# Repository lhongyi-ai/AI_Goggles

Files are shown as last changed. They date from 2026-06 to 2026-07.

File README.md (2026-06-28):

# AI_Goggles

V0 firmware for a Seeed Studio XIAO ESP32S3 Sense wearable camera validation prototype.

## KiCad Hardware Automation

This repository now includes a maintainable KiCad + Python + VS Code automation skeleton for the future AI sports glasses carrier board. The current hardware target is a minimal Radxa CM4 / RK3576 carrier exploration flow, but this code intentionally generates only a reviewable test PCB. It does not generate a complete Radxa CM4 carrier board, does not add unverified CM4 pin mappings, and does not autoroute high-speed signals.

### Quick Start

```bash
./scripts/setup_environment.sh
source .venv/bin/activate
python scripts/check_environment.py
python scripts/generate_test_board.py
python scripts/run_drc.py
```

On this machine, initial probing found Python 3.12.4 at `/opt/anaconda3/bin/python3`, but did not find `kicad-cli` in `PATH` or under `/Applications/KiCad`. The scripts keep working in fallback mode and will automatically use KiCad CLI if it is installed later.

### VS Code Usage

Select the workspace interpreter at:

```text
${workspaceFolder}/.venv/bin/python
```

The `.vscode/tasks.json` file provides these tasks:

- `Hardware: Check Environment`
- `Hardware: Test KiCad IPC`
- `Hardware: Generate Test Board`
- `Hardware: Run DRC`
- `Hardware: Export Gerbers`
- `Hardware: Run All Checks`

The debug launch configs cover:

- `scripts/check_ipc_connection.py`
- `scripts/generate_test_board.py`

Open the KiCad project from:

```text
hardware/ai_glasses_carrier.kicad_pro
```

The fallback generator writes:

```text
hardware/ai_glasses_carrier.kicad_pcb
```

### IPC API Usage

1. Start KiCad.
2. Open PCB Editor.
3. Open `hardware/ai_glasses_carrier.kicad_pcb`.
4. Enable KiCad's IPC/API server for your installed KiCad version.
5. Run:

```bash
python scripts/check_ipc_connection.py
```

This repository does not hard-code a KiCad IPC settings menu name because no KiCad installation was detectable when this environment was created. After KiCad is installed, run `python scripts/check_environment.py` to capture the version, then use the matching KiCad documentation or Preferences search for IPC/API server settings. The IPC checker refuses to report success unless it can use importable bindings and verify a live KiCad/PCB Editor session.

### Two Automation Routes

```text
Route A: IPC API
Use this for interacting with the PCB currently open in KiCad.

Route B: Standard KiCad file generation
Use this for batch generation, CI, Git review, and non-GUI environments.
```

Route B is the primary fallback today. `scripts/generate_test_board.py` creates a 50 mm x 20 mm two-layer board with Edge.Cuts, two mounting holes, one 1x4 test connector, and these test nets:

- `+5V`
- `GND`
- `I2C_SCL`
- `I2C_SDA`

### Configuration

Hardware settings live in:

- `config/board.yaml` — V1 carrier spec (6-layer, target outline, P0/P1 interfaces)
- `config/cm4_pins.yaml` — RK3576 signal catalog mapped to carrier nets
- `config/cm4_v1_pin_assignment.yaml` — **pin freeze gate** (requirements Section 3.3)
- `config/components_v1.yaml` — candidate parts for every P0/P1 block
- `config/design_rules.yaml` — 6-layer stack + impedance rules (MIPI 100Ω, USB 90Ω)

Pin/signal entries are marked `source_verified: false` until they are manually
checked against *Radxa CM4 Schematic V1.20*. AI-generated content is auxiliary only.

### V1 Carrier Board (Radxa CM4 / RK3576)

The V1 deliverable is defined by `AI_Sports_Glasses_PCB_Requirements_v1.1.pdf`.
Generate the 6-layer skeleton (outline + full net list + mounting holes):

```bash
.venv/bin/python scripts/generate_carrier_board.py
```

This produces a **pre-layout skeleton only** — no B2B/USB/camera footprints.
Per requirements **Section 3.3**, real layout may not begin until the pin
assignment is frozen. Check the gate:

```bash
.venv/bin/python scripts/check_pin_freeze.py
```

The gate stays **BLOCKED** until every P0 row in `cm4_v1_pin_assignment.yaml` has
a real pin number + verified source, all Section 8.3 TBD items are resolved, and
`status:` is set to `FROZEN`. Only then should real footprints be placed.

> Note: `generate_test_board.py` (legacy 2-layer toolchain check) writes to the
> same `hardware/ai_glasses_carrier.kicad_pcb` path. After running `pytest`,
> re-run `generate_carrier_board.py` to restore the carrier as the active board.

### Reports And Manufacturing Output

DRC output is written to:

```text
generated/reports/drc-report.txt
```

Manufacturing export output is written to:

```text
generated/gerbers/
```

Both scripts inspect `kicad-cli --help` before constructing version-sensitive commands.

## V0 Behavior

- Short press on D1: capture one JPEG photo.
- Long press on D1 for at least 1 second: start SD MJPEG recording. Press again or send `x` to stop.
- Red LED on D2 stays on while capturing.
- Files are saved to the Sense microSD card without overwriting old files.
- Wi-Fi live preview is available when `v0_camera_prototype/wifi_config.h` is configured.

## Wiring

- `D1 -> push button -> GND`
- `D2 -> 330 ohm resistor -> LED anode`
- `LED cathode -> GND`

The camera and microSD slot are on the Sense expansion board. Do not use D8, D9, or D10 for the button or LED because those pins are used by SD SPI.

## Board

Use:

```bash
esp32:esp32:XIAO_ESP32S3
```

Recommended options:

- USB CDC On Boot: Enabled
- PSRAM: OPI PSRAM
- Partition Scheme: Maximum APP
- Upload Speed: 921600, or lower if upload is unreliable

The equivalent compile FQBN is:

```bash
esp32:esp32:XIAO_ESP32S3:PSRAM=opi,PartitionScheme=max_app_8MB,CDCOnBoot=default
```

## Suggested Test Order

1. `tests/01_blink_led`
2. `tests/02_read_button`
3. `tests/03_button_controls_led`
4. `tests/04_sd_write_test`
5. `v0_camera_prototype`

Compile the main firmware:

```bash
arduino-cli compile \
  --fqbn esp32:esp32:XIAO_ESP32S3:PSRAM=opi,PartitionScheme=max_app_8MB,CDCOnBoot=default \
  v0_camera_prototype
```

List connected boards:

```bash
arduino-cli board list
```

Upload after replacing the port with your actual port:

```bash
arduino-cli upload \
  -p /dev/cu.usbmodemXXXX \
  --fqbn esp32:esp32:XIAO_ESP32S3:PSRAM=opi,PartitionScheme=max_app_8MB,CDCOnBoot=default \
  v0_camera_prototype
```

Serial Monitor:

```bash
arduino-cli monitor -p /dev/cu.usbmodemXXXX -c baudrate=115200
```

Serial commands in the main firmware:

- `p`: take one photo
- `r`: start SD MJPEG recording with Wi-Fi preview available
- `x`: stop current SD recording and write metadata
- `j`: start JPEG sequence debug recording
- `m`: start SD MJPEG recording
- `v`: enable or disable Wi-Fi preview server
- `w`: print Wi-Fi status, IP, and preview URLs
- `s`: print next file indexes
- `i`: print hardware, memory, SD, BLE, and active profile information
- `b`: run the video smoothness benchmark suite
- `h`: print help

## Wi-Fi Live Preview And Mac MP4

Copy and edit the Wi-Fi config:

```bash
cp v0_camera_prototype/wifi_config.example.h v0_camera_prototype/wifi_config.h
```

Then upload the firmware. In Serial Monitor, send:

```text
w
```

Open the printed preview page:

```text
http://XIAO_IP/
```

Record a live H.264 MP4 on the Mac:

```bash
./scripts/live_preview_record.sh XIAO_IP
```

Stop with Ctrl+C, or:

```bash
./scripts/stop_live_recording.sh
```

See [docs/live_preview_and_dual_recording.md](docs/live_preview_and_dual_recording.md) for the architecture, endpoints, and validation plan.

## BLE Phone Control

The firmware exposes a BLE control service so a phone can trigger the same commands as USB serial.

BLE identifiers:

```text
Device name: AI_Goggles
Service UUID: 7b8f0001-2f5d-4d5a-9e4f-7f6a8c8d0001
Control characteristic UUID: 7b8f0002-2f5d-4d5a-9e4f-7f6a8c8d0001
```

Phone test apps:

- iPhone: nRF Connect or LightBlue
- Android: nRF Connect

Phone steps:

1. Power the XIAO ESP32S3 Sense.
2. Open nRF Connect or LightBlue.
3. Scan for `AI_Goggles`.
4. Connect to the device.
5. Open the custom service UUID above.
6. Open the control characteristic UUID above.
7. Write one UTF-8/text command:
   - `p`: take one photo
   - `r`: start SD MJPEG recording
   - `x`: stop recording
   - `j`: start JPEG sequence debug recording
   - `m`: start SD MJPEG recording
   - `v`: toggle Wi-Fi preview server
   - `w`: print Wi-Fi status
   - `s`: update/read status
   - `i`: print hardware/profile info to Serial Monitor
   - `b`: run the benchmark suite
   - `h`: print help to Serial Monitor
8. Read the same characteristic to see a simple status string like `ready: recording done`.

Do not write a new `r` or `b` command while a recording is already running. The board is busy during capture.

## Output Files

Single photos:

```text
/photo_0001.jpg
/photo_0002.jpg
```

JPEG sequences:

```text
/clip_0001/frame_0001.jpg
/clip_0001/frame_0002.jpg
/clip_0001/clip_info.csv
/clip_0001/frame_timing.csv
```

Single-file MJPEG output:

```text
/clip_0005.mjpeg
/clip_0005_info.csv
/clip_0005_timing.csv
```

The XIAO ESP32S3 Sense does not have a hardware H.264 encoder, so it cannot directly create smooth MP4/MOV files on-device. Convert a clip folder to MP4 on your computer:

```bash
ffmpeg -framerate 10 -i frame_%04d.jpg -c:v libx264 -pix_fmt yuv420p clip_0001.mp4
```

This repo also includes a macOS LaunchAgent and shell script that can auto-convert SD card `clip_*` folders and `.mjpeg` files to `sd_clip_*.mp4` when the card is mounted. Live network recordings are saved separately as `recordings/live/live_*.mp4`.

## macOS SD Auto Convert

Install once:

```bash
chmod +x scripts/*.sh
./scripts/install_auto_convert_launch_agent.sh
```

Prepare each AI Goggles SD card once:

```bash
./scripts/prepare_ai_goggles_sd.sh "/Volumes/SD_CARD_NAME"
```

Normal use:

```text
1. Remove the SD card from the XIAO.
2. Insert it into the Mac.
3. Wait for background conversion.
4. Open ~/Movies/AI_Goggles/SD_Recordings/
```

Check status:

```bash
./scripts/check_auto_convert_status.sh
```

Logs:

```bash
tail -f ~/Library/Logs/AI_Goggles/auto_convert.log
```

Manual trigger for debugging:

```bash
launchctl kickstart -k gui/$(id -u)/com.stanley.ai-glasses.auto-convert
```

Uninstall:

```bash
./scripts/uninstall_auto_convert_launch_agent.sh
```

`StartOnMount` fires for many mounted volumes, but the script only processes volumes with `AI_GOGGLES.marker` or a strict legacy `clip_XXXX` recording layout. See [docs/macos_sd_auto_convert.md](docs/macos_sd_auto_convert.md).

## Video Smoothness Benchmark

The firmware records per-frame timing with `esp_timer_get_time()` and writes metrics after recording finishes. It does not print per-frame logs during capture.

Profile summary:

| Profile | Resolution | JPEG quality | Target FPS | SD SPI | Storage |
| --- | --- | ---: | ---: | ---: | --- |
| A | 320x240 | 15 | 10 | 10 MHz | Separate JPEG files |
| B | 320x240 | 15 | 15 | 20 MHz | Separate JPEG files |
| C | 320x240 | 20 | 20 | 20 MHz | Separate JPEG files |
| D | 640x480 | 15 | 10 | 20 MHz | Separate JPEG files |
| E | 320x240 | 15 | 10 | 20 MHz | Single-file MJPEG |

Analyze a clip:

```bash
python3 scripts/analyze_clip_metrics.py /Volumes/UNTITLED\ 2/clip_0001
python3 scripts/analyze_clip_metrics.py /Volumes/UNTITLED\ 2/clip_0005_info.csv
```

See [docs/video_smoothness_benchmark.md](docs/video_smoothness_benchmark.md) for the full benchmark workflow and CFR/VFR MP4 conversion notes.

## Bluetooth Audio Note

The XIAO ESP32S3 Sense cannot act like a normal phone Bluetooth speaker/headset because ESP32-S3 supports BLE but not Classic Bluetooth audio profiles such as A2DP or HFP. BLE is useful for low-bandwidth control commands, but not for ordinary phone audio streaming in this Arduino setup.

For phone audio, use a separate Bluetooth audio receiver module or a chip/board with Classic Bluetooth audio support, then connect its audio output to a speaker/amp path. For phone camera control, a BLE control service can be added separately.

## V0 Pass Criteria

- Camera initializes reliably.
- Button triggers once per press.
- LED is visible while capturing and off afterward.
- Single photos open on a computer.
- A 10-second recording saves at least 30 valid JPEG frames.
- Restarting the board does not overwrite old captures.

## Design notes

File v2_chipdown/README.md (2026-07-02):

# AI Glasses V2 — RK3576 Chip-Down (event-driven, always-on + compute-island)

This folder holds the **V2 design**, a clean break from the V1 CM4-carrier board.

## The one-sentence definition

> V2 is **not** "glasses that run RK3576 all day."
> V2 is **glasses whose low-power always-on (AON) system stays awake all day for sensing + connectivity, and wakes RK3576 for short bursts** when vision / AI / encode / high-rate transmit is actually needed.

This inverts the V1 order. V1 built the RK3576/CM4 host first and treated power as an afterthought (`1S → 5V boost → everything`). V2 **freezes the battery volume and the power state machine first, then draws the RK3576 chip-down** as a demand-started compute accelerator.

## Why the change (energy accounting)

V1 measured/estimated draw: idle **651 mW**, mixed **~3031 mW**, AI+record peak **~4.8 W**. At those numbers a temple-sized battery cannot deliver all-day standby *and* multi-hour mixed use. V2 targets:

| State | V1 now | V2 target |
|---|--:|--:|
| Standby | 651 mW | **20–50 mW** |
| Mixed use | 3031 mW | **300–500 mW** |
| Continuous 1080p record | ~3 W | **1.0–1.5 W** |
| AI + record peak | 4.8 W | **1.5–2.5 W** |

## Folder map

```
v2_chipdown/
├── README.md                     ← you are here (positioning + map)
├── docs/
│   ├── 01_architecture.md        AON island + RK3576 compute island, 4-board split
│   ├── 02_power_states.md        the 5+1 state machine (Deep Off … AI Burst)
│   ├── 03_workflow_phases.md     Phase 0–6 + Gate 0/1/2 + Power/Mechanical gates
│   ├── 04_power_tree.md          new Buck + Load-Switch tree (not "boost everything")
│   ├── 05_hardware_partition.md  front sensor board / L temple / R temple / rears
│   ├── 06_battery_strategy.md    1S2P distribution + LP451165×2 recommendation
│   ├── 07_schematic_design.md    pre-layout schematic design record
│   ├── 08_signal_dictionary.md   generated NET_META signal dictionary
│   ├── 09_power_domain_isolation_matrix.md generated reverse-feed matrix
│   ├── 10_bom_status.md          generated BOM/HOLD/DNP/TBD status
│   ├── 11_footprint_register.md  generated package/footprint readiness register
│   ├── 12_layout_entry_gate_status.md generated PCB go/no-go + HOLD closure
│   └── 13_mechanical_electrical_floorplan.md Phase 1.5 no-route floorplan template
├── config/
│   ├── power_budget_v2.yaml      subsystem × power-state model (editable, source)
│   └── battery_options.yaml      candidate cells/packs incl. LP451165
├── scripts/
│   ├── chipdown_bom.py           V2 schematic/BOM/net/signal source of truth
│   ├── generate_chipdown_sch.py  emits generated KiCad schematic + symbol lib
│   ├── generate_gate_docs.py     emits docs 08/09/11/12
│   ├── generate_bom_status.py    emits doc 10
│   ├── generate_mechanical_floorplan.py emits Phase 1.5 report + multi-view render
│   └── power_budget_v2.py        computes per-state runtime, required mAh, day-mix
├── hardware/                     generated pre-layout system schematic, no PCB yet
└── reports/
    ├── POWER_BUDGET_V2.md        generated by the power model
    ├── AI_Glasses_V2_Phase1_5_Floorplan.md generated fit/placement report
    ├── AI_Glasses_V2_Phase1_5_Floorplan_ZH.md Chinese CAD/structure handoff
    ├── ai_glasses_v2.net         KiCad netlist export
    ├── ai_glasses_v2_bom.csv     KiCad BOM export
    └── output/                   schematic PDF/SVG + power-budget PDF + Phase 1.5 render
```

## Status / what's frozen vs open

- **Frozen intent:** event-driven architecture, AON-controls-SoC-power, distributed 4-board split, per-island current sense, hardware default-OFF enables.
- **Now present:** generated pre-layout KiCad system schematic: **96 components**, **127 declared nets**, ERC clean. It is a functional-block review artifact, not a PCB layout release.
- **Open / HOLD:** NDP120 full datasheet + kit + power, FCU760K Hardware Design + BSP, LP451165 + 1S2P validation, custom IMX415 module rail/FPC data, real battery-bay fit.
- **Gate order:** Phase 0 (freeze battery + state machine) → Phase 1 (AON board) → Phase 1.5 (mechanical/electrical floorplan) → Phase 2 (RK3576 min core). PCB layout is still blocked by [docs/12_layout_entry_gate_status.md](docs/12_layout_entry_gate_status.md) and [docs/13_mechanical_electrical_floorplan.md](docs/13_mechanical_electrical_floorplan.md).

## How to regenerate the V2 schematic/docs

```bash
cd "AI Glasses"
.venv/bin/python v2_chipdown/scripts/chipdown_bom.py
.venv/bin/python v2_chipdown/scripts/generate_chipdown_sch.py
.venv/bin/python v2_chipdown/scripts/generate_gate_docs.py
.venv/bin/python v2_chipdown/scripts/generate_bom_status.py

KCLI=/Applications/KiCad/KiCad.app/Contents/MacOS/kicad-cli
"$KCLI" sch erc --severity-all --format report \
  -o v2_chipdown/reports/erc.report.txt \
  v2_chipdown/hardware/ai_glasses_v2_chipdown.kicad_sch
"$KCLI" sch export netlist --output v2_chipdown/reports/ai_glasses_v2.net \
  v2_chipdown/hardware/ai_glasses_v2_chipdown.kicad_sch
"$KCLI" sch export bom --output v2_chipdown/reports/ai_glasses_v2_bom.csv \
  --fields Reference,Value,BOM_ID,Board,Assembly,Priority,Package,Gate \
  v2_chipdown/hardware/ai_glasses_v2_chipdown.kicad_sch
"$KCLI" sch export pdf --output v2_chipdown/reports/output/ai_glasses_v2_chipdown_schematic.pdf \
  v2_chipdown/hardware/ai_glasses_v2_chipdown.kicad_sch
"$KCLI" sch export svg --output v2_chipdown/reports/output \
  v2_chipdown/hardware/ai_glasses_v2_chipdown.kicad_sch
```

## How to run the power model

```bash
cd "AI Glasses"
.venv/bin/python v2_chipdown/scripts/power_budget_v2.py
# then render the markdown to PDF (same kidoc flow as V1):
python3 ~/.claude/skills/kidoc/scripts/kidoc_generate.py \
  --project-dir "$(pwd)" \
  --doc "$(pwd)/v2_chipdown/reports/POWER_BUDGET_V2.md" --format pdf
```

## Relationship to V1

V1 (`hardware/ai_glasses_carrier.*`, `scripts/carrier_bom.py`, `config/*.yaml`) stays as the **bench/EVT development vehicle** — it is still the fastest way to bring up RK3576 Linux and get *real* per-rail current numbers. Those measured numbers feed back into `config/power_budget_v2.yaml` and re-size the battery. V2 does **not** delete V1; it supersedes it as the product architecture.

> All numbers in `config/*.yaml` are **engineering estimates** from datasheet typicals until Phase 2 bench EVT replaces them with per-island shunt measurements.

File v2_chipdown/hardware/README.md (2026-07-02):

# V2 chip-down hardware

## Now present: the pre-layout system schematic (no PCB yet)

`ai_glasses_v2_chipdown.kicad_sch` is a **pre-PCB-layout, functional-block system
schematic** for the whole V2 design. It is generated from the master in
[../scripts/chipdown_bom.py](../scripts/chipdown_bom.py) and captures what is
knowable before layout: the power tree, the AON control plane, interface buses,
default-OFF enable pulls, current-sense points, and hidden `NET_META` signal
attributes on global labels. See [../docs/07_schematic_design.md](../docs/07_schematic_design.md).

| File | What |
|---|---|
| `ai_glasses_v2_chipdown.kicad_sch` | one system sheet, 96 blocks, 127 declared nets, **ERC clean** |
| `AI_Glasses_V2.kicad_sym` | generated box symbols |
| `ai_glasses_v2_chipdown.kicad_pro`, `sym-lib-table`, `fp-lib-table` | project + lib tables |

Regenerate from the repo root:

```bash
.venv/bin/python v2_chipdown/scripts/chipdown_bom.py
.venv/bin/python v2_chipdown/scripts/generate_chipdown_sch.py
.venv/bin/python v2_chipdown/scripts/generate_gate_docs.py
.venv/bin/python v2_chipdown/scripts/generate_bom_status.py
```

Then run ERC and exports per [../docs/07_schematic_design.md](../docs/07_schematic_design.md).
Review outputs (netlist / BOM / PDF / SVG / ERC) are in [../reports/](../reports/).
Generated gate docs are [08](../docs/08_signal_dictionary.md),
[09](../docs/09_power_domain_isolation_matrix.md),
[10](../docs/10_bom_status.md), [11](../docs/11_footprint_register.md) and
[12](../docs/12_layout_entry_gate_status.md).

## Still NOT here: PCB layout (by design)

No `.kicad_pcb`, no assigned footprints, no placement/copper. **PCB layout stays
gated behind Gate 0, the Phase 1.5 floorplan, and the HOLD closure matrix** —
batteries proven to fit L/R temples with swell/foam/FPC room, not stacked over
RK3576/PMIC, antenna keep-out respected, and NDP120/Wi-Fi/battery/camera/FPC
data closed (see [../docs/12_layout_entry_gate_status.md](../docs/12_layout_entry_gate_status.md)
and [../docs/13_mechanical_electrical_floorplan.md](../docs/13_mechanical_electrical_floorplan.md)).
The Footprint field is intentionally empty; intended packages live in the
`Package` field only and are tracked in [../docs/11_footprint_register.md](../docs/11_footprint_register.md).

The next KiCad mechanical deliverable is a **no-route floorplan**: board frames,
RK3576/LPDDR/RK806/eMMC/Wi-Fi/boost-inductor/FPC placement envelopes, battery
3D/envelope blocks, speaker and antenna keep-outs. It proves fit before routing;
it is not a formal routed PCB.

## Intended board split at layout (Phase 4)

One system schematic now; four physical boards at layout time (each component
already tagged with its `Board`):

```
front_sensor/   custom 1080p camera + PDM mic array + camera rails + ESD
rk3576_core/    RK3576 + LPDDR4X + eMMC + RK806S + 5V boost + Wi-Fi   (delta off Radxa ref)
aon_power/      nRF54L15 + nPM1300 + NDP120 + BMI270 + charge/gauge/protection   (BUILD FIRST)
power_tree/     Buck + load-switch islands + per-island current sense
```

Build order remains AON board first, then the RK3576 core — never the SoC first.

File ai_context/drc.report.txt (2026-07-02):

** Drc report for ai_glasses_carrier.kicad_pcb **
** Created on 2026-06-30T03:11:09 **
** Report includes: Errors, Warnings, Exclusions **

** Found 0 DRC violations **

** Found 0 unconnected pads **

** Found 0 Footprint errors **

** Ignored checks **
    - Footprint has no courtyard defined
    - Track endpoint not centered on via
    - Tuning profile track geometries
    - Footprint doesn't match symbol's footprint filters
    - Footprint component type doesn't match footprint pads

** End of Report **

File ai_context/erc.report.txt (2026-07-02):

ERC report (2026-06-30T03:11:02, Encoding UTF8)
Report includes: Errors, Warnings, Exclusions

***** Sheet /

 ** ERC messages: 0  Errors 0  Warnings 0

 ** Ignored checks:
    - Global label only appears once in the schematic
    - Four connection points are joined together
    - SPICE model issue
    - Assigned footprint doesn't match footprint filters

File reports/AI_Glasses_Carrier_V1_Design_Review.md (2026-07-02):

# AI Glasses Carrier V1 - PCB Design Review

- **Board:** ai_glasses_carrier_v1  |  **CM4 SKU:** RM126-D4E32J0R35W28 (RK3576, 4GB LPDDR4X, 32GB eMMC, Wi-Fi6+BT5.x)
- **Pin-assignment status:** `REVIEW` (verified vs official pinout; not yet FROZEN)
- **Generated:** 2026-06-30  (from working sources; see footer)
- **Components:** 102 (81 P0)  |  **Passive families:** 22 (LOCKED 11 / VERIFY 6 / TUNE 5)
- **ERC:** 0  |  **DRC:** 0 violations  |  **Footprints:** 101/102 real (1 VERIFY), 0 placed  |  **MPN set:** 27/102

> [!] **Stage:** schematic / pin-freeze. The PCB is intentionally an empty skeleton (outline + 6-layer stack + mounting holes + nets, **no footprints placed**). Per repo rule 7 this report makes **no** claim about layout/copper/clearance correctness - that is confirmed only in KiCad/3D after placement. Part values & specs are EVT candidates pending human review.

---
## 1. Project status

| Item | State |
|---|---|
| Pin assignment | [OK] 56 rows, all verified vs `radxa_cm4_pinout_v1.20.xlsx` |
| Freeze gate | [BLOCKED] `REVIEW` - blocked by 3 procurement/mechanical TBDs (not pins) |
| Schematic | [OK] element-level draft, net-connectivity verified |
| PCB layout | [ ] not started (skeleton only) |
| ERC / DRC | 0 / 0 violations (see §2/§3) |

## 2. Schematic status (ERC)

Schematic is generated from the BOM master (`scripts/carrier_bom.py`) as box symbols with global net labels; every net was checked with `kicad-cli sch export netlist`. The CM4 module is drawn as its three B2B connectors (J31=J3A, J32=J3B, J1) carrying the real CM4 pins.

**ERC: 0 errors, 0 warnings - clean** (`ai_context/erc.report.txt`: "ERC messages: 0  Errors 0  Warnings 0"). Confirms 102 symbols + 321 net labels with no unconnected-critical-pin, duplicate-net, or power-driver violations.

## 3. PCB status (DRC)

PCB = pre-layout skeleton: 70×55 mm outline (placeholder - carrier outline still a TBD), 6-layer stack (F.Cu / In1.GND / In2.PWR / In3.sig / In4.GND / B.Cu), 4× M2 mounting holes, declared nets, **no component footprints**. `Update PCB from Schematic` will populate it once footprints are assigned and the gate is FROZEN.

**DRC: 0 errors, 0 warnings** on the skeleton (`ai_context/drc.report.txt`). Meaningful DRC (clearances, diff-pair, copper) only applies after footprints are placed.

## 4. Footprint status

"Footprint" means three different things at three stages - they are NOT the same, and conflating them is what makes the status look contradictory:

| Layer | Meaning | Status |
|---|---|---|
| (1) Footprint field (pointer) | Each symbol names *which* footprint to use | **102/102** assigned |
| (2) Real footprint exists/usable | That name maps to a real KiCad library footprint | **101/102** real, **1** still `VERIFY` placeholder |
| (3) Placed on the PCB | Physical footprint dropped into `.kicad_pcb` | **0** (pre-layout skeleton) |

So: every symbol has a footprint *pointer* (needed for `Update PCB from Schematic`), **101** of those now point at real, datasheet-checked footprints from the installed KiCad 10 libraries (all passives + most connectors/ICs/test points), **1** are still placeholders, and **nothing is placed on the board yet**.

### 4.1 The 1 remaining placeholders - proposed real footprints

Each was researched against the installed KiCad libraries / the part datasheet. `custom` = must be drawn in `AI_Glasses.pretty` (no stock footprint); `confirm` = std-lib family identified, verify exact pads/EP vs the ordered part.

| Ref | Part / package | Proposed footprint | Action |
|---|---|---|---|
| L1 | Boost inductor 4.7uH, >=10A sat | `Inductor_SMD: 4x4mm class per chosen part` | confirm |

> All parts now use **authoritative KiCad-library footprints**, including the TI-official land patterns for the small packages: B2B = `Connector_Hirose_DF40:Hirose_DF40C-100DS-0.4V_2x50_P0.4mm`, GNSS = `RF_GPS:ublox_MAX`, IMU = `Package_LGA:LGA-14_3x2.5mm`, TPD4E05U06 = `Package_SON:USON-10_2.5x1.0mm_P0.5mm`, TPS61022 = `Package_DFN_QFN:Texas_RWU0007A_VQFN-7_2x2mm`. A 1:1 print-and-verify fixture for the two small packages is in `hardware/confirm_fp_1to1_check.kicad_pcb` (PDF: `reports/output/Confirm_FP_1to1_Check.pdf`). The only remaining placeholder is **L1** (boost inductor) - its footprint is selected once the boost peak current sets the inductor part. The B2B footprint geometry is authoritative, but the locked 3-connector PLACEMENT still needs the mechanical fit-check (official CM4 STEP + 2-layer coupon, see §8).

## 5. Component list (by function)

### CM4 Module / B2B Connectors (3)

| Ref | Value | MPN | LCSC | Footprint | Function |
|---|---|---|---|---|---|
| J1 | DF40C-100DS-0.4V(51) | DF40C-100DS-0.4V(51) | - | `Connector_Hirose_DF40:Hirose_DF40C-100DS-0.4V_2x50_P0.4mm` | CM4 J1 (I/O): SAI1 audio, CSI3 camera MCLK, speaker enable |
| J31 | DF40C-100DS-0.4V(51) | DF40C-100DS-0.4V(51) | - | `Connector_Hirose_DF40:Hirose_DF40C-100DS-0.4V_2x50_P0.4mm` | CM4 J3A (low-speed): power, debug/GNSS UART, I2C, control GPIO |
| J32 | DF40C-100DS-0.4V(51) | DF40C-100DS-0.4V(51) | - | `Connector_Hirose_DF40:Hirose_DF40C-100DS-0.4V_2x50_P0.4mm` | CM4 J3B (high-speed): MIPI-CSI3 4-lane camera, USB2-OTG0, PDM1 mics |

### Camera (P0) (11)

| Ref | Value | MPN | LCSC | Footprint | Function |
|---|---|---|---|---|---|
| C8 | 10µF | - | - | `Capacitor_SMD:C_0805_2012Metric` | Camera +3V3 bulk decoupling |
| C9 | 1µF | - | - | `Capacitor_SMD:C_0603_1608Metric` | Camera +3V3 decoupling |
| C10 | 100nF | - | - | `Capacitor_SMD:C_0603_1608Metric` | Camera +3V3 HF decoupling |
| C29 | 10µF | - | - | `Capacitor_SMD:C_0805_2012Metric` | Camera +5V bulk decoupling for Radxa Camera 4K |
| C30 | 100nF | - | - | `Capacitor_SMD:C_0603_1608Metric` | Camera +5V HF decoupling for Radxa Camera 4K |
| J2 | FH35C-31S-0.3SHW(50) | FH35C-31S-0.3SHW(50) | C424662 | `AI_Glasses:FH35C-31S-0.3SHW_50` | Camera FPC - Radxa Camera 4K / Sony IMX415-AAQR-C, 31-pin 0.3mm, 4-lane MIPI |
| R7 | 2.2k | - | - | `Resistor_SMD:R_0603_1608Metric` | Camera I2C SCL pull-up to +1V8 (cam OVDD=1.8V confirmed) |
| R8 | 2.2k | - | - | `Resistor_SMD:R_0603_1608Metric` | Camera I2C SDA pull-up to +1V8 (cam OVDD=1.8V confirmed) |
| U2 | TPD4E05U06 | TPD4E05U06 | - | `Package_SON:USON-10_2.5x1.0mm_P0.5mm` | MIPI-CSI low-capacitance ESD array for CSI3 clock + data lanes 0/1 (<0.4pF/line) |
| U3 | LP5907-3.3 (low-noise LDO) | LP5907MFX-3.3 | - | `Package_TO_SOT_SMD:SOT-23-5` | Camera 3.3V low-noise supply for Radxa Camera 4K, EN-gated |
| U16 | TPD4E05U06 | TPD4E05U06 | - | `Package_SON:USON-10_2.5x1.0mm_P0.5mm` | MIPI-CSI low-capacitance ESD array for CSI3 data lanes 2/3 (<0.4pF/line) |

### Audio (P0) (9)

| Ref | Value | MPN | LCSC | Footprint | Function |
|---|---|---|---|---|---|
| C13 | 100nF | - | - | `Capacitor_SMD:C_0603_1608Metric` | Amp VDD decoupling |
| C23 | 1nF | - | - | `Capacitor_SMD:C_0603_1608Metric` | Class-D EMI cap (OUT+ to GND) |
| C24 | 1nF | - | - | `Capacitor_SMD:C_0603_1608Metric` | Class-D EMI cap (OUT- to GND) |
| FB1 | Ferrite 600ohm@100MHz | - | - | `Inductor_SMD:L_0603_1608Metric` | Class-D speaker EMI bead (OUT+) |
| FB2 | Ferrite 600ohm@100MHz | - | - | `Inductor_SMD:L_0603_1608Metric` | Class-D speaker EMI bead (OUT-) |
| J3 | JST-SH 2p (spkr) | SM02B-SRSS-TB | - | `Connector_JST:JST_SH_BM02B-SRSS-TB_1x02-1MP_P1.00mm_Vertical` | Speaker connector (post-EMI); 2 wire-leads |
| MK1 | SPH0641LU4H-1 | SPH0641LU4H-1 | - | `Sensor_Audio:Knowles_LGA-5_3.5x2.65mm` | PDM MEMS mic (L, SEL=GND) |
| MK2 | SPH0641LU4H-1 | SPH0641LU4H-1 | - | `Sensor_Audio:Knowles_LGA-5_3.5x2.65mm` | PDM MEMS mic (R, SEL=VDD) |
| U4 | MAX98357AETE+T | MAX98357AETE+T | C910544 | `Package_DFN_QFN:QFN-16-1EP_3x3mm_P0.5mm_EP1.45x1.45mm` | Class-D I2S/SAI mono amp (TQFN-16, no MCLK) |

### USB-C (P0) (8)

| Ref | Value | MPN | LCSC | Footprint | Function |
|---|---|---|---|---|---|
| C11 | 1µF | - | - | `Capacitor_SMD:C_0603_1608Metric` | VBUS input cap |
| D3 | SMAJ5.0A (TVS) | SMAJ5.0A | - | `Diode_SMD:D_SMA` | USB VBUS ESD/TVS clamp (5V standoff) |
| J4 | GCT USB4085 (USB2) | USB4085-GF-A | - | `Connector_USB:USB_C_Receptacle_GCT_USB4085` | USB-C receptacle (USB2 + 5V sink) |
| R1 | 5.1k | - | - | `Resistor_SMD:R_0603_1608Metric` | USB-C CC1 pull-down (Sink role) |
| R2 | 5.1k | - | - | `Resistor_SMD:R_0603_1608Metric` | USB-C CC2 pull-down (Sink role) |
| R3 | 0R / shunt | - | - | `Resistor_SMD:R_2512_6332Metric` | VBUS_PROT->5V series 0R/shunt (current log) |
| U5 | TPD2E009 | TPD2E009 | - | `Package_TO_SOT_SMD:SOT-553` | USB2 D+/D- ESD clamp |
| U15 | TPS25940 (e-fuse, opt) | TPS25940 | - | `Package_DFN_QFN:Texas_RGP0020H_VQFN-20-1EP_4x4mm_P0.5mm_EP2.4x2.4mm` | VBUS e-fuse: OVP/OCP/reverse-block (DNP-able; bypass via R3 if unused) |

### Power (P0) (10)

| Ref | Value | MPN | LCSC | Footprint | Function |
|---|---|---|---|---|---|
| C1 | 10µF | - | - | `Capacitor_SMD:C_0805_2012Metric` | +5V bulk decoupling |
| C2 | 100nF | - | - | `Capacitor_SMD:C_0603_1608Metric` | +5V HF decoupling |
| C3 | 10µF | - | - | `Capacitor_SMD:C_0805_2012Metric` | +3V3 bulk decoupling |
| C4 | 100nF | - | - | `Capacitor_SMD:C_0603_1608Metric` | +3V3 HF decoupling |
| C5 | 10µF | - | - | `Capacitor_SMD:C_0805_2012Metric` | +1V8 bulk decoupling |
| C6 | 100nF | - | - | `Capacitor_SMD:C_0603_1608Metric` | +1V8 HF decoupling |
| C21 | 100nF | - | - | `Capacitor_SMD:C_0603_1608Metric` | LDO U12 +3V3 output decoupling |
| C22 | 100nF | - | - | `Capacitor_SMD:C_0603_1608Metric` | LDO U13 +1V8 output decoupling |
| U12 | TLV75733 (LDO) | TLV75733 | - | `Package_TO_SOT_SMD:SOT-23-5` | 3.3V rail regulator |
| U13 | TLV75718 (LDO) | TLV75718 | - | `Package_TO_SOT_SMD:SOT-23-5` | 1.8V VCCIO rail regulator |

### Battery (P1) (14)

| Ref | Value | MPN | LCSC | Footprint | Function |
|---|---|---|---|---|---|
| C7 | 22µF | - | - | `Capacitor_SMD:C_0805_2012Metric` | +VBAT bulk decoupling |
| C17 | 100nF | - | - | `Capacitor_SMD:C_0603_1608Metric` | Charger U7 VBUS decoupling |
| C18 | 100nF | - | - | `Capacitor_SMD:C_0603_1608Metric` | Fuel gauge U9 VDD decoupling |
| C19 | 100nF | - | - | `Capacitor_SMD:C_0603_1608Metric` | Boost U6 VIN decoupling |
| J5 | JST-PH 3p | S3B-PH-SM4-TB | - | `Connector_JST:JST_PH_S3B-PH-SM4-TB_1x03-1MP_P2.00mm_Horizontal` | Battery connector (BAT+/BAT-/NTC) |
| L1 | 4.7µH | - | - | `AI_Glasses:POWER_INDUCTOR_7X7_VERIFY` | Boost inductor |
| R11 | 10k | - | - | `Resistor_SMD:R_0603_1608Metric` | Battery NTC bias (placeholder) |
| R12 | 2.2k | - | - | `Resistor_SMD:R_0603_1608Metric` | Charger/Fuel I2C6 SCL pull-up to +1V8 |
| R13 | 2.2k | - | - | `Resistor_SMD:R_0603_1608Metric` | Charger/Fuel I2C6 SDA pull-up to +1V8 |
| R20 | 100k | - | - | `Resistor_SMD:R_0603_1608Metric` | Boost EN pull-up to +VBAT; default boost enabled for bench bring-up |
| U6 | TPS61022 (Boost) | TPS61022 | - | `Package_DFN_QFN:Texas_RWU0007A_VQFN-7_2x2mm_P0.5mm` | 1S Li-Po -> 5V boost converter |
| U7 | BQ25180 | BQ25180 | - | `Package_BGA:Texas_DSBGA-12_1.36x1.86mm_Layout3x4_P0.5mm` | 1S Li-Po charger w/ power-path (I2C) |
| U8 | BQ29700 | BQ29700 | - | `Package_TO_SOT_SMD:SOT-23-5` | Single-cell battery protection (OVP/UVP/OCP) |
| U9 | MAX17048 | MAX17048 | - | `Package_DFN_QFN:DFN-8-1EP_2x3mm_P0.5mm_EP0.61x2.2mm` | I2C fuel gauge (SOC, low-batt IRQ) |

### IMU / Haptic (P1) (7)

| Ref | Value | MPN | LCSC | Footprint | Function |
|---|---|---|---|---|---|
| C16 | 100nF | - | - | `Capacitor_SMD:C_0603_1608Metric` | IMU U10 VDD decoupling |
| C20 | 100nF | - | - | `Capacitor_SMD:C_0603_1608Metric` | Haptic U11 VDD decoupling |
| J6 | JST-SH 2p | SM02B-SRSS-TB | - | `Connector_JST:JST_SH_BM02B-SRSS-TB_1x02-1MP_P1.00mm_Vertical` | Vibration motor connector |
| R9 | 2.2k | - | - | `Resistor_SMD:R_0603_1608Metric` | IMU I2C SCL pull-up to +1V8 |
| R10 | 2.2k | - | - | `Resistor_SMD:R_0603_1608Metric` | IMU I2C SDA pull-up to +1V8 |
| U10 | ICM-42688-P | ICM-42688-P | - | `Package_LGA:LGA-14_3x2.5mm_P0.5mm_LayoutBorder3x4y` | 6-axis IMU (accel+gyro, I2C) |
| U11 | DRV2605L | DRV2605L | - | `Package_SO:MSOP-10_3x3mm_P0.5mm` | LRA/ERM haptic driver |

### GNSS / Positioning (P0) (11)

| Ref | Value | MPN | LCSC | Footprint | Function |
|---|---|---|---|---|---|
| C14 | 100nF | - | - | `Capacitor_SMD:C_0603_1608Metric` | GNSS VCC decoupling |
| C15 | 10µF | - | - | `Capacitor_SMD:C_0805_2012Metric` | GNSS VCC bulk decoupling |
| C25 |  shunt (DNP,tune) | - | - | `Capacitor_SMD:C_0402_1005Metric` | GNSS -match shunt, module side (DNP) |
| C26 |  shunt (DNP,tune) | - | - | `Capacitor_SMD:C_0402_1005Metric` | GNSS -match shunt, antenna side (DNP) |
| C27 | DC-block (series,tune) | - | - | `Capacitor_SMD:C_0402_1005Metric` | GNSS RF series match / DC block |
| C28 | 100nF (active-ant) | - | - | `Capacitor_SMD:C_0603_1608Metric` | Antenna bias decoupling (DNP if passive) |
| D4 | ESD low-cap RF 0.3pF | - | - | `Diode_SMD:D_SOD-882` | GNSS antenna ESD clamp |
| J8 | U.FL / IPEX | U.FL-R-SMT-1 | - | `Connector_Coaxial:U.FL_Hirose_U.FL-R-SMT-1_Vertical` | GNSS antenna connector (50ohm; external active/passive) |
| L2 | RF choke (active-ant) | - | - | `Inductor_SMD:L_0402_1005Metric` | Bias-tee choke (DNP if passive antenna) |
| R17 | 10ohm (active-ant) | - | - | `Resistor_SMD:R_0603_1608Metric` | Active-antenna bias feed from +3V3 (DNP if passive) |
| U14 | MAX-M10S-00B-01 | MAX-M10S-00B-01 | - | `RF_GPS:ublox_MAX` | u-blox GNSS (GPS/GLO/GAL/BDS), UART, VIO=1.8V |

### Indicators / Debug (5)

| Ref | Value | MPN | LCSC | Footprint | Function |
|---|---|---|---|---|---|
| D1 | LED Green | - | - | `LED_SMD:LED_0603_1608Metric` | Power LED (active-low GPIO sink) |
| D2 | LED Blue | - | - | `LED_SMD:LED_0603_1608Metric` | Status LED (active-low GPIO sink) |
| J7 | Header 1x4 2.54mm | - | - | `Connector_PinHeader_2.54mm:PinHeader_1x04_P2.54mm_Vertical` | UART debug header (TX/RX/GND/VREF) |
| R4 | 1k | - | - | `Resistor_SMD:R_0603_1608Metric` | Power LED current limit |
| R5 | 1k | - | - | `Resistor_SMD:R_0603_1608Metric` | Status LED current limit |

### Test Points (16)

| Ref | Value | MPN | LCSC | Footprint | Function |
|---|---|---|---|---|---|
| TP1 | TestPoint 1.0mm | - | - | `TestPoint:TestPoint_Pad_D1.5mm` | Test point: VBAT |
| TP2 | TestPoint 1.0mm | - | - | `TestPoint:TestPoint_Pad_D1.5mm` | Test point: 5V |
| TP3 | TestPoint 1.0mm | - | - | `TestPoint:TestPoint_Pad_D1.5mm` | Test point: 3V3 |
| TP4 | TestPoint 1.0mm | - | - | `TestPoint:TestPoint_Pad_D1.5mm` | Test point: 1V8 |
| TP5 | TestPoint 1.0mm | - | - | `TestPoint:TestPoint_Pad_D1.5mm` | Test point: GND |
| TP6 | TestPoint 1.0mm | - | - | `TestPoint:TestPoint_Pad_D1.5mm` | Test point: UART_TX |
| TP7 | TestPoint 1.0mm | - | - | `TestPoint:TestPoint_Pad_D1.5mm` | Test point: UART_RX |
| TP8 | TestPoint 1.0mm | - | - | `TestPoint:TestPoint_Pad_D1.5mm` | Test point: CAM_SCL |
| TP9 | TestPoint 1.0mm | - | - | `TestPoint:TestPoint_Pad_D1.5mm` | Test point: CAM_SDA |
| TP10 | TestPoint 1.0mm | - | - | `TestPoint:TestPoint_Pad_D1.5mm` | Test point: IMU_SCL |
| TP11 | TestPoint 1.0mm | - | - | `TestPoint:TestPoint_Pad_D1.5mm` | Test point: IMU_SDA |
| TP12 | TestPoint 1.0mm | - | - | `TestPoint:TestPoint_Pad_D1.5mm` | Test point: FUEL_SCL |
| TP13 | TestPoint 1.0mm | - | - | `TestPoint:TestPoint_Pad_D1.5mm` | Test point: FUEL_SDA |
| TP14 | TestPoint 1.0mm | - | - | `TestPoint:TestPoint_Pad_D1.5mm` | Test point: RESET |
| TP15 | TestPoint 1.0mm | - | - | `TestPoint:TestPoint_Pad_D1.5mm` | Test point: RECOVERY |
| TP16 | TestPoint 1.0mm | - | - | `TestPoint:TestPoint_Pad_D1.5mm` | Test point: CAM_EN |

### Buttons (8)

| Ref | Value | MPN | LCSC | Footprint | Function |
|---|---|---|---|---|---|
| R14 | 10k | - | - | `Resistor_SMD:R_0603_1608Metric` | RECOVERY pull-up to +1V8 |
| R15 | 10k | - | - | `Resistor_SMD:R_0603_1608Metric` | RESET pull-up to +1V8 |
| R16 | 10k | - | - | `Resistor_SMD:R_0603_1608Metric` | POWER_KEY pull-up to +1V8 |
| R18 | 100k | - | - | `Resistor_SMD:R_0603_1608Metric` | WL_nDIS pull-up to +1V8; default Wi-Fi enabled |
| R19 | 100k | - | - | `Resistor_SMD:R_0603_1608Metric` | BT_nDIS pull-up to +1V8; default Bluetooth enabled |
| SW1 | Tact SW SMD | - | - | `Button_Switch_SMD:SW_Push_1P1T_NO_CK_KMR2` | RECOVERY / maskrom button (to GND) |
| SW2 | Tact SW SMD | - | - | `Button_Switch_SMD:SW_Push_1P1T_NO_CK_KMR2` | RESET button (to GND) |
| SW3 | Tact SW SMD | - | - | `Button_Switch_SMD:SW_Push_1P1T_NO_CK_KMR2` | POWER button (to GND) |

## 6. CM4 pin assignment (verified vs official pinout)

| Function | Signal | Conn | Pin | CM4 net | Voltage |
|---|---|---|---|---|---|
| Power | +5V_IN | J3A | 77 | 5V_DCIN | 5V |
| Power | +5V_IN | J3A | 79 | 5V_DCIN | 5V |
| Power | +5V_IN | J3A | 81 | 5V_DCIN | 5V |
| Power | +5V_IN | J3A | 83 | 5V_DCIN | 5V |
| Power | +5V_IN | J3A | 85 | 5V_DCIN | 5V |
| Power | +5V_IN | J3A | 87 | 5V_DCIN | 5V |
| Power | GND | J3A/J3B/J1 | ALL_GND | GND | GND |
| Power | +3V3_OUT(CM4) | J3A | 84,86 | VCCIO6 | 3.3V |
| Power | +1V8_OUT(CM4) | J3A | 88,90 | VCC_1V8_S0 | 1.8V |
| Power | GPIO_VREF | J3A | 78 | GPIO_VREF | set=1.8V |
| Camera | MIPI_DPHY_CSI3_RX_CLKP | J3B | 129 | MIPI_DPHY_CSI3_RX_CLKP | diff_1V8 (100ohm) |
| Camera | MIPI_DPHY_CSI3_RX_CLKN | J3B | 127 | MIPI_DPHY_CSI3_RX_CLKN | diff_1V8 (100ohm) |
| Camera | MIPI_DPHY_CSI3_RX_D0P | J3B | 117 | MIPI_DPHY_CSI3_RX_D0P | diff_1V8 (100ohm) |
| Camera | MIPI_DPHY_CSI3_RX_D0N | J3B | 115 | MIPI_DPHY_CSI3_RX_D0N | diff_1V8 (100ohm) |
| Camera | MIPI_DPHY_CSI3_RX_D1P | J3B | 123 | MIPI_DPHY_CSI3_RX_D1P | diff_1V8 (100ohm) |
| Camera | MIPI_DPHY_CSI3_RX_D1N | J3B | 121 | MIPI_DPHY_CSI3_RX_D1N | diff_1V8 (100ohm) |
| Camera | MIPI_DPHY_CSI3_RX_D2P | J3B | 135 | MIPI_DPHY_CSI3_RX_D2P | diff_1V8 (100ohm) |
| Camera | MIPI_DPHY_CSI3_RX_D2N | J3B | 133 | MIPI_DPHY_CSI3_RX_D2N | diff_1V8 (100ohm) |
| Camera | MIPI_DPHY_CSI3_RX_D3P | J3B | 141 | MIPI_DPHY_CSI3_RX_D3P | diff_1V8 (100ohm) |
| Camera | MIPI_DPHY_CSI3_RX_D3N | J3B | 139 | MIPI_DPHY_CSI3_RX_D3N | diff_1V8 (100ohm) |
| Camera | I2C_CAM_SCL | J3A | 80 | I2C0_SCL_M1_TP | 1.8V (PMUIO1) |
| Camera | I2C_CAM_SDA | J3A | 82 | I2C0_SDA_M1_TP | 1.8V (PMUIO1) |
| Camera | CAM_RST_n | J3B | 143 | MIPI_CAM3_PDN_1V8 | 1.8V |
| Camera | CAM_MCLK | J1 | 59 | MIPI_CSI3_CAM_CLKOUT_1V8 | 1.8V |
| PDM | PDM1_CLK1_M1 | J3B | 96 | PDM1_CLK1_M1 | 1.8V (VCCIO_AUDIO) |
| PDM | PDM1_SDI1_M1 | J3B | 94 | PDM1_SDI1_M1 | 1.8V (VCCIO_AUDIO) |
| PDM | PDM1_SDI2_M1 | J3B | 111 | PDM1_SDI2_M1 | 1.8V (VCCIO_AUDIO) |
| SAI | SAI1_SCLK | J1 | 25 | SAI1_SCLK_M0 | 1.8V (VCCIO_AUDIO) |
| SAI | SAI1_LRCK | J1 | 19 | SAI1_LRCK_M0 | 1.8V (VCCIO_AUDIO) |
| SAI | SAI1_SDO0 | J1 | 29 | SAI1_SDO0_M0 | 1.8V (VCCIO_AUDIO) |
| SAI | SAI1_MCLK | J1 | 23 | SAI1_MCLK_M0 | 1.8V (VCCIO_AUDIO) |
| Control | GPIO_SPKR_EN | J1 | 96 | SPK_CTL_H | 1.8V (VCCIO6) |
| USB | USB2_OTG0_DP | J3B | 105 | USB2_OTG0_DP | USB 3.3V analog (90ohm) |
| USB | USB2_OTG0_DM | J3B | 103 | USB2_OTG0_DM | USB 3.3V analog (90ohm) |
| UART | UART0_TX_M0_DEBUG | J3A | 55 | UART0_TX_M0_DEBUG | 1.8V (VCCIO6) |
| UART | UART0_RX_M0_DEBUG | J3A | 51 | UART0_RX_M0_DEBUG | 1.8V (VCCIO6) |
| GNSS | GNSS_UART_TX | J3A | 47 | UART7_TX_M0 | 1.8V (VCCIO6) |
| GNSS | GNSS_UART_RX | J3A | 45 | UART7_RX_M0 | 1.8V (VCCIO6) |
| GNSS | GNSS_PPS | J3A | 40 | SPI1_MISO_M0 | 1.8V (VCCIO6) |
| GNSS | GNSS_RST_n | J3A | 44 | SPI1_MOSI_M0 | 1.8V (VCCIO6) |
| Control | RECOVERY_n | J3A | 93 | MASKROM | 1.8V |
| Control | RESET_n | J3A | 92 | RESET_L | 1.8V |
| Control | POWER_KEY | J3A | 99 | PWRON_L | 1.8V |
| Control | WL_nDIS | J3A | 89 | WL_NDIS | 1.8V |
| Control | BT_nDIS | J3A | 91 | BT_NDIS | 1.8V |
| Control | LED_PWR_n | J3A | 95 | NPWR_LED | 1.8V (VCCIO6) |
| Control | LED_STATUS_n | J3A | 21 | PI_NLED_ACTIVITY | 1.8V (VCCIO6) |
| I2C | I2C_IMU_SCL | J3A | 56 | I2C8_SCL_M1 | 1.8V (VCCIO6) |
| I2C | I2C_IMU_SDA | J3A | 58 | I2C8_SDA_M1 | 1.8V (VCCIO6) |
| Control | IMU_INT1 | J3A | 30 | GPIO1_C1 | 1.8V (VCCIO6) |
| Control | VIB_PWM | J3A | 48 | PWM1_CH0_M2 | 1.8V (VCCIO6) |
| Control | VIB_EN | J3A | 34 | CAN1_TX_M3 | 1.8V (VCCIO6) |
| I2C | FUEL_I2C_SCL | J3A | 35 | I2C6_SCL_M3 | 1.8V (VCCIO6) |
| I2C | FUEL_I2C_SDA | J3A | 36 | I2C6_SDA_M3 | 1.8V (VCCIO6) |
| Control | CHG_INT_n | J3A | 37 | SPI1_CSN1_M0 | 1.8V (VCCIO6) |
| Control | LOW_BAT_INT_n | J3A | 39 | SPI1_CSN0_M0 | 1.8V (VCCIO6) |

## 7. Passive component spec audit

Specs from `config/passive_bom_freeze.yaml`. **Verdict** checks good-practice compliance (MLCC voltage derating / DC-bias headroom, tolerance for critical positions). Status: LOCKED_CANDIDATE = ready for schematic-stage freeze (LCSC checked); PROCUREMENT_VERIFY = spec OK, confirm stock; TUNE_OR_EVT_SELECT = footprint/min-spec frozen, value/MPN by RF tuning or bench measurement.

### 7.1 Resistors - value, tolerance, package, tempco, power

| Refs | Value | Role | Tol | Package | Tempco | Power | Temp °C | MPN | LCSC | Status |
|---|---|---|---|---|---|---|---|---|---|---|
| R7, R8, R9, R10, R12, R13 | 2.2k | 1.8V I2C pull-up | 1% | 0603 / 1608 metric | 100 ppm/C | 0.1W | -55..155 | RC0603FR-072K2L | C4190 | LOCKED_CANDIDATE |
| R1, R2 | 5.1k | USB-C sink CC pull-down | 1% | 0603 / 1608 metric | 100 ppm/C | 0.1W | -55..155 | RC0603FR-075K1L | C23186 | LOCKED_CANDIDATE |
| R4, R5 | 1k | LED current limit | 1% | 0603 / 1608 metric | 100 ppm/C | 0.1W | -55..155 | RC0603FR-071KL | C21190 | LOCKED_CANDIDATE |
| R11, R14, R15, R16 | 10k | Reset/recovery/power pull-up and battery NTC placeholder bias | 1% | 0603 / 1608 metric | 100 ppm/C | 0.1W | -55..155 | RC0603FR-0710KL | C25804 | LOCKED_CANDIDATE |
| R18, R19, R20 | 100k | Wireless disable defaults and boost EN default | 1% | 0603 / 1608 metric | 100 ppm/C | 0.1W | -55..155 | RC0603FR-07100KL | C25803 | LOCKED_CANDIDATE |
| R17 | 10R | Active GNSS antenna bias feed, DNP if passive antenna | 1% | 0603 / 1608 metric | 100 ppm/C | 0.1W | -55..155 | RC0603FR-0710RL | C22859 | LOCKED_CANDIDATE |
| R3 | 0R / current shunt | Bring-up current measurement in +5V_SYS path | 1% if populated as shunt; jumper option allowed for no-measure builds | 2512 shunt footprint preferred; Kelvin sense pads recommended |  | 1.0W | -55..155 | TUNE_OR_EVT_SELECT | TUNE_OR_EVT_SELECT | TUNE_OR_EVT_SELECT |

**Resistor verdicts:**
- [OK] **R7, R8, R9, R10, R12, R13** (2.2k): I2C pull-up; 2.2k valid for ~100-400 pF bus at <=400 kHz - confirm vs actual bus capacitance after layout.
- [OK] **R1, R2** (5.1k): USB-C CC sink pull-down - 1% locked (correct per spec).
- [OK] **R4, R5** (1k): LED current-limit - 1% fine (5% also OK).
- [OK] **R11, R14, R15, R16** (10k): Reset/recovery/power pull-up and battery NTC placeholder bias - tolerance 1%.
- [OK] **R18, R19, R20** (100k): Wireless disable defaults and boost EN default - tolerance 1%.
- [OK] **R17** (10R): Active GNSS antenna bias feed, DNP if passive antenna - tolerance 1%.
- [!] **R3** (0R / current shunt): 0ohm/shunt in the 5V high-current path - do NOT use a tiny 0603; select a real mohm shunt (0.005-0.02ohm, 2512, Kelvin) or a 1% jumper.

### 7.2 Capacitors - value, voltage, dielectric, package, temp

| Refs | Value | Role | Dielectric | Voltage | Tol | Package | Temp °C | MPN | LCSC | Status |
|---|---|---|---|---|---|---|---|---|---|---|
| C2, C4, C6, C10, C13, C14, C16, C17, C18, C19, C20, C21, C22, C28, C30 | 100nF | Local HF decoupling and antenna-bias decoupling | X7R | 50V | 10% | 0603 / 1608 metric | -55..125 | CC0603KRX7R9BB104 | C14663 | LOCKED_CANDIDATE |
| C9, C11 | 1uF | Input/local decoupling | X7R | 16V | 10% | 0603 / 1608 metric | -55..125 | CL10B105KO8NNNC | C15849 | LOCKED_CANDIDATE |
| C1, C3, C5, C8, C15, C29 | 10uF | Rail bulk decoupling | X5R | 25V | 10% | 0805 / 2012 metric | -55..85 | CL21A106KAYNNNE | C15850 | LOCKED_CANDIDATE |
| C7 | 22uF | VBAT bulk decoupling | X5R | 25V | 20% | 0805 / 2012 metric | -55..85 | CL21A226MAQNNNE | C45783 | LOCKED_CANDIDATE |
| C23, C24 | 1nF | Class-D speaker EMI shunt | X7R | 50V | 10% | 0603 / 1608 metric | -55..125 | CC0603KRX7R9BB102 | C1669 | LOCKED_CANDIDATE |
| C27 | 100pF initial / tune | GNSS RF DC block or series match | C0G/NP0 | 25V(min) | 5% or better | 0402 / 1005 metric | -55..125 | TUNE_OR_EVT_SELECT | TUNE_OR_EVT_SELECT | TUNE_OR_EVT_SELECT |
| C25, C26 | DNP / tune | GNSS pi-match shunt pads | C0G/NP0 | 25V(min) | 5% or better | 0402 / 1005 metric | -55..125 | DNP_TUNE_KIT | DNP_TUNE_KIT | TUNE_OR_EVT_SELECT |

**Capacitor verdicts (DC-bias / derating vs rail):**
- **C2, C4, C6, C10, C13, C14, C16, C17, C18, C19, C20, C21, C22, C28, C30** (100nF, X7R): [OK] 50V on +5V_SYS (5.0V) -> 10.0× margin, good DC-bias headroom
- **C9, C11** (1uF, X7R): [OK] 16V on USB_VBUS (5.0V) -> 3.2× margin, good DC-bias headroom
- **C1, C3, C5, C8, C15, C29** (10uF, X5R): [OK] 25V on +5V_SYS (5.0V) -> 5.0× margin, good DC-bias headroom - bulk MLCC: confirm effective C after DC bias (consider 0805/larger).
- **C7** (22uF, X5R): [OK] 25V on +VBAT (4.2V) -> 6.0× margin, good DC-bias headroom - bulk MLCC: confirm effective C after DC bias (consider 0805/larger).
- **C23, C24** (1nF, X7R): [OK] spec OK (no power rail mapped / EMI position).
- **C27** (100pF initial / tune, C0G/NP0): [OK] RF/timing position - C0G/NP0, 25V min; value RF-tuned.
- **C25, C26** (DNP / tune, C0G/NP0): [OK] RF/timing position - C0G/NP0, 25V min; value RF-tuned.

### 7.3 Magnetics, protection, indicators

| Refs | Category | Value | Role | Package | Key ratings | MPN | LCSC | Status |
|---|---|---|---|---|---|---|---|---|
| L1 | inductor | 4.7uH | TPS61022-class 1S to 5V boost inductor | Shielded power inductor, about 7x7mm class | saturation_current_A_min=10; rms_current_A_min=6; dcr_mohm_max=25 | TUNE_OR_EVT_SELECT | TUNE_OR_EVT_SELECT | TUNE_OR_EVT_SELECT |
| FB1, FB2 | ferrite_bead | 600R@100MHz | Class-D speaker output EMI bead | 0603 / 1608 metric | impedance_ohm_at_100MHz=600; current_rating_A_min=1 | BLM18AG601SN1D | PROCUREMENT_VERIFY | PROCUREMENT_VERIFY |
| L2 | rf_inductor | RF choke / active antenna bias | GNSS active antenna bias tee, DNP if passive antenna | 0402 / 1005 metric | inductance_initial=47nH initial / tune; q_requirement=High-Q at GNSS L1 | TUNE_OR_EVT_SELECT | TUNE_OR_EVT_SELECT | TUNE_OR_EVT_SELECT |
| D3 | tvs | SMAJ5.0A | USB VBUS surge/ESD clamp | SMA / DO-214AC | peak_pulse_power_W_min=400; vrwm_V=5 | SMAJ5.0A | PROCUREMENT_VERIFY | PROCUREMENT_VERIFY |
| D4 | esd | low-cap RF ESD, <=0.3pF | GNSS antenna RF ESD clamp | SOD-882 (DFN1006-2) low-cap RF ESD | vrwm_V_min=5; capacitance_pF_max=0.3 | PROCUREMENT_VERIFY_LOW_CAP_RF_ESD | PROCUREMENT_VERIFY | PROCUREMENT_VERIFY |
| U2, U16 | esd_array | TPD4E05U06 | MIPI CSI3 low-capacitance ESD arrays | USON-10 (DQA) 2.5x1.0mm, 0.5mm pitch (TI DQA0010A) | vrwm_V_min=5; capacitance_pF_max=0.4; channels=4 | TPD4E05U06 | PROCUREMENT_VERIFY | PROCUREMENT_VERIFY |
| U5 | esd_array | TPD2E009 | USB2 D+/D- ESD clamp | SOT-553 (DRL); confirm pad map vs symbol when real symbol added | vrwm_V_min=5; capacitance_pF_max=1.5; channels=2 | TPD2E009 | PROCUREMENT_VERIFY | PROCUREMENT_VERIFY |
| D1, D2 | led | 0603 LED, green/blue | Power/status indicators | 0603 / 1608 metric | current_mA_nominal=1 | PROCUREMENT_VERIFY_LED_COLOR | PROCUREMENT_VERIFY | PROCUREMENT_VERIFY |

## 8. What's missing - open TBDs (freeze gate, §8.3)

| ID | Resolved | Must confirm |
|---|---|---|
| `CM4_SKU` | [OK] | CONFIRMED RM126-D4E32J0R35W28: RK3576 / 4GB LPDDR4X / 32GB eMMC / Wi-Fi6+BT5.x. Antenna form tracked under ANTENNA. |
| `CAMERA_ELECTRICAL_PINOUT` | [OK] | RESOLVED: camera module is Radxa Camera 4K / Sony IMX415-AAQR-C; 31-pin FPC pinout captured in CM4_IMX415_design_files/Radxa_Camera_4K_31pin_pinout.csv and cross-referenced in docs/p0_p1_decisions_2026-06-28.md. |
| `CAMERA_CONNECTOR_MPN` | [OK] | RESOLVED: carrier J2 connector is Hirose FH35C-31S-0.3SHW(50), LCSC C424662. Footprint has been generated from the Hirose 2D drawing. |
| `CAMERA_CABLE` | [OK] | RESOLVED: use Radxa AC006, 31P 0.3mm to 31P 0.3mm, opposite-side FPC. Do not use AC008; AC008 is 31P to 15P. |
| `CAMERA_SCHEMATIC_GATE` | [OK] | RESOLVED for schematic stage: J2 pins 1-31, CSI3 4-lane mapping, P/N polarity, I2C/MCLK/RESET, voltage domains, power pins and NC pins are checked by scripts/audit_csi3_camera.py. RESET is active-low on project net CAM_RST_n; no PWDN pin is present in the Radxa Camera 4K 31-pin pinout. |
| `CAMERA_KICAD_IMPLEMENTATION` | [X] | PARTIAL: schematic source now uses 31-pin FH35C/Radxa Cam4K pinout on CM4 CSI3 4-lane, and the FH35C footprint has been regenerated from the Hirose 2D drawing. DEFERRED_TO_PRE_LAYOUT: AC006 physical validation, FPC contact side, FPC insertion direction, J2 Pin 1 physical check, 1:1 print, coupon test, and FPC bend/enclosure path. Official CM4 IO overlay radxa-cm4-io-radxa-camera-4k.dtbo is confirmed. Bring-up logs (dmesg/media/v4l2) remain open for EVT. |
| `AUDIO_PARTS` | [OK] | CONFIRMED: 2×SPH0641LU4H-1 mic, MAX98357AETE+T (C910544) amp, Ole Wolff OWS-091630W50A-8 8ohm/1W (C5840086) speaker |
| `GNSS_MODULE` | [OK] | CONFIRMED u-blox MAX-M10S-00B-01: UART, VCC=3.3V/VIO=1.8V, 50ohm U.FL, external active antenna (-match + bias-tee, DNP for passive) |
| `BATTERY` | [OK] | Reverse-calc: 1S 2-3×(35×18×4mm ~250mAh)=500-750mAh/1.85-2.8Wh. V1 bench use ~1.5-2Ah. >3-4h target needs AI duty-cycling (system-power issue, see report) |
| `POWER_5V` | [OK] | CONSERVATIVE FREEZE: keep TPS61022-class 1S->5V boost and design +5V_SYS for >=4A bench/boost margin. R3 remains the bring-up shunt/0R measurement point; final peak/thermal validation is deferred to bench testing. |
| `ANTENNA` | [OK] | CONSERVATIVE FREEZE: Wi-Fi/BT stays on the CM4 module/U.FL path; carrier does not add 2.4/5GHz RF routing. Layout must reserve the CM4 antenna keep-out and keep battery, metal hinge/screws, speaker magnet, and copper away from the antenna zone. |
| `BOARD_OUTLINE` | [X] | SOURCE GEOMETRY RESOLVED: CM4 module outline = 40.02x54.98mm from official DXF; CM4/IO Board DXF, STEP, placement map and dimensions drawing are the mechanical inputs. OPEN: project must freeze board length/width/radius, USB-C/camera/battery/debug exit direction, mounting holes, and battery-vs-CM4 position. |
| `B2B_CONNECTOR` | [X] | SOURCE FILES RESOLVED: carrier receptacle DF40C-100DS-0.4V(51), module plug DF40C-100DP-0.4V(51), 1.5mm mated height. OPEN: build 2-layer connector-only fit-check board and verify all three connectors press in together with no module lift/skew. |
| `PINMUX` | [OK] | PDM/SAI/I2C/UART/GPIO conflict map + Device Tree |

Plus schematic-stage structural gaps: **no footprints placed on PCB** (skeleton), `VERIFY` placeholder footprints (§4), and the carrier board outline + B2B connector XY (needs official CM4 DXF/STEP aligned in KiCad).

## 9. Key recommendations

1. **USB-C CC (R1/R2, 5.1k):** locked at 1% [OK] - keep. Sink-role pull-downs to GND.
2. **I2C pull-ups (2.2k, R7-R13):** validate against measured bus capacitance after layout; 2.2k suits <=400 kHz / <=~400 pF. Camera I2C0, IMU I2C8, charger/fuel I2C6 are separate buses.
3. **5V-rail MLCC:** 10µF is 25V X5R / 1µF is 16V / 100nF is 50V -> all >=2× the 5V rail, good DC-bias margin. Still confirm **effective** capacitance of 10µF/0805 after DC bias on +5V_SYS.
4. **VBAT bulk (C7, 22µF/25V):** fine for 4.2V; high glasses-cell C-rate means keep/expand bulk near the boost input.
5. **R3 current shunt:** replace the 0ohm placeholder with a defined mohm shunt (2512, Kelvin) before measuring 5V power, or populate a 1% jumper for no-measure builds.
6. **GNSS RF (C25/C26/C27, L2):** C0G/NP0, values RF-tuned with the chosen antenna; C25/C26 stay DNP unless tuning needs shunt C; bias-tee (L2/R17/C28) DNP for a passive antenna.
7. **Boost inductor (L1):** select a >=10A-saturation shielded part sized to the measured 5V peak; footprint is a `VERIFY` placeholder.
8. **Replace all `VERIFY` footprints** (B2B, ESD arrays, RF ESD, inductor) with purchasable, library-verified footprints before layout.

---
## Appendix A - full pin -> net connections

| Ref | Pin | Net |
|---|---|---|
| J31 | P77-87 +5V | +5V_SYS |
| J31 | P78 VREF->1V8 | +1V8 |
| J31 | GND | GND |
| J31 | P55 DBG_TX | UART_DBG_TX |
| J31 | P51 DBG_RX | UART_DBG_RX |
| J31 | P47 GNSS_TX | GNSS_UART_TX |
| J31 | P45 GNSS_RX | GNSS_UART_RX |
| J31 | P40 GNSS_PPS | GNSS_PPS |
| J31 | P44 GNSS_RST | GNSS_RST_n |
| J31 | P80 CAM_SCL | CAM_I2C_SCL |
| J31 | P82 CAM_SDA | CAM_I2C_SDA |
| J31 | P56 IMU_SCL | IMU_I2C_SCL |
| J31 | P58 IMU_SDA | IMU_I2C_SDA |
| J31 | P35 FUEL_SCL | FUEL_I2C_SCL |
| J31 | P36 FUEL_SDA | FUEL_I2C_SDA |
| J31 | P30 IMU_INT | IMU_INT1 |
| J31 | P48 VIB_PWM | VIB_PWM |
| J31 | P34 VIB_EN | VIB_EN |
| J31 | P37 CHG_INT | CHG_INT_n |
| J31 | P39 LBAT_INT | LOW_BAT_INT_n |
| J31 | P95 LED_PWR | LED_PWR_n |
| J31 | P21 LED_STAT | LED_STATUS_n |
| J31 | P93 RECOVERY | RECOVERY_n |
| J31 | P92 RESET | RESET_n |
| J31 | P99 PWR_KEY | POWER_KEY |
| J31 | P89 WL_DIS | WL_nDIS |
| J31 | P91 BT_DIS | BT_nDIS |
| J32 | P129 CSI3_CLKP | MIPI_CSI3_CLK_P |
| J32 | P127 CSI3_CLKN | MIPI_CSI3_CLK_N |
| J32 | P117 CSI3_D0P | MIPI_CSI3_D0_P |
| J32 | P115 CSI3_D0N | MIPI_CSI3_D0_N |
| J32 | P123 CSI3_D1P | MIPI_CSI3_D1_P |
| J32 | P121 CSI3_D1N | MIPI_CSI3_D1_N |
| J32 | P135 CSI3_D2P | MIPI_CSI3_D2_P |
| J32 | P133 CSI3_D2N | MIPI_CSI3_D2_N |
| J32 | P141 CSI3_D3P | MIPI_CSI3_D3_P |
| J32 | P139 CSI3_D3N | MIPI_CSI3_D3_N |
| J32 | P143 CAM3_GPIO | CAM_RST_n |
| J32 | P105 USB_DP | USB_DP |
| J32 | P103 USB_DM | USB_DM |
| J32 | P96 PDM_CLK | PDM1_CLK |
| J32 | P94 PDM_D0 | PDM1_DATA0 |
| J32 | P111 PDM_D1 | PDM1_DATA1 |
| J32 | GND | GND |
| J1 | P25 SAI_BCLK | SAI1_BCLK |
| J1 | P19 SAI_LRCK | SAI1_LRCK |
| J1 | P29 SAI_SDO | SAI1_SDO |
| J1 | P23 SAI_MCLK_UNUSED | NC |
| J1 | P59 CAM3_MCLK | CAM_MCLK |
| J1 | P96 SPK_EN | SPKR_EN_n |
| J1 | +1V8 (P88/90) | +1V8 |
| J1 | GND | GND |
| J2 | 1 GND | GND |
| J2 | 2 MDN4 | MIPI_CSI3_D3_N |
| J2 | 3 MDP4 | MIPI_CSI3_D3_P |
| J2 | 4 GND | GND |
| J2 | 5 MDN3 | MIPI_CSI3_D2_N |
| J2 | 6 MDP3 | MIPI_CSI3_D2_P |
| J2 | 7 GND | GND |
| J2 | 8 NC | NC |
| J2 | 9 NC | NC |
| J2 | 10 GND | GND |
| J2 | 11 MDN2 | MIPI_CSI3_D1_N |
| J2 | 12 MDP2 | MIPI_CSI3_D1_P |
| J2 | 13 GND | GND |
| J2 | 14 MDN1 | MIPI_CSI3_D0_N |
| J2 | 15 MDP1 | MIPI_CSI3_D0_P |
| J2 | 16 GND | GND |
| J2 | 17 MCN | MIPI_CSI3_CLK_N |
| J2 | 18 MCP | MIPI_CSI3_CLK_P |
| J2 | 19 GND | GND |
| J2 | 20 MCLK | CAM_MCLK |
| J2 | 21 GND | GND |
| J2 | 22 NC | NC |
| J2 | 23 NC | NC |
| J2 | 24 SCL | CAM_I2C_SCL |
| J2 | 25 SDA | CAM_I2C_SDA |
| J2 | 26 NC | NC |
| J2 | 27 RESET_N | CAM_RST_n |
| J2 | 28 VCC3.3V | +CAM_3V3 |
| J2 | 29 VCC3.3V | +CAM_3V3 |
| J2 | 30 VCC5V | +5V_SYS |
| J2 | 31 VCC5V | +5V_SYS |
| U2 | CLK_P | MIPI_CSI3_CLK_P |
| U2 | CLK_N | MIPI_CSI3_CLK_N |
| U2 | D0_P | MIPI_CSI3_D0_P |
| U2 | D0_N | MIPI_CSI3_D0_N |
| U2 | D1_P | MIPI_CSI3_D1_P |
| U2 | D1_N | MIPI_CSI3_D1_N |
| U2 | GND | GND |
| U16 | D2_P | MIPI_CSI3_D2_P |
| U16 | D2_N | MIPI_CSI3_D2_N |
| U16 | D3_P | MIPI_CSI3_D3_P |
| U16 | D3_N | MIPI_CSI3_D3_N |
| U16 | GND | GND |
| U3 | VIN | +5V_SYS |
| U3 | EN | CAM_PWR_EN |
| U3 | GND | GND |
| U3 | VOUT | +CAM_3V3 |
| R7 | 1 | +1V8 |
| R7 | 2 | CAM_I2C_SCL |
| R8 | 1 | +1V8 |
| R8 | 2 | CAM_I2C_SDA |
| C8 | 1 | +CAM_3V3 |
| C8 | 2 | GND |
| C9 | 1 | +CAM_3V3 |
| C9 | 2 | GND |
| C10 | 1 | +CAM_3V3 |
| C10 | 2 | GND |
| C29 | 1 | +5V_SYS |
| C29 | 2 | GND |
| C30 | 1 | +5V_SYS |
| C30 | 2 | GND |
| MK1 | VDD | +1V8 |
| MK1 | CLK | PDM1_CLK |
| MK1 | DATA | PDM1_DATA0 |
| MK1 | SEL | GND |
| MK1 | GND | GND |
| MK2 | VDD | +1V8 |
| MK2 | CLK | PDM1_CLK |
| MK2 | DATA | PDM1_DATA1 |
| MK2 | SEL | +1V8 |
| MK2 | GND | GND |
| U4 | VDD | +5V_SYS |
| U4 | GND | GND |
| U4 | BCLK | SAI1_BCLK |
| U4 | LRC | SAI1_LRCK |
| U4 | DIN | SAI1_SDO |
| U4 | SD | SPKR_EN_n |
| U4 | GAIN | GND |
| U4 | OUT+ | SPK_OUT_P |
| U4 | OUT- | SPK_OUT_N |
| FB1 | 1 | SPK_OUT_P |
| FB1 | 2 | SPK_P_F |
| FB2 | 1 | SPK_OUT_N |
| FB2 | 2 | SPK_N_F |
| C23 | 1 | SPK_P_F |
| C23 | 2 | GND |
| C24 | 1 | SPK_N_F |
| C24 | 2 | GND |
| J3 | SPK+ | SPK_P_F |
| J3 | SPK- | SPK_N_F |
| C13 | 1 | +5V_SYS |
| C13 | 2 | GND |
| J4 | VBUS | USB_VBUS |
| J4 | GND | GND |
| J4 | DP | USB_DP |
| J4 | DM | USB_DM |
| J4 | CC1 | USB_CC1 |
| J4 | CC2 | USB_CC2 |
| J4 | SHLD | GND |
| U5 | DP | USB_DP |
| U5 | DM | USB_DM |
| U5 | GND | GND |
| R1 | 1 | USB_CC1 |
| R1 | 2 | GND |
| R2 | 1 | USB_CC2 |
| R2 | 2 | GND |
| D3 | 1 | USB_VBUS |
| D3 | 2 | GND |
| U15 | IN | USB_VBUS |
| U15 | EN | USB_VBUS |
| U15 | GND | GND |
| U15 | OUT | VBUS_PROT |
| R3 | 1 | VBUS_PROT |
| R3 | 2 | +5V_SYS |
| C11 | 1 | USB_VBUS |
| C11 | 2 | GND |
| U12 | VIN | +5V_SYS |
| U12 | GND | GND |
| U12 | VOUT | +3V3 |
| U13 | VIN | +3V3 |
| U13 | GND | GND |
| U13 | VOUT | +1V8 |
| C1 | 1 | +5V_SYS |
| C1 | 2 | GND |
| C2 | 1 | +5V_SYS |
| C2 | 2 | GND |
| C3 | 1 | +3V3 |
| C3 | 2 | GND |
| C4 | 1 | +3V3 |
| C4 | 2 | GND |
| C5 | 1 | +1V8 |
| C5 | 2 | GND |
| C6 | 1 | +1V8 |
| C6 | 2 | GND |
| U6 | VIN | +VBAT |
| U6 | SW | BOOST_SW |
| U6 | EN | BOOST_EN |
| U6 | FB | +5V_SYS |
| U6 | GND | GND |
| R20 | 1 | +VBAT |
| R20 | 2 | BOOST_EN |
| L1 | 1 | +VBAT |
| L1 | 2 | BOOST_SW |
| U7 | IN | USB_VBUS |
| U7 | SYS | +VBAT |
| U7 | BAT | VBAT_P |
| U7 | TS | BAT_NTC |
| U7 | SCL | FUEL_I2C_SCL |
| U7 | SDA | FUEL_I2C_SDA |
| U7 | INT | CHG_INT_n |
| U7 | GND | GND |
| U8 | VDD | VBAT_P |
| U8 | VM | VBAT_N |
| U8 | OUT | +VBAT |
| U9 | VDD | +VBAT |
| U9 | CELL | +VBAT |
| U9 | SCL | FUEL_I2C_SCL |
| U9 | SDA | FUEL_I2C_SDA |
| U9 | ALRT | LOW_BAT_INT_n |
| U9 | GND | GND |
| J5 | BAT+ | VBAT_P |
| J5 | BAT- | VBAT_N |
| J5 | NTC | BAT_NTC |
| C7 | 1 | +VBAT |
| C7 | 2 | GND |
| R11 | 1 | BAT_NTC |
| R11 | 2 | GND |
| U10 | VDD | +1V8 |
| U10 | GND | GND |
| U10 | SCL | IMU_I2C_SCL |
| U10 | SDA | IMU_I2C_SDA |
| U10 | INT1 | IMU_INT1 |
| R9 | 1 | +1V8 |
| R9 | 2 | IMU_I2C_SCL |
| R10 | 1 | +1V8 |
| R10 | 2 | IMU_I2C_SDA |
| U11 | VDD | +5V_SYS |
| U11 | GND | GND |
| U11 | IN | VIB_PWM |
| U11 | EN | VIB_EN |
| U11 | OUT+ | VIB_OUT_P |
| U11 | OUT- | VIB_OUT_N |
| J6 | M+ | VIB_OUT_P |
| J6 | M- | VIB_OUT_N |
| U14 | VCC | +3V3 |
| U14 | V_IO | +1V8 |
| U14 | V_BCKP | +3V3 |
| U14 | GND | GND |
| U14 | TXD | GNSS_UART_RX |
| U14 | RXD | GNSS_UART_TX |
| U14 | TIMEPULSE | GNSS_PPS |
| U14 | RESET_N | GNSS_RST_n |
| U14 | RF_IN | GNSS_RFIN |
| C27 | 1 | GNSS_RFIN |
| C27 | 2 | GNSS_ANT |
| C25 | 1 | GNSS_RFIN |
| C25 | 2 | GND |
| C26 | 1 | GNSS_ANT |
| C26 | 2 | GND |
| L2 | 1 | GNSS_ANT |
| L2 | 2 | V_ANT_BIAS |
| R17 | 1 | +3V3 |
| R17 | 2 | V_ANT_BIAS |
| C28 | 1 | V_ANT_BIAS |
| C28 | 2 | GND |
| J8 | ANT | GNSS_ANT |
| J8 | GND | GND |
| C14 | 1 | +3V3 |
| C14 | 2 | GND |
| C15 | 1 | +3V3 |
| C15 | 2 | GND |
| D1 | A | LED_PWR_A |
| D1 | K | LED_PWR_n |
| R4 | 1 | +3V3 |
| R4 | 2 | LED_PWR_A |
| D2 | A | LED_STAT_A |
| D2 | K | LED_STATUS_n |
| R5 | 1 | +3V3 |
| R5 | 2 | LED_STAT_A |
| J7 | TX | UART_DBG_TX |
| J7 | RX | UART_DBG_RX |
| J7 | GND | GND |
| J7 | VREF | +3V3 |
| TP1 | 1 | +VBAT |
| TP2 | 1 | +5V_SYS |
| TP3 | 1 | +3V3 |
| TP4 | 1 | +1V8 |
| TP5 | 1 | GND |
| TP6 | 1 | UART_DBG_TX |
| TP7 | 1 | UART_DBG_RX |
| TP8 | 1 | CAM_I2C_SCL |
| TP9 | 1 | CAM_I2C_SDA |
| TP10 | 1 | IMU_I2C_SCL |
| TP11 | 1 | IMU_I2C_SDA |
| TP12 | 1 | FUEL_I2C_SCL |
| TP13 | 1 | FUEL_I2C_SDA |
| TP14 | 1 | RESET_n |
| TP15 | 1 | RECOVERY_n |
| TP16 | 1 | CAM_PWR_EN |
| SW1 | 1 | RECOVERY_n |
| SW1 | 2 | GND |
| SW2 | 1 | RESET_n |
| SW2 | 2 | GND |
| SW3 | 1 | POWER_KEY |
| SW3 | 2 | GND |
| R14 | 1 | +1V8 |
| R14 | 2 | RECOVERY_n |
| R15 | 1 | +1V8 |
| R15 | 2 | RESET_n |
| R16 | 1 | +1V8 |
| R16 | 2 | POWER_KEY |
| R18 | 1 | +1V8 |
| R18 | 2 | WL_nDIS |
| R19 | 1 | +1V8 |
| R19 | 2 | BT_nDIS |
| R12 | 1 | +1V8 |
| R12 | 2 | FUEL_I2C_SCL |
| R13 | 1 | +1V8 |
| R13 | 2 | FUEL_I2C_SDA |
| C16 | 1 | +1V8 |
| C16 | 2 | GND |
| C17 | 1 | USB_VBUS |
| C17 | 2 | GND |
| C18 | 1 | +VBAT |
| C18 | 2 | GND |
| C19 | 1 | +VBAT |
| C19 | 2 | GND |
| C20 | 1 | +5V_SYS |
| C20 | 2 | GND |
| C21 | 1 | +3V3 |
| C21 | 2 | GND |
| C22 | 1 | +1V8 |
| C22 | 2 | GND |
| D4 | 1 | GNSS_ANT |
| D4 | 2 | GND |

---
_Generated by `scripts/generate_design_review.py` from working sources (`carrier_bom.py`, `cm4_pinmap.py`, `config/passive_bom_freeze.yaml`, `ai_context/*.json`). Native KiCad/XLSX remain the source of truth (repo CLAUDE.md)._

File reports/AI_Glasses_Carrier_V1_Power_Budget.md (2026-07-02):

# AI Glasses Carrier V1 - Power Budget & Battery Sizing

- **Generated:** 2026-06-30  |  Source: `config/power_budget.yaml`
- **Assumptions:** 1S Li-Po 3.7 V nominal; boost eff 90%; usable DoD 90%.
- **[!] ESTIMATE** from datasheet typicals - NOT bench-measured. Fill measured current (R3 0R/shunt on +5V) during bring-up and re-run.

## 1. Per-subsystem load power (mW)

| Subsystem | Idle | Typical | Full | Note |
|---|--:|--:|--:|---|
| CM4 (RK3576 SoC + LPDDR4X + eMMC) | 450 | 2000 | 2900 | Dominant load; NPU AI + camera ISP + H.265 encode drive the peaks |
| Wi-Fi / BT radio (on CM4) | 50 | 200 | 750 | TX bursts; radio is on the CM4 module |
| Camera IMX415 (4-lane MIPI) | 0 | 400 | 450 | Off in idle; streaming otherwise |
| Audio amp + speaker (avg) | 0 | 150 | 300 | Class-D average for speech; short music peaks to ~3W not in the average |
| PDM mics x2 | 10 | 20 | 20 |  |
| GNSS MAX-M10S | 20 | 80 | 80 | ~25 mA @3.3V during acquisition/tracking |
| IMU ICM-42688-P | 1 | 1 | 2 | Low-power 6-axis |
| Haptic DRV2605L (avg) | 0 | 0 | 100 | Only during a vibration pulse |
| Status LEDs | 20 | 30 | 30 |  |
| LDO quiescent + regulation loss margin | 100 | 150 | 200 | 3V3/1V8 LDO drop + headroom |
| **TOTAL load** | **651** | **3031** | **4832** | mW |

## 2. Battery-side current & runtime

Battery current = load / (3.7 V x 90% boost). Runtime uses 90% usable DoD.

| Scenario | Load (W) | Batt current (mA) | Draw/hour (mAh) | V1 bench 103450 (2000 mAh) | Glasses pack (2-3 cells) (650 mAh) |
|---|--:|--:|--:|--:|--:|
| Idle | 0.65 | 195 | 195 | 9.2 h | 3.0 h |
| Typical | 3.03 | 910 | 910 | 2.0 h | 0.6 h |
| Full | 4.83 | 1451 | 1451 | 1.2 h | 0.4 h |

## 3. Battery capacity required for a target runtime

Capacity (mAh) needed to sustain each scenario for the target time (1S 3.7 V, 90% DoD, boost 90%):

| Scenario | Load (W) | 1 h | 2 h | 3 h | 4 h |
|---|--:|--:|--:|--:|--:|
| Idle | 0.65 | 217 mAh | 434 mAh | 652 mAh | 869 mAh |
| Typical | 3.03 | 1011 mAh | 2023 mAh | 3034 mAh | 4045 mAh |
| Full | 4.83 | 1612 mAh | 3225 mAh | 4837 mAh | 6449 mAh |

## 4. Bottom line

- **Typical use ~3.0 W** -> battery draws **~910 mA**, i.e. **~1011 mAh per hour**.
- Hitting the **3-4 h** target at typical load needs **~3034-4045 mAh**.
- **V1 bench 103450 (2000 mAh)** -> ~2.0 h typical, ~1.2 h full, ~9.2 h idle.
- **Glasses pack (2-3 cells) (650 mAh)** -> ~0.6 h typical, ~0.4 h full, ~3.0 h idle.
- The glasses pack cannot reach 3-4 h at a steady ~3 W; that target needs **AI duty-cycling** (wake-on-demand, gate the NPU/camera/encode), not just a bigger cell.

---
_Estimates from `config/power_budget.yaml`. Replace with R3-shunt bench measurements during bring-up and re-run `scripts/power_budget.py`._

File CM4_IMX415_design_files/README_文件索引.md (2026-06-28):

# Radxa CM4 + IMX415 设计文件索引

本目录用于支持以下五项工作：

1. Radxa Camera 4K / IMX415 31-pin FPC 原理图连接
2. CM4 4-lane CSI 引脚切换与核对
3. CM4 三组 B2B 连接器 Fit-Check
4. 载板外形、连接器 XY 和 3D 装配
5. POWER_5V 与 Wi-Fi/BT 天线布局的后续验证

> 注意：目录中已放入项目现有的 CM4 与 CM4 IO Board 原理图。其余官方文件请运行 `fetch_official_files.sh` 下载，或使用下方链接手动下载。

---

## A. 相机：Radxa Camera 4K / IMX415

### A1. 官方相机页面（含完整 31-pin pinout）
https://docs.radxa.com/en/accessories/camera/camera-4k

### A2. Radxa Camera 4K Product Brief
https://dl.radxa.com/accessories/camera-4k/radxa_camera_4k_product_brief_Revision_1.0.pdf

用途：确认模组尺寸、4-lane MIPI CSI-2、镜头、FOV、排线长度。

### A3. Sony IMX415-AAQR-C Datasheet
https://dl.radxa.com/accessories/camera-4k/IMX415-AAQR-C_Datasheet_E19504.pdf

用途：确认传感器电源、电平、时钟、I2C、CSI-2、上电时序和寄存器。

### A4. 31-pin pinout
见同目录：`Radxa_Camera_4K_31pin_pinout.csv`

关键提醒：
- FPC 接触面、Pin 1 方向和连接器上下接触方式标记为 `DEFERRED_TO_PRE_LAYOUT`，不作为当前 schematic 电气门禁。
- 不能只按针数画连接器。
- 相机模块的 4 条数据 lane 标为 MD1~MD4；当前 schematic 已按 CSI3 D0~D3 审计，CM4 Device Tree `data-lanes` 仍必须保持同一 lane order。

### A5. IMX415 bring-up 参考
ROCK 5 ITX 官方教程：
https://docs.radxa.com/en/rock5/rock5itx/getting-started/interface-usage/camera

这只能作为 IMX415 驱动/overlay 和 GStreamer 测试方法的参考，不能证明其 overlay 可不修改地用于 CM4。

---

## B. CM4 4-lane CSI 与 Pin Assignment

### B1. CM4 Schematic V1.20
本目录已有：`radxa_cm4_schematic_v1.20.pdf`

重点页面：
- Page 11：RK3576 MIPI DSI/CSI
- Page 22：High Speed Connector J3B

### B2. CM4 Pinout Table V1.20
https://dl.radxa.com/cm4/docs/hw/radxa_cm4_pinout_v1.20.xlsx

用途：将相机 lane、clock、I2C、MCLK、RESET/PWDN 映射到准确的 J3B/J1 引脚与电压域。

### B3. CM4 IO Schematic V1.10
本目录已有：`radxa_cm4_io_schematic_v1.10.pdf`

重点页面：
- Page 9：High Speed Connector
- Page 10：IO Connector / camera control
- Page 17：MIPI CSI RX

命名提醒：项目里称“CSI3”时，必须确认它指的是 SoC 的 CSI3/4 组合 4-lane 通道，还是官方 IO Board 上标注的 4-lane camera port。不要仅根据名称自动替换网络。

---

## C. B2B Fit-Check 与载板外形

### C1. CM4 Components Placement Map V1.20
https://dl.radxa.com/cm4/docs/hw/radxa_cm4_components_placement_map_v1.20.pdf

### C2. CM4 2D DXF V1.20
https://dl.radxa.com/cm4/docs/hw/radxa_cm4_2d_dxf_v1.20.zip

这是建立载板外形和三组连接器 XY 的主要机械基准。

### C3. CM4 3D STEP V1.20
https://dl.radxa.com/cm4/docs/hw/radxa_cm4_3d_stp_v1.20.zip

这是进行 3D 装配、干涉、压合方向和高度检查的主要文件。

### C4. CM4 IO Board 参考机械文件
Placement Map:
https://dl.radxa.com/cm4/cm4-io-board/docs/hw/radxa_cm4_io_components_placement_map_v1.10.pdf

2D DXF:
https://dl.radxa.com/cm4/cm4-io-board/docs/hw/radxa_cm4_io_2d_dxf_v1.10.zip

本仓库已保存：
- `mechanical/radxa_cm4_io_2d_dxf_v1.10/RC126_V1.10_20250526_TOP.dxf`
- `mechanical/radxa_cm4_io_2d_dxf_v1.10/RC126_V1.10_20250526_BOT.dxf`

可可靠抽取的事实：官方 IO Board 板框约 160.01 x 90.02 mm。DXF 中的 `Connector_1/2/3` 是文字标签位置，不是可直接制造的 DF40C footprint origin。

3D STEP:
https://dl.radxa.com/cm4/cm4-io-board/docs/hw/radxa_cm4_io_3d_stp_v1.10.zip

官方工程仓库：
https://github.com/radxa/radxa-cm-projects/tree/main/cm4/radxa-cm4-io-board

### C5. Hirose DF40C 连接器官方文件
CM4 模块端 Plug：DF40C-100DP-0.4V(51)
https://www.hirose.com/product/p/CL0684-4032-1-51

载板端 Receptacle：DF40C-100DS-0.4V(51)
https://www.hirose.com/product/p/CL0684-4033-4-51

在产品页面下载：
- Drawing (2D)
- Specification Sheet
- Product Guidelines
- Drawing (3D) (STEP)

该 DP + DS 组合的标称 mating height 为 1.5 mm。Fit-Check 板应只焊三只载板端 DS 连接器，以验证 XY、Pin 1、旋转角、压合和拆卸。

---

## D. POWER_5V

目前不存在一份能替代实测的“CM4 + IMX415 + 音频 + GNSS 峰值功耗文件”。应结合：

- CM4 Schematic V1.20
- CM4 Pinout V1.20（确认全部 5 V 输入引脚）
- 项目需求文档中的峰值电流/效率/热设计门禁
- EVT 台架分流电阻与示波器实测

首版 boost 可以按保守峰值冻结，但 PCB 必须保留：
- 电流测量分流/测试点
- 足够输入输出电容位置
- EN 与电源良好信号测试点
- 电感、二极管/同步管和 IC 的热铜区

---

## E. Wi-Fi / Bluetooth 天线

无线芯片在 CM4 模块上。载板阶段需要的主要文件是：

- CM4 Placement Map
- CM4 2D DXF
- CM4 3D STEP
- 最终选用天线的厂商 datasheet / keep-out drawing

如果使用 CM4 的外接天线接口，载板通常无需自行画 2.4/5 GHz RF 走线，但仍要在 3D 装配里避开：
- 电池
- 金属铰链与螺丝
- 大面积铜和屏蔽罩
- 扬声器磁体
- 人头侧的高损耗材料

---

## 最小文件门禁

在允许切换到 IMX415 原理图与 PCB Layout 前，应至少保存以下文件到仓库：

- Radxa Camera 4K 官方页面或 pinout 导出
- Camera 4K Product Brief
- IMX415 Datasheet
- CM4 Schematic V1.20
- CM4 Pinout V1.20
- CM4 Placement Map V1.20
- CM4 2D DXF V1.20
- CM4 3D STEP V1.20
- DF40C Plug 与 Receptacle 的 2D drawing + STEP
- IMX415 CM4 Device Tree/driver 验证记录

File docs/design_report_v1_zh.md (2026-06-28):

# AI 运动眼镜载板 V1 — 设计报告（中文版）

- **项目**：ai_glasses_carrier_v1
- **版本**：v1.0-draft
- **核心模组**：Radxa CM4（RK3576）
- **板卡尺寸**：70.0 × 55.0 mm，6 层
- **生成日期**：2026-06-28
- **元件总数**：102（P0 必需 81 项，P1 建议 21 项）

> ⚠️ **重要声明**：本报告由脚本依据 `scripts/carrier_bom.py` 自动生成。其中的元件型号与数值均为 **EVT 阶段工程候选**，不是冻结 BOM。所有 CM4 引脚号、所有高速/射频/电源/电池相关器件，必须人工对照 **Radxa CM4 Schematic V1.20** 与各芯片 datasheet 核对后才能投板。（需求文档 1.1 节：AI 输出仅作辅助。）

---

## 1. 方案概述

本载板是 AI 运动眼镜的功能验证板（EVT），承载 Radxa CM4（RK3576）模组，通过三个 100-pin 板对板（B2B）连接器与模组对接。功能划分：

- **P0（必需）**：摄像头 MIPI-CSI（Radxa Camera 4K / IMX415 31-pin + CM4 CSI3 4-lane；J2 schematic 电气已锁，实物/FPC 路径项转入 `DEFERRED_TO_PRE_LAYOUT`）、2× PDM 数字麦克风、I2S/SAI Class-D 音频输出、USB-C（仅 USB2 + 5V 取电）、CM4 板载 Wi-Fi6/BT5.4、**GNSS/GPS（UART 外接模块）**、调试/恢复接口。
- **P1（建议）**：1S 锂电 + 充电 + 电量计、6 轴 IMU、振动马达。

> 🔋 **续航目标**：当前 1 小时仅为验证级；最终版本目标 **>3–4 小时**。这要求在 Phase 0 完成功率预算（Idle / 摄像头 / 摄像头+AI / +H.265 / +Wi-Fi / 满载），据实测峰值与平均功耗反推电池容量与 boost（TPS61022）选型——本载板已预留 0Ω 分流位（R3）用于电流测量。

## 2. 元件清单（BOM）

被动元件（电阻 / 电容 / 电感）均已给出具体数值；IC / 连接器给出候选型号。

### CM4 模块 / B2B 连接器

| 位号 | 型号 / 数值 | 说明 | 优先级 |
| --- | --- | --- | --- |
| J31 | DF40C-100DS-0.4V(51) | CM4 J3A (low-speed): power, debug/GNSS UART, I2C, control GPIO — KiCad refdes J31 represents Radxa CM4 connector J3A. Carrier-side receptacle; pins verified vs CM4 V1.20. GPIO bank @1.8V (VREF=P78). | P0 |
| J32 | DF40C-100DS-0.4V(51) | CM4 J3B (high-speed): MIPI-CSI3 4-lane camera, USB2-OTG0, PDM1 mics — KiCad refdes J32 represents Radxa CM4 connector J3B. MIPI CSI3 100Ω diff, USB 90Ω diff. Pins verified vs CM4 V1.20. | P0 |
| J1 | DF40C-100DS-0.4V(51) | CM4 J1 (I/O): SAI1 audio, CSI3 camera MCLK, speaker enable — SAI1 audio out + CAM_CLK2_OUT_M0 for Radxa Camera 4K. Pins verified vs CM4 V1.20. Radxa Camera 4K 31-pin FPC has active-low RESET but no PWDN pin. SAI1_MCLK is unused for MAX98357A and marked no-connect at the CM4 B2B. | P0 |

### 摄像头 Camera (P0)

| 位号 | 型号 / 数值 | 说明 | 优先级 |
| --- | --- | --- | --- |
| J2 | FH35C-31S-0.3SHW(50) | Camera FPC — Radxa Camera 4K / Sony IMX415-AAQR-C, 31-pin 0.3mm, 4-lane MIPI — SCHEMATIC_ELECTRICAL_LOCKED for Radxa Camera 4K using Radxa AC006 31P 0.3mm opposite-side FPC. Pad 1 = GND. J2 pins 1-31, CSI3 4-lane, P/N, I2C/MCLK/RESET, voltage domains, power and NC are checked by scripts/audit_csi3_camera.py. DEFERRED_TO_PRE_LAYOUT: AC006 physical validation, FPC contact side, insertion direction, Pin 1 physical check, 1:1 print, coupon test, and FPC bend/enclosure path. Pinout source: CM4_IMX415_design_files/Radxa_Camera_4K_31pin_pinout.csv. | P0 |
| U2 | TPD4E05U06 | MIPI-CSI low-capacitance ESD array for CSI3 clock + data lanes 0/1 (<0.4pF/line) | P0 |
| U16 | TPD4E05U06 | MIPI-CSI low-capacitance ESD array for CSI3 data lanes 2/3 (<0.4pF/line) | P0 |
| U3 | LP5907-3.3 (low-noise LDO) | Camera 3.3V low-noise supply for Radxa Camera 4K, EN-gated | P0 |
| R7 | 2.2k | Camera I2C SCL pull-up to +1V8 (cam OVDD=1.8V confirmed) | P0 |
| R8 | 2.2k | Camera I2C SDA pull-up to +1V8 (cam OVDD=1.8V confirmed) | P0 |
| C8 | 10µF | Camera +3V3 bulk decoupling | P0 |
| C9 | 1µF | Camera +3V3 decoupling | P0 |
| C10 | 100nF | Camera +3V3 HF decoupling | P0 |
| C29 | 10µF | Camera +5V bulk decoupling for Radxa Camera 4K | P0 |
| C30 | 100nF | Camera +5V HF decoupling for Radxa Camera 4K | P0 |

### 音频 Audio (P0)

| 位号 | 型号 / 数值 | 说明 | 优先级 |
| --- | --- | --- | --- |
| MK1 | SPH0641LU4H-1 | PDM MEMS mic (L, SEL=GND) | P0 |
| MK2 | SPH0641LU4H-1 | PDM MEMS mic (R, SEL=VDD) | P0 |
| U4 | MAX98357AETE+T | Class-D I2S/SAI mono amp (TQFN-16, no MCLK) — GAIN=GND → low gain (3-6dB) for 8Ω/1W spkr; SW volume-limit at bring-up. | P0 |
| FB1 | Ferrite 600Ω@100MHz | Class-D speaker EMI bead (OUT+) | P0 |
| FB2 | Ferrite 600Ω@100MHz | Class-D speaker EMI bead (OUT-) | P0 |
| C23 | 1nF | Class-D EMI cap (OUT+ to GND) | P0 |
| C24 | 1nF | Class-D EMI cap (OUT- to GND) | P0 |
| J3 | JST-SH 2p (spkr) | Speaker connector (post-EMI); 2 wire-leads — Speaker = Ole Wolff OWS-091630W50A-8 (8Ω 1W, 16×9×3mm, LCSC C5840086), wire-leads. | P0 |
| C13 | 100nF | Amp VDD decoupling | P0 |

### USB-C (P0)

| 位号 | 型号 / 数值 | 说明 | 优先级 |
| --- | --- | --- | --- |
| J4 | GCT USB4085 (USB2) | USB-C receptacle (USB2 + 5V sink) | P0 |
| U5 | TPD2E009 | USB2 D+/D- ESD clamp | P0 |
| R1 | 5.1k | USB-C CC1 pull-down (Sink role) | P0 |
| R2 | 5.1k | USB-C CC2 pull-down (Sink role) | P0 |
| D3 | SMAJ5.0A (TVS) | USB VBUS ESD/TVS clamp (5V standoff) | P0 |
| U15 | TPS25940 (e-fuse, opt) | VBUS e-fuse: OVP/OCP/reverse-block (DNP-able; bypass via R3 if unused) | P0 |
| R3 | 0R / shunt | VBUS_PROT→5V series 0R/shunt (current log) | P0 |
| C11 | 1µF | VBUS input cap | P0 |

### 电源 Power (P0)

| 位号 | 型号 / 数值 | 说明 | 优先级 |
| --- | --- | --- | --- |
| U12 | TLV75733 (LDO) | 3.3V rail regulator | P0 |
| U13 | TLV75718 (LDO) | 1.8V VCCIO rail regulator | P0 |
| C1 | 10µF | +5V bulk decoupling | P0 |
| C2 | 100nF | +5V HF decoupling | P0 |
| C3 | 10µF | +3V3 bulk decoupling | P0 |
| C4 | 100nF | +3V3 HF decoupling | P0 |
| C5 | 10µF | +1V8 bulk decoupling | P0 |
| C6 | 100nF | +1V8 HF decoupling | P0 |
| C21 | 100nF | LDO U12 +3V3 output decoupling | P0 |
| C22 | 100nF | LDO U13 +1V8 output decoupling | P0 |

### 电池系统 Battery (P1)

| 位号 | 型号 / 数值 | 说明 | 优先级 |
| --- | --- | --- | --- |
| U6 | TPS61022 (Boost) | 1S Li-Po → 5V boost converter | P1 |
| R20 | 100k | Boost EN pull-up to +VBAT; default boost enabled for bench bring-up | P1 |
| L1 | 4.7µH | Boost inductor | P1 |
| U7 | BQ25180 | 1S Li-Po charger w/ power-path (I2C) | P1 |
| U8 | BQ29700 | Single-cell battery protection (OVP/UVP/OCP) | P1 |
| U9 | MAX17048 | I2C fuel gauge (SOC, low-batt IRQ) | P1 |
| J5 | JST-PH 3p | Battery connector (BAT+/BAT-/NTC) — V1 BENCH cell = 1S 103450 ~2000mAh w/ PCM (~2.5h @3W). Glasses form = 2-3× 35×18×4mm (~500-750mAh, ~30-50min @3W → needs AI duty-cycling). ASSEMBLY: if cell has NO NTC, populate R11 as fixed divider to a valid temp (or disable BQ25180 TS) — else charger faults. Measure current via R3 shunt. | P1 |
| C7 | 22µF | +VBAT bulk decoupling | P1 |
| R11 | 10k | Battery NTC bias (placeholder) | P1 |
| R12 | 2.2k | Charger/Fuel I2C6 SCL pull-up to +1V8 | P1 |
| R13 | 2.2k | Charger/Fuel I2C6 SDA pull-up to +1V8 | P1 |
| C17 | 100nF | Charger U7 VBUS decoupling | P1 |
| C18 | 100nF | Fuel gauge U9 VDD decoupling | P1 |
| C19 | 100nF | Boost U6 VIN decoupling | P1 |

### 传感器 IMU/Haptic (P1)

| 位号 | 型号 / 数值 | 说明 | 优先级 |
| --- | --- | --- | --- |
| U10 | ICM-42688-P | 6-axis IMU (accel+gyro, I2C) | P1 |
| R9 | 2.2k | IMU I2C SCL pull-up to +1V8 | P1 |
| R10 | 2.2k | IMU I2C SDA pull-up to +1V8 | P1 |
| U11 | DRV2605L | LRA/ERM haptic driver | P1 |
| J6 | JST-SH 2p | Vibration motor connector | P1 |
| C16 | 100nF | IMU U10 VDD decoupling | P1 |
| C20 | 100nF | Haptic U11 VDD decoupling | P1 |

### GNSS / 定位 (P0)

| 位号 | 型号 / 数值 | 说明 | 优先级 |
| --- | --- | --- | --- |
| U14 | MAX-M10S-00B-01 | u-blox GNSS (GPS/GLO/GAL/BDS), UART, VIO=1.8V — VCC=3.3V, V_IO=1.8V (matches CM4 UART7 @1.8V), 50Ω RF, U.FL external active antenna. | P0 |
| C27 | DC-block (series,tune) | GNSS RF series match / DC block | P0 |
| C25 | π shunt (DNP,tune) | GNSS π-match shunt, module side (DNP) | P0 |
| C26 | π shunt (DNP,tune) | GNSS π-match shunt, antenna side (DNP) | P0 |
| L2 | RF choke (active-ant) | Bias-tee choke (DNP if passive antenna) | P0 |
| R17 | 10Ω (active-ant) | Active-antenna bias feed from +3V3 (DNP if passive) | P0 |
| C28 | 100nF (active-ant) | Antenna bias decoupling (DNP if passive) | P0 |
| J8 | U.FL / IPEX | GNSS antenna connector (50Ω; external active/passive) | P0 |
| C14 | 100nF | GNSS VCC decoupling | P0 |
| C15 | 10µF | GNSS VCC bulk decoupling | P0 |
| D4 | ESD low-cap RF 0.3pF | GNSS antenna ESD clamp | P0 |

### 指示 / 调试 Debug

| 位号 | 型号 / 数值 | 说明 | 优先级 |
| --- | --- | --- | --- |
| D1 | LED Green | Power LED (active-low GPIO sink) | P0 |
| R4 | 1k | Power LED current limit | P0 |
| D2 | LED Blue | Status LED (active-low GPIO sink) | P0 |
| R5 | 1k | Status LED current limit | P0 |
| J7 | Header 1x4 2.54mm | UART debug header (TX/RX/GND/VREF) | P0 |

### 测试点 Test Points

| 位号 | 型号 / 数值 | 说明 | 优先级 |
| --- | --- | --- | --- |
| TP1 | TestPoint 1.0mm | Test point: VBAT | P0 |
| TP2 | TestPoint 1.0mm | Test point: 5V | P0 |
| TP3 | TestPoint 1.0mm | Test point: 3V3 | P0 |
| TP4 | TestPoint 1.0mm | Test point: 1V8 | P0 |
| TP5 | TestPoint 1.0mm | Test point: GND | P0 |
| TP6 | TestPoint 1.0mm | Test point: UART_TX | P0 |
| TP7 | TestPoint 1.0mm | Test point: UART_RX | P0 |
| TP8 | TestPoint 1.0mm | Test point: CAM_SCL | P0 |
| TP9 | TestPoint 1.0mm | Test point: CAM_SDA | P0 |
| TP10 | TestPoint 1.0mm | Test point: IMU_SCL | P0 |
| TP11 | TestPoint 1.0mm | Test point: IMU_SDA | P0 |
| TP12 | TestPoint 1.0mm | Test point: FUEL_SCL | P0 |
| TP13 | TestPoint 1.0mm | Test point: FUEL_SDA | P0 |
| TP14 | TestPoint 1.0mm | Test point: RESET | P0 |
| TP15 | TestPoint 1.0mm | Test point: RECOVERY | P0 |
| TP16 | TestPoint 1.0mm | Test point: CAM_EN | P0 |

### 按键 Buttons

| 位号 | 型号 / 数值 | 说明 | 优先级 |
| --- | --- | --- | --- |
| SW1 | Tact SW SMD | RECOVERY / maskrom button (to GND) | P0 |
| SW2 | Tact SW SMD | RESET button (to GND) | P0 |
| SW3 | Tact SW SMD | POWER button (to GND) | P0 |
| R14 | 10k | RECOVERY pull-up to +1V8 | P0 |
| R15 | 10k | RESET pull-up to +1V8 | P0 |
| R16 | 10k | POWER_KEY pull-up to +1V8 | P0 |
| R18 | 100k | WL_nDIS pull-up to +1V8; default Wi-Fi enabled | P0 |
| R19 | 100k | BT_nDIS pull-up to +1V8; default Bluetooth enabled | P0 |

## 3. 关键被动元件数值说明

| 类别 | 数值 | 用途 | 备注 |
| --- | --- | --- | --- |
| USB-C CC 下拉 | 5.1kΩ ×2 | 配置为 Sink（取电）角色 | USB-C 规范固定值 |
| VBUS 串联 | 0Ω / 分流电阻 | 5V 取电 + 电流测量预留 | EVT 用 0Ω，量产换分流 |
| I2C 上拉 | 2.2kΩ | 摄像头 / IMU I2C 上拉 | 视总线电容微调 1–4.7k |
| LED 限流 | 1kΩ | 电源 / 状态指示灯 | 视 LED 亮度调整 |
| 电源去耦 | 10µF + 100nF | 各电源轨就近去耦 | 每颗 IC 电源脚补 100nF |
| VBAT 储能 | 22µF | 电池轨大电流缓冲 | 配合 boost 输入 |
| Boost 电感 | 4.7µH | TPS61022 升压电感 | 按峰值电流与 datasheet 选型 |
| 摄像头去耦 | 100nF ×3 | 2.8/1.8/1.2V 每轨 | 配合 LDO datasheet |

> 被动件 pre-layout freeze 已建立：`config/passive_bom_freeze.yaml`。审计输出见 `docs/passive_bom_freeze_2026-06-28.md` 和 `generated/reports/passive_bom_freeze.csv`。`LOCKED_CANDIDATE` 为已给出候选 MPN/LCSC；`PROCUREMENT_VERIFY` 需采购前确认库存/后缀；`TUNE_OR_EVT_SELECT` 为 RF 调谐或台架实测后定值。

## 4. 引脚冻结门禁（需求文档 3.3 节）

- **当前状态**：`REVIEW`（引脚已填，等待采购冻结）。
- ✅ **引脚已全部填写并核对**：全部 56 行已对照官方 `radxa_cm4_pinout_v1.20.xlsx` + Schematic V1.20 填入真实 CM4 引脚号，`source_verified: true`，无 `TBD` 引脚、无单脚冲突。
- 工作主表：`scripts/cm4_pinmap.py`；交付件：`generated/reports/cm4_v1_pin_assignment.xlsx`。
- ⛔ full-layout 门禁仍 **阻塞** 的原因不再是引脚，也不是相机 schematic 电气，而是 8.3 节的 **pre-layout/机械类 TBD**（J2 实物/FPC 路径、B2B 装配核对、载板外形/三连接器 XY 等）。这些解决并 `status: FROZEN` 后方可布线。
- 关键工程决定：`GPIO_VREF`(J3A P78) 接 **1.8V** → J3A GPIO 全部 1.8V；摄像头目标为 **Radxa Camera 4K / IMX415 + CSI3 4-lane**，J2 使用 **Hirose FH35C-31S-0.3SHW(50)** + Radxa **AC006**；PDM1 麦克风、SAI1 音频、UART0 调试、UART7 GNSS；摄像头/IMU/电量计分别用 **I2C0 / I2C8 / I2C6** 三条独立总线。

**待解决的 TBD 项（8.3 节，共 3 项）：**

| 项目 | 需确认内容 | 状态 |
| --- | --- | --- |
| `CM4_SKU` | CONFIRMED RM126-D4E32J0R35W28: RK3576 / 4GB LPDDR4X / 32GB eMMC / Wi-Fi6+BT5.x. Antenna form tracked under ANTENNA. | ✅ 已解决 |
| `CAMERA_ELECTRICAL_PINOUT` | RESOLVED: camera module is Radxa Camera 4K / Sony IMX415-AAQR-C; 31-pin FPC pinout captured in CM4_IMX415_design_files/Radxa_Camera_4K_31pin_pinout.csv and cross-referenced in docs/p0_p1_decisions_2026-06-28.md. | ✅ 已解决 |
| `CAMERA_CONNECTOR_MPN` | RESOLVED: carrier J2 connector is Hirose FH35C-31S-0.3SHW(50), LCSC C424662. Footprint has been generated from the Hirose 2D drawing. | ✅ 已解决 |
| `CAMERA_CABLE` | RESOLVED: use Radxa AC006, 31P 0.3mm to 31P 0.3mm, opposite-side FPC. Do not use AC008; AC008 is 31P to 15P. | ✅ 已解决 |
| `CAMERA_SCHEMATIC_GATE` | RESOLVED for schematic stage: J2 pins 1-31, CSI3 4-lane mapping, P/N polarity, I2C/MCLK/RESET, voltage domains, power pins and NC pins are checked by scripts/audit_csi3_camera.py. RESET is active-low on project net CAM_RST_n; no PWDN pin is present in the Radxa Camera 4K 31-pin pinout. | ✅ 已解决 |
| `CAMERA_KICAD_IMPLEMENTATION` | PARTIAL: schematic source now uses 31-pin FH35C/Radxa Cam4K pinout on CM4 CSI3 4-lane, and the FH35C footprint has been regenerated from the Hirose 2D drawing. DEFERRED_TO_PRE_LAYOUT: AC006 physical validation, FPC contact side, FPC insertion direction, J2 Pin 1 physical check, 1:1 print, coupon test, and FPC bend/enclosure path. Official CM4 IO overlay radxa-cm4-io-radxa-camera-4k.dtbo is confirmed. Bring-up logs (dmesg/media/v4l2) remain open for EVT. | ❌ 未解决 |
| `AUDIO_PARTS` | CONFIRMED: 2×SPH0641LU4H-1 mic, MAX98357AETE+T (C910544) amp, Ole Wolff OWS-091630W50A-8 8Ω/1W (C5840086) speaker | ✅ 已解决 |
| `GNSS_MODULE` | CONFIRMED u-blox MAX-M10S-00B-01: UART, VCC=3.3V/VIO=1.8V, 50Ω U.FL, external active antenna (π-match + bias-tee, DNP for passive) | ✅ 已解决 |
| `BATTERY` | Reverse-calc: 1S 2-3×(35×18×4mm ~250mAh)=500-750mAh/1.85-2.8Wh. V1 bench use ~1.5-2Ah. >3-4h target needs AI duty-cycling (system-power issue, see report) | ✅ 已解决 |
| `POWER_5V` | CONSERVATIVE FREEZE: keep TPS61022-class 1S->5V boost and design +5V_SYS for >=4A bench/boost margin. R3 remains the bring-up shunt/0R measurement point; final peak/thermal validation is deferred to bench testing. | ✅ 已解决 |
| `ANTENNA` | CONSERVATIVE FREEZE: Wi-Fi/BT stays on the CM4 module/U.FL path; carrier does not add 2.4/5GHz RF routing. Layout must reserve the CM4 antenna keep-out and keep battery, metal hinge/screws, speaker magnet, and copper away from the antenna zone. | ✅ 已解决 |
| `BOARD_OUTLINE` | SOURCE GEOMETRY RESOLVED: CM4 module outline = 40.02x54.98mm from official DXF; CM4/IO Board DXF, STEP, placement map and dimensions drawing are the mechanical inputs. OPEN: project must freeze board length/width/radius, USB-C/camera/battery/debug exit direction, mounting holes, and battery-vs-CM4 position. | ❌ 未解决 |
| `B2B_CONNECTOR` | SOURCE FILES RESOLVED: carrier receptacle DF40C-100DS-0.4V(51), module plug DF40C-100DP-0.4V(51), 1.5mm mated height. OPEN: build 2-layer connector-only fit-check board and verify all three connectors press in together with no module lift/skew. | ❌ 未解决 |
| `PINMUX` | PDM/SAI/I2C/UART/GPIO conflict map + Device Tree | ✅ 已解决 |

## 5. 五项当前收敛决定（2026-06-28）

| 优先级 | 项目 | 当前决定 | 状态 |
| --- | --- | --- | --- |
| P0 | 相机实现 | 目标锁定 Radxa Camera 4K / IMX415-AAQR-C；J2 pins 1-31、CSI3 4-lane、P/N、I2C/MCLK/RESET、电压域、供电和 NC 已由 `scripts/audit_csi3_camera.py` 审计 | 🟢 schematic 电气已锁；实体/FPC 路径 `DEFERRED_TO_PRE_LAYOUT` |
| P0 | B2B Fit-Check | 做 2 层只焊三只 DF40C-100DS-0.4V(51) 的验证板，用官方 CM4 STEP + DXF 核对 1.5mm 压合、Pin1、XY、旋转和净空 | 🔴 阻塞：缺 STEP 装配核对 |
| P0 | 载板外形 | CM4 官方 DXF 外形 40.02 × 54.98mm；当前 70 × 55mm 仅作 EVT 草案，三连接器 XY 必须在 KiCad 中导入官方 DXF/STEP 对齐 | 🔴 阻塞：不可从 PDF/文本猜 XY |
| P1 | POWER_5V | 保守冻结 TPS61022-class 1S→5V，+5V_SYS 按 >=4A 裕量，R3 保留 0R/分流实测位 | 🟡 可先冻结，bring-up 实测收尾 |
| P1 | Wi-Fi/BT 天线 | 保守冻结为 CM4 模块板载/U.FL 天线路径，载板不新增 2.4/5GHz RF 走线 | 🟡 可先冻结，layout 阶段执行净空 |

## 6. 下一步行动

1. **相机 J2 schematic gate**：J2 schematic 已切换到 Radxa Camera 4K 31-pin + CM4 CSI3 4-lane；`scripts/audit_csi3_camera.py` 逐脚检查 J2 pin 1-31、MIPI lane、P/N、I2C/MCLK/RESET、电压域、供电和 NC。AC006 实物验证、FPC 接触面、插入方向、Pin1 实体核对、1:1 打印、Coupon 测试、FPC 弯折和外壳路径均为 `DEFERRED_TO_PRE_LAYOUT`。
2. **B2B 连接器（已基本确认，待机械冻结）**：载板侧 3× **Hirose DF40C-100DS-0.4V(51)**（CL No. CL0684-4033-4-51，0.4mm pitch，100-pin，插座），与 Radxa CM4 模块侧 **DF40C-100DP-0.4V(51)** 配对，标称 PCB 板间距 **1.5mm**（厂商 mated height，非两件本体高度相加）。冻结条件：官方 CM4 STEP 装配 + 2 层 Fit-Check 验证板确认三连接器坐标/方向/模块净空/1.5mm 间距。三连接器须作为整体放置并锁定，Pin1 与朝向明确标注，不可单独拖动。
3. **载板外形 / 连接器 XY**：保持 70 × 55mm 作为 EVT 草案；进入 layout 前，在 KiCad/机械 CAD 中导入官方 CM4 DXF/STEP 对齐三连接器，不用 PDF/图片/text-mining 当坐标来源。
4. **POWER_5V 与 Wi-Fi/BT 天线**：按保守决策先冻结；R3 台架实测和 antenna keep-out 在 layout/bring-up 收尾。
5. **冻结引脚表**：以上完成后将门禁置为 `FROZEN`，运行 `scripts/check_pin_freeze.py` 通过，才能进入 PCB 布局。

## 7. 工作流阶段进度（对照 10-Phase 工作流）

| 阶段 | 内容 | 状态 |
| --- | --- | --- |
| Phase 0 | 需求冻结 / 系统框图 / 接口清单 | 🟡 进行中（P1 电源/天线已有保守冻结） |
| Phase 1 | 资料 & Pin Assignment（B2B 引脚 / 电压域 / Pinmux） | 🟡 相机 schematic 电气已锁；pre-layout 仍待 J2 实物/FPC、B2B/外形机械门禁 |
| Phase 2 | 器件选型（MPN / datasheet / 采购） | 🟡 相机目标已锁 IMX415/Radxa Cam4K，J2/AC006 已记录 |
| Phase 3 | 原理图设计（分页 / ERC / BOM） | 🟢 已出元件级原理图草稿（本文件） |
| Phase 4–7 | Floorplan / 布线 / 审查 / 生产文件 | ⚪ 未开始（受 Phase 1 门禁阻塞） |
| Phase 8–10 | Bring-up / Linux 驱动 / 系统测试 | ⚪ 未开始 |

> 当前 schematic 阶段，相机 31-pin J2 电气已经闭合；下一阶段关键阻塞点是 J2 `DEFERRED_TO_PRE_LAYOUT` 实体验证、B2B 2 层 fit-check、载板外形 + 三连接器 XY/STEP 装配。POWER_5V 和 Wi-Fi/BT 天线按保守决策可先冻结，后续 layout/bring-up 收尾。

---

## 附：原理图 / PCB 文件

- 原理图：`hardware/ai_glasses_carrier.kicad_sch`（已含上述全部元件符号 + 网络标签，可在 KiCad 中直接打开查看）
- PCB：`hardware/ai_glasses_carrier.kicad_pcb`（**仅** 板框 + 6 层叠层 + 4 个 M2 安装孔 + 55 个网络；按门禁规则，元件封装在引脚冻结前 **不** 摆放，故 PCB 上目前看不到器件——这是预期行为）
- 生成脚本：`scripts/generate_carrier_board.py`、`scripts/carrier_bom.py`（BOM 唯一来源）、`scripts/generate_report.py`

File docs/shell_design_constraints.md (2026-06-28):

# 外壳设计约束摘要 (AR 运动眼镜) — chip-down 阶段参考

来源：`shell_design_brief.pdf`（工程师机械组，2026-06-26）。
**重要：这份 brief 描述的是最终 chip-down 眼镜，不是当前 CM4 EVT 载板。** 见下"关系说明"。

## ⚠ 关系说明：外壳 brief vs 当前 CM4 载板
- brief 的右镜腿主控是 **自设计 RK3576 chip-down PCB，36×28mm**，塞进 **14×8mm 镜腿截面**。
- 当前 V1 是 **Radxa CM4 模块载板**，仅 CM4 模块本体就 **40×55mm** → **物理上装不进镜腿**。
- 这是**预期的**：CM4 载板 = 台架功能/软件验证（需求 §7.1 不要求塞镜腿）；外壳 brief = chip-down 最终产品（需求 §7.2）。**两块是不同的板。** 当前载板验证功能，chip-down 阶段再按本约束缩小。

## 整机目标
| 项 | 目标 |
|---|---|
| 整机重量 | ≤ 90g（对标 Ray-Ban Meta 49g / 闪极 48g；理想 <50g）|
| 佩戴 | 适配普通眼镜，镜框不过厚，鼻托可调 |
| 防护 | IPX4（运动/防汗）|
| 散热 | 被动，镜腿贴金属支架导热，无风扇，外壳表面 ≤40°C |
| 充电/接口 | 镜腿末端 磁吸 Pogo Pin 或 USB-C |
| 镜腿 | 138–142mm 长，截面 **14×8mm**（或 16×8）|
| 镜框宽 | 143–147mm |

## 结构分区与重量平衡
- **前框**：摄像头、麦克风×2、(显示模块, 待定)、鼻托
- **左镜腿**：电池×2、扬声器  ← 平衡右侧主控重量
- **右镜腿**：主控、电池、扬声器、麦克风
- FPC 过铰链连接左右

## 关键器件尺寸（chip-down 目标）
| 器件 | 尺寸 mm | 厚 | 备注 |
|---|---|---|---|
| 摄像头模组 | 25×25 (参考 IMX415) | 5–8 | 我们的 SC3336(B) 实测 25×24，含镜头 23.95 高 → **EVT 模块偏大，glasses 需薄型 FFC 相机** |
| MEMS 麦克风 ×2 | 3×3 | 2 | 前框两侧，FPC 引出 |
| 主控 PCB | **36×28** | 1.0 | RK3576 **chip-down**；LPDDR5 须在 SoC 15mm 内 |
| 电池 ×2(左)+×1(右) | 35×18 | 4 | 2 颗在左平衡 |
| 扬声器 | 9×20 | 3 | DLS0920A 或贴片 |
| 充电口 | 10×5 | — | Pogo Pin / USB-C |
| 铰链 FPC | 宽 6–10 | 0.1–0.18 | 弯折半径 ≥2mm，寿命 >5万次 |

## 开口/接口位置
充电口=右镜腿末端 10×3；摄像头窗口=前框中央 8×8；麦克风孔=前框/镜腿 Ø1mm×3–4；扬声器出声孔；触摸区=右镜腿外侧。

## 散热
RK3576 满载 ~600mW（峰值 3–10W 瞬态）→ 导热硅胶 → 金属支架 → 镜腿外壳 → 环境；表面 ≤40°C。SoC 区 PCB ~25×20mm 留导热面。

## 对当前 CM4 载板（EVT）有用的 carry-forward
1. **相机 = SC3336(B)**：2-lane / 3.3V / 20-pin（已写入 BOM）
2. 连接器朝向：相机 FPC 朝前框、Wi-Fi/GNSS 天线远离金属铰链、充电/USB-C 在板边
3. 麦克风 2× MEMS 3×3mm（FPC）、扬声器 DLS0920A 9×20mm
4. 电池：~35×18×4mm ×2–3 → 反推容量（支撑 >3–4h 功率预算）
5. 显示模块（Micro-OLED）出现在外壳，但 **V1 载板电子学不含显示**（需求排除 AR 显示）

## ID 待确认（brief §7）
镜腿截面 14×8 vs 16×8；散热路径金属件；铰链 FPC 走线；电池布局/平衡；充电 Pogo vs USB-C；重量分布。

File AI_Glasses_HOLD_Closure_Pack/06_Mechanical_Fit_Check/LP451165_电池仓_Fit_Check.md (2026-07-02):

# LP451165 电池仓 Fit-check

## 已知名义尺寸

- 电芯：4.5 x 11 x 65 mm。
- Shell Brief目标镜腿外宽约14 mm、外高约8 mm。
- 最终值必须以供应商机械图中的最大尺寸和循环膨胀值为准。

## 一阶几何核算

若左右壳壁各0.8 mm：

- 14 mm外宽 -> 12.4 mm内部净宽。
- 11 mm名义电芯 -> 仅剩1.4 mm总余量，即每侧0.7 mm。

若上下壳壁各0.8 mm：

- 8 mm外高 -> 6.4 mm内部净高。
- 4.5 mm名义厚度 -> 剩1.9 mm用于绝缘、胶、膨胀和装配。

宽度方向比厚度方向更危险；FPC、线束、卡扣和壳体拔模会进一步吃掉余量。

## 当前建议的占位包络

在未取得正式膨胀数据前，CAD中至少使用：

- 宽：12.5–13.0 mm。
- 厚：5.3–5.8 mm。
- 长：68–72 mm。

本文件夹提供两个 STL：

- `LP451165_nominal_cell_65x11x4p5mm.stl`：仅名义裸电芯。
- `LP451165_clearance_envelope_70x12p8x5p6mm.stl`：建议早期结构占位。

## 必须做的装配样件

1. 3D打印 clearance envelope，不放电芯。
2. 假电芯 + 真实FPC + 真实线束 + NTC + 保险器件。
3. 真实电芯不通电装配。
4. 真实电芯低功率运行。
5. 最终高负载、充电和热循环测试。

## 检查项

- 镜腿折叠是否挤压电池/拉扯极耳。
- 电芯是否接触螺丝、PCB锐边或外壳筋位。
- 电芯与SoC/Boost/PMIC是否纵向错开。
- 65 mm电芯是否侵占扬声器声腔和天线净空。
- 佩戴时是否顶太阳穴。
- 壳体打开/维修流程是否损伤电芯。
- 膨胀后是否仍无硬压。

## HOLD 关闭门槛

- 供应商最大机械包络和膨胀数据已录入CAD。
- 真实电芯、FPC、线束和壳体装配通过。
- 铰链寿命测试后线束和极耳无损伤。
- 充电与高负载温升下壳体不压电芯。
- 电池段、扬声器和天线的空间冲突已清零。

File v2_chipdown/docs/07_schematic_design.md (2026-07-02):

# 07 — Pre-Layout System Schematic (design record)

This is the design record for the V2 chip-down **pre-PCB-layout** schematic. It
captures the three decision sets — **Phase-1 AON selection**, **AON power
budget**, **Phase-3 power tree** — as an actual, ERC-clean, netlist-verified
KiCad schematic, and states plainly what is intentionally **not** done yet
because it belongs to PCB layout.

## What was built (and how it is verified)

| Artifact | Path |
|---|---|
| Component + net master (source of truth) | `scripts/chipdown_bom.py` |
| Schematic generator | `scripts/generate_chipdown_sch.py` |
| KiCad schematic (one system sheet) | `hardware/ai_glasses_v2_chipdown.kicad_sch` |
| Symbol library / project / lib tables | `hardware/AI_Glasses_V2.kicad_sym`, `.kicad_pro`, `sym-lib-table`, `fp-lib-table` |
| ERC report | `reports/erc.report.txt` |
| Netlist (KiCad) | `reports/ai_glasses_v2.net` |
| BOM (fields: Reference, Value, BOM_ID, Board, Assembly, Priority, Package, Gate) | `reports/ai_glasses_v2_bom.csv` |
| Schematic PDF / SVG | `reports/output/ai_glasses_v2_chipdown_schematic.pdf`, `.svg` |

**Regenerate:**
```bash
.venv/bin/python v2_chipdown/scripts/chipdown_bom.py          # validate master
.venv/bin/python v2_chipdown/scripts/generate_chipdown_sch.py # emit schematic
KCLI=/Applications/KiCad/KiCad.app/Contents/MacOS/kicad-cli
"$KCLI" sch erc --severity-all --format report -o v2_chipdown/reports/erc.report.txt \
    v2_chipdown/hardware/ai_glasses_v2_chipdown.kicad_sch
```

**Status:** 96 components (58 Fit / 12 HOLD / 19 DNP / 7 TBD), 127 declared nets.
**ERC = 0 errors, 0 warnings, 0 violations** (KiCad 10.0.4).
The netlist was parsed back to confirm real connectivity (not just labels): e.g.
`SOC_SAFE_TO_OFF` joins RK3576 (U1) + nRF (U7) + hinge FPC (J4); `SOC_PWR_EN`
joins nRF (U7) + TPS61088 (U6) + default-off pull-down (R11); the pack path
runs cell branches through `RS2/RS3` into `BAT_P`, then `RS1` into nPM1300
`NPM_VBAT`; `VSYS→RS4→SOC_IN` feeds the SoC boost; `PDM_WAKE_CLK` joins the
wake mic (MK1) + NDP120 (U9) + front FPC (J3).

> **Honesty note.** This is a *functional-block* schematic: parts whose ball map
> / datasheet is not in hand (RK3576, RK806S, LPDDR4X, eMMC, NDP120, the custom
> IMX415 module, the Wi-Fi module) are drawn with only their architecturally
> defined interface pins. The RK806S→RK3576 rail names are the Radxa reference
> set and freeze only at G02/G03. The Footprint field is deliberately **empty** —
> footprints are a layout deliverable (see "Deferred to layout").

---

## 1. Phase-1 AON selection (frozen for EVT)

| Function | Part | Ref | Status | Why this, not the alternative |
|---|---|---|---|---|
| BLE MCU / state machine | **nRF54L15-QFN48** | U7 | Fit | vs nRF52840 (older platform) / nRF5340 (dual-core overkill — voice NN lives in the DSP). 1.5 MB NVM / 256 KB RAM headroom; QFN48 for a debuggable EVT, WLCSP shrink later. |
| AON charger/gauge/PMIC | **nPM1300** | U8 | HOLD | Integrates 1S charge + Power-Path + Fuel Gauge + 2×Buck + LDO/Load-Switch + Ship/Hibernate. Powers the **AON world only** — never the RK3576 peak path. |
| Always-on audio DSP | **NDP120** | U9 | HOLD | Ultra-low-power wake-word off RK3576. HOLD until full datasheet, rails/sequence, PDM/I²S detail, model tools, wake-word licensing, measured listening power, MOQ/lead. Bypass + DNP kept. |
| 6-axis IMU | **BMI270** | U10 | Fit | Low-power motion-interrupt wake for wearables. |

**Audio topology (no PDM-clock contention).** One dedicated **wake mic** (MK1) →
NDP120; NDP120 wakes nRF over `DSP_WAKE`. **Two array mics** (MK2/MK3) → RK3576
PDM for beamforming; **4th mic (MK4) is footprint-only/DNP** until array + wind
tests decide. nRF↔NDP120 carries `DSP_SPI_*` + `WAKE/READY/FAULT/RESET`. The
wake mic runs in the AON audio domain so Deep Off can capture without RK3576.

**Charger/gauge scope is explicit in the tree:** nPM1300 supplies nRF, NDP120,
IMU, gauge logic, part of the always-on mic domain, buttons/sensors. The RK3576
compute island has its **own** high-power path (TPS61088 → RK806S).

---

## 2. AON power budget (turn "20–50 mW" into a measurable budget)

| AON load | Design budget | Verify |
|---|--:|---|
| nRF54L15 (BLE conn + state machine) | 1–5 mW avg | measure adv / conn / notify / sleep separately |
| NDP120 + wake mic | 5–15 mW | measure real continuous listening (no datasheet typ.) |
| IMU low-power motion | <1 mW | motion-interrupt only, no continuous high ODR |
| nPM1300 self + conversion loss | <1 mW | at real load |
| Other sensors / pull-ups / leakage | 1–3 mW | incl. FPC + cross-domain IO leakage |
| BLE burst headroom | 5–10 mW | connect + TX transients |
| **AON normal average** | **10–25 mW target** | worn, normal |
| **AON design ceiling** | **50 mW** | must not be the normal average |

So **20–50 mW is the ceiling band; the real target is 10–25 mW average**, and
every mode is measured for **energy**, not just instantaneous current. On-board
verification uses shunt `RS1` (main) + `U25` (INA238) — in Deep Off the gated
islands are off, so the main path reads AON-only; the nPM1300 fuel gauge
cross-checks.

**Dev-board bring-up (before trusting the schematic):** nRF54L15 DK, nPM1300 EK
(configure via nPM PowerUP, export settings), NDP120 kit/module, real PDM mics,
BMI270 breakout, Otii Arc / Joulescope.

### Gate 1 (AON board) — must all pass
AON average ≤ 25 mW, worst ≤ 50 mW · voice/button/BLE/IMU all wake reliably ·
acceptable false-wake rate · **100** RK3576 on/off cycles with no lock-up ·
RK3576-off leakage at target · low-battery **blocks** RK3576 start · no reverse
feed into a powered-down RK3576 via GPIO.

---

## 3. Phase-3 power tree (Buck + Load-Switch, on the schematic)

```
2×LP451165 (1S2P) ─F1/F2─► BAT_P ─► nPM1300 (VBAT) ─► VSYS
                                        │  BUCK1 ─► AON_1V8   (always on: nRF IO/IMU/DSP/mics)
                                        │  BUCK2 ─► AON_3V3   (always on: nRF RF/DSP/mics)
 BATR/L ─F1/F2─RS2/RS3─► BAT_P ─RS1─► NPM_VBAT
 VSYS ─┬─[RS4]─► SOC_IN  ─► TPS61088 ─► SOC_5V ─► RK806S ─► RK3576/DDR/eMMC rails
       ├─[RS5]─► WIFI_IN ─► TPS62825 ─► WIFI_3V3 ─► TPS22917 ─► module
       ├─[RS6]─► AUDIO_IN ─► TPS22917 ─► AUDIO_PWR ─► MAX98360A
       ├────────► TPS62840 ─► CAM_1V1 ─RS7─► CAM_1V1_S
       └────────► TLV75529 ─► CAM_2V9 ─RS9─► CAM_2V9_S
 AON_1V8 ─► TPS22917 ─► CAM_1V8_SW ─RS8─► CAM_1V8_S
```

**Rules honoured:** camera/MCU/IMU/mics/radio run off 1S via Buck/Load-Switch —
**only the RK3576 island gets a boost**, and only if RK806S input truly needs
5 V (else drop the boost). Every expensive rail sits behind an nRF-controlled
load switch. AON Buck (nPM1300) is the low-Iq 24/7 dominator of Deep Off.

### Per-island regulators

| Island | Regulator | Ref | Status | Rail |
|---|---|---|---|---|
| RK3576 boost | TPS61088 (+L1) | U6/L1 | HOLD | SOC_5V |
| SoC PMIC | RK806S-5 | U2 | HOLD | CPU/GPU/NPU/LOGIC/DDR/DDRIO/1V8/3V3 |
| Camera 1.1 V | TPS62840 (+L3) | U15/L3 | Fit | CAM_1V1 |
| Camera 1.8 V | TPS22917 (from AON_1V8) | U17 | Fit | CAM_1V8_SW |
| Camera 2.9 V | TLV75529 | U16 | Fit | CAM_2V9 |
| Wi-Fi | TPS62825 (+L2) → TPS22917 | U12/L2/U13 | Fit | WIFI_3V3(_SW) |
| Audio | TPS22917 | U21 | Fit | AUDIO_PWR |

### Control lines on the schematic (nRF54L15 is master)

| Net | Direction | Purpose |
|---|---|---|
| `SOC_PWR_EN` | nRF → TPS61088 EN | power the compute island |
| `SOC_5V_PGOOD` | TPS61088 PG → nRF | boost good |
| `PMIC_PWRON` | nRF → RK806S | sequence RK3576 rails on |
| `SOC_SHUTDOWN_REQ` | RK3576 → nRF | SoC asks to power down |
| `SOC_SAFE_TO_OFF` | RK3576 → nRF | Linux synced, safe to cut |
| `SOC_ALIVE` / `SOC_FAULT` | RK3576 → nRF | liveness / fault |
| `CAM_1V1_EN`/`CAM_1V8_EN`/`CAM_2V9_EN` | nRF → regs/LS | camera island |
| `WIFI_BUCK_EN`/`WIFI_LS_EN`/`WIFI_CHIP_EN` | nRF → buck/LS/module | Wi-Fi on-demand |
| `AUDIO_LS_EN`/`AUDIO_AMP_SD` | nRF → LS/amp | audio gated + amp shutdown |
| `DSP_RESET_L`/`DSP_WAKE`/`DSP_READY`/`DSP_FAULT` | nRF ↔ NDP120 | wake handshake |

**Safe shutdown sequence (never cut Linux without warning):**
```
nRF asserts SOC_SHUTDOWN_REQ
 → Linux stops recording + sync()s the filesystem
 → RK3576 asserts SOC_SAFE_TO_OFF
 → nRF drops Wi-Fi + camera load switches
 → nRF deasserts SOC_PWR_EN (SOC_5V off)
```

### Per-island current sense (mandatory)

Series shunts feed INA238 monitors. **EVT-A:** all populated. **EVT-B /
production:** shunt pads kept (0 Ω), only the main `U25` optional, the rest DNP.

| Sense | Shunt | Value rule | INA |
|---|---|---|---|
| System / AON (Deep Off) | RS1 (BAT_P→NPM_VBAT) | 10 mΩ; production-kept sense path | U25 |
| Left cell branch | RS2 (BATL_F→BAT_P) | 10 mΩ; current-share check | U26 |
| Right cell branch | RS3 (BATR_F→BAT_P) | 10 mΩ; current-share check | U27 |
| RK3576 island | RS4 (VSYS→SOC_IN) | 5–20 mΩ (2 A×10 mΩ=20 mV; avoid boost UVLO) | U28 |
| Wi-Fi island | RS5 (VSYS→WIFI_IN) | 20–100 mΩ | U29 |
| Audio island | RS6 (VSYS→AUDIO_IN) | 20–100 mΩ | U30 |
| Camera DVDD | RS7 (CAM_1V1→CAM_1V1_S) | 100 mΩ Kelvin; DVDD ~250 mA | U31 |
| Camera IOVDD | RS8 (CAM_1V8_SW→CAM_1V8_S) | 100 mΩ Kelvin; IOVDD ~3 mA | U32 |
| Camera AVDD | RS9 (CAM_2V9→CAM_2V9_S) | 100 mΩ Kelvin; AVDD ~156 mA | U33 |

Record **peak + average + duration + energy-per-event** at each, and watch **1S
droop** at the RK3576 AI-burst peak (boost/PMIC UVLO risk).

### Passive specs locked pre-layout (V1 audit discipline)
USB-C CC1/CC2 = **5.1 kΩ 1%** (R1/R2). AON + camera + SoC-PMIC I²C pull-ups =
**2.2 kΩ 1%** (R3–R6, R9/R10) — confirm against each bus's total capacitance at
layout. High-power enables have **100 kΩ pull-downs** (R11–R20) so RK3576,
camera, Wi-Fi and audio default OFF before nRF firmware runs. Decoupling
X7R/X5R and ≥10 V-on-5 V rules apply when the manufacturing passive BOM is
expanded at G15.

---

## Deferred to PCB layout / still HOLD (intentionally NOT done)

Per the instruction to do only what precedes PCB layout, the following are **not**
in this schematic and must not be treated as done:

- **No `.kicad_pcb`** — placement, copper, diff-pair/impedance (MIPI 100 Ω, USB2
  90 Ω), stack-up, DRC. Gated behind **Gate 0 (mechanical)**: prove the two
  LP451165 cells fit L/R temples with swell/foam/FPC room, not stacked over
  RK3576/PMIC, antenna keep-out respected.
- **Phase 1.5 floorplan before routing** — create a no-route mechanical/electrical
  KiCad floorplan with board outlines, RK3576/LPDDR/RK806/eMMC/Wi-Fi/boost
  inductor/FPC connector placement envelopes, LP451165 3D/envelope blocks,
  speaker and antenna keep-outs. If it does not fit, change architecture before
  PCB layout. See [13_mechanical_electrical_floorplan.md](13_mechanical_electrical_floorplan.md).
- **No footprints assigned** (Footprint field empty; intended package in the
  `Package` field only). Real footprints are created at layout.
- **Ball-level nets** for RK3576/RK806S/LPDDR4X/eMMC/NDP120/IMX415-module/Wi-Fi
  module — start as a *delta off the Radxa reference* once G01/G02/G03/G05/G10
  documents are in hand.
- **HOLD parts stay HOLD:** NDP120 (datasheet+kit+power), Wi-Fi module (RK3576
  BSP), LP451165 + 1S2P pack (real datasheet + discharge curves + matching/NTC),
  TPS61088 (measured RK3576 peak), camera rail currents (custom IMX415 module),
  battery-bay dimensions (real cell + swell fit).
- **Manufacturing passive expansion** — the locked pre-layout pull-ups,
  pull-downs and sense shunts are present, but the full decoupling/passive MPN
  table still expands at G15.

See [08_signal_dictionary.md](08_signal_dictionary.md) for every net's signal
attributes, [09_power_domain_isolation_matrix.md](09_power_domain_isolation_matrix.md)
for reverse-feed review, [10_bom_status.md](10_bom_status.md) for Fit/HOLD/DNP/TBD,
[11_footprint_register.md](11_footprint_register.md) for package readiness and
[12_layout_entry_gate_status.md](12_layout_entry_gate_status.md) for the layout
go/no-go verdict.

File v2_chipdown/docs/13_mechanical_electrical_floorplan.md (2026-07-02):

# 13 — Phase 1.5 Mechanical/Electrical Floorplan

This phase sits between an ERC-clean schematic and formal PCB layout.

It is **not** a routed PCB. It is a dimensioned placement feasibility check:
top view, side view, board-outline envelopes, component height envelopes, cable/FPC
corridors, keep-outs and thermal/acoustic/RF conflict review.

## Verdict rule

**Formal PCB placement/routing must not start until this floorplan passes.**

If the floorplan does not fit, go back and change the product architecture:
shorter battery, wider local temple pod, different board split, fewer DNP
features, moved Wi-Fi, fewer connectors, or rigid-board-plus-FPC segmentation.

Do not discover "there is nowhere to put it" during routing.

## Current V2 placement concept

Generated current-state artifacts:

| Artifact | Path |
|---|---|
| Phase 1.5 fit report | [../reports/AI_Glasses_V2_Phase1_5_Floorplan.md](../reports/AI_Glasses_V2_Phase1_5_Floorplan.md) |
| Phase 1.5 Chinese CAD handoff | [../reports/AI_Glasses_V2_Phase1_5_Floorplan_ZH.md](../reports/AI_Glasses_V2_Phase1_5_Floorplan_ZH.md) |
| Multi-view render SVG | [../reports/output/AI_Glasses_V2_Phase1_5_Floorplan.svg](../reports/output/AI_Glasses_V2_Phase1_5_Floorplan.svg) |
| Multi-view render PNG | [../reports/output/AI_Glasses_V2_Phase1_5_Floorplan.png](../reports/output/AI_Glasses_V2_Phase1_5_Floorplan.png) |
| Multi-view render PDF | [../reports/output/AI_Glasses_V2_Phase1_5_Floorplan.pdf](../reports/output/AI_Glasses_V2_Phase1_5_Floorplan.pdf) |

Current verdict:

- A normal thin optical frame does **not** fit the V2 RK3576 chip-down
  architecture.
- A thick smart-glasses / sport-sunglasses frame can **conditionally fit** the
  current schematic if it provides the envelope below.
- This is not a PCB-layout release. G00/G00F/G07/G10/G12/G14 remain open/HOLD
  until real CAD, battery, RF, FPC, speaker, camera, and package drawings are
  verified.

Minimum frame envelope for the current schematic:

| Region | Minimum internal envelope | Why |
|---|---:|---|
| Right temple usable length | >=150 mm, with ~160+ mm preferred for clean antenna/battery separation | RK3576 board + 70 mm cell + speaker/pogo + Wi-Fi antenna keep-out |
| Right front compute pod | >=72 x 20 x 8.5 mm | 62 x 18 mm compute PCB plus FPC strain relief and thermal stack |
| Right rear battery/RF/acoustic pod | >=78 x 16 x 8.5 mm | LP451165 max envelope 70 x 12.8 x 5.6 mm plus foam/swell, LS1 acoustic slot, pogo, RF window |
| Left temple usable length | >=145 mm | AON board + 70 mm cell + BLE keep-out + pogo |
| Left front AON pod | >=54 x 16 x 7.5 mm | 46 x 14 mm AON/power PCB plus FPC and shell clearance |
| Left rear battery/RF pod | >=82 x 16 x 7.5 mm | LP451165 max envelope plus BLE antenna region and service/charge area |
| Front sensor brow | >=32 x 8 x 5 mm | Custom IMX415 module, camera power, ESD, mic footprints and FPC exit |

PCB stack recommendation:

- Right compute PCB: one double-sided 8-10 layer HDI rigid island, not a
  board-on-board stack.
- Left AON PCB: start with 4 layers; move to 6 only if RF/noise/current-sense
  review requires it.
- Front sensor/FPC: 4-layer controlled-impedance rigid-flex if MIPI stays in the
  front frame.
- Do not stack the battery over RK3576, RK806S, TPS61088, the boost inductor, or
  the Wi-Fi antenna keep-out.

## Required outputs

| Output | Owner | Required content |
|---|---|---|
| Right-temple top view | CAD + EE | board outlines, RK3576/DDR/PMIC/eMMC/Wi-Fi/boost-inductor, battery, speaker, antenna keep-out, pogo/FPC paths |
| Right-temple side view | CAD + EE | PCB thickness, max component height, battery envelope, speaker height, shell wall, foam/swell allowance |
| Left-temple top view | CAD + EE | AON/power PCB, nRF/nPM/NDP/IMU, battery, BLE antenna, FPC/pogo/mechanical corridors |
| Left-temple side view | CAD + EE | PCB thickness, max component height, battery envelope, shell wall, foam/swell allowance |
| KiCad no-route floorplan | EE/layout | board frames, placement blocks, courtyard/keep-out geometry, component height notes; **no routing** |
| Fit decision table | PM + CAD + EE | pass/fail for battery, compute board, antenna, speaker, FPC, pogo, heat path |

## Dimension table template

Fill every blank with measured CAD/supplier numbers before layout release.

### Right temple

| Item | Required value | Current / candidate value | Pass? | Notes |
|---|---:|---:|:--:|---|
| Right-temple usable internal length | ___ mm | ___ mm | TBD | after hinge/pogo/screw losses |
| Right-temple usable internal width | ___ mm | ___ mm | TBD | include wall thickness |
| Right-temple usable internal height | ___ mm | ___ mm | TBD | side-view clearance |
| Compute PCB outline | ___ x ___ x ___ mm | ___ x ___ x ___ mm | TBD | length x width x thickness |
| RK3576 keep-out/courtyard | ___ x ___ x ___ mm | ___ x ___ x ___ mm | TBD | include fanout + thermal path |
| LPDDR4X + DDR escape zone | ___ x ___ mm | ___ x ___ mm | TBD | length-match corridor |
| RK806S PMIC zone | ___ x ___ x ___ mm | ___ x ___ x ___ mm | TBD | inductors/caps included |
| eMMC zone | ___ x ___ x ___ mm | ___ x ___ x ___ mm | TBD | near RK3576 |
| TPS61088 + boost inductor zone | ___ x ___ x ___ mm | ___ x ___ x ___ mm | TBD | high-current loop, thermal |
| Wi-Fi module zone | ___ x ___ x ___ mm | FCU760K 13.0 x 12.2 x 2.0 mm + keep-out | TBD | final land pattern still HOLD |
| Wi-Fi antenna keep-out | ___ x ___ mm | ___ x ___ mm | TBD | no battery/copper/screw/speaker magnet |
| Right battery envelope | ___ x ___ x ___ mm | LP451165 max envelope target 70 x 12.8 x 5.6 mm | TBD | includes swell, tabs, foam, FPC |
| Speaker envelope | ___ x ___ x ___ mm | ___ x ___ x ___ mm | TBD | after acoustic cavity choice |
| Pogo / charge area | ___ mm length | ___ mm | TBD | sweat/corrosion/service path |
| FPC / harness corridor | ___ x ___ mm | ___ x ___ mm | TBD | no pinch at hinge or screws |
| Shell + foam + swell allowance | ___ mm | ___ mm | TBD | minimum around battery |
| Skin-side thermal stack | ___ mm | ___ mm | TBD | no hot spreader on skin side |

### Left temple

| Item | Required value | Current / candidate value | Pass? | Notes |
|---|---:|---:|:--:|---|
| Left-temple usable internal length | ___ mm | ___ mm | TBD | after hinge/pogo/screw losses |
| Left-temple usable internal width | ___ mm | ___ mm | TBD | include wall thickness |
| Left-temple usable internal height | ___ mm | ___ mm | TBD | side-view clearance |
| AON/power PCB outline | ___ x ___ x ___ mm | ___ x ___ x ___ mm | TBD | length x width x thickness |
| nRF54L15 zone | ___ x ___ x ___ mm | QFN48 6 x 6 mm + RF keep-out | TBD | RF/antenna routing |
| nPM1300 zone | ___ x ___ x ___ mm | QFN 5 x 5 mm + passives | TBD | charger heat and battery proximity |
| NDP120 zone | ___ x ___ x ___ mm | ___ x ___ x ___ mm | TBD | package still HOLD |
| BMI270 zone | ___ x ___ x ___ mm | LGA 2.5 x 3.0 mm | TBD | mechanical vibration coupling |
| Left battery envelope | ___ x ___ x ___ mm | LP451165 max envelope target 70 x 12.8 x 5.6 mm | TBD | includes swell, tabs, foam, FPC |
| BLE antenna keep-out | ___ x ___ mm | ___ x ___ mm | TBD | no battery/copper/screw/magnet |
| Pogo / charge area | ___ mm length | ___ mm | TBD | if shared with right/rear area |
| FPC / harness corridor | ___ x ___ mm | ___ x ___ mm | TBD | fixed-temple EVT or future hinge |
| Shell + foam + swell allowance | ___ mm | ___ mm | TBD | minimum around battery |

## KiCad floorplan contents

Create a no-route KiCad floorplan project or board file with only:

| Place / draw | Purpose |
|---|---|
| Board outlines | prove each rigid PCB fits the CAD envelope |
| RK3576 | compute hot spot and fanout/courtyard reference |
| LPDDR4X | DDR adjacency and length-match escape corridor |
| RK806S | PMIC + inductor/cap placement envelope |
| eMMC | boot storage placement envelope |
| Wi-Fi module | FCU760K LCC + antenna/keep-out relation |
| Boost inductor | height and high-current thermal loop |
| FPC connectors | front sensor and inter-board corridors |
| Battery 3D/envelope blocks | LP451165 nominal and max/swell envelope |
| Speaker | acoustic cavity and magnet keep-out |
| Antenna keep-outs | RF no-copper/no-battery/no-screw/no-magnet zones |
| Pogo/charge region | charging service and sealing interface |

Do **not** route. Do **not** optimize trace escape. The pass/fail question is:
can the real parts, keep-outs and height envelopes coexist in the product volume?

## Pass/fail checklist

| Check | Pass condition | Status |
|---|---|:--:|
| Battery fit | both LP451165 envelopes fit with swell + foam + tabs + FPC room | TBD |
| Compute fit | RK3576/LPDDR/RK806/eMMC/TPS61088/Wi-Fi placement envelopes fit in right temple | TBD |
| AON fit | nRF/nPM/NDP/BMI270/protection/current-sense envelopes fit in left temple | TBD |
| Antenna keep-out | BLE/Wi-Fi regions clear battery, copper, screws, speaker magnet and high-current loops | TBD |
| Speaker/acoustic | LS1 and cavity fit without blocking antenna or FPC corridor | TBD |
| FPC/interconnect | front sensor FPC and L/R interconnect corridor fit without pinch or impossible bend | TBD |
| Pogo/service | charge/debug/service region fits and remains mechanically accessible | TBD |
| Thermal | RK3576/PMIC/boost heat path goes to outer temple, not skin side or battery | TBD |
| DNP features | LS2/M1/U22 and extra INA pads do not consume critical fit/keep-out space | TBD |

## If it fails

Allowed architecture changes before routing:

- switch to a shorter or lower-capacity cell;
- widen only the local compute pod or battery pod;
- move Wi-Fi/antenna further from compute and speaker magnet;
- split one rigid board into multiple rigid islands connected by FPC;
- delete or postpone DNP features that consume mechanical volume;
- reduce connector count or replace connectors with soldered FPC/coax where appropriate;
- reassign functions between left/right temple boards;
- change from future foldable hinge assumptions to fixed-temple EVT.

## Handoff note for CAD

For EVT-A, fixed temples are acceptable. Reserve an FPC/interconnect corridor for
future hinge or service routing, but do not force a production foldable hinge
until the electronics, battery, RF, thermal and acoustic placement can pass this
floorplan.

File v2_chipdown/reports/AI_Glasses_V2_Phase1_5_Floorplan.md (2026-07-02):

# AI Glasses V2 Phase 1.5 Floorplan Fit Check

This report is generated from the current V2 schematic/BOM source of truth. It answers the mechanical placement question before formal PCB routing.

## Verdict

- A normal thin optical frame does **not** fit this V2 RK3576 chip-down architecture.
- A thick smart-glasses / sport-sunglasses frame can **conditionally fit** the current schematic if the frame provides the envelope below.
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

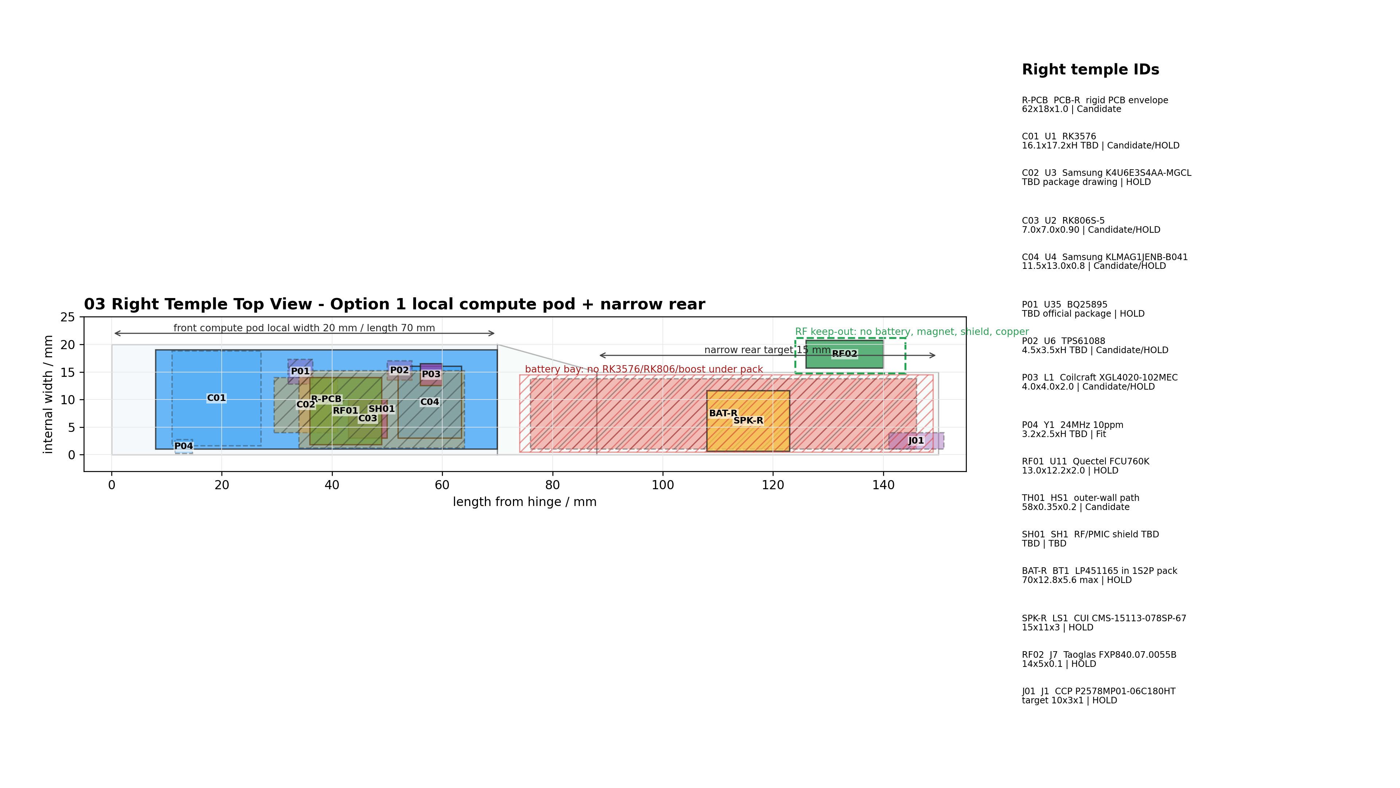
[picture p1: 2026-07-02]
v2_chipdown/mechanical_3d/renders/03_right_top.png

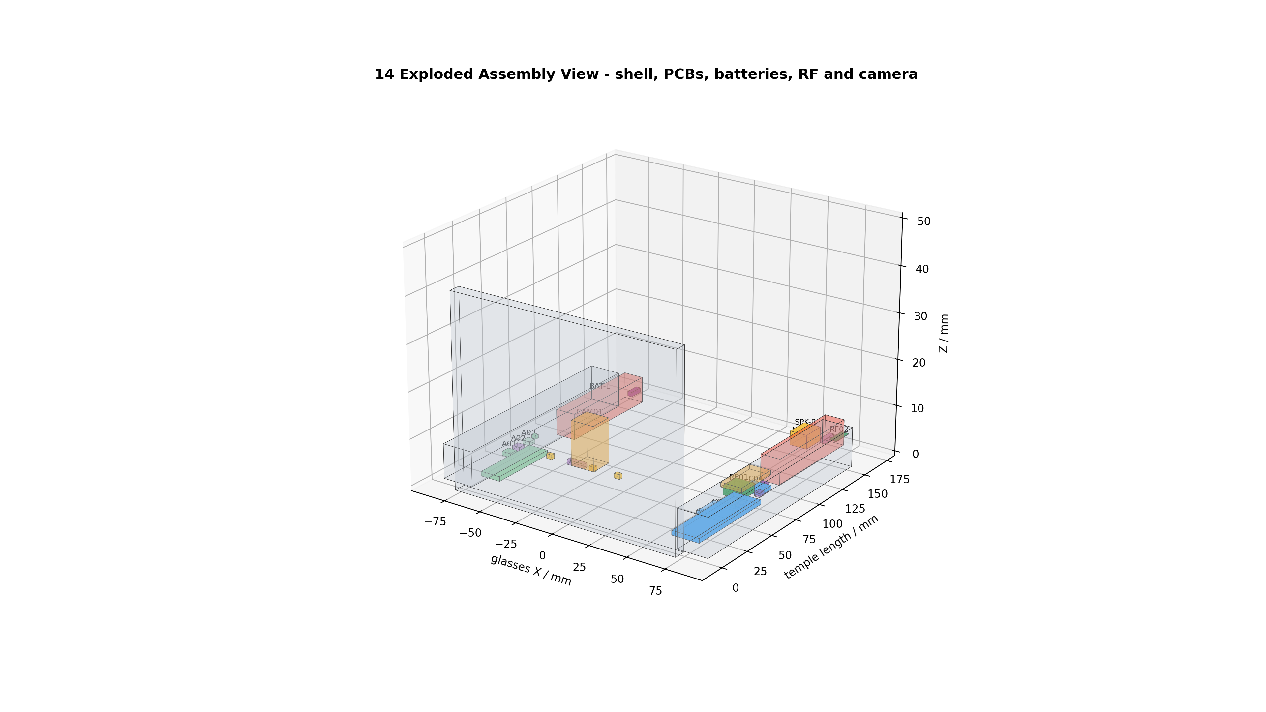
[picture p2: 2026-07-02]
v2_chipdown/mechanical_3d/renders/14_exploded_view.png

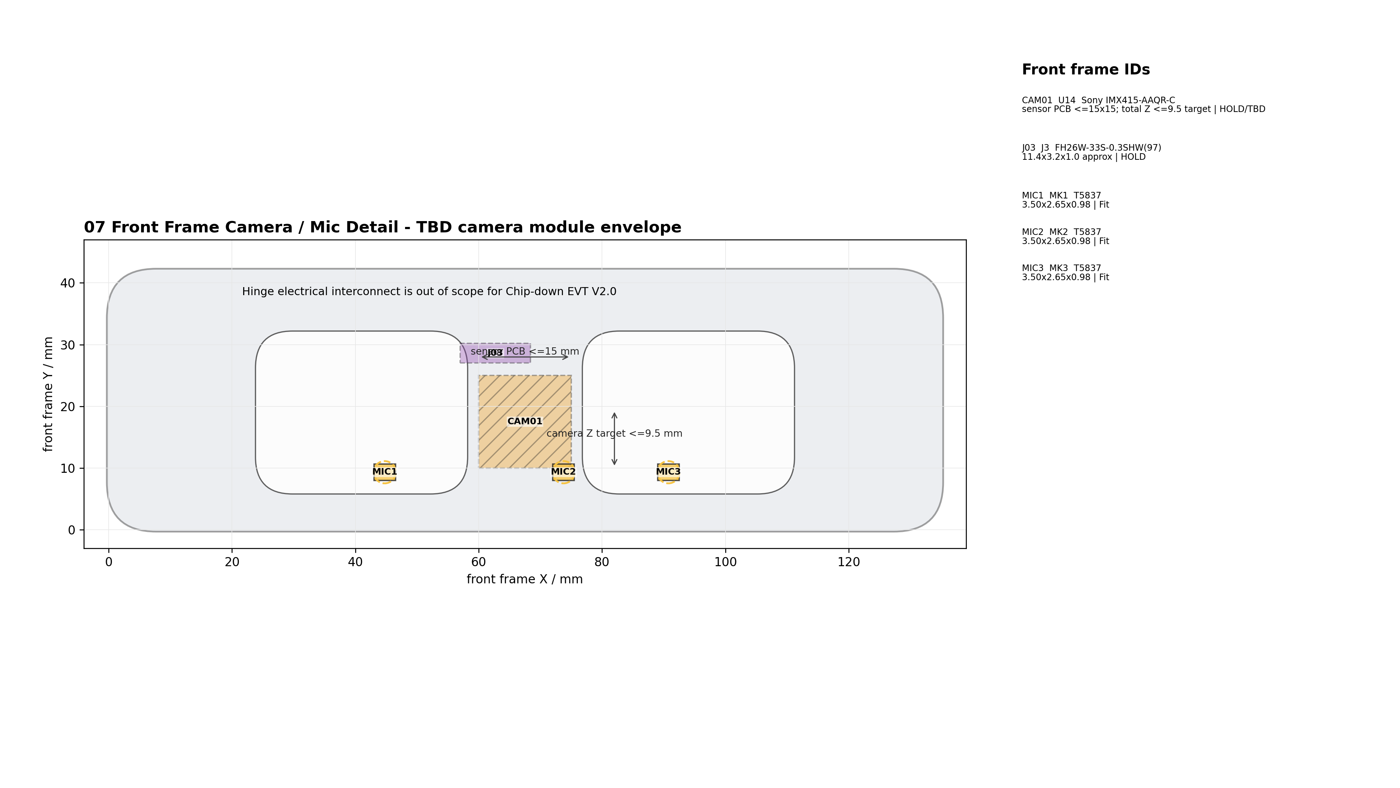
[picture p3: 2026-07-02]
v2_chipdown/mechanical_3d/renders/07_camera_detail.png

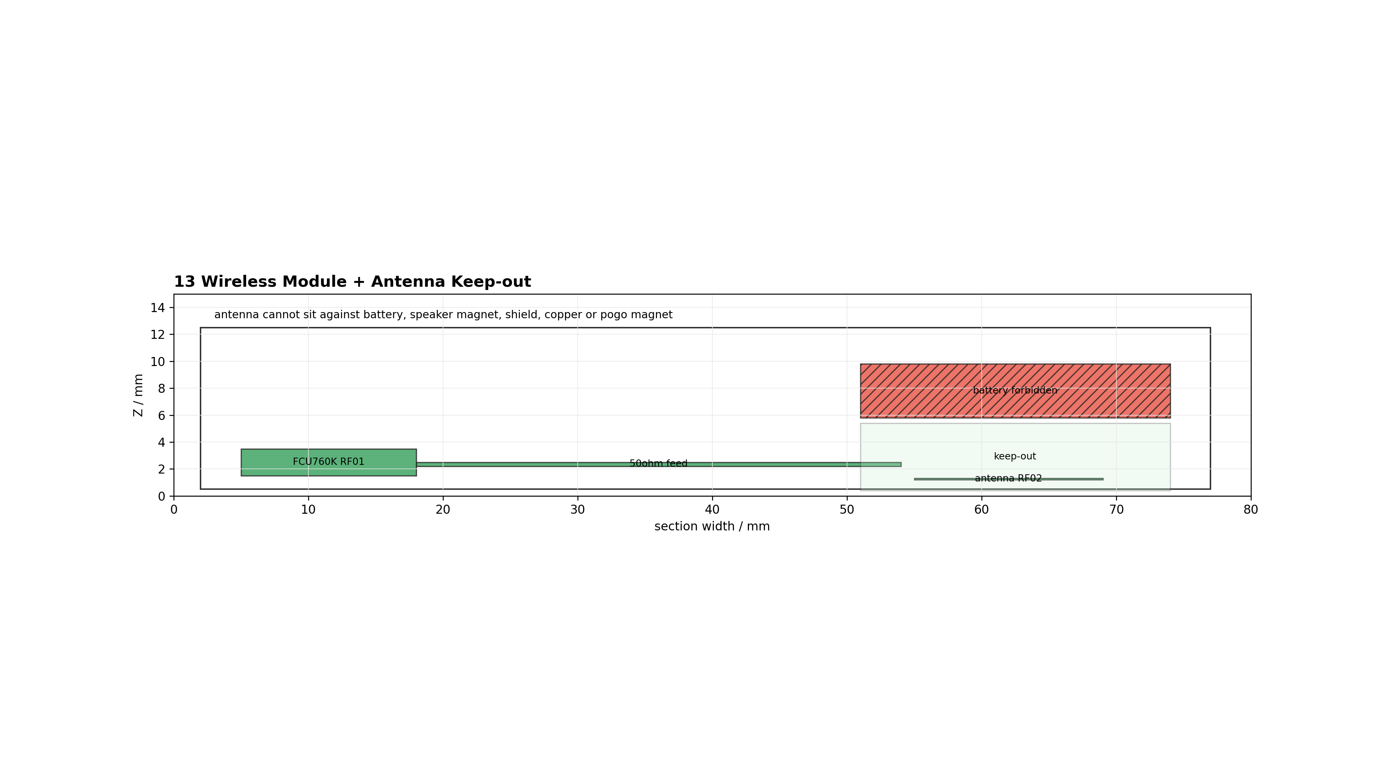
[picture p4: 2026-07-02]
v2_chipdown/mechanical_3d/renders/13_rf_keepout.png

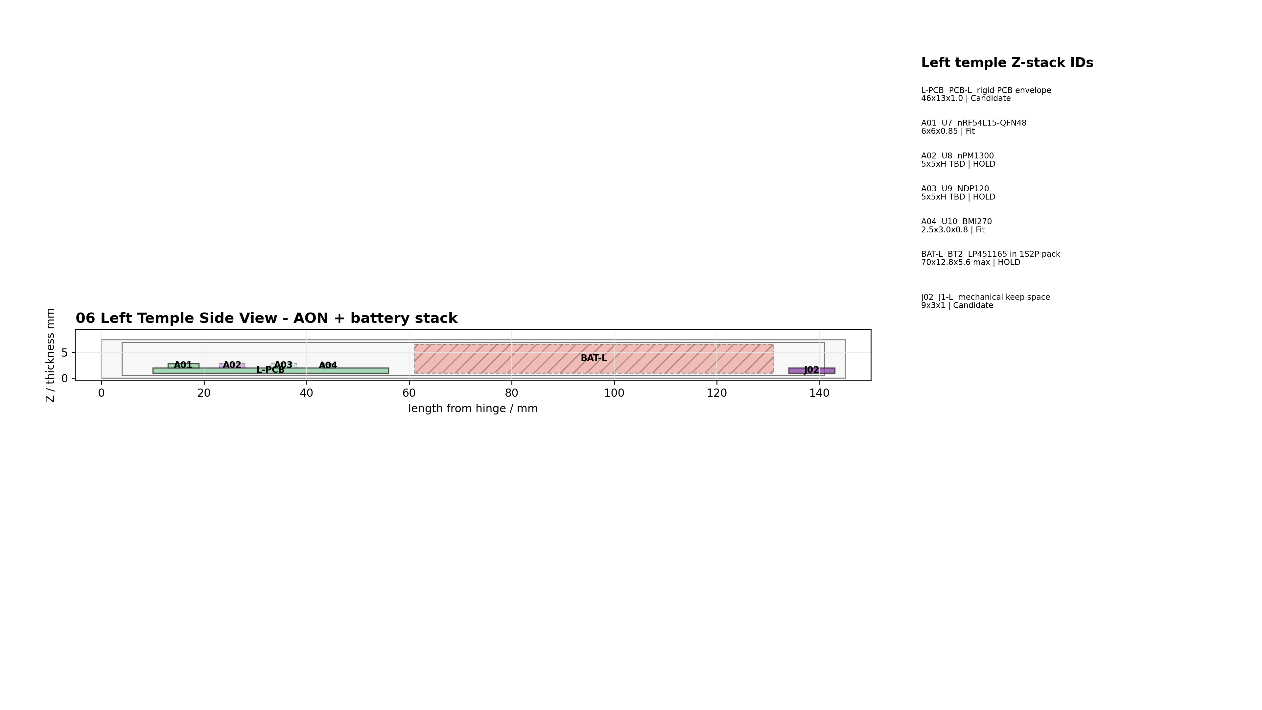
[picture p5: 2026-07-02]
v2_chipdown/mechanical_3d/renders/06_left_side.png

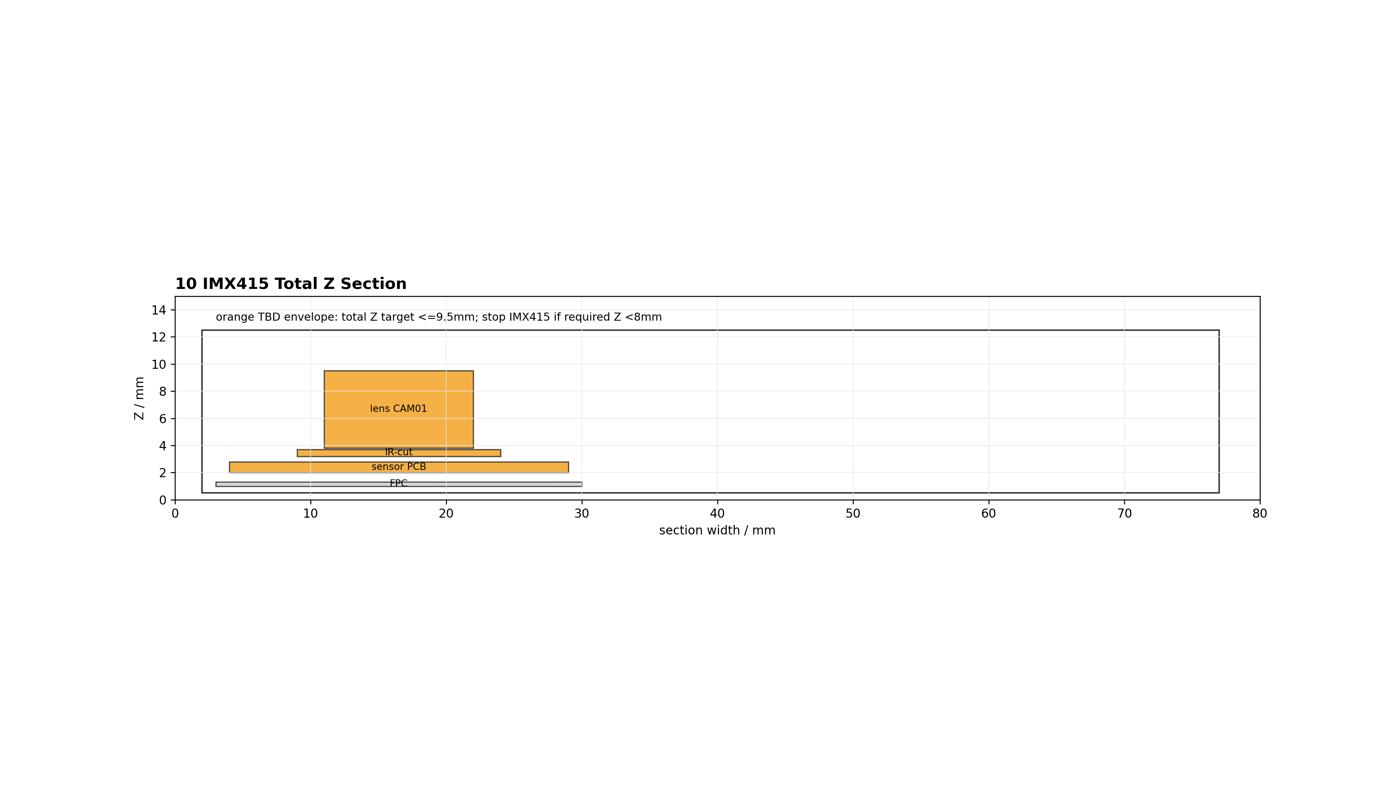
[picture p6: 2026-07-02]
v2_chipdown/mechanical_3d/renders/10_camera_z_section.png

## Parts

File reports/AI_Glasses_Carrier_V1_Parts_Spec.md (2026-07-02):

# AI Glasses Carrier V1 - Parts Specification

- **Generated:** 2026-06-30  |  **Board:** ai_glasses_carrier_v1
- **Scope:** key devices with manufacturer part number + headline datasheet parameters, by subsystem (compute + Wi-Fi/BT, camera, audio + speaker, GNSS, sensors, power, battery, USB-C, protection, connectors).
- MPN + footprint are pulled live from the BOM (`scripts/carrier_bom.py`); the electrical/mechanical specs are curated from the manufacturer datasheets.

> [!] **Headline figures only.** Verify exact numbers and the full orderable suffix (reel/package/grade) against the latest manufacturer datasheet before procurement. Wi-Fi/Bluetooth are integrated in the CM4 SKU (this is a SoM carrier, not chip-down).

---
## 1. Compute module + wireless (Wi-Fi / Bluetooth)

The SoC, RAM, eMMC and the Wi-Fi/BT radio all live ON the Radxa CM4 module (this is a SoM carrier, not chip-down). They reach the carrier only through the three DF40 B2B connectors. Bluetooth/Wi-Fi are therefore part of the CM4 SKU, not separate carrier components.

| Ref | Part / MPN | Mfr | Package | Key parameters | Interface / Rail |
|---|---|---|---|---|---|
| - | Radxa CM4 (RM126-D4E32J0R35W28) | Radxa | SoM, 3x 100-pin DF40 B2B | SoC Rockchip RK3576 (4x Cortex-A72 + 4x A53, NPU ~6 TOPS); RAM 4GB LPDDR4X; eMMC 32GB; supply 5V DCIN; GPIO bank 1.8V (GPIO_VREF) | B2B J31/J32/J1 |
| - | Wi-Fi (on CM4 module) | on-module | in CM4 SKU | 802.11ax (Wi-Fi 6), 2.4 + 5 GHz; antenna on-module / per SKU | SDIO/PCIe in CM4 |
| - | Bluetooth (on CM4 module) | on-module | in CM4 SKU | Bluetooth 5.x (BLE + classic); shares CM4 wireless front-end; antenna per SKU | UART/PCM in CM4 |

## 2. Camera

Sony IMX415 (Radxa Camera 4K) on CM4 CSI3, 4-lane MIPI, via a 31-pin 0.3mm FFC.

| Ref | Part / MPN | Mfr | Package | Key parameters | Interface / Rail |
|---|---|---|---|---|---|
| - | IMX415-AAQR-C (Radxa Camera 4K) | Sony | module (off-board, via J2 FFC) | 1/2.8in 8.29 MP (3864x2192) CMOS; 4-lane MIPI CSI-2; up to 90 fps; rails IO 1.8V / analog 2.9V / core 1.1V (on module); I2C control | CSI3 4-lane, I2C0 |
| J2 | FH35C-31S-0.3SHW(50) | Hirose | `AI_Glasses:FH35C-31S-0.3SHW_50` | 31-pos 0.3mm-pitch FFC/FPC connector, bottom-contact; camera flex | CSI3 FFC |

## 3. Audio (amplifier, microphones, speaker)

Class-D speaker path + dual PDM MEMS mics. Speaker is off-board via J3.

| Ref | Part / MPN | Mfr | Package | Key parameters | Interface / Rail |
|---|---|---|---|---|---|
| U4 | MAX98357AETE+T | Analog Devices (Maxim) | `Package_DFN_QFN:QFN-16-1EP_3x3mm_P0.5mm_EP1.45x1.45mm` | Mono class-D amp; I2S/SAI (Left/Right/(L+R)/2); ~3.2W into 4ohm @5V (~92% eff); no MCLK needed; gain 3/6/9/12/15 dB; supply 2.5-5.5V | SAI1 (BCLK/LRCK/DIN) |
| MK1 | SPH0641LU4H-1 | Knowles | `Sensor_Audio:Knowles_LGA-5_3.5x2.65mm` | PDM digital MEMS mic, bottom port; SNR 64.3 dB(A); AOP 120 dBSPL; sens -26 dBFS; supply 1.6-3.6V; ultrasonic-capable | PDM1 (L, SEL=GND) |
| MK2 | SPH0641LU4H-1 | Knowles | `Sensor_Audio:Knowles_LGA-5_3.5x2.65mm` | Same as MK1; right channel | PDM1 (R, SEL=VDD) |
| - | OWS-091630W50A-8 (speaker) | OWS / generic | 9x16x3.0 mm (off-board via J3) | 8 ohm; rated ~1 W (peak higher); micro rectangular speaker; SPL/Fo per datasheet | amp OUT+/OUT- (post FB1/FB2) |
| FB1 | Ferrite 600ohm@100MHz | Murata/TDK class | `Inductor_SMD:L_0603_1608Metric` | Class-D EMI bead on OUT+; with C23 1nF | speaker EMI |
| FB2 | Ferrite 600ohm@100MHz | Murata/TDK class | `Inductor_SMD:L_0603_1608Metric` | Class-D EMI bead on OUT-; with C24 1nF | speaker EMI |

## 4. GNSS (positioning)

u-blox MAX-M10S over UART; external active antenna via U.FL.

| Ref | Part / MPN | Mfr | Package | Key parameters | Interface / Rail |
|---|---|---|---|---|---|
| U14 | MAX-M10S-00B-01 | u-blox | `RF_GPS:ublox_MAX` | GNSS receiver GPS/GLONASS/Galileo/BeiDou/QZSS; tracking sens -167 dBm; ~25 mA continuous; VCC 2.7-3.6V, VIO 1.8V; UART/I2C | UART7, U.FL (J8) |
| J8 | U.FL-R-SMT-1 | Hirose | `Connector_Coaxial:U.FL_Hirose_U.FL-R-SMT-1_Vertical` | 50 ohm U.FL/IPEX coax RF connector; external active GNSS antenna | RF 50 ohm |
| D4 | low-cap RF ESD (<=0.3pF) | TBD (Nexperia/Littelfuse class) | `Diode_SMD:D_SOD-882` | RF ESD clamp on antenna feed; capacitance <=0.3 pF; Vrwm >=5V | antenna ESD |

## 5. Sensors (IMU, haptics)

| Ref | Part / MPN | Mfr | Package | Key parameters | Interface / Rail |
|---|---|---|---|---|---|
| U10 | ICM-42688-P | TDK InvenSense | `Package_LGA:LGA-14_3x2.5mm_P0.5mm_LayoutBorder3x4y` | 6-axis IMU; accel +/-2/4/8/16 g; gyro up to +/-2000 dps; gyro noise ~2.8 mdps/rtHz; I2C/SPI; supply 1.71-3.6V | I2C8, INT1 |
| U11 | DRV2605L | Texas Instruments | `Package_SO:MSOP-10_3x3mm_P0.5mm` | Haptic driver for LRA/ERM; I2C; 123-effect waveform ROM (TI/Immersion); supply 2-5.2V | I2C + PWM (vib motor J6) |

## 6. Power (boost, charger, fuel gauge, protection, LDOs)

1S Li-Po -> 5V system via boost; per-rail LDOs; charge + gauge + cell protection.

| Ref | Part / MPN | Mfr | Package | Key parameters | Interface / Rail |
|---|---|---|---|---|---|
| U6 | TPS61022 | Texas Instruments | `Package_DFN_QFN:Texas_RWU0007A_VQFN-7_2x2mm_P0.5mm` | Sync boost; Vin 0.5-5.5V; Vout up to 5.5V; 8A switch; up to 96% eff; ~1 MHz | VBAT -> +5V_SYS |
| L1 | Boost inductor 4.7uH | TBD (Cyntec/Wurth class) | `AI_Glasses:POWER_INDUCTOR_7X7_VERIFY` | 4.7 uH; saturation >=10 A; low DCR; shielded; size per measured peak current | boost SW node |
| U7 | BQ25180 | Texas Instruments | `Package_BGA:Texas_DSBGA-12_1.36x1.86mm_Layout3x4_P0.5mm` | 1S Li-ion charger w/ power path; up to 1A charge; input 3.5-5.5V; I2C; ship mode | I2C6, USB-C 5V in |
| U8 | BQ29700 | Texas Instruments | `Package_TO_SOT_SMD:SOT-23-5` | Single-cell protection: OVP/UVP/OCP/SCP; ultra-low IQ | battery protection |
| U9 | MAX17048 | Analog Devices (Maxim) | `Package_DFN_QFN:DFN-8-1EP_2x3mm_P0.5mm_EP0.61x2.2mm` | ModelGauge fuel gauge (SOC); I2C; ~3 uA hibernate; low-batt alert | I2C6 |
| U3 | LP5907MFX-3.3 | Texas Instruments | `Package_TO_SOT_SMD:SOT-23-5` | 250 mA ultra-low-noise LDO; 6.5 uVrms; PSRR ~82 dB; -> camera 3.3V | +CAM_3V3 |
| U12 | TLV75733 | Texas Instruments | `Package_TO_SOT_SMD:SOT-23-5` | 1A LDO; low IQ; -> 3.3V system rail | +3V3 |
| U13 | TLV75718 | Texas Instruments | `Package_TO_SOT_SMD:SOT-23-5` | 1A LDO; low IQ; -> 1.8V VCCIO rail | +1V8 |
| U15 | TPS25940 | Texas Instruments | `Package_DFN_QFN:Texas_RGP0020H_VQFN-20-1EP_4x4mm_P0.5mm_EP2.4x2.4mm` | eFuse: OVP/OCP/reverse-block/inrush; Vin 2.7-18V; optional, DNP by default | VBUS in |

## 7. Battery

1S Li-Po. V1 bench cell locked; glasses build uses thin temple cells.

| Ref | Part / MPN | Mfr | Package | Key parameters | Interface / Rail |
|---|---|---|---|---|---|
| J5 | S3B-PH-SM4-TB | JST | `Connector_JST:JST_PH_S3B-PH-SM4-TB_1x03-1MP_P2.00mm_Horizontal` | Battery connector BAT+/BAT-/NTC; 2.0mm pitch | battery |
| - | V1 bench cell (103450) | generic 1S Li-Po | 10x34x50 mm | 1S 3.7V nominal; ~2000 mAh; with PCM; NTC recommended | via J5 |
| - | Glasses pack (target) | custom 1S | ~35x18x4 mm cells | 2-3 cells, ~250 mAh each (~500-750 mAh); >3-4h needs AI duty-cycling | via J5 |

## 8. USB-C + protection

| Ref | Part / MPN | Mfr | Package | Key parameters | Interface / Rail |
|---|---|---|---|---|---|
| J4 | USB4085-GF-A | GCT | `Connector_USB:USB_C_Receptacle_GCT_USB4085` | USB-C receptacle; USB2 + 5V sink; 16-pos | USB2, 5V in |
| U5 | TPD2E009 | Texas Instruments | `Package_TO_SOT_SMD:SOT-553` | 2-ch ESD clamp for USB2 D+/D-; low cap ~1.5 pF; Vrwm >=5V | USB D+/D- |
| D3 | SMAJ5.0A | Littelfuse/Bourns class | `Diode_SMD:D_SMA` | Uni TVS for VBUS; 5V standoff; 400W peak pulse | VBUS surge/ESD |
| R1 | 5.1k 1% | Yageo class | `Resistor_SMD:R_0603_1608Metric` | USB-C CC1 sink pull-down (locked 1%) | CC1 |
| R2 | 5.1k 1% | Yageo class | `Resistor_SMD:R_0603_1608Metric` | USB-C CC2 sink pull-down (locked 1%) | CC2 |

## 9. MIPI / camera ESD

| Ref | Part / MPN | Mfr | Package | Key parameters | Interface / Rail |
|---|---|---|---|---|---|
| U2 | TPD4E05U06 | Texas Instruments | `Package_SON:USON-10_2.5x1.0mm_P0.5mm` | 4-ch ultra-low-cap (0.4 pF) ESD array for MIPI CSI lanes; Vrwm >=5V | CSI3 lanes |
| U16 | TPD4E05U06 | Texas Instruments | `Package_SON:USON-10_2.5x1.0mm_P0.5mm` | Second 4-ch low-cap ESD array (remaining CSI lanes) | CSI3 lanes |

## 10. CM4 board-to-board connectors

Carrier-side receptacles; mate the CM4's DF40C-100DP plugs; 1.5mm board gap. Footprint geometry is the KiCad library part; the locked 3-connector PLACEMENT still needs the mechanical fit-check (official CM4 STEP + 2-layer coupon).

| Ref | Part / MPN | Mfr | Package | Key parameters | Interface / Rail |
|---|---|---|---|---|---|
| J31 | DF40C-100DS-0.4V(51) | Hirose | `Connector_Hirose_DF40:Hirose_DF40C-100DS-0.4V_2x50_P0.4mm` | 100-pin, 0.4mm pitch B2B receptacle; CM4 J3A (low-speed) | CM4 J3A |
| J32 | DF40C-100DS-0.4V(51) | Hirose | `Connector_Hirose_DF40:Hirose_DF40C-100DS-0.4V_2x50_P0.4mm` | 100-pin, 0.4mm pitch B2B receptacle; CM4 J3B (high-speed: MIPI/USB) | CM4 J3B |
| J1 | DF40C-100DS-0.4V(51) | Hirose | `Connector_Hirose_DF40:Hirose_DF40C-100DS-0.4V_2x50_P0.4mm` | 100-pin, 0.4mm pitch B2B receptacle; CM4 J1 (I/O: SAI, MCLK) | CM4 J1 |

## 11. Other connectors + indicators

| Ref | Part / MPN | Mfr | Package | Key parameters | Interface / Rail |
|---|---|---|---|---|---|
| J3 | SM02B-SRSS-TB | JST | `Connector_JST:JST_SH_BM02B-SRSS-TB_1x02-1MP_P1.00mm_Vertical` | Speaker connector (post-EMI); 1.0mm pitch | speaker |
| J6 | SM02B-SRSS-TB | JST | `Connector_JST:JST_SH_BM02B-SRSS-TB_1x02-1MP_P1.00mm_Vertical` | Vibration motor connector; 1.0mm pitch | haptic |
| J7 | Header 1x4 2.54mm | generic | `Connector_PinHeader_2.54mm:PinHeader_1x04_P2.54mm_Vertical` | UART debug (TX/RX/GND/VREF) | UART0 |
| D1 | LED Green | generic | `LED_SMD:LED_0603_1608Metric` | Power LED; active-low GPIO sink; via R4 1k | status |
| D2 | LED Blue | generic | `LED_SMD:LED_0603_1608Metric` | Status LED; active-low GPIO sink; via R5 1k | status |

## 12. Passives (summary)

Full per-family passive audit (value / tolerance / dielectric / voltage / DC-bias verdicts) is in **AI_Glasses_Carrier_V1_Design_Review.pdf §7**. Headline:

| Family | Refs (examples) | Spec |
|---|---|---|
| I2C pull-ups | R7-R13 | 2.2k 1% 0603 |
| USB-C CC | R1, R2 | 5.1k 1% 0603 (locked) |
| Decoupling | C2,C4,C6,C10,C13... | 100nF X7R 50V 0603 |
| Bulk MLCC | C1,C3,C5,C8,C15,C29 | 10uF X5R 25V 0805 |
| VBAT bulk | C7 | 22uF X5R 25V 0805 |
| Class-D EMI | C23, C24 | 1nF X7R 50V 0603 |
| Current shunt | R3 | mohm 2512 (select for 5V measure) |

---
_Generated by `scripts/generate_parts_spec.py`. MPN/footprint live from the BOM; headline specs curated from manufacturer datasheets - verify before procurement._

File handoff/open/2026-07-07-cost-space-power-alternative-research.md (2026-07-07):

# 更低成本 / 更小空间 / 更低功耗方案调研 · 🔴 待接手
- **从 → 给**: Zizheng → l.hongyi / hardware teammate
- **日期**: 2026-07-07
- **涉及域 / 要读**: `v2_chipdown/reports/AI_Glasses_Chipdown_BOM_V2.3_Current_Schematic_ZH.md`, `v2_chipdown/reports/POWER_BUDGET_V2.md`, `v2_chipdown/reports/AI_Glasses_Hardware_Dimensions_and_Performance_V2.3.md`, `v2_chipdown/reports/AI_Glasses_V2_Phase1_5_Floorplan_ZH.md`, `v2_chipdown/reports/AI_Glasses_V2_Phase1_5_Floorplan.md`, `v2_chipdown/docs/01_architecture.md`, `v2_chipdown/docs/05_hardware_partition.md`

**交接什么**: 请独立调研一轮比当前 RK3576 chip-down baseline 更便宜、更省空间、更低功耗、且更容易塞进运动眼镜外形的硬件方案，并给出可落地的替代架构建议。

## 当前 baseline 必须先看清楚

当前方案不是量产 release，只是 no-route placement + schematic/KiCad export baseline。下面尺寸、功耗、续航、价格都不能当成 EVT 实测或供应商正式 quote。

## 1. 整副眼镜 / 镜腿外形尺寸

先不要只看 PCB，要先看整机能不能戴。当前有两个口径：

| 口径 | 当前数值 | 说明 |
|---|---:|---|
| 外观目标前框宽度 | 138-142 mm | 运动墨镜 / 包裹式前框目标 |
| 外观目标镜腿长度 | 143-147 mm | 常规运动眼镜目标，约 145 mm |
| 外观目标整机重量 | <50 g | 舒适佩戴硬指标 |
| 外观目标镜腿最大厚度 T | <=6 mm | 横向厚度，贴头到外侧 |
| 外观目标镜腿最大高度 H | <=28 mm | 竖向刀锋高度；当前刀锋段目标约 26 mm |
| 当前 RK3576 方案右镜腿 usable length | >=150 mm，最好 ~160+ mm | 为了放 62 mm compute PCB + 70 mm 电池 + speaker/pogo + Wi-Fi antenna keep-out |
| 当前 RK3576 方案左镜腿 usable length | >=145 mm | AON 板 + 70 mm 电池 + BLE keep-out + service 区 |
| 右侧前段 compute pod 内部净空 | >=72 x 20 x 8.5 mm | 62 x 18 mm compute PCB 加 FPC/散热/壳体余量 |
| 右侧 compute pod 外形估计 | 高 22-24 mm，厚 10-11 mm | 这已经明显厚于普通眼镜镜腿 |
| 后段电池/RF/声学 pod 外形估计 | 高 17-18 mm，厚 8.5-9.5 mm | 仍是厚智能眼镜/运动墨镜口径 |
| 前框 sensor brow 内部净空 | >=32 x 8 x 5 mm | camera power/ESD/mic/FPC；camera module 本身仍 HOLD |

**关键矛盾**: 外观目标镜腿约 143-147 mm，但当前 RK3576 右侧工程 fit 需要 >=150 mm，最好 160+ mm。你调研替代方案时，不要只说芯片小了；必须说明它能否把右镜腿从 150-160 mm 需求拉回 143-147 mm 外观目标，或者能否明显降低 22-24 mm 高 / 10-11 mm 厚的 compute pod。

## 2. 当前板级 / 部件占用

| 区域 | 当前 baseline | 备注 |
|---|---:|---|
| 右镜腿 Compute PCB | 62 x 18 x 1.0 mm | RK3576 + PMIC + LPDDR4X + eMMC + Wi-Fi + charger/boost/audio；formal routing 未 release |
| 左镜腿 AON/Power PCB | 46 x 13 x 1.0 mm | nRF54L15 + nPM1300 + NDP120 + BMI270 + sense/power |
| 前框 sensor/FPC target | 32 x 8 mm target | camera module/FPC vendor drawing 未关闭前不能定版 |
| EVT debug tail | 30 x 12 mm | 只给实验室 bring-up；量产应删除或隐藏 |
| 单颗电池控制 envelope | 70 x 12.8 x 5.6 mm | LP451165 300 mAh；左右各一颗 |
| 推荐电池包 | 1S2P, 600 mAh / 2.22 Wh nominal, 约 12 g | 左右镜腿各一颗；pack drawing 和 fit test 仍 HOLD |

## 3. 当前功耗与续航

功耗来自项目预算模型，不是 EVT bench 实测。续航按推荐 LP451165 x2、1S2P、600 mAh、3.7 V nominal、90% usable DoD 计算。

| 状态 | 当前估算总功耗 | 电池电流 | 推荐 600 mAh 续航 |
|---|---:|---:|---:|
| 深度待机 | 22 mW | 6 mA | 91 h |
| 快速待机 | 134 mW | 36 mA | 15 h |
| 手机协作识别 | 362 mW | 98 mA | 5.5 h (331 min) |
| 混合运动使用 | 450 mW | 122 mA | 4.4 h (266 min) |
| 连续 1080p 录像 | 1290 mW | 349 mA | 1.5 h (93 min) |
| 录像 + 本地 AI Burst | 2065 mW | 558 mA | 1.0 h (58 min) |

日常混合模型：

| 使用模型 | 平均功耗 | 推荐 600 mAh 续航 |
|---|---:|---:|
| All-day mixed wear | ~153 mW | 13 h |
| Heavy usage day | ~290 mW | 6.9 h |

对比提醒：如果只用单颗 300 mAh，混合运动使用只有 2.2 h，连续录像约 46 min，AI Burst 约 29 min。因此替代方案如果想减少电池体积，必须同时显著降低 active/record/AI burst 功耗，否则续航会直接不够。

主要功耗池：RK3576 SoC + LPDDR4X + eMMC + PMIC、camera、Wi-Fi active time。AON 侧需要重点确认 NDP120 always-listening 是否真的值得保留。

## 4. 当前预估价格

价格是工程估算，不是实时采购报价，也不是供应商正式 quote。

| 场景 | 1 套 | 5 套 | 20 套 | 100 套 | 1000 套 |
|---|---:|---:|---:|---:|---:|
| 只做裸 PCB/FPC 板组 | $155-460 / ¥1052-3121 | $95-260 / ¥645-1764 | $55-150 / ¥373-1018 | $28-75 / ¥190-509 | $14-40 / ¥95-271 |
| 电子样机/EVT PCBA | $1000-2000 / ¥6785-13571 | $650-1100 / ¥4411-7464 | $420-750 / ¥2850-5089 | $220-420 / ¥1493-2850 | $100-230 / ¥679-1561 |

当前贵的核心原因：右侧 RK3576 compute 架构、8-10 层 HDI 候选、小批量 SMT/NRE、BGA/DDR、定制相机、RF/电池/声学集成风险。

## 5. 你需要做什么

- [ ] 先读上面列出的 baseline 文件，确认你理解当前 architecture：AON island 常开，RK3576 compute island 按需启动。
- [ ] 找 3-5 个替代方案，不限于换主控，也可以是架构变化：phone-assist 更彻底、删/替 NDP120、换低功耗 vision SoC、用模块替代 chip-down、降低 camera/AI spec、把部分计算挪到手机/线控盒等。
- [ ] 每个方案都必须填完整对比表：整机前框宽度、镜腿长度、镜腿最大高度/厚度、PCB/模块尺寸、电池尺寸/容量、待机功耗、录像功耗、AI burst 功耗、续航、BOM/PCBA 成本、软件移植难度、供应链风险、量产/认证风险。
- [ ] 明确这个方案能不能解决当前尺寸矛盾：右镜腿是否还能保持 143-147 mm？compute pod 是否能低于 22-24 mm 高、10-11 mm 厚？电池是否还能保证 4 h 混合使用和约 1 h AI burst？
- [ ] 明确哪些能力会降级：本地 STT/TTS、YOLO/NPU、1080p 编码、always-listening、Wi-Fi 上传、手机依赖程度。
- [ ] 给出你推荐的 1-2 个方案，并说明为什么比当前 baseline 更适合下一版 EVT。
- [ ] 只写 proposal，不直接改 `.kicad_sch` 或 `.kicad_pcb`。

## 6. 建议输出格式

请新增一个 proposal 文件：

`v2_chipdown/reports/alternative_architecture_cost_power_space_research.md`

里面至少包含：

1. 当前 baseline 摘要：整机尺寸、部件尺寸、功耗、续航、成本五张表。
2. 候选方案对比矩阵。
3. 每个候选方案的证据来源：datasheet/package drawing、开发板实测或公开功耗、供应商报价/价格截图、最小起订量、软件 SDK 状态。
4. 推荐方案和不推荐方案。
5. 需要 Zizheng/团队决定的问题。

## 7. 不要踩的坑

- 不要只比较芯片单价。小批量 PCBA 里，HDI、BGA、DDR、SMT/NRE、X-ray、调试风险会吃掉单颗便宜芯片的优势。
- 不要只写 PCB 尺寸。必须写整副眼镜大概多宽、镜腿多长、镜腿最厚/最高、前框/镜腿内部净空够不够。
- 不要只写功耗。必须把功耗换算成 600 mAh / 500 mAh / 300 mAh 等候选电池下的续航。
- 不要把营销 TOPS 当成可用 AI 能力。要看模型支持、NPU toolchain、camera/ISP/encode、Linux/BSP 成熟度。
- 不要默认删 NDP120。可以提出 DNP/phone-assist variant，但要写清楚对 always-listening 体验和待机功耗的影响。
- 不要用未确认尺寸替代当前 envelope。必须写 package/body size、外围器件、DDR/flash/PMIC/antenna/camera connector 后的总占用。
- 不要改 KiCad 文件；先把结论写成 proposal，等团队批准后再进入 schematic 变更。

## 待你回答 / 决定

- 你能否在本周内给出 3-5 个候选方案的第一版对比矩阵？
- 你更倾向从哪条线开始：低功耗 AON、替代 RK3576 compute、phone-assist 架构、camera/Wi-Fi/encoder 降配、还是有线/口袋计算盒？
- 你需要我补哪类约束：目标续航、目标镜腿宽度/高度、目标售价、必须保留的本地 AI 能力？

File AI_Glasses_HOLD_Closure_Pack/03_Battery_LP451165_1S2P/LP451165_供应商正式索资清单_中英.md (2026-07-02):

# LP451165 正式索资清单（可直接发供应商）

## 中文

项目计划使用两颗 LP451165（3.7 V、300 mAh、4.5 x 11 x 65 mm）组成匹配的 1S2P 电池包。请提供以下可追溯资料，文件需标注供应商名称、料号、版本和日期：

1. Cell Specification 与 Pack Specification PDF。
2. 带公差、封边、极耳、出线和保护板的完整机械图。
3. 重量、最大厚度、初始厚度和循环后的厚度膨胀数据。
4. 额定容量、最小容量及测试条件。
5. 标准/最大充电电流、充电截止电流。
6. 推荐、最大连续和脉冲放电电流；脉冲持续时间和冷却条件。
7. 0.2C、0.5C、1C、2C 在 25°C 的放电曲线。
8. 0°C、25°C、45°C 的放电曲线。
9. 初始 DCIR、最大 DCIR、100/300/500 周期后的 DCIR。
10. 循环寿命和容量保持率。
11. 过充、过放、短路、挤压、跌落和温度测试报告。
12. UN38.3、IEC 62133、UL1642（如有）、MSDS 和运输资料。
13. 10 kΩ NTC 选项、B 值、公差和安装位置。
14. 1S2P 配对规则：开路电压、容量、DCIR、生产批次和老化时间的允许差异。
15. 每颗电芯独立保险丝/PTC或熔断连接的选项。
16. 1S2P Pack 的最大连续/脉冲输出与保护阈值。
17. MOQ、样品交期、量产交期和生命周期承诺。

请同时提供：10颗标准样品、10颗高倍率样品、5套供应商完成配对和保护的1S2P Pack。

## English

We plan to use two LP451165 cells (3.7 V, 300 mAh, nominal 4.5 x 11 x 65 mm) as a matched 1S2P battery pack. Please provide traceable documents showing supplier name, part number, revision and date:

1. Formal Cell Specification and Pack Specification PDFs.
2. Complete mechanical drawing including tolerances, pouch seals, tabs, wires and PCM.
3. Weight, maximum thickness, initial thickness and swelling after cycling.
4. Rated/minimum capacity and test conditions.
5. Standard and maximum charge current and termination current.
6. Recommended, maximum continuous and pulse discharge current, including pulse duration and cooling conditions.
7. 0.2C, 0.5C, 1C and 2C discharge curves at 25°C.
8. Discharge curves at 0°C, 25°C and 45°C.
9. Initial/maximum DC internal resistance and DCIR after 100/300/500 cycles.
10. Cycle-life and capacity-retention data.
11. Safety test reports for overcharge, over-discharge, short circuit, crush, drop and temperature.
12. UN38.3, IEC 62133, UL1642 if available, MSDS and shipping documents.
13. 10 kΩ NTC option, beta value, tolerance and placement.
14. 1S2P matching limits for open-circuit voltage, capacity, DCIR, lot and aging time.
15. Per-cell fuse/PTC/fusible-link options.
16. 1S2P pack continuous/pulse current ratings and protection thresholds.
17. MOQ, sample lead time, production lead time and lifecycle commitment.

Please quote 10 standard cells, 10 high-rate cells and 5 supplier-matched/protected 1S2P packs.

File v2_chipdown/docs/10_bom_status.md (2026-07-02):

# 10 — BOM freeze status (generated)

> Generated 2026-07-01 from `scripts/chipdown_bom.py`. Do not hand-edit. Legend: **Fit** first-build populate · **DNP** land only · **HOLD** candidate, blocked on a gate · **TBD** MPN/spec undecided.

**93 components** — 57 Fit · 18 HOLD · 16 DNP · 2 TBD. 133 nets.

Related generated gates: [08 signal dictionary](08_signal_dictionary.md), [09 power-domain isolation](09_power_domain_isolation_matrix.md), [11 footprint register](11_footprint_register.md), [12 layout-entry status](12_layout_entry_gate_status.md), plus [13 Phase 1.5 floorplan](13_mechanical_electrical_floorplan.md).

## R-Temple Compute Board (33)

| BOM ID | Ref | Value | Pri | Status | Gate to close |
|---|---|---|---|:--:|---|
| C001 | U1 | RK3576 | P0 | Fit | G01 (RK3576 datasheet/HDG/ballmap/DDR guide) |
| C002 | U2 | RK806S-5 QFN68 7x7x0.90mm | P0 | HOLD | G03 (official RK806S-5 datasheet, OTP/default rails, sequence, layout guide) |
| C003 | U3 | Samsung K4U6E3S4AA-MGCL | P0 | HOLD | G02 (Samsung datasheet/ball map/IBIS + Rockchip DDR AVL/init + length report) |
| C004 | U4 | Samsung KLMAG1JENB-B041 | P0 | HOLD | G04 (official Samsung datasheet/package + BSP boot/HS200 then HS400 validation) |
| C005 | Y1 | 24 MHz 10 ppm XTAL | P0 | Fit | G01 (reuse reference CL/ESR + placement distance per HDG) |
| C006 | U5 | MX25U6432F | P1 | DNP | Boot flow decides whether production needs it |
| C007 | U6 | TPS61088 | P0 | HOLD | G06/G09 (measured RK3576 boot+AI peak, soft-start, droop, thermal) |
| C008 | L1 | Coilcraft XGL4020-102MEC 1.0uH | P0 | HOLD | G06/G13 (Isat/DCR/thermal pass for 5.1V 3A continuous / 4A peak boost) |
| C010b | U35 | BQ25895 | P0 | HOLD | Charger/power-path config, TS thresholds, 1S2P charge profile, thermal/current validation |
| C015 | U11 | FCU760KAAMD | P0 | HOLD | G05 (Quectel HW Design + RK3576 BSP driver/firmware/enum) + official LCC land pattern |
| C015-C | C1 | 47uF 6.3V X5R | P0 | Fit | Local bulk per Quectel HW Design |
| C016 | U12 | TPS62825 | P0 | Fit | G05/G06 (inductor/caps per module 353mA TX peak + ripple) |
| C016b | U13 | TPS22917DBVR | P0 | Fit | G05 (turn-on sequence w/ module) |
| C016c | L2 | Wi-Fi buck inductor (TBD) | P0 | Fit | Per TPS62825 peak+ripple |
| C024 | U20 | MAX98360A | P0 | Fit | Verify Z/cavity/EMI/peak power |
| C024b | U21 | TPS22917DBVR | P0 | Fit | Amp must be fully power-downable (V1 lesson) |
| C034b | U36 | 5V input eFuse/OVP (MPN TBD) | P0 | HOLD | Select MPN for pogo/USB VBUS surge, reverse, OVP, current limit and thermal fault |
| C043 | RT3 | 10k NTC B=3435 | P0 | Fit | Probe position per thermal sim |
| C044-RAUD | RS6 | 50 mohm 1% | P0 | Fit | 20-100 mohm |
| C044-RSOC | RS4 | 10 mohm 1% | P0 | Fit | 5-20 mohm (2A x 10m=20mV; avoid boost UVLO) |
| C044-RWIFI | RS5 | 50 mohm 1% | P0 | Fit | 20-100 mohm |
| C044c | U28 | INA238 (I_SOC_5V) | P1 | DNP | Power Gate — EVT-A only |
| C044e | U29 | INA238 (I_WIFI) | P1 | DNP | Power Gate — EVT-A only |
| C044f | U30 | INA238 (I_AUDIO) | P1 | DNP | Power Gate — EVT-A only |
| C045e | R9 | 2.2k 1% | P0 | Fit | Confirm vs SoC PMIC bus |
| C045f | R10 | 2.2k 1% | P0 | Fit | Confirm vs SoC PMIC bus |
| C046a | R11 | 100k | P0 | Fit | Default OFF (§4) |
| C046b | R12 | 100k | P0 | Fit | Default OFF (§4) |
| C046f | R16 | 100k | P0 | Fit | Default OFF (§4) |
| C046g | R17 | 100k | P0 | Fit | Default OFF (§4) |
| C046h | R18 | 100k | P0 | Fit | Default OFF (§4/§9: FCU760K CHIP_EN default low) |
| C046i | R19 | 100k | P0 | Fit | Default OFF (§4) |
| C046j | R20 | 100k | P0 | Fit | Default OFF (§4) |

## L-Temple AON/Power Board (9)

| BOM ID | Ref | Value | Pri | Status | Gate to close |
|---|---|---|---|:--:|---|
| C009 | U7 | nRF54L15-QFN48 | P0 | Fit | EVT-frozen (RF layout/SDK/package to freeze early) |
| C010 | U8 | nPM1300 | P0 | HOLD | G08 (AON <=25/50mW) — configure via nPM PowerUP on EK before board |
| C011 | U9 | NDP120 | P0 | HOLD | Full datasheet + dev kit + measured listening power + NDA/licensing |
| C012 | U10 | BMI270 | P0 | Fit | Evaluate false-trigger under real frame vibration |
| C027 | U22 | DRV2605L | P1 | DNP | Vibration P1 — may DNP on first board (IMU/mic coupling) |
| C044-RBAT | RS1 | 10 mohm 1% 1W | P0 | Fit | I_BAT_TOTAL; the one production-kept sense path |
| C044a | U25 | INA238 (I_BAT_TOTAL) | P1 | DNP | Power Gate — EVT-A; production may keep this one |
| C045a | R3 | 2.2k 1% | P0 | Fit | Confirm vs total AON bus capacitance |
| C045b | R4 | 2.2k 1% | P0 | Fit | Confirm vs total AON bus capacitance |

## Front Sensor Board (24)

| BOM ID | Ref | Value | Pri | Status | Gate to close |
|---|---|---|---|:--:|---|
| C013a | MK1 | T5837 (wake mic) | P0 | Fit | G11 (mic coords/ports/wind/wake + AEC/beamforming) |
| C013b | MK2 | T5837 (array mic 1) | P0 | Fit | G11 |
| C013c | MK3 | T5837 (array mic 2) | P0 | Fit | G11 |
| C014 | MK4 | T5837 (4th mic) | P1 | DNP | G11 (populate only if array sim/proto needs it) |
| C019 | U14 | Sony IMX415-AAQR-C custom module | P0 | HOLD | G10 (module lens/FOV/FPC pinout/lane/supply/timing from vendor) |
| C020 | U15 | TPS62840 | P0 | Fit | Output current/noise per final module (DVDD ~250mA max + margin) |
| C020b | L3 | Cam 1V1 buck inductor (TBD) | P0 | Fit | Per TPS62840 design |
| C021 | U16 | TLV75529PDRVR | P0 | Fit | Verify vs IMX415 AVDD peak (156mA) + PSRR |
| C022 | U17 | TPS22917DBVR | P0 | Fit | Check reverse block, ramp, QOD, logic level |
| C023a | U18 | TPD4E05U06 | P0 | Fit | Low-cap array near FPC entry |
| C023b | U19 | TPD4E05U06 | P0 | Fit | Low-cap array near FPC entry |
| C023c | U34 | TPD4E05U06 | P0 | Fit | Low-cap array near FPC entry for 4-lane CSI |
| C038 | J3 | Hirose FH26W-33S-0.3SHW(97) | P0 | HOLD | G10/G12 (camera module vendor signs 33-pin pinout, contact orientation, impedance) |
| C045c | R5 | 2.2k 1% | P0 | Fit | Confirm vs camera bus capacitance |
| C045d | R6 | 2.2k 1% | P0 | Fit | Confirm vs camera bus capacitance |
| C046c | R13 | 100k | P0 | Fit | Default OFF (§4) |
| C046d | R14 | 100k | P0 | Fit | Default OFF (§4) |
| C046e | R15 | 100k | P0 | Fit | Default OFF (§4) |
| C044-IC1 | U31 | INA238 (I_CAM_1V1) | P1 | DNP | Power Gate — EVT-A only |
| C044-RC1 | RS7 | 100 mohm 1% | P0 | Fit | Per-rail Kelvin (§23/§29); DVDD ~250mA |
| C044-IC8 | U32 | INA238 (I_CAM_1V8) | P1 | DNP | Power Gate — EVT-A only |
| C044-RC8 | RS8 | 100 mohm 1% | P0 | Fit | Per-rail Kelvin (§23/§29); IOVDD ~3mA |
| C044-IC29 | U33 | INA238 (I_CAM_2V9) | P1 | DNP | Power Gate — EVT-A only |
| C044-RC29 | RS9 | 100 mohm 1% | P0 | Fit | Per-rail Kelvin (§23/§29); AVDD ~156mA |

## Temple Rears (batt/spkr/ant) (19)

| BOM ID | Ref | Value | Pri | Status | Gate to close |
|---|---|---|---|:--:|---|
| C017 | J7 | Taoglas FXP840.07.0055B | P0 | HOLD | G14 (worn-state tune + antenna keep-out in full shell with battery/speaker) |
| C018 | J6 | FCU760K ANT_BT DNP test pad | P0 | DNP | Only populate if Quectel FAE + coexistence test requires the second RF port |
| C025 | LS1 | CUI CMS-15113-078SP-67 | P0 | HOLD | Acoustic EVT: 0.3-0.5cc cavity, port/foam seal, magnet-to-antenna clearance, leak test |
| C026 | LS2 | 2nd speaker pad | P1 | DNP | Decide dual-speaker at EVT-B |
| C028 | M1 | LRA/ERM motor | P1 | DNP | Vibration P1 |
| C029 | BT1 | LP451165 300mAh (R) | P0 | HOLD | G07 (full datasheet, >=2C, IR, cycles, cert) |
| C030 | BT2 | LP451165 300mAh (L) | P0 | HOLD | G07 |
| C031a | F1 | PTC/fuse (R branch) | P0 | TBD | Rating from peak-current calc (> branch peak, < FPC rating) |
| C031b | F2 | PTC/fuse (L branch) | P0 | TBD | Rating from peak-current calc |
| C032 | PCM1 | Supplier 1S2P pack PCM + protection FETs | P0 | HOLD | Pack supplier drawing: OVP/UVP/OCP/SCP thresholds, FET Rds(on), current rating, NTC placement, UN38.3/MSDS/IEC62133 |
| C033-TP | TP2 | Battery test points | P0 | Fit | Cell/pack voltage + NTC probe access (§21) |
| C033a | RT1 | 10k NTC B=3435 1% (R cell) | P0 | Fit | NTC curve/package/placement matched to pack supplier + BQ25895/nPM1300 config |
| C033b | RT2 | 10k NTC B=3435 1% (L cell) | P0 | Fit | NTC curve/package/placement matched to pack supplier + ADC/config |
| C034 | J1 | CCP P2578MP01-06C180HT | P0 | HOLD | USB2 eye/contact validation, current/fault/ESD, mating STEP, corrosion/cycle life |
| C040 | J5 | U.FL / I-PEX MHF RF test connector | P0 | DNP | EVT RF debug only; production prefers direct coax or soldered antenna pigtail |
| C044-ICL | U26 | INA238 (I_CELL_L) | P1 | DNP | Power Gate — EVT-A only (current-share) |
| C044-ICR | U27 | INA238 (I_CELL_R) | P1 | DNP | Power Gate — EVT-A only (current-share) |
| C044-RCL | RS2 | 10 mohm 1% | P0 | Fit | Branch current-share (§7/§29) |
| C044-RCR | RS3 | 10 mohm 1% | P0 | Fit | Branch current-share (§7/§29) |

## EVT Debug Tail (8)

| BOM ID | Ref | Value | Pri | Status | Gate to close |
|---|---|---|---|:--:|---|
| C035 | J2 | USB-C 16p USB2-only | P0 | Fit | Connector height + shell opening co-freeze |
| C036 | U24 | TPD2E001 | P0 | Fit | Keep ~90 ohm diff + continuous ref gnd |
| C037a | R1 | 5.1k 1% | P0 | Fit | USB-C spec |
| C037b | R2 | 5.1k 1% | P0 | Fit | USB-C spec |
| C041 | TP1 | UART/SWD pogo pads | P0 | Fit | Voltage domain clearly labelled (no 3.3V into 1.8V IO) |
| C042a | SW1 | Power/PWRKEY | P0 | Fit | First chip-down must recover from boot failure |
| C042b | SW2 | Reset | P0 | Fit | Bring-up |
| C042c | SW3 | MaskROM/Recovery | P0 | Fit | Bring-up (recover from bad boot) |

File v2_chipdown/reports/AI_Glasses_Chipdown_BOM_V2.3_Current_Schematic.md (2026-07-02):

# AI Glasses RK3576 Chip-down BOM V2.3
## Current schematic-aligned BOM, power, and layout-gate report

- Generated: 2026-07-01
- Source of truth: `v2_chipdown/scripts/chipdown_bom.py` and `v2_chipdown/config/power_budget_v2.yaml`
- Schematic: `v2_chipdown/hardware/ai_glasses_v2_chipdown.kicad_sch`
- Exported BOM/netlist/PDF: `v2_chipdown/reports/*`
- This report is schematic-aligned. If an older PDF disagrees with this document, use this document.

## 1. Read this first

| Item | Current value |
|---|---|
| Schematic scope | Pre-PCB-layout functional-block schematic |
| Components / nets | 93 components / 133 nets |
| Assembly states | DNP=16, Fit=57, HOLD=18, TBD=2 |
| Board split | R-Temple Compute Board=33, L-Temple AON/Power Board=9, Temple Rears (batt/spkr/ant)=19, Front Sensor Board=24, EVT Debug Tail=8 |
| ERC | Report includes: Errors, Warnings, Exclusions; ** ERC messages: 0  Errors 0  Warnings 0 |
| PCB layout release | NOT released; Gate 0/G00F/G05/G07/G08/G10/G12 still block layout |
| Phase 1.5 | Required mechanical/electrical floorplan before formal PCB layout |
| First EVT hinge stance | Hinge electrical interconnect is out of scope for Chip-down EVT V2.0; J4 hinge FPC has been removed from the schematic source |

Status legend: Fit = populate first build; DNP = land only; HOLD = candidate blocked by a gate; TBD = MPN/spec undecided.
Power numbers are project budget estimates until EVT shunt measurements replace them.

## 2. System power boundary

| Power state | Current load (mW) | Target band (mW) | Battery current @3.7 V | Runtime on LP451165 x2 1S2P |
|---|--:|--:|--:|--:|
| Deep Off (AON only, RK3576 down) | 22 | 20-50 | 6 mA | 91 h |
| Quick Standby (DDR retention / light sleep) | 134 | 80-200 | 36 mA | 15 h |
| Phone-assisted safety ID (blended) | 362 | 250-450 | 98 mA | 5.5 h (331 min) |
| Mixed motion use (blended) | 450 | <=500-800 | 122 mA | 4.4 h (266 min) |
| Record Active (1080p, ISP+encode) | 1290 | 1000-1500 | 349 mA | 1.5 h (93 min) |
| AI Burst (NPU + encode + Wi-Fi) | 2065 | 1500-2500 | 558 mA | 1.0 h (58 min) |

Recommended pack: LP451165 x2, 1S2P, 600 mAh / 2.22 Wh nominal, one cell per temple.
Baseline current model uses 1290 mW for continuous 1080p record and 2065 mW for AI burst.

## 3. Subsystem power model

| Subsystem | Domain | deep_off | quick_standby | phone_assist | mixed_active | record | ai_record |
|---|---|--:|--:|--:|--:|--:|--:|
| BLE MCU (nRF-class, always-on) | AON | 2 | 3 | 8 | 6 | 5 | 8 |
| Audio DSP / wake-word (always listening) | AON | 12 | 12 | 15 | 15 | 15 | 20 |
| IMU BMI270 (low-power) | AON | 1 | 1 | 1 | 1 | 1 | 1 |
| MEMS mic array (wake mic always; array when active) | AON | 3 | 3 | 6 | 6 | 8 | 10 |
| Fuel gauge + NTC + protection | AON | 1 | 1 | 1 | 1 | 1 | 1 |
| AON Buck quiescent + regulation loss | AON | 3 | 4 | 6 | 6 | 10 | 15 |
| RK3576 SoC + LPDDR4X + eMMC + PMIC | COMPUTE | 0 | 90 | 150 | 250 | 850 | 1500 |
| Custom 1080p camera (sensor + ISP share) | CAMERA | 0 | 0 | 0 | 30 | 250 | 300 |
| Wi-Fi (on-demand) | RADIO | 0 | 0 | 150 | 100 | 80 | 120 |
| Audio amp + speaker (avg) | AUDIO | 0 | 0 | 15 | 15 | 30 | 30 |
| Compute-island load switches / PMIC loss | COMPUTE | 0 | 20 | 10 | 20 | 40 | 60 |
| **TOTAL** | | **22** | **134** | **362** | **450** | **1290** | **2065** |

## 4. What changed from the attached PDF

- The Wi-Fi module is the current schematic part `U11 / C015 = FCU760KAAMD`, status HOLD.
- BQ25895 is now explicit as the primary charger + Power Path block; nPM1300 remains the AON low-power PMIC/gauge/rail manager.
- J4 hinge FPC has been removed: no hinge FPC footprint, no cross-hinge battery, MIPI, USB or audio wiring in EVT V2.0.
- J3 is the proposed 33-pin FH26W camera FPC connector; IMX415 is now drawn as a 4-lane target while its mechanical module remains HOLD/TBD.
- Wi-Fi/BLE share the main dual-band FPC antenna; the second FCU760K RF port is DNP/test only.
- The IMU is `U10 / C012 = BMI270`, status Fit.
- The current baseline power totals are 22 / 134 / 362 / 450 / 1290 / 2065 mW.
- The current BOM is not only C001-C045; it is 93 schematic components with expanded shunts, INA238 monitors, passives, load switches, charger/input protection, and C046 default-off pull-downs.
- C044 is expanded into RS1-RS9 plus U25-U33 current monitors; C045/C046 passives are explicit pre-layout controls.
- PCB layout is still not released; unresolved mechanical/battery/FPC/RF/camera/AON gates remain.
- A new Phase 1.5 floorplan is required between ERC-clean schematic and formal PCB layout.

## 5. Board and mechanical partition

| Region | Current schematic contents | EVT note |
|---|---|---|
| Front Sensor Board | IMX415 custom FPC module, 3 fitted T5837 mics, 4th mic DNP, camera rails, MIPI ESD, front FPC | Final module pinout/lens/lane count remains G10 HOLD |
| R-Temple Compute Board | RK3576, RK806S, LPDDR4X, eMMC, TPS61088, FCU760K Wi-Fi, Wi-Fi buck/load switch, MAX98360A audio | Heat and boost droop gates remain open |
| L-Temple AON/Power Board | nRF54L15, nPM1300, NDP120, BMI270, optional protection, main shunt/INA | AON average <=25 mW and ceiling <=50 mW must be measured |
| Temple Rears | LP451165 x2 pack envelopes, branch fuses/shunts, main speaker, shared Wi-Fi/BLE antenna, pogo, DNP RF/debug options | First EVT is fixed-temple electrically; no hinge FPC/cross-hinge harness in the released schematic |
| EVT Debug Tail | USB-C, ESD, CC resistors, SWD/UART pads, power/reset/recovery buttons | Bring-up only; production can hide/remove |

## 5.5. Phase 1.5 mechanical/electrical floorplan

Before formal PCB placement/routing, create a no-route fit floorplan. This is a CAD + EE deliverable, not a routed board.

| Required output | Contents |
|---|---|
| Right-temple top/side view | usable length/width/height; Compute PCB; RK3576/LPDDR/RK806/eMMC/Wi-Fi/BQ25895/boost-inductor zones; battery; speaker; shared Wi-Fi/BLE antenna keep-out; pogo; front FPC corridor; shell/foam/swell allowance |
| Left-temple top/side view | usable length/width/height; AON/power PCB; nRF/nPM/NDP/BMI270 zones; battery; no separate BLE antenna fitted; pogo/service clearance; shell/foam/swell allowance |
| KiCad no-route floorplan | board frames plus RK3576, LPDDR, RK806, eMMC, Wi-Fi, boost inductor, FPC connectors, battery 3D/envelope blocks, speaker and antenna keep-outs |
| Pass/fail decision | prove the current schematic architecture fits before routing; if not, change battery/partition/connectors/DNP features/local temple width |

Formal routing starts only after this floorplan passes. If it fails, do not route; change the architecture first.

## 6. Current BOM by board

### R-Temple Compute Board

| Ref | BOM ID | Value | Status | Pri | Package / footprint placeholder | Gate |
|---|---|---|:--:|:--:|---|---|
| U1 | C001 | RK3576 | Fit | P0 | AI_Glasses_V2:VERIFY_FCCSP698L_16x17 | G01 (RK3576 datasheet/HDG/ballmap/DDR guide) |
| U2 | C002 | RK806S-5 QFN68 7x7x0.90mm | HOLD | P0 | AI_Glasses_V2:VERIFY_QFN68_7x7_EP5.49_P0.35 | G03 (official RK806S-5 datasheet, OTP/default rails, sequence, layout guide) |
| U3 | C003 | Samsung K4U6E3S4AA-MGCL | HOLD | P0 | AI_Glasses_V2:VERIFY_FBGA200_0.65 | G02 (Samsung datasheet/ball map/IBIS + Rockchip DDR AVL/init + length report) |
| U4 | C004 | Samsung KLMAG1JENB-B041 | HOLD | P0 | AI_Glasses_V2:VERIFY_BGA153 | G04 (official Samsung datasheet/package + BSP boot/HS200 then HS400 validation) |
| Y1 | C005 | 24 MHz 10 ppm XTAL | Fit | P0 | AI_Glasses_V2:Crystal_SMD_3225 | G01 (reuse reference CL/ESR + placement distance per HDG) |
| U5 | C006 | MX25U6432F | DNP | P1 | AI_Glasses_V2:USON-8 | Boot flow decides whether production needs it |
| U6 | C007 | TPS61088 | HOLD | P0 | AI_Glasses_V2:VQFN-22_4.5x3.5 | G06/G09 (measured RK3576 boot+AI peak, soft-start, droop, thermal) |
| L1 | C008 | Coilcraft XGL4020-102MEC 1.0uH | HOLD | P0 | AI_Glasses_V2:VERIFY_L_4x4x2_XGL4020 | G06/G13 (Isat/DCR/thermal pass for 5.1V 3A continuous / 4A peak boost) |
| U11 | C015 | FCU760KAAMD | HOLD | P0 | AI_Glasses_V2:VERIFY_LCC_13x12.2_Quectel | G05 (Quectel HW Design + RK3576 BSP driver/firmware/enum) + official LCC land pattern |
| U12 | C016 | TPS62825 | Fit | P0 | AI_Glasses_V2:QFN_1.5x1.5 | G05/G06 (inductor/caps per module 353mA TX peak + ripple) |
| L2 | C016c | Wi-Fi buck inductor (TBD) | Fit | P0 | AI_Glasses_V2:VERIFY_L_2x2 | Per TPS62825 peak+ripple |
| U13 | C016b | TPS22917DBVR | Fit | P0 | Package_TO_SOT_SMD:SOT-23-5 | G05 (turn-on sequence w/ module) |
| C1 | C015-C | 47uF 6.3V X5R | Fit | P0 | AI_Glasses_V2:C_0805 | Local bulk per Quectel HW Design |
| RT3 | C043 | 10k NTC B=3435 | Fit | P0 | AI_Glasses_V2:R_0402 | Probe position per thermal sim |
| U35 | C010b | BQ25895 | HOLD | P0 | AI_Glasses_V2:VERIFY_WQFN_24_BQ25895 | Charger/power-path config, TS thresholds, 1S2P charge profile, thermal/current validation |
| U36 | C034b | 5V input eFuse/OVP (MPN TBD) | HOLD | P0 | AI_Glasses_V2:VERIFY_EFUSE_OVP | Select MPN for pogo/USB VBUS surge, reverse, OVP, current limit and thermal fault |
| U20 | C024 | MAX98360A | Fit | P0 | AI_Glasses_V2:VERIFY_WLP_QFN | Verify Z/cavity/EMI/peak power |
| U21 | C024b | TPS22917DBVR | Fit | P0 | Package_TO_SOT_SMD:SOT-23-5 | Amp must be fully power-downable (V1 lesson) |
| RS4 | C044-RSOC | 10 mohm 1% | Fit | P0 | AI_Glasses_V2:R_0805_shunt | 5-20 mohm (2A x 10m=20mV; avoid boost UVLO) |
| RS5 | C044-RWIFI | 50 mohm 1% | Fit | P0 | AI_Glasses_V2:R_0603_shunt | 20-100 mohm |
| RS6 | C044-RAUD | 50 mohm 1% | Fit | P0 | AI_Glasses_V2:R_0603_shunt | 20-100 mohm |
| U28 | C044c | INA238 (I_SOC_5V) | DNP | P1 | AI_Glasses_V2:VSSOP-10 | Power Gate - EVT-A only |
| U29 | C044e | INA238 (I_WIFI) | DNP | P1 | AI_Glasses_V2:VSSOP-10 | Power Gate - EVT-A only |
| U30 | C044f | INA238 (I_AUDIO) | DNP | P1 | AI_Glasses_V2:VSSOP-10 | Power Gate - EVT-A only |
| R11 | C046a | 100k | Fit | P0 | AI_Glasses_V2:R_0402 | Default OFF (section 4) |
| R12 | C046b | 100k | Fit | P0 | AI_Glasses_V2:R_0402 | Default OFF (section 4) |
| R16 | C046f | 100k | Fit | P0 | AI_Glasses_V2:R_0402 | Default OFF (section 4) |
| R17 | C046g | 100k | Fit | P0 | AI_Glasses_V2:R_0402 | Default OFF (section 4) |
| R18 | C046h | 100k | Fit | P0 | AI_Glasses_V2:R_0402 | Default OFF (section 4/section 9: FCU760K CHIP_EN default low) |
| R19 | C046i | 100k | Fit | P0 | AI_Glasses_V2:R_0402 | Default OFF (section 4) |
| R20 | C046j | 100k | Fit | P0 | AI_Glasses_V2:R_0402 | Default OFF (section 4) |
| R9 | C045e | 2.2k 1% | Fit | P0 | AI_Glasses_V2:R_0402 | Confirm vs SoC PMIC bus |
| R10 | C045f | 2.2k 1% | Fit | P0 | AI_Glasses_V2:R_0402 | Confirm vs SoC PMIC bus |

### L-Temple AON/Power Board

| Ref | BOM ID | Value | Status | Pri | Package / footprint placeholder | Gate |
|---|---|---|:--:|:--:|---|---|
| U7 | C009 | nRF54L15-QFN48 | Fit | P0 | AI_Glasses_V2:QFN-48_6x6 | EVT-frozen (RF layout/SDK/package to freeze early) |
| U8 | C010 | nPM1300 | HOLD | P0 | AI_Glasses_V2:QFN_5x5 | G08 (AON <=25/50mW) - configure via nPM PowerUP on EK before board |
| U9 | C011 | NDP120 | HOLD | P0 | AI_Glasses_V2:VERIFY_QFN_5x5 | Full datasheet + dev kit + measured listening power + NDA/licensing |
| U10 | C012 | BMI270 | Fit | P0 | Package_LGA:LGA-14_2.5x3mm_P0.5mm | Evaluate false-trigger under real frame vibration |
| U22 | C027 | DRV2605L | DNP | P1 | Package_SO:MSOP-10_3x3mm_P0.5mm | Vibration P1 - may DNP on first board (IMU/mic coupling) |
| RS1 | C044-RBAT | 10 mohm 1% 1W | Fit | P0 | AI_Glasses_V2:R_1206_shunt | I_BAT_TOTAL; the one production-kept sense path |
| U25 | C044a | INA238 (I_BAT_TOTAL) | DNP | P1 | AI_Glasses_V2:VSSOP-10 | Power Gate - EVT-A; production may keep this one |
| R3 | C045a | 2.2k 1% | Fit | P0 | AI_Glasses_V2:R_0402 | Confirm vs total AON bus capacitance |
| R4 | C045b | 2.2k 1% | Fit | P0 | AI_Glasses_V2:R_0402 | Confirm vs total AON bus capacitance |

### Temple Rears (batt/spkr/ant)

| Ref | BOM ID | Value | Status | Pri | Package / footprint placeholder | Gate |
|---|---|---|:--:|:--:|---|---|
| J6 | C018 | FCU760K ANT_BT DNP test pad | DNP | P0 | AI_Glasses_V2:VERIFY_ANT | Only populate if Quectel FAE + coexistence test requires the second RF port |
| J7 | C017 | Taoglas FXP840.07.0055B | HOLD | P0 | AI_Glasses_V2:VERIFY_FPC_ANT_14x5 | G14 (worn-state tune + antenna keep-out in full shell with battery/speaker) |
| LS1 | C025 | CUI CMS-15113-078SP-67 | HOLD | P0 | AI_Glasses_V2:VERIFY_SPK_15x11x3 | Acoustic EVT: 0.3-0.5cc cavity, port/foam seal, magnet-to-antenna clearance, leak test |
| LS2 | C026 | 2nd speaker pad | DNP | P1 | AI_Glasses_V2:VERIFY_SPK | Decide dual-speaker at EVT-B |
| M1 | C028 | LRA/ERM motor | DNP | P1 | AI_Glasses_V2:VERIFY_LRA | Vibration P1 |
| BT1 | C029 | LP451165 300mAh (R) | HOLD | P0 | AI_Glasses_V2:VERIFY_CELL_4.5x11x65 | G07 (full datasheet, >=2C, IR, cycles, cert) |
| BT2 | C030 | LP451165 300mAh (L) | HOLD | P0 | AI_Glasses_V2:VERIFY_CELL_70x12.8x5.6_maxenv | G07 |
| F1 | C031a | PTC/fuse (R branch) | TBD | P0 | AI_Glasses_V2:VERIFY_FUSE | Rating from peak-current calc (> branch peak, < FPC rating) |
| F2 | C031b | PTC/fuse (L branch) | TBD | P0 | AI_Glasses_V2:VERIFY_FUSE | Rating from peak-current calc |
| RS2 | C044-RCL | 10 mohm 1% | Fit | P0 | AI_Glasses_V2:R_0805_shunt | Branch current-share (section 7/section 29) |
| RS3 | C044-RCR | 10 mohm 1% | Fit | P0 | AI_Glasses_V2:R_0805_shunt | Branch current-share (section 7/section 29) |
| PCM1 | C032 | Supplier 1S2P pack PCM + protection FETs | HOLD | P0 | AI_Glasses_V2:PACK_INTERNAL_NO_BOARD_FOOTPRINT | Pack supplier drawing: OVP/UVP/OCP/SCP thresholds, FET Rds(on), current rating, NTC placement, UN38.3/MSDS/IEC62133 |
| RT1 | C033a | 10k NTC B=3435 1% (R cell) | Fit | P0 | AI_Glasses_V2:R_0402 | NTC curve/package/placement matched to pack supplier + BQ25895/nPM1300 config |
| RT2 | C033b | 10k NTC B=3435 1% (L cell) | Fit | P0 | AI_Glasses_V2:R_0402 | NTC curve/package/placement matched to pack supplier + ADC/config |
| TP2 | C033-TP | Battery test points | Fit | P0 | AI_Glasses_V2:TestPad_Set | Cell/pack voltage + NTC probe access (section 21) |
| J1 | C034 | CCP P2578MP01-06C180HT | HOLD | P0 | AI_Glasses_V2:VERIFY_POGO_6P_1.8MM | USB2 eye/contact validation, current/fault/ESD, mating STEP, corrosion/cycle life |
| J5 | C040 | U.FL / I-PEX MHF RF test connector | DNP | P0 | Connector_Coaxial:U.FL_Hirose_U.FL-R-SMT-1_Vertical | EVT RF debug only; production prefers direct coax or soldered antenna pigtail |
| U26 | C044-ICL | INA238 (I_CELL_L) | DNP | P1 | AI_Glasses_V2:VSSOP-10 | Power Gate - EVT-A only (current-share) |
| U27 | C044-ICR | INA238 (I_CELL_R) | DNP | P1 | AI_Glasses_V2:VSSOP-10 | Power Gate - EVT-A only (current-share) |

### Front Sensor Board

| Ref | BOM ID | Value | Status | Pri | Package / footprint placeholder | Gate |
|---|---|---|:--:|:--:|---|---|
| U14 | C019 | Sony IMX415-AAQR-C custom module | HOLD | P0 | AI_Glasses_V2:VERIFY_CAM_MODULE | G10 (module lens/FOV/FPC pinout/lane/supply/timing from vendor) |
| U15 | C020 | TPS62840 | Fit | P0 | AI_Glasses_V2:VERIFY_WSON | Output current/noise per final module (DVDD ~250mA max + margin) |
| L3 | C020b | Cam 1V1 buck inductor (TBD) | Fit | P0 | AI_Glasses_V2:VERIFY_L_1.6x0.8 | Per TPS62840 design |
| U16 | C021 | TLV75529PDRVR | Fit | P0 | AI_Glasses_V2:WSON-6_2x2 | Verify vs IMX415 AVDD peak (156mA) + PSRR |
| U17 | C022 | TPS22917DBVR | Fit | P0 | Package_TO_SOT_SMD:SOT-23-5 | Check reverse block, ramp, QOD, logic level |
| U18 | C023a | TPD4E05U06 | Fit | P0 | AI_Glasses_V2:USON | Low-cap array near FPC entry |
| U19 | C023b | TPD4E05U06 | Fit | P0 | AI_Glasses_V2:USON | Low-cap array near FPC entry |
| U34 | C023c | TPD4E05U06 | Fit | P0 | AI_Glasses_V2:USON | Low-cap array near FPC entry for 4-lane CSI |
| MK1 | C013a | T5837 (wake mic) | Fit | P0 | AI_Glasses_V2:LGA-5_3.5x2.65 | G11 (mic coords/ports/wind/wake + AEC/beamforming) |
| MK2 | C013b | T5837 (array mic 1) | Fit | P0 | AI_Glasses_V2:LGA-5_3.5x2.65 | G11 |
| MK3 | C013c | T5837 (array mic 2) | Fit | P0 | AI_Glasses_V2:LGA-5_3.5x2.65 | G11 |
| MK4 | C014 | T5837 (4th mic) | DNP | P1 | AI_Glasses_V2:LGA-5_3.5x2.65 | G11 (populate only if array sim/proto needs it) |
| J3 | C038 | Hirose FH26W-33S-0.3SHW(97) | HOLD | P0 | AI_Glasses_V2:VERIFY_FH26W_33S_0.3SHW | G10/G12 (camera module vendor signs 33-pin pinout, contact orientation, impedance) |
| RS7 | C044-RC1 | 100 mohm 1% | Fit | P0 | AI_Glasses_V2:R_0603_shunt | Per-rail Kelvin (section 23/section 29); DVDD ~250mA |
| RS8 | C044-RC8 | 100 mohm 1% | Fit | P0 | AI_Glasses_V2:R_0402_shunt | Per-rail Kelvin (section 23/section 29); IOVDD ~3mA |
| RS9 | C044-RC29 | 100 mohm 1% | Fit | P0 | AI_Glasses_V2:R_0603_shunt | Per-rail Kelvin (section 23/section 29); AVDD ~156mA |
| U31 | C044-IC1 | INA238 (I_CAM_1V1) | DNP | P1 | AI_Glasses_V2:VSSOP-10 | Power Gate - EVT-A only |
| U32 | C044-IC8 | INA238 (I_CAM_1V8) | DNP | P1 | AI_Glasses_V2:VSSOP-10 | Power Gate - EVT-A only |
| U33 | C044-IC29 | INA238 (I_CAM_2V9) | DNP | P1 | AI_Glasses_V2:VSSOP-10 | Power Gate - EVT-A only |
| R13 | C046c | 100k | Fit | P0 | AI_Glasses_V2:R_0402 | Default OFF (section 4) |
| R14 | C046d | 100k | Fit | P0 | AI_Glasses_V2:R_0402 | Default OFF (section 4) |
| R15 | C046e | 100k | Fit | P0 | AI_Glasses_V2:R_0402 | Default OFF (section 4) |
| R5 | C045c | 2.2k 1% | Fit | P0 | AI_Glasses_V2:R_0402 | Confirm vs camera bus capacitance |
| R6 | C045d | 2.2k 1% | Fit | P0 | AI_Glasses_V2:R_0402 | Confirm vs camera bus capacitance |

### EVT Debug Tail

| Ref | BOM ID | Value | Status | Pri | Package / footprint placeholder | Gate |
|---|---|---|:--:|:--:|---|---|
| J2 | C035 | USB-C 16p USB2-only | Fit | P0 | AI_Glasses_V2:USB_C_16P_MidMount | Connector height + shell opening co-freeze |
| U24 | C036 | TPD2E001 | Fit | P0 | Package_TO_SOT_SMD:SOT-23-3 | Keep ~90 ohm diff + continuous ref gnd |
| R1 | C037a | 5.1k 1% | Fit | P0 | AI_Glasses_V2:R_0402 | USB-C spec |
| R2 | C037b | 5.1k 1% | Fit | P0 | AI_Glasses_V2:R_0402 | USB-C spec |
| TP1 | C041 | UART/SWD pogo pads | Fit | P0 | AI_Glasses_V2:TestPad_Set | Voltage domain clearly labelled (no 3.3V into 1.8V IO) |
| SW1 | C042a | Power/PWRKEY | Fit | P0 | Button_Switch_SMD:SW_Push_1P1T_NO_CK_KMR2 | First chip-down must recover from boot failure |
| SW2 | C042b | Reset | Fit | P0 | Button_Switch_SMD:SW_Push_1P1T_NO_CK_KMR2 | Bring-up |
| SW3 | C042c | MaskROM/Recovery | Fit | P0 | Button_Switch_SMD:SW_Push_1P1T_NO_CK_KMR2 | Bring-up (recover from bad boot) |
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

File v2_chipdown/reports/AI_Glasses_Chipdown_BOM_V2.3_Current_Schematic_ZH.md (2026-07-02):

# AI Glasses RK3576 Chip-down BOM V2.3 中文版
## 与当前 schematic 对齐的 BOM、功耗和 layout gate 报告

- 生成日期：2026-07-01
- Source of truth：`v2_chipdown/scripts/chipdown_bom.py` 与 `v2_chipdown/config/power_budget_v2.yaml`
- Schematic：`v2_chipdown/hardware/ai_glasses_v2_chipdown.kicad_sch`
- 导出 BOM/netlist/PDF：`v2_chipdown/reports/*`
- 如果旧 PDF 和本文件冲突，以本文件和当前 schematic 为准。
- 注意：MPN、refdes、BOM ID、net name 保留英文，避免和 KiCad/schematic 不一致。

## 1. 优先阅读

| 项目 | 当前值 |
|---|---|
| schematic 范围 | PCB layout 之前的 functional-block schematic |
| 元件 / 网络 | 98 components / 137 nets |
| 装配状态 | DNP=21, Fit=58, HOLD=17, TBD=2 |
| 板卡分区 | 右镜腿 Compute Board=33, 左镜腿 AON/Power Board=15, 镜腿后端电池/扬声器/天线区=18, 前框 Sensor Board=24, EVT 调试尾板=8 |
| ERC | Report includes: Errors, Warnings, Exclusions; ** ERC messages: 0  Errors 0  Warnings 0 |
| PCB layout release | 还没有 release；Gate 0/G00F/G05/G07/G08/G10/G12 仍阻塞 layout |
| Phase 1.5 | 正式 PCB layout 前必须完成 Mechanical/Electrical Floorplan |
| 第一版铰链口径 | Chip-down EVT V2.0 不包含铰链电气连接；J4 hinge FPC 已从 schematic source 删除 |

状态定义：Fit=首版贴装；DNP=只留焊盘不贴；HOLD=候选件但门禁未关闭；TBD=型号/规格待定。
功耗数字是项目预算模型，还不是 EVT bench 实测；后续必须用分域 shunt 数据替换。

## 2. 系统功耗边界

| 工作状态 | 当前负载 (mW) | 目标区间 (mW) | 3.7V 电池电流 | LP451165 x2 1S2P 续航 |
|---|--:|--:|--:|--:|
| 深度待机(AON only, RK3576 off) | 22 | 20-50 | 6 mA | 91 h |
| 快速待机(DDR retention / light sleep) | 134 | 80-200 | 36 mA | 15 h |
| 手机协作识别(blended) | 362 | 250-450 | 98 mA | 5.5 h (331 min) |
| 混合运动使用(blended) | 450 | <=500-800 | 122 mA | 4.4 h (266 min) |
| 连续 1080p 录像 | 1290 | 1000-1500 | 349 mA | 1.5 h (93 min) |
| 录像 + 本地 AI Burst | 2065 | 1500-2500 | 558 mA | 1.0 h (58 min) |

推荐电池包：LP451165 x2，1S2P，600 mAh / 2.22 Wh nominal，左右镜腿各一颗。
当前 baseline 模型：连续 1080p 录像为 1290 mW，AI Burst 为 2065 mW。
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

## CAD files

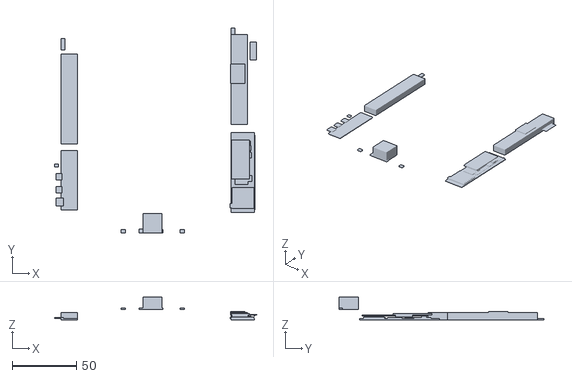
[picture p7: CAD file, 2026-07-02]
v2_chipdown/mechanical_3d/export/glasses_assembly.stl
156.7 x 159.0 x 17.5

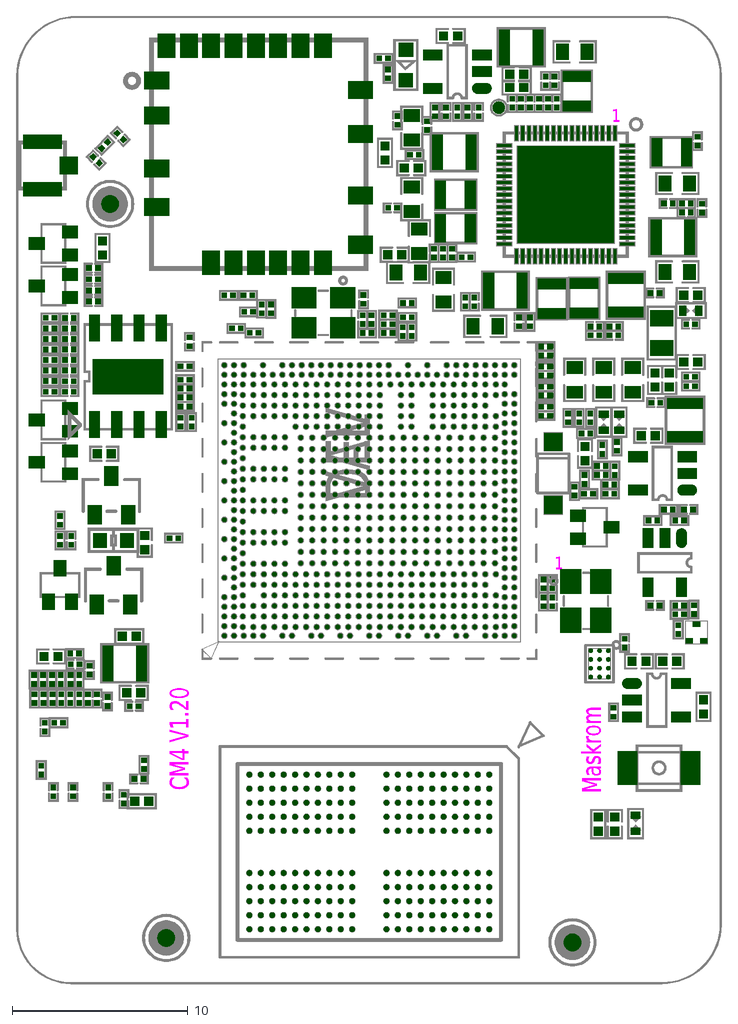
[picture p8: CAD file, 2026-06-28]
mechanical/radxa_cm4_2d_dxf_v1.20/Radxa CM4 V1.20 TOP.dxf
CM4 V1.20
1
Maskrom
VAL
DEV

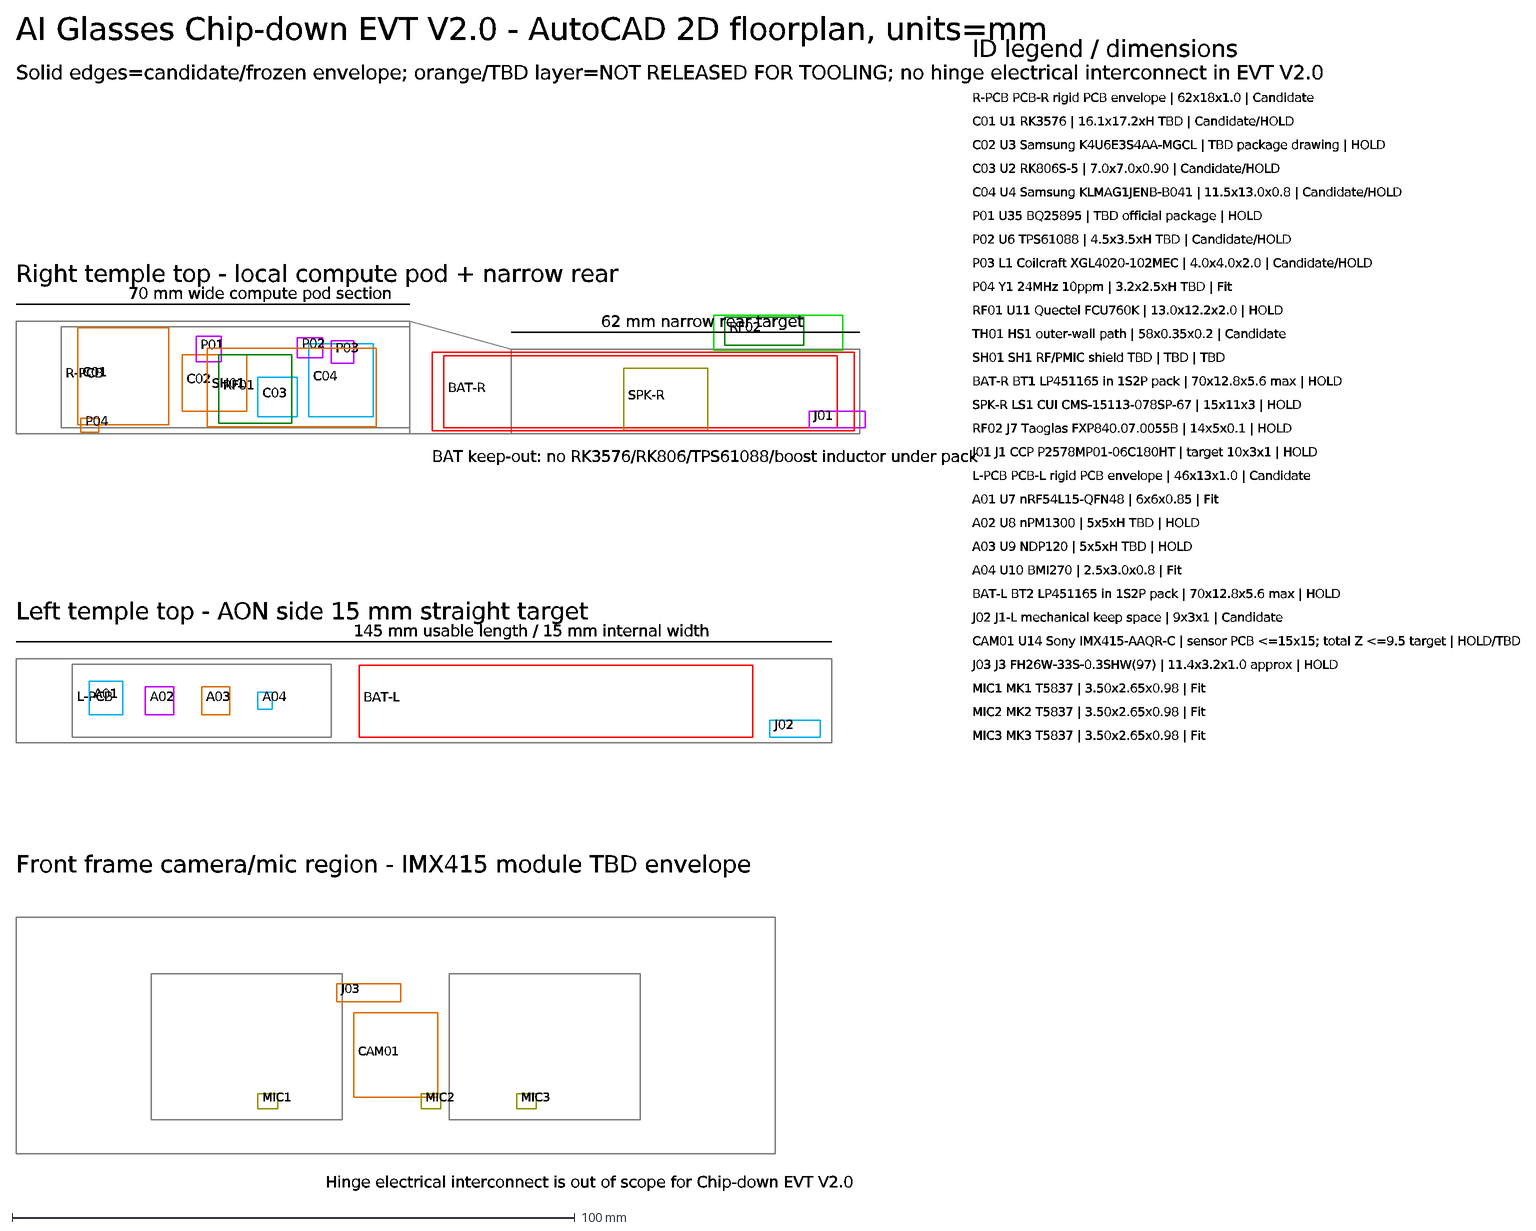
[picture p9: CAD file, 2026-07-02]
v2_chipdown/mechanical_3d/export/autocad_floorplan_2d.dxf
AI Glasses Chip-down EVT V2.0 - AutoCAD 2D floorplan, units=mm
Solid edges=candidate/frozen envelope; orange/TBD layer=NOT RELEASED FOR TOOLING; no hinge electrical interconnect in EVT V2.0
Right temple top - local compute pod + narrow rear
R-PCB
C01
C02
C03
C04
P01
P02
P03
P04
RF01
SH01
BAT-R
SPK-R
RF02
J01
BAT keep-out: no RK3576/RK806/TPS61088/boost inductor under pack
70 mm wide compute pod section
62 mm narrow rear target
Left temple top - AON side 15 mm straight target
L-PCB
A01
A02
A03
A04
BAT-L
J02
145 mm usable length / 15 mm internal width
Front frame camera/mic region - IMX415 module TBD envelope
CAM01
J03
MIC1
MIC2
MIC3
Hinge electrical interconnect is out of scope for Chip-down EVT V2.0
ID legend / dimensions
R-PCB PCB-R rigid PCB envelope | 62x18x1.0 | Candidate
C01 U1 RK3576 | 16.1x17.2xH TBD | Candidate/HOLD
C02 U3 Samsung K4U6E3S4AA-MGCL | TBD package drawing | HOLD
C03 U2 RK806S-5 | 7.0x7.0x0.90 | Candidate/HOLD
C04 U4 Samsung KLMAG1JENB-B041 | 11.5x13.0x0.8 | Candidate/HOLD
P01 U35 BQ25895 | TBD official package | HOLD
P02 U6 TPS61088 | 4.5x3.5xH TBD | Candidate/HOLD
P03 L1 Coilcraft XGL4020-102MEC | 4.0x4.0x2.0 | Candidate/HOLD
P04 Y1 24MHz 10ppm | 3.2x2.5xH TBD | Fit
RF01 U11 Quectel FCU760K | 13.0x12.2x2.0 | HOLD
TH01 HS1 outer-wall path | 58x0.35x0.2 | Candidate
SH01 SH1 RF/PMIC shield TBD | TBD | TBD
BAT-R BT1 LP451165 in 1S2P pack | 70x12.8x5.6 max | HOLD
SPK-R LS1 CUI CMS-15113-078SP-67 | 15x11x3 | HOLD
RF02 J7 Taoglas FXP840.07.0055B | 14x5x0.1 | HOLD
J01 J1 CCP P2578MP01-06C180HT | target 10x3x1 | HOLD
L-PCB PCB-L rigid PCB envelope | 46x13x1.0 | Candidate
A01 U7 nRF54L15-QFN48 | 6x6x0.85 | Fit
A02 U8 nPM1300 | 5x5xH TBD | HOLD
A03 U9 NDP120 | 5x5xH TBD | HOLD
A04 U10 BMI270 | 2.5x3.0x0.8 | Fit
BAT-L BT2 LP451165 in 1S2P pack | 70x12.8x5.6 max | HOLD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

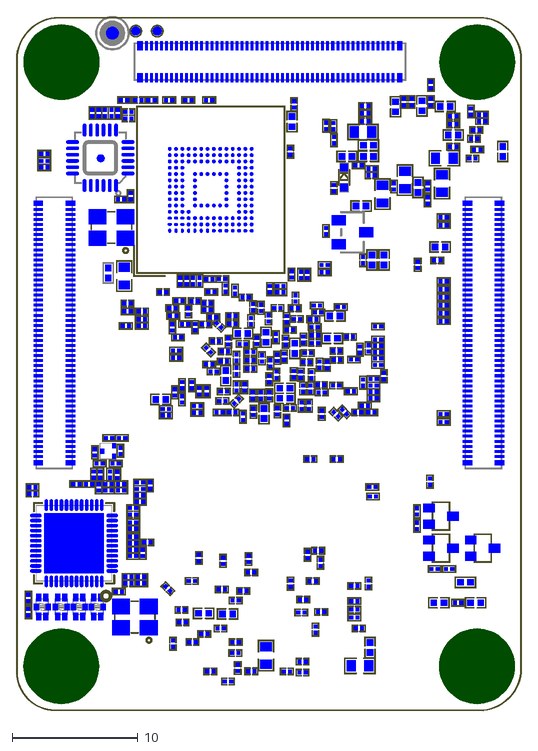
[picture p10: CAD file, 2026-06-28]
mechanical/radxa_cm4_2d_dxf_v1.20/Radxa CM4 V1.20 BOT.dxf
40.1 x 55.2

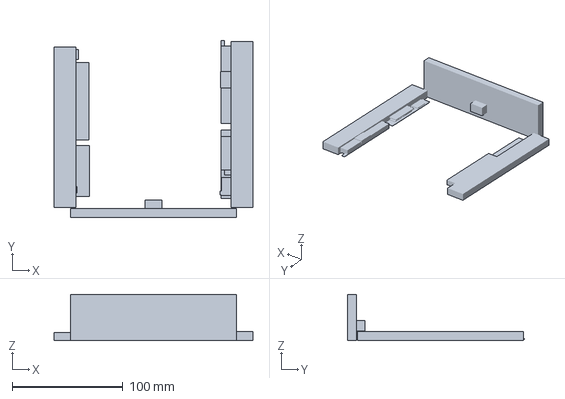
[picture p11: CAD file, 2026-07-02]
v2_chipdown/mechanical_3d/export/autocad_envelopes_3d.dxf
180.0 x 160.0 x 42.0 mm

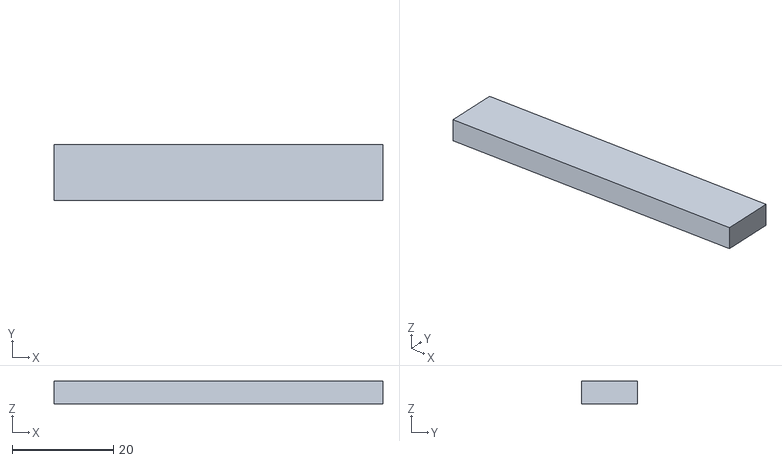
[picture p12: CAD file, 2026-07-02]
AI_Glasses_HOLD_Closure_Pack/06_Mechanical_Fit_Check/LP451165_nominal_cell_65x11x4p5mm.stl
65.0 x 11.0 x 4.50

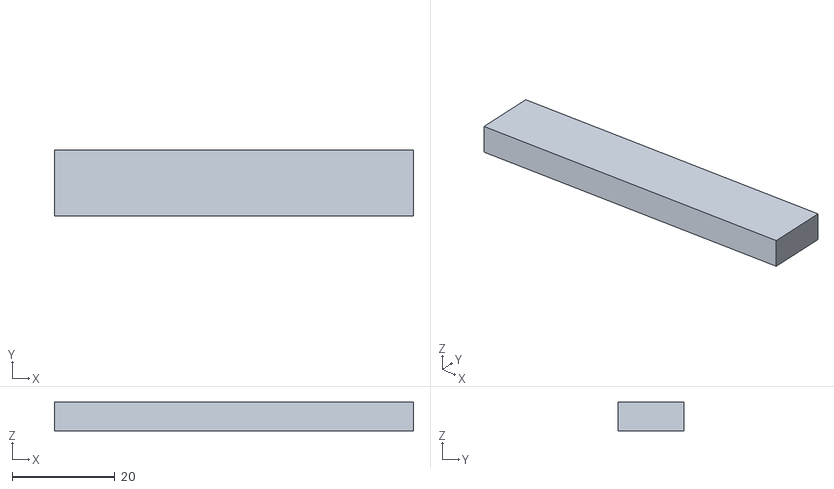
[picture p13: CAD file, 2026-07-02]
AI_Glasses_HOLD_Closure_Pack/06_Mechanical_Fit_Check/LP451165_clearance_envelope_70x12p8x5p6mm.stl
70.0 x 12.8 x 5.60

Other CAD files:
mechanical/radxa_cm4_io_2d_dxf_v1.10/RC126_V1.10_20250526_BOT.dxf

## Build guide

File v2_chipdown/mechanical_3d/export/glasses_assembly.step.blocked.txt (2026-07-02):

FreeCAD/freecadcmd command not found; STEP export cannot be generated on this machine.

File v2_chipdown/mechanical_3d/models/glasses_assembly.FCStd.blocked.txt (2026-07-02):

FreeCAD/freecadcmd command not found; FCStd cannot be generated on this machine.

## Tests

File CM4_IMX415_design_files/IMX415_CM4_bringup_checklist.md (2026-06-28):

# IMX415 on Radxa CM4 Bring-up Checklist

## 1. Hardware evidence
- [x] Camera module is confirmed as Radxa Camera 4K, not only a generic IMX415 board.
- [x] 31-pin FPC pinout saved in repository.
- [x] Four MIPI data pairs and one clock pair mapped to one valid 4-lane CM4 CSI receiver.
- [x] I2C bus, MCLK and RESET mapped to real CM4 pins; no PWDN pin exists in the Radxa Camera 4K 31-pin pinout.
- [x] Control-signal voltage domain confirmed as 1.8 V in the schematic plan.
- [x] J2 3.3 V and 5 V supply pins are connected in the schematic.
- [ ] DEFERRED_TO_PRE_LAYOUT: Pin 1 physical side and FPC contact side confirmed from real hardware/mechanical drawing.
- [ ] DEFERRED_TO_PRE_LAYOUT: AC006 physical validation, insertion direction, 1:1 print, coupon test, and FPC bend/enclosure path.
- [ ] EVT: 3.3 V and 5 V module power current budget measured on hardware.

## 2. Device Tree evidence
Required camera node properties normally include:
- compatible = "sony,imx415"
- reg / I2C address
- clocks / clock-names
- reset-gpios and optional pwdn-gpios
- power supplies if controlled by Linux
- port / endpoint
- data-lanes = <1 2 3 4> or board-specific ordering
- remote-endpoint to CSI2 DPHY / CIF / ISP path

Do not copy a ROCK 5 ITX overlay unchanged. Adapt its I2C controller, GPIOs, clock source, CSI endpoint and lane order to CM4.

Official CM4 IO overlay now confirmed:
- file: radxa-cm4-io-radxa-camera-4k.dtbo
- menu: Enable Radxa Camera 4K
- compatible board target: radxa,cm4-io
- sensor: IMX415
- I2C address: 0x1a
- data lanes: 4
- D-PHY endpoint: csi2_dphy3

## 3. Image-side verification commands
```bash
modinfo imx415 2>/dev/null || true
find /boot -iname '*imx415*' -o -iname '*camera*4k*'
find /usr/lib/firmware -iname '*imx415*' 2>/dev/null
find /usr/lib -iname '*imx415*' 2>/dev/null
sudo dmesg | grep -Ei 'imx415|rkisp|rkcif|csi|dphy|camera'
media-ctl -p
v4l2-ctl --list-devices
```

## 4. Functional test
Start with 1080p30 rather than immediately demanding 4K:
```bash
gst-launch-1.0 v4l2src device=/dev/videoX io-mode=4 \
  ! video/x-raw,width=1920,height=1080,framerate=30/1 \
  ! videoconvert ! autovideosink
```

Then test capture, encoding, frame drops, temperature and power.

## 5. Pass criteria
- [ ] Sensor identified by I2C without repeated timeout/NACK.
- [ ] MIPI D-PHY locks with no persistent CRC/ECC errors.
- [ ] 1080p30 stable for at least 30 minutes.
- [ ] 4K mode stable at required frame rate.
- [ ] ISP IQ/tuning file loaded or documented as missing.
- [ ] No lane-order workaround left undocumented.

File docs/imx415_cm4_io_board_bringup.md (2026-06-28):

# IMX415 Bring-up on Official Radxa CM4 IO Board

Date: 2026-06-28

Goal: use the official Radxa CM4 IO Board as the first software bring-up platform for Radxa Camera 4K / Sony IMX415 before the custom carrier PCB is manufactured.

## Sources

- Radxa Camera 4K official page: https://docs.radxa.com/en/accessories/camera/camera-4k
- Radxa ROCK 5 ITX camera tutorial: https://docs.radxa.com/en/rock5/rock5itx/getting-started/interface-usage/camera
- Local camera pinout: `CM4_IMX415_design_files/Radxa_Camera_4K_31pin_pinout.csv`
- Local CM4 IO schematic: `CM4_IMX415_design_files/radxa_cm4_io_schematic_v1.10.pdf`
- Local CM4 pinout source: `data/radxa_cm4_pinout_v1.20.xlsx`

The ROCK 5 ITX tutorial is useful because it documents Radxa Camera 4K / IMX415 overlay enablement and GStreamer test commands. It is not proof that the same overlay applies unchanged to CM4.

## Official CM4 IO Overlay Now Confirmed

- Overlay file: `radxa-cm4-io-radxa-camera-4k.dtbo`
- `rsetup` menu title: `Enable Radxa Camera 4K`
- Official source target: `radxa,cm4-io`
- Sensor: IMX415
- I2C address: `0x1a`
- MIPI data lanes: 4
- CSI D-PHY endpoint: `csi2_dphy3`

This confirms that the official CM4 IO Board path exists. It does not close the custom carrier bring-up gate until we capture the actual `dmesg`, media graph and V4L2 node output on hardware.

## Bring-up Plan

1. Boot Radxa CM4 on the official CM4 IO Board with the latest supported Radxa OS image for this CM4 SKU.
2. Connect Radxa Camera 4K using the correct 31-pin camera path and contact orientation for the IO Board.
3. Use `rsetup` and enable `Enable Radxa Camera 4K`, which maps to `radxa-cm4-io-radxa-camera-4k.dtbo`.
4. Reboot, then inspect kernel, media graph, I2C and V4L2 state.
5. Capture 1080p first, then 4K modes.
6. Record the exact overlay name, kernel version, `/boot` DTBO path, detected I2C address, media graph, and `/dev/videoX` node.

## Commands to Run on the CM4 IO Board

```bash
uname -a
cat /etc/os-release

sudo rsetup

find /boot -iname '*imx415*' -o -iname '*camera*4k*' -o -iname '*cam*4k*'
find /usr/lib/firmware -iname '*imx415*' 2>/dev/null
find /usr/lib -iname '*imx415*' 2>/dev/null

modinfo imx415 2>/dev/null || true
sudo dmesg | grep -Ei 'imx415|rkisp|rkcif|csi|dphy|camera|mipi'

media-ctl -p
v4l2-ctl --list-devices
v4l2-ctl --list-formats-ext --device=/dev/videoX
```

Replace `/dev/videoX` with the actual node found from `v4l2-ctl --list-devices`.

Start with 1080p:

```bash
gst-launch-1.0 v4l2src device=/dev/videoX io-mode=4 \
  ! video/x-raw,width=1920,height=1080,framerate=30/1 \
  ! videoconvert ! autovideosink
```

Then test the Radxa tutorial style pipeline if the node and formats match:

```bash
gst-launch-1.0 v4l2src device=/dev/videoX io-mode=4 \
  ! videoconvert \
  ! video/x-raw,format=NV12,width=1920,height=1080 \
  ! xvimagesink
```

## Overlay Migration Notes for Our Carrier

The custom carrier overlay must match the schematic sources:

- I2C: `I2C0_M1`, CM4 pins 80/82, 1.8 V, board nets `CAM_I2C_SCL` / `CAM_I2C_SDA`.
- MCLK: `MIPI_CSI3_CAM_CLKOUT_1V8`, CM4 pin 59, function `CAM_CLK2_OUT_M0`, board net `CAM_MCLK`.
- Reset: `MIPI_CAM3_PDN_1V8`, CM4 pin 143, function `GPIO3_C5`, board net `CAM_RST_n`, active-low.
- CSI lanes: FPC `MDP1/MDN1` -> CSI3 D0, `MDP2/MDN2` -> CSI3 D1, `MDP3/MDN3` -> CSI3 D2, `MDP4/MDN4` -> CSI3 D3.
- Data-lane ordering in Device Tree must match `docs/csi3_imx415_audit_2026-06-28.md`.
- The local 31-pin Radxa Camera 4K pinout has RESET but no PWDN pin.

## Pass Criteria

- IMX415 probe succeeds on I2C without repeated NACK or timeout.
- Media graph shows a complete IMX415 -> CSI DPHY -> CIF/ISP path.
- D-PHY locks without persistent CRC/ECC errors in `dmesg`.
- 1080p30 runs for 30 minutes.
- Target 4K mode works at the required frame rate.
- Power measurements capture camera idle, streaming and mode-switch peaks.

## Information to Copy Back Into This Repo

- OS image name and kernel version.
- Exact overlay/DTBO filename and any edits.
- `dmesg` camera section.
- `media-ctl -p` output.
- `v4l2-ctl --list-devices` and format listing.
- First working GStreamer command.
- Whether reset GPIO polarity needed inversion.

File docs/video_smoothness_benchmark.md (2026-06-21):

# Video Smoothness Benchmark

This project records camera output as JPEG frames or as a raw single-file MJPEG stream. The XIAO ESP32S3 Sense does not have an H.264 encoder, so MP4 files are produced on the Mac after recording.

## Firmware Commands

- `i`: print board, heap, PSRAM, SD, BLE, and profile information.
- `r`: record one clip with the recommended baseline profile.
- `b`: run the benchmark suite across all configured profiles.

The commands work over both USB Serial and BLE. BLE only returns short status strings; full benchmark data is printed over Serial and written to CSV on the SD card.

## Profiles

| Profile | Resolution | JPEG quality | Target FPS | SD SPI | Storage |
| --- | --- | ---: | ---: | ---: | --- |
| A | 320x240 | 15 | 10 | 10 MHz | Separate JPEG files |
| B | 320x240 | 15 | 15 | 20 MHz | Separate JPEG files |
| C | 320x240 | 20 | 20 | 20 MHz | Separate JPEG files |
| D | 640x480 | 15 | 10 | 20 MHz | Separate JPEG files |
| E | 320x240 | 15 | 10 | 20 MHz | Single-file MJPEG |

The firmware falls back to 10 MHz if SD initialization at a higher frequency fails. If write errors occur at a higher frequency, it remounts at 10 MHz for future operations.

## Output Files

Separate JPEG mode:

```text
/clip_0007/
  frame_0001.jpg
  frame_0002.jpg
  clip_info.csv
  frame_timing.csv
```

Single-file MJPEG mode:

```text
/clip_0010.mjpeg
/clip_0010_info.csv
/clip_0010_timing.csv
```

`frame_timing.csv` is written after the recording finishes, not during the recording loop, so the measurement system does not add per-frame SD writes.

## Metrics To Check

Use:

```bash
python3 scripts/analyze_clip_metrics.py /Volumes/UNTITLED\ 2/clip_0007
python3 scripts/analyze_clip_metrics.py /Volumes/UNTITLED\ 2/clip_0010_info.csv
```

Important fields:

- `actual_fps`
- `interval_us_p95`
- `capture_us_p95`
- `sd_write_us_p95`
- `jpeg_size_bytes_avg`
- `throughput_kb_s`
- `missed_deadlines`
- `longest_stall_us`

## MP4 Conversion Modes

### Constant Frame Rate

Use this for normal viewing. It distributes the captured frames evenly over time and usually looks smoother:

```bash
ffmpeg -framerate 10 -i frame_%04d.jpg -c:v libx264 -pix_fmt yuv420p clip_0007.mp4
```

For `.mjpeg`:

```bash
ffmpeg -framerate 10 -f mjpeg -i clip_0010.mjpeg -c:v libx264 -pix_fmt yuv420p clip_0010.mp4
```

The macOS auto-convert script uses this CFR approach and reads `actual_average_fps` from the clip CSV when it is available.

### Variable Frame Rate

Use this for timing analysis. Generate a concat manifest from `frame_timing.csv` where each frame duration matches the real capture interval, then run ffmpeg with concat demuxer. This preserves jitter instead of smoothing it.

```text
file 'frame_0001.jpg'
duration 0.101
file 'frame_0002.jpg'
duration 0.097
```

This is useful for debugging camera or SD stalls, not for normal viewing.

## Pass Criteria

Baseline QVGA 10 FPS should aim for:

- 30 seconds or longer stable recording
- Actual FPS at least 9.5
- Failed writes = 0
- Corrupt JPEGs = 0
- Continuous frame numbering
- P95 frame interval <= 120 ms
- Maximum stall preferably below 250 ms

Higher-FPS profiles should only be promoted if they meet the same correctness requirements and maintain at least 95% of their target FPS.

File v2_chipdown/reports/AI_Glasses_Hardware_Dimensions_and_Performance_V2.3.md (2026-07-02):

# AI Glasses Hardware Dimensions and Performance V2.3

Generated: 2026-07-01

This report is generated from the current schematic/BOM plus the single mechanical database. Current schematic wins over older PDFs. Numbers without official package drawings remain HOLD/TBD/PROVISIONAL.

## Executive Summary

- Normal thin optical frames do not fit this RK3576 chip-down architecture.
- Thick smart-glasses / sports-sunglasses temples can conditionally fit if Phase 1.5 envelopes are met.
- AON and compute boards intentionally contain multiple ICs: they are real PCB assemblies, not overlapping solid objects.
- Current PCB layout is not released. KiCad currently has no V2 `.kicad_pcb`; DRC is not applicable yet.
- The biggest risks before PCB layout are battery/FPC current safety, DDR/HDI routability, antenna keep-out, camera module choice, and Z-height tolerance stack.

## Current Power States

| State | Current model | Target / use case |
|---|---:|---|
| Deep Off / AON only | 22 mW | target 20-50 mW |
| Quick Standby | 134 mW | DDR/light standby model |
| Phone-assisted safety ID | 362 mW | 3-5 h blended target |
| Mixed motion use | 450 mW | target <=500-800 mW |
| Continuous 1080p record | 1290 mW | 45-90 min product target |
| AI + record burst | 2065 mW | 30-60 min / short burst target |

## Frozen / Open Dimension Summary

| Ref | MPN / item | Board | Dims | Status | Source | Next action |
|---|---|---|---|---|---|---|
| U1 | RK3576 | R-Temple Compute Board | 16.1 x 17.2 x TBD mm | HOLD | RK3576 Brief Datasheet file | G01 (RK3576 datasheet/HDG/ballmap/DDR guide) |
| U2 | RK806S-5 | R-Temple Compute Board | TBD | HOLD | AI Glasses Hardware Dimensions V2.3 | G03 (RK806S MPN/inductors/caps/timing per Radxa/Rockchip FAE) |
| U3 | LPDDR4X 4 GB MPN TBD | R-Temple Compute Board | TBD | HOLD | AI Glasses Hardware Dimensions V2.3 | G02 (LPDDR4X MPN/topology/placement, DDR review + length report) |
| U4 | 32 GB eMMC 5.1 MPN TBD | R-Temple Compute Board | TBD | HOLD | AI Glasses Hardware Dimensions V2.3 | G04 (eMMC MPN + BSP/bootloader; cold-boot + power-loss recovery) |
| U11 | FCU760KAAMD | R-Temple Compute Board | 13.0 x 12.2 x 2.0 mm | HOLD | Quectel FCU760K Short Specification | G05 (Quectel HW Design + RK3576 BSP driver/firmware/enum) + official LCC land pattern |
| U6 | TPS61088 | R-Temple Compute Board | 4.5 x 3.5 x TBD mm | HOLD | AI Glasses Hardware Dimensions V2.3 | G06/G09 (measured RK3576 boot+AI peak, soft-start, droop, thermal) |
| L1 | shielded low-DCR power inductor TBD | R-Temple Compute Board | 5.0 x 5.0 x 2.0 mm | TBD | AI Glasses Hardware Dimensions V2.3 | G06/G13 (Isat covers boot+AI peak; height <=2mm; thermal) |
| U12 | TPS62825 | R-Temple Compute Board | 1.5 x 1.5 x TBD mm | PROVISIONAL | AI Glasses Hardware Dimensions V2.3 | G05/G06 (inductor/caps per module 353mA TX peak + ripple) |
| U20 | MAX98360A | R-Temple Compute Board | TBD | PROVISIONAL | AI Glasses Hardware Dimensions V2.3 | Verify Z/cavity/EMI/peak power |
| Y1 | 24 MHz 10 ppm crystal TBD | R-Temple Compute Board | 3.2 x 2.5 x TBD mm | PROVISIONAL | AI Glasses Hardware Dimensions V2.3 | G01 (reuse reference CL/ESR + placement distance per HDG) |
| U5 | MX25U6432F | R-Temple Compute Board | TBD | DNP | AI Glasses Hardware Dimensions V2.3 | Boot flow decides whether production needs it |
| BT1 | LP451165 300 mAh | Temple Rears (batt/spkr/ant) | 70.0 x 12.8 x 5.6 mm | HOLD | LP451165 Battery Bay Fit Check | G07 (full datasheet, >=2C, IR, cycles, cert) |
| LS1 | 8 ohm 0.5-1 W micro speaker TBD | Temple Rears (batt/spkr/ant) | TBD | TBD | Current V2 generated schematic/BOM master | MPN after acoustic cavity/volume/leak test |
| J1 | magnetic pogo 4-6 pin TBD | Temple Rears (batt/spkr/ant) | 10.0 x 3.0 x TBD mm | TBD | AI Glasses Hardware Dimensions V2.3 | Magnet direction, sweat corrosion, short, cycle life |
| J3 | FH26W series pin count TBD | Front Sensor Board | 12.0 x 3.5 x 1.0 mm | HOLD | AI Glasses Hardware Dimensions V2.3 | G12 (pin count from final cam lane/mic/power split) |
| J4 | custom 6-10 mm FPC / rigid-flex TBD | Temple Rears (batt/spkr/ant) | TBD x 6-10 x 0.10-0.18 mm | HOLD | AI Glasses Hardware Dimensions V2.3 | G12 (impedance, bend radius, life, hinge interference) |
| U7 | nRF54L15 QFN48 candidate | L-Temple AON/Power Board | 6.0 x 6.0 x 0.85 mm | PROVISIONAL | AI Glasses Hardware Dimensions V2.3 | EVT-frozen (RF layout/SDK/package to freeze early) |
| U8 | nPM1300 | L-Temple AON/Power Board | 5.0 x 5.0 x TBD mm | HOLD | AI Glasses Hardware Dimensions V2.3 | G08 (AON <=25/50mW) — configure via nPM PowerUP on EK before board |
| U9 | NDP120 QFN40 candidate | L-Temple AON/Power Board | 5.0 x 5.0 x TBD mm | HOLD | Syntiant NDP120 Product Brief | Full datasheet + dev kit + measured listening power + NDA/licensing |
| U10 | BMI270 | L-Temple AON/Power Board | 2.5 x 3.0 x 0.8 mm | PROVISIONAL | AI Glasses Hardware Dimensions V2.3 | Evaluate false-trigger under real frame vibration |
| U23 | BQ2970/BQ297xx suffix TBD | L-Temple AON/Power Board | 1.5 x 1.5 x 0.75 mm | DNP | TI BQ297xx Datasheet SLUSBU9I | Keep ONE protection scheme; confirm suffix OVP/UVP/OCP vs nPM1300/boost UVLO (§17) |
| Q1 | dual back-to-back N-MOSFET TBD | L-Temple AON/Power Board | TBD | DNP | Current V2 generated schematic/BOM master | Vds/RDSon/Vgs/peak per BQ2970 app (§17) |
| RS1 | 10 milliohm 1% 1 W shunt TBD | L-Temple AON/Power Board | TBD | PROVISIONAL | Current V2 generated schematic/BOM master | I_BAT_TOTAL; the one production-kept sense path |
| U25 | INA238 | L-Temple AON/Power Board | 3.0 x 4.9 x TBD mm | DNP | AI Glasses Hardware Dimensions V2.3 | Power Gate — EVT-A; production may keep this one |
| RT1 | 10k NTC curve TBD | Temple Rears (batt/spkr/ant) | TBD | PROVISIONAL | AI Glasses Hardware Dimensions V2.3 | NTC curve matched to nPM1300 charger config |
| BT2 | LP451165 300 mAh | Temple Rears (batt/spkr/ant) | 70.0 x 12.8 x 5.6 mm | HOLD | LP451165 Battery Bay Fit Check | G07 |
| J6 | 2.4 GHz FPC/PCB antenna TBD | Temple Rears (batt/spkr/ant) | TBD | TBD | Current V2 generated schematic/BOM master | Worn-state tuning; clear of battery/metal |
| U14 | IMX415-AAQR custom FPC module; Radxa Camera 4K AS001 is only a candidate mechanical baseline | Front Sensor Board | TBD | HOLD | Sony IMX415-AAQR-C Datasheet E19504 | G10 (module lens/FOV/FPC pinout/lane/supply/timing from vendor) |
| CAM_LENS | Radxa Camera 4K AS001 lens candidate | Virtual mechanical item | 32.5 x 32.5 x 18.0 mm | HOLD | AI Glasses Hardware Dimensions V2.3 | close gate/source data before PCB layout |
| MK1 | T5837 | Front Sensor Board | 3.5 x 2.65 x 0.98 mm | PROVISIONAL | AI Glasses Hardware Dimensions V2.3 | G11 (mic coords/ports/wind/wake + AEC/beamforming) |
| MK2 | T5837 | Front Sensor Board | 3.5 x 2.65 x 0.98 mm | PROVISIONAL | AI Glasses Hardware Dimensions V2.3 | G11 |
| MK3 | T5837 | Front Sensor Board | 3.5 x 2.65 x 0.98 mm | PROVISIONAL | AI Glasses Hardware Dimensions V2.3 | G11 |
| U15 | TPS62840 | Front Sensor Board | TBD | PROVISIONAL | AI Glasses Hardware Dimensions V2.3 | Output current/noise per final module (DVDD ~250mA max + margin) |
| U16 | TLV75529PDRVR | Front Sensor Board | 2.0 x 2.0 x TBD mm | PROVISIONAL | AI Glasses Hardware Dimensions V2.3 | Verify vs IMX415 AVDD peak (156mA) + PSRR |
| U17 | TPS22917DBVR | Front Sensor Board | 2.9 x 2.8 x TBD mm | PROVISIONAL | AI Glasses Hardware Dimensions V2.3 | Check reverse block, ramp, QOD, logic level |
| U18 | TPD4E05U06 | Front Sensor Board | 2.5 x 1.0 x TBD mm | PROVISIONAL | AI Glasses Hardware Dimensions V2.3 | Low-cap array near FPC entry |
| CAM_FPC | custom camera FPC TBD | Virtual mechanical item | TBD | HOLD | Current V2 generated schematic/BOM master | close gate/source data before PCB layout |

## Component Cards

### U1 - RK3576

- What it is: Main SoC — 8-core, 6 TOPS NPU, ISP, MIPI CSI, H.264/265. Demand-started compute island (NOT always-on). Functional block: interface pins only..
- What it does: 运行 Linux/AI/编码/ISP 等高负载任务。
- Why needed: 需要本地 AI、摄像头 ISP 和视频编码时才启动。
- Connects to: RK806S、LPDDR4X、eMMC、camera MIPI、Wi-Fi USB、audio I2S、AON UART。
- Voltage: RK806S rails from SOC_5V.
- Power: typical included in compute model; peak part of AI-burst compute row.
- Body size: 16.1 x 17.2 x TBD mm.
- Extra area: 还要去耦、fanout、DDR corridor、热扩散和测试点。
- Placement: R-Temple Compute Board; Body outline known from project BOM/PDF; full datasheet, HDG, ball map, max height, DDR guide and official land pattern still required.
- Keep away from: 天线 keep-out、电池膨胀区、高热源和不可维修的硬压位置。
- Freeze status: HOLD; footprint: NOT_FOR_FAB placeholder; not release-ready.
- Missing data: G01 (RK3576 datasheet/HDG/ballmap/DDR guide)
- Source: RK3576 Brief Datasheet file (V1.2, 2024-03-11; PDF metadata title mismatch noted), pp. 1-3, `AI_Glasses_HOLD_Closure_Pack/05_Project_References/RK3576 Brief Datasheet V1.2-20240311.pdf`.

### U2 - RK806S-5

- What it is: SoC PMIC — generates CPU/GPU/NPU/DDR/IO rails + power sequencing for RK3576. Reuse verified RK3576 power architecture; NOT for AON..
- What it does: 运行 Linux/AI/编码/ISP 等高负载任务。
- Why needed: 当前架构需要它来完成对应电源、信号、传感、射频、声学或调试功能。
- Connects to: 见 current schematic nets and board partition。
- Voltage: SOC_5V input; generates RK3576/DDR rails.
- Power: typical regulation loss included in compute model; peak TBD after rail-current budget.
- Body size: TBD.
- Extra area: 还要去耦、fanout、DDR corridor、热扩散和测试点。
- Placement: R-Temple Compute Board; Exact package, height, land pattern and rail sequence are not frozen.
- Keep away from: 天线 keep-out、电池膨胀区、高热源和不可维修的硬压位置。
- Freeze status: HOLD; footprint: NOT_FOR_FAB placeholder; not release-ready.
- Missing data: G03 (RK806S MPN/inductors/caps/timing per Radxa/Rockchip FAE)
- Source: AI Glasses Hardware Dimensions V2.3 (2026-07-01), pp. 1-10, `/Users/stanley/Downloads/AI_Glasses_Hardware_Dimensions_V2.3.pdf`.

### U3 - LPDDR4X 4 GB MPN TBD

- What it is: System memory — 4 GB LPDDR4X x32, placed adjacent to RK3576. Reuse a Rockchip/Radxa-verified MPN to lower first chip-down risk vs LPDDR5..
- What it does: 完成该功能模块在系统中的专用任务。
- Why needed: 当前架构需要它来完成对应电源、信号、传感、射频、声学或调试功能。
- Connects to: 见 current schematic nets and board partition。
- Voltage: RK806 DDR rails.
- Power: typical included in compute model; peak TBD by selected MPN.
- Body size: TBD.
- Extra area: 还要去耦、fanout、DDR corridor、热扩散和测试点。
- Placement: R-Temple Compute Board; Needs exact AVL MPN, package drawing, ball map and DDR length/escape review.
- Keep away from: 天线 keep-out、电池膨胀区、高热源和不可维修的硬压位置。
- Freeze status: HOLD; footprint: NOT_FOR_FAB placeholder; not release-ready.
- Missing data: G02 (LPDDR4X MPN/topology/placement, DDR review + length report)
- Source: AI Glasses Hardware Dimensions V2.3 (2026-07-01), pp. 1-10, `/Users/stanley/Downloads/AI_Glasses_Hardware_Dimensions_V2.3.pdf`.

### U4 - 32 GB eMMC 5.1 MPN TBD

- What it is: System storage — 32 GB eMMC 5.1 (HS200/HS400 per BSP). Small + reliable; no microSD. Holds OS, models, event clips..
- What it does: 完成该功能模块在系统中的专用任务。
- Why needed: 当前架构需要它来完成对应电源、信号、传感、射频、声学或调试功能。
- Connects to: 见 current schematic nets and board partition。
- Voltage: VCC/VCCQ from RK806 rails.
- Power: typical included in compute model; peak TBD by selected MPN.
- Body size: TBD.
- Extra area: 还要去耦、连接器、测试点、keep-out 和装配公差。
- Placement: R-Temple Compute Board; Common eMMC sizes are not freeze data; final MPN and package drawing required.
- Keep away from: 天线 keep-out、电池膨胀区、高热源和不可维修的硬压位置。
- Freeze status: HOLD; footprint: NOT_FOR_FAB placeholder; not release-ready.
- Missing data: G04 (eMMC MPN + BSP/bootloader; cold-boot + power-loss recovery)
- Source: AI Glasses Hardware Dimensions V2.3 (2026-07-01), pp. 1-10, `/Users/stanley/Downloads/AI_Glasses_Hardware_Dimensions_V2.3.pdf`.

### U11 - FCU760KAAMD

- What it is: Wi-Fi 6 + BT 5.4 module — Quectel FCU760K, LCC 13.0x12.2x2.0mm. USB2 to RK3576 host; PCM for BT audio; VBAT 3.0-3.6V (typ 3.3V), max TX 353 mA. On-demand, load-switched off..
- What it does: 完成该功能模块在系统中的专用任务。
- Why needed: 当前架构需要它来完成对应电源、信号、传感、射频、声学或调试功能。
- Connects to: WIFI_3V3、USB2 to RK3576、PCM/audio、Wi-Fi antenna。
- Voltage: VBAT 3.0-3.6 V, typ 3.3 V.
- Power: typical radio average: 80-150 mW in current model; peak 353 mA @ 3.3 V max Tx current in short spec.
- Body size: 13.0 x 12.2 x 2.0 mm.
- Extra area: 还要去耦、连接器、测试点、keep-out 和装配公差。
- Placement: R-Temple Compute Board; Module outline is known. Official hardware design guide, land pattern/3D and RK3576 driver enumeration still close G05.
- Keep away from: 天线 keep-out、电池膨胀区、高热源和不可维修的硬压位置。
- Freeze status: HOLD; footprint: NOT_FOR_FAB placeholder; not release-ready.
- Missing data: G05 (Quectel HW Design + RK3576 BSP driver/firmware/enum) + official LCC land pattern
- Source: Quectel FCU760K Short Specification (V1.1, Released, 2024), pp. 1-3, `AI_Glasses_HOLD_Closure_Pack/02_WiFi_FCU760K/Quectel_FCU760K_Short_Spec_V1.1.pdf`.

### U6 - TPS61088

- What it is: Main SoC 5 V boost — 1S -> SOC_5V for the compute island. High-current sync boost; EN from nRF54L15, PG back to nRF. Candidate/HOLD until peak measured..
- What it does: 运行 Linux/AI/编码/ISP 等高负载任务。
- Why needed: 当前架构需要它来完成对应电源、信号、传感、射频、声学或调试功能。
- Connects to: 见 current schematic nets and board partition。
- Voltage: VSYS in, SOC_5V out.
- Power: typical conversion loss in compute-island loss row; peak TBD from RK3576 boot/AI current.
- Body size: 4.5 x 3.5 x TBD mm.
- Extra area: 还要电感、输入/输出电容、反馈、热铜和高电流回路空间。
- Placement: R-Temple Compute Board; Chip size alone is insufficient; L1, input/output caps, current loop and thermal rise are the real footprint.
- Keep away from: antenna、IMU、mic、skin-side hot spot 和电池。
- Freeze status: HOLD; footprint: candidate; verify official drawing/land pattern/height before layout.
- Missing data: G06/G09 (measured RK3576 boot+AI peak, soft-start, droop, thermal)
- Source: AI Glasses Hardware Dimensions V2.3 (2026-07-01), pp. 1-10, `/Users/stanley/Downloads/AI_Glasses_Hardware_Dimensions_V2.3.pdf`.

### L1 - shielded low-DCR power inductor TBD

- What it is: Boost inductor for TPS61088 — low-DCR shielded, value per TPS61088 design. Do not freeze before transient sim/measurement..
- What it does: 完成该功能模块在系统中的专用任务。
- Why needed: 当前架构需要它来完成对应电源、信号、传感、射频、声学或调试功能。
- Connects to: 见 current schematic nets and board partition。
- Voltage: SOC_5V boost switch node.
- Power: typical loss TBD by DCR/RMS current; peak Isat must cover boot/AI peak.
- Body size: 5.0 x 5.0 x 2.0 mm.
- Extra area: 还要电感、输入/输出电容、反馈、热铜和高电流回路空间。
- Placement: R-Temple Compute Board; Target envelope only. Final MPN may grow after Isat/DCR/temperature validation.
- Keep away from: antenna、IMU、mic、skin-side hot spot 和电池。
- Freeze status: TBD; footprint: NOT_FOR_FAB placeholder; not release-ready.
- Missing data: G06/G13 (Isat covers boot+AI peak; height <=2mm; thermal)
- Source: AI Glasses Hardware Dimensions V2.3 (2026-07-01), pp. 1-10, `/Users/stanley/Downloads/AI_Glasses_Hardware_Dimensions_V2.3.pdf`.

### U12 - TPS62825

- What it is: Wi-Fi dedicated 3.3 V buck — feeds FCU760K VBAT; >=500 mA capability for the 353 mA TX peak (pack note). EN by AON MCU. Avoids routing the radio through 5 V (Phase-3 rule)..
- What it does: 完成该功能模块在系统中的专用任务。
- Why needed: 当前架构需要它来完成对应电源、信号、传感、射频、声学或调试功能。
- Connects to: 见 current schematic nets and board partition。
- Voltage: VSYS to WIFI_3V3.
- Power: typical ~5 mW loss allocation; peak sized for FCU760K Tx current.
- Body size: 1.5 x 1.5 x TBD mm.
- Extra area: 还要去耦、连接器、测试点、keep-out 和装配公差。
- Placement: R-Temple Compute Board; Needs final inductor/cap derating and land-pattern check.
- Keep away from: 天线 keep-out、电池膨胀区、高热源和不可维修的硬压位置。
- Freeze status: PROVISIONAL; footprint: candidate; verify official drawing/land pattern/height before layout.
- Missing data: G05/G06 (inductor/caps per module 353mA TX peak + ripple)
- Source: AI Glasses Hardware Dimensions V2.3 (2026-07-01), pp. 1-10, `/Users/stanley/Downloads/AI_Glasses_Hardware_Dimensions_V2.3.pdf`.

### U20 - MAX98360A

- What it is: Digital Class-D amp — I2S in, mono, low-power shutdown. Direct digital audio chain, no analog codec. Fully power-downable via load switch..
- What it does: 输出提示音或语音。
- Why needed: 当前架构需要它来完成对应电源、信号、传感、射频、声学或调试功能。
- Connects to: 见 current schematic nets and board partition。
- Voltage: AUDIO_PWR / I2S control.
- Power: typical audio average 2-3 mW electronics plus speaker output; peak depends on speaker impedance and acoustic target.
- Body size: TBD.
- Extra area: 还要去耦、连接器、测试点、keep-out 和装配公差。
- Placement: R-Temple Compute Board; Exact package and EMI/thermal/acoustic layout still need closure.
- Keep away from: 天线 keep-out、电池膨胀区、高热源和不可维修的硬压位置。
- Freeze status: PROVISIONAL; footprint: NOT_FOR_FAB placeholder; not release-ready.
- Missing data: Verify Z/cavity/EMI/peak power
- Source: AI Glasses Hardware Dimensions V2.3 (2026-07-01), pp. 1-10, `/Users/stanley/Downloads/AI_Glasses_Hardware_Dimensions_V2.3.pdf`.

### Y1 - 24 MHz 10 ppm crystal TBD

- What it is: Main clock — 24 MHz, 10 ppm; load per Rockchip reference layout..
- What it does: 完成该功能模块在系统中的专用任务。
- Why needed: 当前架构需要它来完成对应电源、信号、传感、射频、声学或调试功能。
- Connects to: 见 current schematic nets and board partition。
- Voltage: oscillator pins on RK3576.
- Power: typical passive; peak passive.
- Body size: 3.2 x 2.5 x TBD mm.
- Extra area: 还要去耦、连接器、测试点、keep-out 和装配公差。
- Placement: R-Temple Compute Board; Reference load capacitance/ESR/placement must follow RK3576 HDG.
- Keep away from: 天线 keep-out、电池膨胀区、高热源和不可维修的硬压位置。
- Freeze status: PROVISIONAL; footprint: candidate; verify official drawing/land pattern/height before layout.
- Missing data: G01 (reuse reference CL/ESR + placement distance per HDG)
- Source: AI Glasses Hardware Dimensions V2.3 (2026-07-01), pp. 1-10, `/Users/stanley/Downloads/AI_Glasses_Hardware_Dimensions_V2.3.pdf`.

### U5 - MX25U6432F

- What it is: Backup boot flash — 64 Mbit 1.8 V serial NOR on FSPI. Reserved for recovery / factory test / alt-boot; not populated on first EVT..
- What it does: 完成该功能模块在系统中的专用任务。
- Why needed: 当前架构需要它来完成对应电源、信号、传感、射频、声学或调试功能。
- Connects to: 见 current schematic nets and board partition。
- Voltage: 1.8 V SPI/QSPI.
- Power: typical DNP; peak DNP.
- Body size: TBD.
- Extra area: 还要去耦、连接器、测试点、keep-out 和装配公差。
- Placement: R-Temple Compute Board; Footprint kept only if boot flow needs external NOR.
- Keep away from: 天线 keep-out、电池膨胀区、高热源和不可维修的硬压位置。
- Freeze status: DNP; footprint: DNP; do not treat as release BOM.
- Missing data: Boot flow decides whether production needs it
- Source: AI Glasses Hardware Dimensions V2.3 (2026-07-01), pp. 1-10, `/Users/stanley/Downloads/AI_Glasses_Hardware_Dimensions_V2.3.pdf`.

### BT1 - LP451165 300 mAh

- What it is: Right cell — 3.7 V 300 mAh, 4.5x11x65 mm, high-rate custom. Right-temple weight..
- What it does: 提供整机电源和续航。
- Why needed: 右侧电池提供容量并平衡整机重量。
- Connects to: F1/RS3 branch path into BAT_P and J4/AON power path。
- Voltage: 1S Li-Po nominal 3.7 V.
- Power: typical source; peak branch current TBD by 1S2P validation.
- Body size: 70.0 x 12.8 x 5.6 mm.
- Extra area: 还要极耳/线材、NTC、泡棉、膨胀、绝缘和维修余量。
- Placement: Temple Rears (batt/spkr/ant); Use 70 x 12.8 x 5.6 mm CAD clearance envelope, not nominal 65 x 11 x 4.5 mm. Supplier drawing still required.
- Keep away from: RK3576、PMIC、boost、电感、尖锐边、螺丝、热扩散片和强压点。
- Freeze status: HOLD; footprint: NOT_FOR_FAB placeholder; not release-ready.
- Missing data: G07 (full datasheet, >=2C, IR, cycles, cert)
- Source: LP451165 Battery Bay Fit Check (project fit-check, 2026-07-01), dimensions.csv + fit-check md, `AI_Glasses_HOLD_Closure_Pack/06_Mechanical_Fit_Check/`.

### LS1 - 8 ohm 0.5-1 W micro speaker TBD

- What it is: Main speaker — first version single speaker; open acoustic unit set by temple cavity..
- What it does: 输出提示音或语音。
- Why needed: 当前架构需要它来完成对应电源、信号、传感、射频、声学或调试功能。
- Connects to: 见 current schematic nets and board partition。
- Voltage: driven by MAX98360A.
- Power: typical 13-27 mW average in model; peak 0.5-1 W acoustic part class.
- Body size: TBD.
- Extra area: 还要去耦、连接器、测试点、keep-out 和装配公差。
- Placement: Temple Rears (batt/spkr/ant); Must choose speaker MPN, magnet size, port, cavity, leak path and antenna exclusion.
- Keep away from: 天线 keep-out、电池膨胀区、高热源和不可维修的硬压位置。
- Freeze status: TBD; footprint: NOT_FOR_FAB placeholder; not release-ready.
- Missing data: MPN after acoustic cavity/volume/leak test
- Source: Current V2 generated schematic/BOM master (generated 2026-07-01), scripts/chipdown_bom.py, `v2_chipdown/scripts/chipdown_bom.py`.

### J1 - magnetic pogo 4-6 pin TBD

- What it is: Charge/data interface — magnetic pogo (5 V charge, optional USB2). Thinner + more waterproof than a temple USB-C..
- What it does: 连接板卡、电源、信号或充电/调试接口。
- Why needed: 当前架构需要它来完成对应电源、信号、传感、射频、声学或调试功能。
- Connects to: 见 current schematic nets and board partition。
- Voltage: USB_5V, GND, optional USB2/ID.
- Power: typical passive; contact I2R loss; peak charge/fault current rating TBD.
- Body size: 10.0 x 3.0 x TBD mm.
- Extra area: 还要去耦、连接器、测试点、keep-out 和装配公差。
- Placement: Temple Rears (batt/spkr/ant); Needs pin count, contact resistance, magnet polarity, corrosion, short and mating-life data.
- Keep away from: 天线 keep-out、电池膨胀区、高热源和不可维修的硬压位置。
- Freeze status: TBD; footprint: NOT_FOR_FAB placeholder; not release-ready.
- Missing data: Magnet direction, sweat corrosion, short, cycle life
- Source: AI Glasses Hardware Dimensions V2.3 (2026-07-01), pp. 1-10, `/Users/stanley/Downloads/AI_Glasses_Hardware_Dimensions_V2.3.pdf`.

### J3 - FH26W series pin count TBD

- What it is: Front<->temple high-speed FPC — carries MIPI CSI + PDM + I2C + control + camera power + GND across to the compute/AON boards. Documents the hinge-FPC pin list..
- What it does: 连接板卡、电源、信号或充电/调试接口。
- Why needed: 当前架构需要它来完成对应电源、信号、传感、射频、声学或调试功能。
- Connects to: 见 current schematic nets and board partition。
- Voltage: MIPI/PDM/I2C/CAM rails/GND.
- Power: typical passive; peak pin-current TBD.
- Body size: 12.0 x 3.5 x 1.0 mm.
- Extra area: 还要去耦、连接器、测试点、keep-out 和装配公差。
- Placement: Front Sensor Board; 35-pin length is only an example. Final pin count and contact orientation are G12 blockers.
- Keep away from: 天线 keep-out、电池膨胀区、高热源和不可维修的硬压位置。
- Freeze status: HOLD; footprint: NOT_FOR_FAB placeholder; not release-ready.
- Missing data: G12 (pin count from final cam lane/mic/power split)
- Source: AI Glasses Hardware Dimensions V2.3 (2026-07-01), pp. 1-10, `/Users/stanley/Downloads/AI_Glasses_Hardware_Dimensions_V2.3.pdf`.

### J4 - custom 6-10 mm FPC / rigid-flex TBD

- What it is: Hinge FPC (L<->R) — carries battery power path, AON UART, control lines and GND between the two temples. Enables the split-and-fold structure..
- What it does: 连接板卡、电源、信号或充电/调试接口。
- Why needed: 当前架构需要它来完成对应电源、信号、传感、射频、声学或调试功能。
- Connects to: left AON/power side and right compute/battery side。
- Voltage: BAT_P/VSYS, GND, AON UART, EN/PGOOD/fault/status.
- Power: typical passive; I2R loss; peak must carry peak and fault current safely.
- Body size: TBD x 6-10 x 0.10-0.18 mm.
- Extra area: 还要去耦、连接器、测试点、keep-out 和装配公差。
- Placement: Temple Rears (batt/spkr/ant); EVT-A can be fixed-temple cable/FPC. Folding hinge life, bend radius, stack-up and pin count remain open.
- Keep away from: 天线 keep-out、电池膨胀区、高热源和不可维修的硬压位置。
- Freeze status: HOLD; footprint: NOT_FOR_FAB placeholder; not release-ready.
- Missing data: G12 (impedance, bend radius, life, hinge interference)
- Source: AI Glasses Hardware Dimensions V2.3 (2026-07-01), pp. 1-10, `/Users/stanley/Downloads/AI_Glasses_Hardware_Dimensions_V2.3.pdf`.
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

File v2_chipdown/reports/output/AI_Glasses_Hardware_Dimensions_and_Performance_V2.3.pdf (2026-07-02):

State | Model | Target/use
Deep Off / AON | 22 mW | 20-50 mW target
Quick Standby | 134 mW | DDR/light sleep model
Phone assist | 362 mW | 3-5 h blended target
Mixed motion | 450 mW | <=500-800 mW target
1080p record | 1290 mW | 45-90 min product target
AI + record | 2065 mW | 30-60 min / short burst target

# AI Glasses V2.3 Hardware Dimensions and Performance

# Generated 2026-07-01 from current schematic/BOM and hardware_mechanical_database.yaml

# - Overall verdict before PCB layout: HOLD

# - Thin optical frame: FAIL for current architecture

# - Thick smart-glasses / sports frame: PASS WITH CONDITIONS after CAD/FPC/RF/battery proof

- AON and compute PCBs contain multiple ICs because those ICs are soldered to the board; this is allowed
- Real overlap of 3D envelopes, courtyards, battery swell, speaker cavity, or RF keep-out is not allowed

# - Existing ERC report: 0 errors / 0 warnings; DRC not run because V2 has no PCB yet

# Current power model

# 16 required mechanical views - placement envelope atlas

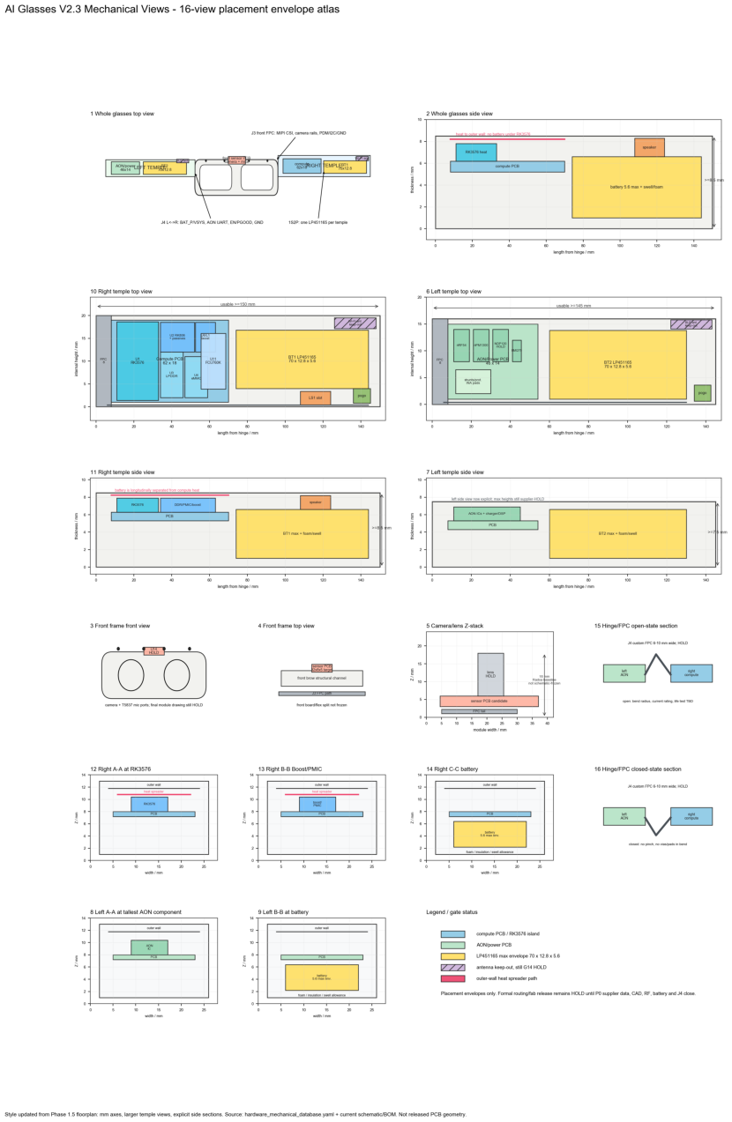
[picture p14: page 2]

# Phase 1 design review answers

- Left temple side view is missing in the earlier render: HOLD until left side + A-A/B-B sections exist in CAD.
- Right temple side section is directionally correct but incomplete: add real max heights, solder, heat pad, insulation and tolerance stack.
- nRF54L15, nPM1300, NDP120 and BMI270 on one AON PCB is reasonable, with RF/thermal/vibration separation.
- AON 46 x 14 mm and Compute 62 x 18 mm are placement envelopes, not proof of complete circuitry.
- RK3576 + LPDDR routing needs 8-10 layer HDI review, ball maps, stack-up and DDR length report.
- Battery must stay longitudinally separated from RK3576/PMIC/boost; any real hot-source overlap is FAIL.
- Wi-Fi/BLE antenna keep-outs are HOLD until antenna SKU/tune and speaker/battery/screw clearance are proven.
- Cross-temple 1S2P and J4 current path are major HOLD items.

Audit item | Result | Evidence
Components | symbol_to_footprint_mapping.csv maps each schematic component to current footprint/status 96
Schematic nets | interconnect_matrix.csv/md records endpoints, domain crossings and layout rules 127
Footprint release | VERIFY/HOLD/TBD/DNP items are NOT_FOR_FAB until official land patterns and package heights exist HOLD
ERC | erc.report.txt shows 0 errors / 0 warnings on 2026-07-01T01:26:33; not rerun because kicad-cli unavailable Existing PASS
DRC / 3D | NOT RUNV2 currently has no .kicad_pcb or verified STEP assembly

# KiCad audit evidence generated

# Decision

No KiCad schematic, footprint, PCB or 3D-model files were modified in this phase. That is intentional: the project rules require HOLD placeholders until exact MPNs, official package drawings, pinouts, land patterns and mechanical envelopes are available.

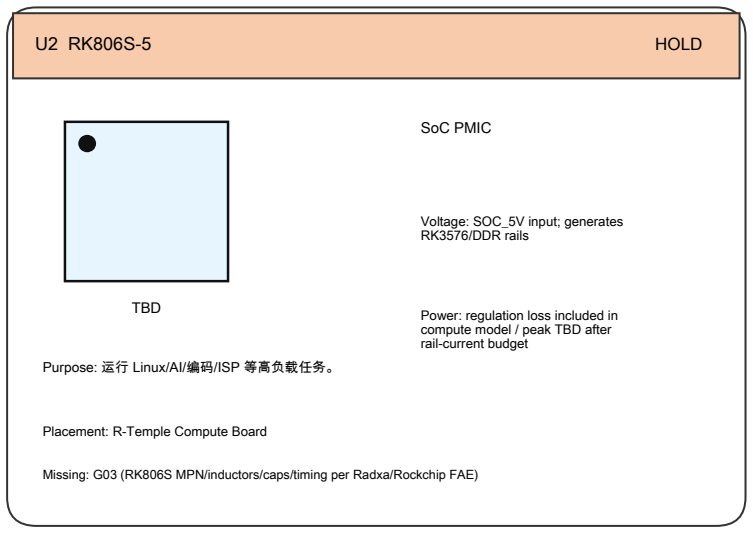
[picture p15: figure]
HOLD; TBD; SoC PMIC; Voltage: SOC_5V input; generates RK3576/DDR rails; Power: regulation loss included in compute model / peak TBD after rail-current budget; Purpose: 运行 Linux/AI/编码/ISP 等高负载任务。; Placement: R-Temple Compute Board

Missing: G03 (RK806S MPN/inductors/caps/timing per Radxa/Rockchip FAE)

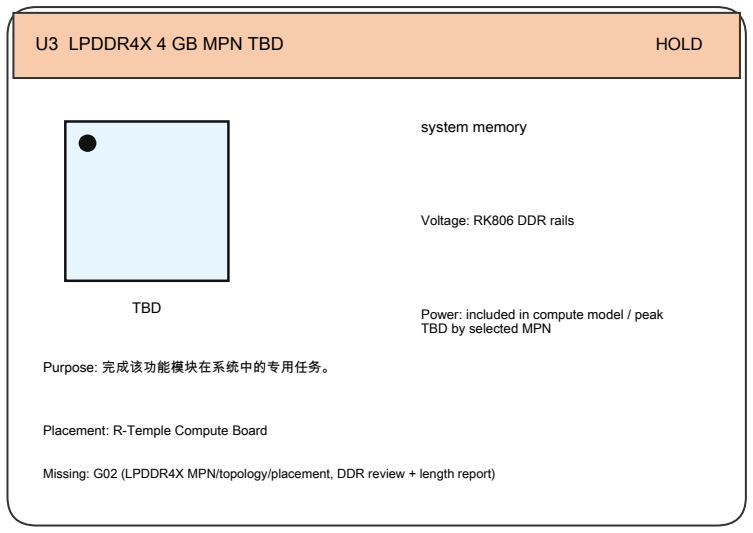
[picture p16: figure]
U3 LPDDR4X 4 GB MPN TBD; HOLD; TBD; system memory; Voltage: RK806 DDR rails; Power: included in compute model / peak TBD by selected MPN; Purpose: 完成该功能模块在系统中的专用任务。; Placement: R-Temple Compute Board

Missing: G02 (LPDDR4X MPN/topology/placement, DDR review + length report)

Missing: G04 (eMMC MPN + BSP/bootloader; cold-boot + power-loss recovery)

# Component cards - simple language, source-bound dimensions

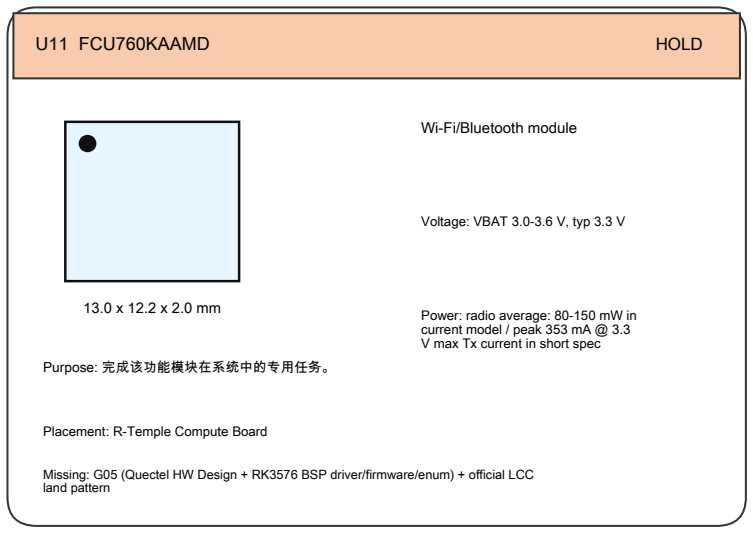
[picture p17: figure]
U11 FCU760KAAMD; HOLD; Wi-Fi/Bluetooth module; Voltage: VBAT 3.0-3.6 V, typ 3.3 V; Power: radio average: 80-150 mW in current model / peak 353 mA @ 3.3 V max Tx current in short spec; Purpose: 完成该功能模块在系统中的专用任务。; Placement: R-Temple Compute Board; land pattern

Missing: G05 (Quectel HW Design + RK3576 BSP driver/firmware/enum) + official LCC

Missing: G06/G09 (measured RK3576 boot+AI peak, soft-start, droop, thermal)

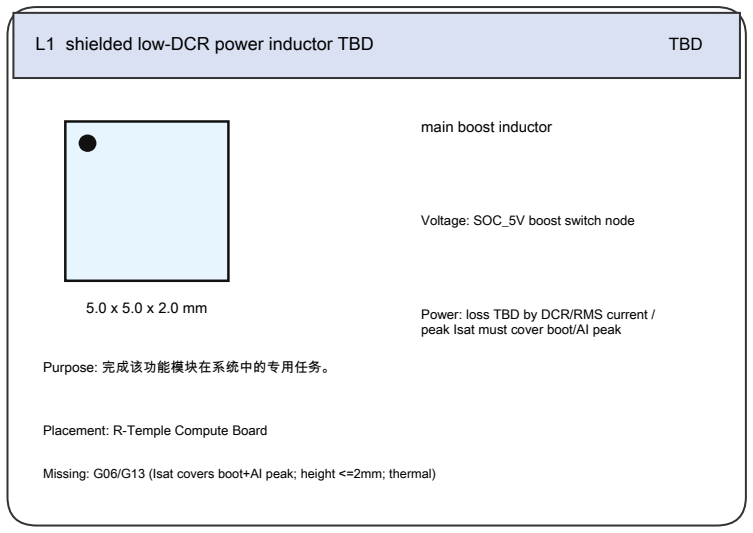
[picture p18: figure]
main boost inductor; Voltage: SOC_5V boost switch node; Power: loss TBD by DCR/RMS current / peak Isat must cover boot/AI peak; Purpose: 完成该功能模块在系统中的专用任务。; Placement: R-Temple Compute Board

L1 shielded low-DCR power inductor TBD | TBD

Missing: G06/G13 (Isat covers boot+AI peak; height <=2mm; thermal)

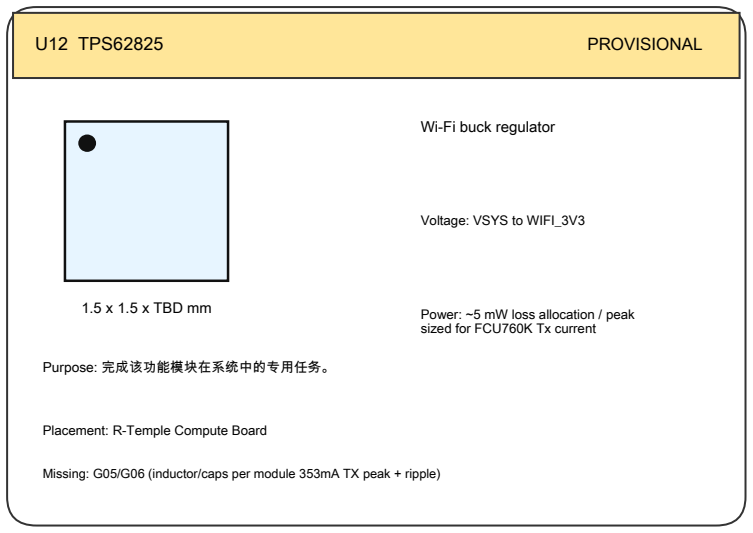
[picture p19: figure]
U12 TPS62825; PROVISIONAL; 1.5 x 1.5 x TBD mm; Wi-Fi buck regulator; Voltage: VSYS to WIFI_3V3; Power: ~5 mW loss allocation / peak sized for FCU760K Tx current; Purpose: 完成该功能模块在系统中的专用任务。; Placement: R-Temple Compute Board

Missing: G05/G06 (inductor/caps per module 353mA TX peak + ripple)

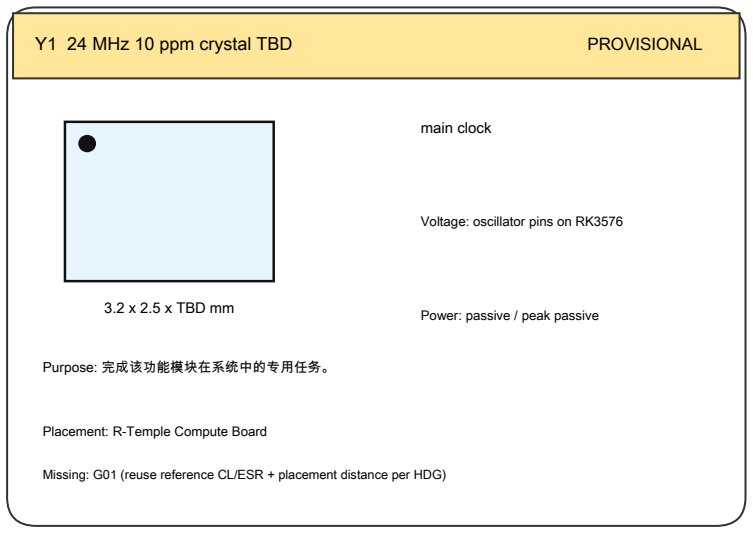
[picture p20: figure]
3.2 x 2.5 x TBD mm; main clock; Voltage: oscillator pins on RK3576; Power: passive / peak passive; Purpose: 完成该功能模块在系统中的专用任务。; Placement: R-Temple Compute Board

Y1 24 MHz 10 ppm crystal TBD | PROVISIONAL

Missing: G01 (reuse reference CL/ESR + placement distance per HDG)

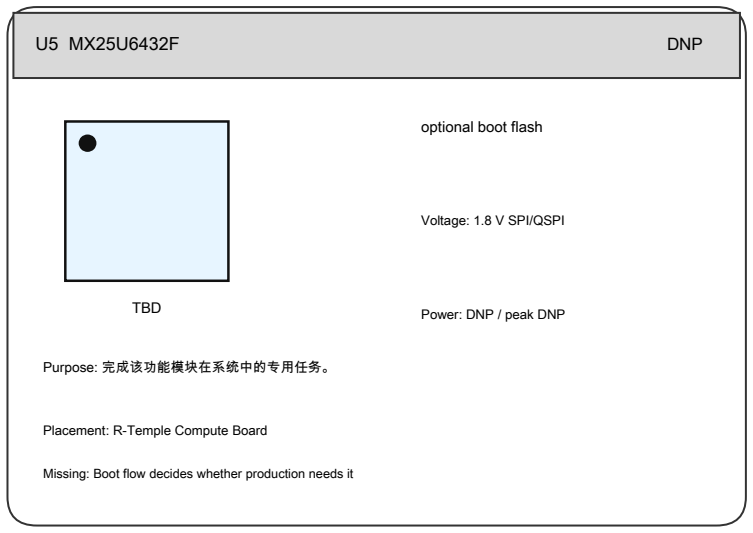
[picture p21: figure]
DNP; TBD; optional boot flash; Voltage: 1.8 V SPI/QSPI; Power: DNP / peak DNP; Purpose: 完成该功能模块在系统中的专用任务。; Placement: R-Temple Compute Board

Missing: Boot flow decides whether production needs it

Missing: G07 (full datasheet, >=2C, IR, cycles, cert)

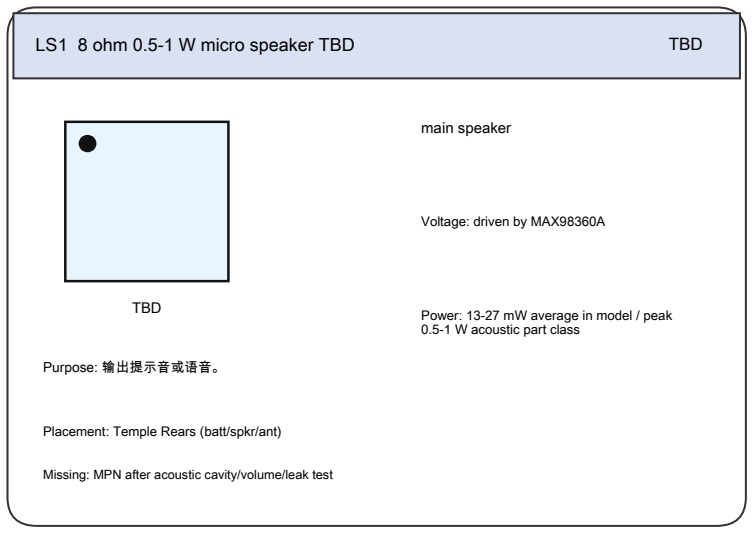
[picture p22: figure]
LS1 8 ohm 0.5-1 W micro speaker TBD; TBD; main speaker; Voltage: driven by MAX98360A; Power: 13-27 mW average in model / peak 0.5-1 W acoustic part class; Purpose: 输出提示音或语音。; Placement: Temple Rears (batt/spkr/ant)

Missing: MPN after acoustic cavity/volume/leak test

Missing: Magnet direction, sweat corrosion, short, cycle life

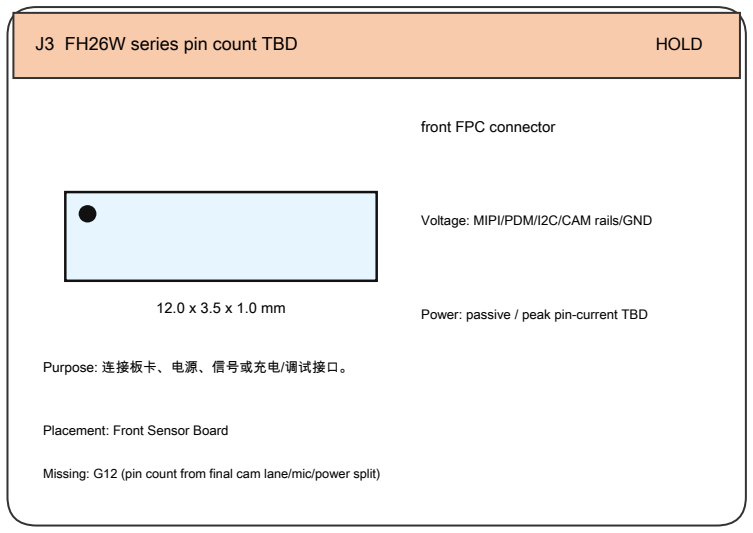
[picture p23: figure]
J3 FH26W series pin count TBD; HOLD; front FPC connector; Voltage: MIPI/PDM/I2C/CAM rails/GND; Power: passive / peak pin-current TBD; Purpose: 连接板卡、电源、信号或充电/调试接口。; Placement: Front Sensor Board

Missing: G12 (pin count from final cam lane/mic/power split)

TBD x 6-10 x 0.10-0.18 mm; left-right interconnect / future hinge FPC; Voltage: BAT_P/VSYS, GND, AON UART, EN/PGOOD/fault/status; Power: passive; I2R loss / peak must carry peak and fault current safely; Purpose: 连接板卡、电源、信号或充电/调试接口。; Placement: Temple Rears (batt/spkr/ant)

J4 custom 6-10 mm FPC / rigid-flex TBD | HOLD

Missing: G12 (impedance, bend radius, life, hinge interference)

Power: 2-8 mW allocation depending state

Missing: EVT-frozen (RF layout/SDK/package to freeze early)
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

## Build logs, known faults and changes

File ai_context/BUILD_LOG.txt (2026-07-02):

=== build_ai_context: Tue Jun 30 03:10:55 CDT 2026 ===
10.0.4
Fontconfig warning: "/opt/homebrew/etc/fonts/conf.d/48-guessfamily.conf", line 19: invalid attribute 'xsi:nil'
Fontconfig warning: "/opt/homebrew/etc/fonts/conf.d/48-guessfamily.conf", line 20: invalid constant used : 
Fontconfig warning: "/opt/homebrew/etc/fonts/conf.d/48-guessfamily.conf", line 23: invalid constant used : monospace
Fontconfig warning: "/opt/homebrew/etc/fonts/conf.d/48-guessfamily.conf", line 42: invalid attribute 'xsi:nil'
Fontconfig warning: "/opt/homebrew/etc/fonts/conf.d/48-guessfamily.conf", line 43: invalid constant used : 
Fontconfig warning: "/opt/homebrew/etc/fonts/conf.d/48-guessfamily.conf", line 46: invalid constant used : sans-serif
Fontconfig warning: "/opt/homebrew/etc/fonts/conf.d/48-guessfamily.conf", line 68: invalid attribute 'xsi:nil'
Fontconfig warning: "/opt/homebrew/etc/fonts/conf.d/48-guessfamily.conf", line 69: invalid constant used : 
Fontconfig warning: "/opt/homebrew/etc/fonts/conf.d/48-guessfamily.conf", line 72: invalid constant used : serif
Fontconfig warning: "/opt/homebrew/etc/fonts/conf.d/48-guessfamily.conf", line 88: invalid attribute 'xsi:nil'
Fontconfig warning: "/opt/homebrew/etc/fonts/conf.d/48-guessfamily.conf", line 89: invalid constant used : 
Fontconfig warning: "/opt/homebrew/etc/fonts/conf.d/48-guessfamily.conf", line 92: invalid constant used : emoji
Fontconfig warning: "/opt/homebrew/etc/fonts/conf.d/48-guessfamily.conf", line 108: invalid attribute 'xsi:nil'
Fontconfig warning: "/opt/homebrew/etc/fonts/conf.d/48-guessfamily.conf", line 109: invalid constant used : 
Fontconfig warning: "/opt/homebrew/etc/fonts/conf.d/48-guessfamily.conf", line 112: invalid constant used : math
Fontconfig warning: "/opt/homebrew/etc/fonts/conf.d/48-guessfamily.conf", line 120: invalid attribute 'xsi:nil'
Fontconfig warning: "/opt/homebrew/etc/fonts/conf.d/48-guessfamily.conf", line 121: invalid constant used : 
Fontconfig warning: "/opt/homebrew/etc/fonts/conf.d/48-guessfamily.conf", line 124: invalid constant used : system-ui
Fontconfig warning: "/opt/homebrew/etc/fonts/conf.d/48-guessfamily.conf", line 132: invalid attribute 'xsi:nil'
Fontconfig warning: "/opt/homebrew/etc/fonts/conf.d/48-guessfamily.conf", line 133: invalid constant used : 
Fontconfig warning: "/opt/homebrew/etc/fonts/conf.d/48-guessfamily.conf", line 136: invalid constant used : cursive
Fontconfig warning: "/opt/homebrew/etc/fonts/conf.d/48-guessfamily.conf", line 144: invalid attribute 'xsi:nil'
Fontconfig warning: "/opt/homebrew/etc/fonts/conf.d/48-guessfamily.conf", line 145: invalid constant used : 
Fontconfig warning: "/opt/homebrew/etc/fonts/conf.d/48-guessfamily.conf", line 148: invalid constant used : fantasy
Fontconfig warning: "/opt/homebrew/etc/fonts/conf.d/48-guessfamily.conf", line 156: invalid attribute 'xsi:nil'
Fontconfig warning: "/opt/homebrew/etc/fonts/conf.d/48-guessfamily.conf", line 157: invalid constant used : 
Fontconfig warning: "/opt/homebrew/etc/fonts/conf.d/48-guessfamily.conf", line 160: invalid constant used : ui-sans-serif
Fontconfig warning: "/opt/homebrew/etc/fonts/conf.d/48-guessfamily.conf", line 168: invalid attribute 'xsi:nil'
Fontconfig warning: "/opt/homebrew/etc/fonts/conf.d/48-guessfamily.conf", line 169: invalid constant used : 
Fontconfig warning: "/opt/homebrew/etc/fonts/conf.d/48-guessfamily.conf", line 172: invalid constant used : ui-serif
Fontconfig warning: "/opt/homebrew/etc/fonts/conf.d/48-guessfamily.conf", line 180: invalid attribute 'xsi:nil'
Fontconfig warning: "/opt/homebrew/etc/fonts/conf.d/48-guessfamily.conf", line 181: invalid constant used : 
Fontconfig warning: "/opt/homebrew/etc/fonts/conf.d/48-guessfamily.conf", line 184: invalid constant used : ui-monospace
Fontconfig warning: "/opt/homebrew/etc/fonts/conf.d/48-guessfamily.conf", line 192: invalid attribute 'xsi:nil'
Fontconfig warning: "/opt/homebrew/etc/fonts/conf.d/48-guessfamily.conf", line 193: invalid constant used : 
Fontconfig warning: "/opt/homebrew/etc/fonts/conf.d/48-guessfamily.conf", line 196: invalid constant used : ui-rounded
Fontconfig warning: "/opt/homebrew/etc/fonts/conf.d/48-guessfamily.conf", line 204: invalid attribute 'xsi:nil'
Fontconfig warning: "/opt/homebrew/etc/fonts/conf.d/48-guessfamily.conf", line 205: invalid constant used : 
Fontconfig warning: "/opt/homebrew/etc/fonts/conf.d/48-guessfamily.conf", line 208: invalid constant used : fangsong
Fontconfig warning: "/opt/homebrew/etc/fonts/conf.d/49-sansserif.conf", line 10: invalid constant used : serif
Fontconfig warning: "/opt/homebrew/etc/fonts/conf.d/49-sansserif.conf", line 18: invalid constant used : sans-serif
Fontconfig warning: "/opt/homebrew/etc/fonts/conf.d/49-sansserif.conf", line 26: invalid constant used : monospace
Fontconfig warning: "/opt/homebrew/etc/fonts/conf.d/49-sansserif.conf", line 34: invalid constant used : emoji
Fontconfig warning: "/opt/homebrew/etc/fonts/conf.d/49-sansserif.conf", line 42: invalid constant used : math
Plotted to 'ai_context/schematic.pdf'.
Done.
## sch: PDF
$ /Applications/KiCad/KiCad.app/Contents/MacOS/kicad-cli sch export pdf --output ai_context/schematic.pdf hardware/ai_glasses_carrier.kicad_sch
exit=0

Fontconfig warning: "/opt/homebrew/etc/fonts/conf.d/48-guessfamily.conf", line 19: invalid attribute 'xsi:nil'
Fontconfig warning: "/opt/homebrew/etc/fonts/conf.d/48-guessfamily.conf", line 20: invalid constant used : 
Fontconfig warning: "/opt/homebrew/etc/fonts/conf.d/48-guessfamily.conf", line 23: invalid constant used : monospace
Fontconfig warning: "/opt/homebrew/etc/fonts/conf.d/48-guessfamily.conf", line 42: invalid attribute 'xsi:nil'
Fontconfig warning: "/opt/homebrew/etc/fonts/conf.d/48-guessfamily.conf", line 43: invalid constant used : 
Fontconfig warning: "/opt/homebrew/etc/fonts/conf.d/48-guessfamily.conf", line 46: invalid constant used : sans-serif
Fontconfig warning: "/opt/homebrew/etc/fonts/conf.d/48-guessfamily.conf", line 68: invalid attribute 'xsi:nil'
Fontconfig warning: "/opt/homebrew/etc/fonts/conf.d/48-guessfamily.conf", line 69: invalid constant used : 
Fontconfig warning: "/opt/homebrew/etc/fonts/conf.d/48-guessfamily.conf", line 72: invalid constant used : serif
Fontconfig warning: "/opt/homebrew/etc/fonts/conf.d/48-guessfamily.conf", line 88: invalid attribute 'xsi:nil'
Fontconfig warning: "/opt/homebrew/etc/fonts/conf.d/48-guessfamily.conf", line 89: invalid constant used : 
Fontconfig warning: "/opt/homebrew/etc/fonts/conf.d/48-guessfamily.conf", line 92: invalid constant used : emoji
Fontconfig warning: "/opt/homebrew/etc/fonts/conf.d/48-guessfamily.conf", line 108: invalid attribute 'xsi:nil'
Fontconfig warning: "/opt/homebrew/etc/fonts/conf.d/48-guessfamily.conf", line 109: invalid constant used : 
Fontconfig warning: "/opt/homebrew/etc/fonts/conf.d/48-guessfamily.conf", line 112: invalid constant used : math
Fontconfig warning: "/opt/homebrew/etc/fonts/conf.d/48-guessfamily.conf", line 120: invalid attribute 'xsi:nil'
Fontconfig warning: "/opt/homebrew/etc/fonts/conf.d/48-guessfamily.conf", line 121: invalid constant used : 
Fontconfig warning: "/opt/homebrew/etc/fonts/conf.d/48-guessfamily.conf", line 124: invalid constant used : system-ui
Fontconfig warning: "/opt/homebrew/etc/fonts/conf.d/48-guessfamily.conf", line 132: invalid attribute 'xsi:nil'
Fontconfig warning: "/opt/homebrew/etc/fonts/conf.d/48-guessfamily.conf", line 133: invalid constant used : 
Fontconfig warning: "/opt/homebrew/etc/fonts/conf.d/48-guessfamily.conf", line 136: invalid constant used : cursive
Fontconfig warning: "/opt/homebrew/etc/fonts/conf.d/48-guessfamily.conf", line 144: invalid attribute 'xsi:nil'
Fontconfig warning: "/opt/homebrew/etc/fonts/conf.d/48-guessfamily.conf", line 145: invalid constant used : 
Fontconfig warning: "/opt/homebrew/etc/fonts/conf.d/48-guessfamily.conf", line 148: invalid constant used : fantasy
Fontconfig warning: "/opt/homebrew/etc/fonts/conf.d/48-guessfamily.conf", line 156: invalid attribute 'xsi:nil'
Fontconfig warning: "/opt/homebrew/etc/fonts/conf.d/48-guessfamily.conf", line 157: invalid constant used : 
Fontconfig warning: "/opt/homebrew/etc/fonts/conf.d/48-guessfamily.conf", line 160: invalid constant used : ui-sans-serif
Fontconfig warning: "/opt/homebrew/etc/fonts/conf.d/48-guessfamily.conf", line 168: invalid attribute 'xsi:nil'
Fontconfig warning: "/opt/homebrew/etc/fonts/conf.d/48-guessfamily.conf", line 169: invalid constant used : 
Fontconfig warning: "/opt/homebrew/etc/fonts/conf.d/48-guessfamily.conf", line 172: invalid constant used : ui-serif
Fontconfig warning: "/opt/homebrew/etc/fonts/conf.d/48-guessfamily.conf", line 180: invalid attribute 'xsi:nil'
Fontconfig warning: "/opt/homebrew/etc/fonts/conf.d/48-guessfamily.conf", line 181: invalid constant used : 
Fontconfig warning: "/opt/homebrew/etc/fonts/conf.d/48-guessfamily.conf", line 184: invalid constant used : ui-monospace
Fontconfig warning: "/opt/homebrew/etc/fonts/conf.d/48-guessfamily.conf", line 192: invalid attribute 'xsi:nil'
Fontconfig warning: "/opt/homebrew/etc/fonts/conf.d/48-guessfamily.conf", line 193: invalid constant used : 
Fontconfig warning: "/opt/homebrew/etc/fonts/conf.d/48-guessfamily.conf", line 196: invalid constant used : ui-rounded
Fontconfig warning: "/opt/homebrew/etc/fonts/conf.d/48-guessfamily.conf", line 204: invalid attribute 'xsi:nil'
Fontconfig warning: "/opt/homebrew/etc/fonts/conf.d/48-guessfamily.conf", line 205: invalid constant used : 
Fontconfig warning: "/opt/homebrew/etc/fonts/conf.d/48-guessfamily.conf", line 208: invalid constant used : fangsong
Fontconfig warning: "/opt/homebrew/etc/fonts/conf.d/49-sansserif.conf", line 10: invalid constant used : serif
Fontconfig warning: "/opt/homebrew/etc/fonts/conf.d/49-sansserif.conf", line 18: invalid constant used : sans-serif
Fontconfig warning: "/opt/homebrew/etc/fonts/conf.d/49-sansserif.conf", line 26: invalid constant used : monospace
Fontconfig warning: "/opt/homebrew/etc/fonts/conf.d/49-sansserif.conf", line 34: invalid constant used : emoji
Fontconfig warning: "/opt/homebrew/etc/fonts/conf.d/49-sansserif.conf", line 42: invalid constant used : math
Plotted to '/Users/stanley/AI Glasses/ai_context/schematic-svg/ai_glasses_carrier.svg'.
Done.
## sch: SVG
$ /Applications/KiCad/KiCad.app/Contents/MacOS/kicad-cli sch export svg --output ai_context/schematic-svg hardware/ai_glasses_carrier.kicad_sch
exit=0

Fontconfig warning: "/opt/homebrew/etc/fonts/conf.d/48-guessfamily.conf", line 19: invalid attribute 'xsi:nil'
Fontconfig warning: "/opt/homebrew/etc/fonts/conf.d/48-guessfamily.conf", line 20: invalid constant used : 
Fontconfig warning: "/opt/homebrew/etc/fonts/conf.d/48-guessfamily.conf", line 23: invalid constant used : monospace
Fontconfig warning: "/opt/homebrew/etc/fonts/conf.d/48-guessfamily.conf", line 42: invalid attribute 'xsi:nil'
Fontconfig warning: "/opt/homebrew/etc/fonts/conf.d/48-guessfamily.conf", line 43: invalid constant used : 
Fontconfig warning: "/opt/homebrew/etc/fonts/conf.d/48-guessfamily.conf", line 46: invalid constant used : sans-serif
Fontconfig warning: "/opt/homebrew/etc/fonts/conf.d/48-guessfamily.conf", line 68: invalid attribute 'xsi:nil'
Fontconfig warning: "/opt/homebrew/etc/fonts/conf.d/48-guessfamily.conf", line 69: invalid constant used : 
Fontconfig warning: "/opt/homebrew/etc/fonts/conf.d/48-guessfamily.conf", line 72: invalid constant used : serif
Fontconfig warning: "/opt/homebrew/etc/fonts/conf.d/48-guessfamily.conf", line 88: invalid attribute 'xsi:nil'
Fontconfig warning: "/opt/homebrew/etc/fonts/conf.d/48-guessfamily.conf", line 89: invalid constant used : 
Fontconfig warning: "/opt/homebrew/etc/fonts/conf.d/48-guessfamily.conf", line 92: invalid constant used : emoji
Fontconfig warning: "/opt/homebrew/etc/fonts/conf.d/48-guessfamily.conf", line 108: invalid attribute 'xsi:nil'
Fontconfig warning: "/opt/homebrew/etc/fonts/conf.d/48-guessfamily.conf", line 109: invalid constant used : 
Fontconfig warning: "/opt/homebrew/etc/fonts/conf.d/48-guessfamily.conf", line 112: invalid constant used : math
Fontconfig warning: "/opt/homebrew/etc/fonts/conf.d/48-guessfamily.conf", line 120: invalid attribute 'xsi:nil'
Fontconfig warning: "/opt/homebrew/etc/fonts/conf.d/48-guessfamily.conf", line 121: invalid constant used : 
Fontconfig warning: "/opt/homebrew/etc/fonts/conf.d/48-guessfamily.conf", line 124: invalid constant used : system-ui
Fontconfig warning: "/opt/homebrew/etc/fonts/conf.d/48-guessfamily.conf", line 132: invalid attribute 'xsi:nil'
Fontconfig warning: "/opt/homebrew/etc/fonts/conf.d/48-guessfamily.conf", line 133: invalid constant used : 
Fontconfig warning: "/opt/homebrew/etc/fonts/conf.d/48-guessfamily.conf", line 136: invalid constant used : cursive
Fontconfig warning: "/opt/homebrew/etc/fonts/conf.d/48-guessfamily.conf", line 144: invalid attribute 'xsi:nil'
Fontconfig warning: "/opt/homebrew/etc/fonts/conf.d/48-guessfamily.conf", line 145: invalid constant used : 
Fontconfig warning: "/opt/homebrew/etc/fonts/conf.d/48-guessfamily.conf", line 148: invalid constant used : fantasy
Fontconfig warning: "/opt/homebrew/etc/fonts/conf.d/48-guessfamily.conf", line 156: invalid attribute 'xsi:nil'
Fontconfig warning: "/opt/homebrew/etc/fonts/conf.d/48-guessfamily.conf", line 157: invalid constant used : 
Fontconfig warning: "/opt/homebrew/etc/fonts/conf.d/48-guessfamily.conf", line 160: invalid constant used : ui-sans-serif
Fontconfig warning: "/opt/homebrew/etc/fonts/conf.d/48-guessfamily.conf", line 168: invalid attribute 'xsi:nil'
Fontconfig warning: "/opt/homebrew/etc/fonts/conf.d/48-guessfamily.conf", line 169: invalid constant used : 
Fontconfig warning: "/opt/homebrew/etc/fonts/conf.d/48-guessfamily.conf", line 172: invalid constant used : ui-serif
Fontconfig warning: "/opt/homebrew/etc/fonts/conf.d/48-guessfamily.conf", line 180: invalid attribute 'xsi:nil'
Fontconfig warning: "/opt/homebrew/etc/fonts/conf.d/48-guessfamily.conf", line 181: invalid constant used : 
Fontconfig warning: "/opt/homebrew/etc/fonts/conf.d/48-guessfamily.conf", line 184: invalid constant used : ui-monospace
Fontconfig warning: "/opt/homebrew/etc/fonts/conf.d/48-guessfamily.conf", line 192: invalid attribute 'xsi:nil'
Fontconfig warning: "/opt/homebrew/etc/fonts/conf.d/48-guessfamily.conf", line 193: invalid constant used : 
Fontconfig warning: "/opt/homebrew/etc/fonts/conf.d/48-guessfamily.conf", line 196: invalid constant used : ui-rounded
Fontconfig warning: "/opt/homebrew/etc/fonts/conf.d/48-guessfamily.conf", line 204: invalid attribute 'xsi:nil'
Fontconfig warning: "/opt/homebrew/etc/fonts/conf.d/48-guessfamily.conf", line 205: invalid constant used : 
Fontconfig warning: "/opt/homebrew/etc/fonts/conf.d/48-guessfamily.conf", line 208: invalid constant used : fangsong
Fontconfig warning: "/opt/homebrew/etc/fonts/conf.d/49-sansserif.conf", line 10: invalid constant used : serif
Fontconfig warning: "/opt/homebrew/etc/fonts/conf.d/49-sansserif.conf", line 18: invalid constant used : sans-serif
Fontconfig warning: "/opt/homebrew/etc/fonts/conf.d/49-sansserif.conf", line 26: invalid constant used : monospace
Fontconfig warning: "/opt/homebrew/etc/fonts/conf.d/49-sansserif.conf", line 34: invalid constant used : emoji
Fontconfig warning: "/opt/homebrew/etc/fonts/conf.d/49-sansserif.conf", line 42: invalid constant used : math
## sch: netlist
$ /Applications/KiCad/KiCad.app/Contents/MacOS/kicad-cli sch export netlist --output ai_context/netlist.net hardware/ai_glasses_carrier.kicad_sch
exit=0

Fontconfig warning: "/opt/homebrew/etc/fonts/conf.d/48-guessfamily.conf", line 19: invalid attribute 'xsi:nil'
Fontconfig warning: "/opt/homebrew/etc/fonts/conf.d/48-guessfamily.conf", line 20: invalid constant used : 
Fontconfig warning: "/opt/homebrew/etc/fonts/conf.d/48-guessfamily.conf", line 23: invalid constant used : monospace
Fontconfig warning: "/opt/homebrew/etc/fonts/conf.d/48-guessfamily.conf", line 42: invalid attribute 'xsi:nil'
Fontconfig warning: "/opt/homebrew/etc/fonts/conf.d/48-guessfamily.conf", line 43: invalid constant used : 
Fontconfig warning: "/opt/homebrew/etc/fonts/conf.d/48-guessfamily.conf", line 46: invalid constant used : sans-serif
Fontconfig warning: "/opt/homebrew/etc/fonts/conf.d/48-guessfamily.conf", line 68: invalid attribute 'xsi:nil'
Fontconfig warning: "/opt/homebrew/etc/fonts/conf.d/48-guessfamily.conf", line 69: invalid constant used : 
Fontconfig warning: "/opt/homebrew/etc/fonts/conf.d/48-guessfamily.conf", line 72: invalid constant used : serif
Fontconfig warning: "/opt/homebrew/etc/fonts/conf.d/48-guessfamily.conf", line 88: invalid attribute 'xsi:nil'
Fontconfig warning: "/opt/homebrew/etc/fonts/conf.d/48-guessfamily.conf", line 89: invalid constant used : 
Fontconfig warning: "/opt/homebrew/etc/fonts/conf.d/48-guessfamily.conf", line 92: invalid constant used : emoji
Fontconfig warning: "/opt/homebrew/etc/fonts/conf.d/48-guessfamily.conf", line 108: invalid attribute 'xsi:nil'
Fontconfig warning: "/opt/homebrew/etc/fonts/conf.d/48-guessfamily.conf", line 109: invalid constant used : 
Fontconfig warning: "/opt/homebrew/etc/fonts/conf.d/48-guessfamily.conf", line 112: invalid constant used : math
Fontconfig warning: "/opt/homebrew/etc/fonts/conf.d/48-guessfamily.conf", line 120: invalid attribute 'xsi:nil'
Fontconfig warning: "/opt/homebrew/etc/fonts/conf.d/48-guessfamily.conf", line 121: invalid constant used : 
Fontconfig warning: "/opt/homebrew/etc/fonts/conf.d/48-guessfamily.conf", line 124: invalid constant used : system-ui
Fontconfig warning: "/opt/homebrew/etc/fonts/conf.d/48-guessfamily.conf", line 132: invalid attribute 'xsi:nil'
Fontconfig warning: "/opt/homebrew/etc/fonts/conf.d/48-guessfamily.conf", line 133: invalid constant used : 
Fontconfig warning: "/opt/homebrew/etc/fonts/conf.d/48-guessfamily.conf", line 136: invalid constant used : cursive
Fontconfig warning: "/opt/homebrew/etc/fonts/conf.d/48-guessfamily.conf", line 144: invalid attribute 'xsi:nil'
Fontconfig warning: "/opt/homebrew/etc/fonts/conf.d/48-guessfamily.conf", line 145: invalid constant used : 
Fontconfig warning: "/opt/homebrew/etc/fonts/conf.d/48-guessfamily.conf", line 148: invalid constant used : fantasy
Fontconfig warning: "/opt/homebrew/etc/fonts/conf.d/48-guessfamily.conf", line 156: invalid attribute 'xsi:nil'
Fontconfig warning: "/opt/homebrew/etc/fonts/conf.d/48-guessfamily.conf", line 157: invalid constant used : 
Fontconfig warning: "/opt/homebrew/etc/fonts/conf.d/48-guessfamily.conf", line 160: invalid constant used : ui-sans-serif
Fontconfig warning: "/opt/homebrew/etc/fonts/conf.d/48-guessfamily.conf", line 168: invalid attribute 'xsi:nil'
Fontconfig warning: "/opt/homebrew/etc/fonts/conf.d/48-guessfamily.conf", line 169: invalid constant used : 
Fontconfig warning: "/opt/homebrew/etc/fonts/conf.d/48-guessfamily.conf", line 172: invalid constant used : ui-serif
Fontconfig warning: "/opt/homebrew/etc/fonts/conf.d/48-guessfamily.conf", line 180: invalid attribute 'xsi:nil'
Fontconfig warning: "/opt/homebrew/etc/fonts/conf.d/48-guessfamily.conf", line 181: invalid constant used : 
Fontconfig warning: "/opt/homebrew/etc/fonts/conf.d/48-guessfamily.conf", line 184: invalid constant used : ui-monospace
Fontconfig warning: "/opt/homebrew/etc/fonts/conf.d/48-guessfamily.conf", line 192: invalid attribute 'xsi:nil'
Fontconfig warning: "/opt/homebrew/etc/fonts/conf.d/48-guessfamily.conf", line 193: invalid constant used : 
Fontconfig warning: "/opt/homebrew/etc/fonts/conf.d/48-guessfamily.conf", line 196: invalid constant used : ui-rounded
Fontconfig warning: "/opt/homebrew/etc/fonts/conf.d/48-guessfamily.conf", line 204: invalid attribute 'xsi:nil'
Fontconfig warning: "/opt/homebrew/etc/fonts/conf.d/48-guessfamily.conf", line 205: invalid constant used : 
Fontconfig warning: "/opt/homebrew/etc/fonts/conf.d/48-guessfamily.conf", line 208: invalid constant used : fangsong
Fontconfig warning: "/opt/homebrew/etc/fonts/conf.d/49-sansserif.conf", line 10: invalid constant used : serif
Fontconfig warning: "/opt/homebrew/etc/fonts/conf.d/49-sansserif.conf", line 18: invalid constant used : sans-serif
Fontconfig warning: "/opt/homebrew/etc/fonts/conf.d/49-sansserif.conf", line 26: invalid constant used : monospace
Fontconfig warning: "/opt/homebrew/etc/fonts/conf.d/49-sansserif.conf", line 34: invalid constant used : emoji
Fontconfig warning: "/opt/homebrew/etc/fonts/conf.d/49-sansserif.conf", line 42: invalid constant used : math
Wrote bill of materials to 'ai_context/bom.csv'.
## sch: BOM
$ /Applications/KiCad/KiCad.app/Contents/MacOS/kicad-cli sch export bom --output ai_context/bom.csv --fields Reference,Value,Footprint,QUANTITY,DNP --group-by Value hardware/ai_glasses_carrier.kicad_sch
exit=0

Fontconfig warning: "/opt/homebrew/etc/fonts/conf.d/48-guessfamily.conf", line 19: invalid attribute 'xsi:nil'
Fontconfig warning: "/opt/homebrew/etc/fonts/conf.d/48-guessfamily.conf", line 20: invalid constant used : 
Fontconfig warning: "/opt/homebrew/etc/fonts/conf.d/48-guessfamily.conf", line 23: invalid constant used : monospace
Fontconfig warning: "/opt/homebrew/etc/fonts/conf.d/48-guessfamily.conf", line 42: invalid attribute 'xsi:nil'
Fontconfig warning: "/opt/homebrew/etc/fonts/conf.d/48-guessfamily.conf", line 43: invalid constant used : 
Fontconfig warning: "/opt/homebrew/etc/fonts/conf.d/48-guessfamily.conf", line 46: invalid constant used : sans-serif
Fontconfig warning: "/opt/homebrew/etc/fonts/conf.d/48-guessfamily.conf", line 68: invalid attribute 'xsi:nil'
Fontconfig warning: "/opt/homebrew/etc/fonts/conf.d/48-guessfamily.conf", line 69: invalid constant used : 
Fontconfig warning: "/opt/homebrew/etc/fonts/conf.d/48-guessfamily.conf", line 72: invalid constant used : serif
Fontconfig warning: "/opt/homebrew/etc/fonts/conf.d/48-guessfamily.conf", line 88: invalid attribute 'xsi:nil'
Fontconfig warning: "/opt/homebrew/etc/fonts/conf.d/48-guessfamily.conf", line 89: invalid constant used : 
Fontconfig warning: "/opt/homebrew/etc/fonts/conf.d/48-guessfamily.conf", line 92: invalid constant used : emoji
Fontconfig warning: "/opt/homebrew/etc/fonts/conf.d/48-guessfamily.conf", line 108: invalid attribute 'xsi:nil'
Fontconfig warning: "/opt/homebrew/etc/fonts/conf.d/48-guessfamily.conf", line 109: invalid constant used : 
Fontconfig warning: "/opt/homebrew/etc/fonts/conf.d/48-guessfamily.conf", line 112: invalid constant used : math
Fontconfig warning: "/opt/homebrew/etc/fonts/conf.d/48-guessfamily.conf", line 120: invalid attribute 'xsi:nil'
Fontconfig warning: "/opt/homebrew/etc/fonts/conf.d/48-guessfamily.conf", line 121: invalid constant used : 
Fontconfig warning: "/opt/homebrew/etc/fonts/conf.d/48-guessfamily.conf", line 124: invalid constant used : system-ui
Fontconfig warning: "/opt/homebrew/etc/fonts/conf.d/48-guessfamily.conf", line 132: invalid attribute 'xsi:nil'
Fontconfig warning: "/opt/homebrew/etc/fonts/conf.d/48-guessfamily.conf", line 133: invalid constant used : 
Fontconfig warning: "/opt/homebrew/etc/fonts/conf.d/48-guessfamily.conf", line 136: invalid constant used : cursive
Fontconfig warning: "/opt/homebrew/etc/fonts/conf.d/48-guessfamily.conf", line 144: invalid attribute 'xsi:nil'
Fontconfig warning: "/opt/homebrew/etc/fonts/conf.d/48-guessfamily.conf", line 145: invalid constant used : 
Fontconfig warning: "/opt/homebrew/etc/fonts/conf.d/48-guessfamily.conf", line 148: invalid constant used : fantasy
Fontconfig warning: "/opt/homebrew/etc/fonts/conf.d/48-guessfamily.conf", line 156: invalid attribute 'xsi:nil'
Fontconfig warning: "/opt/homebrew/etc/fonts/conf.d/48-guessfamily.conf", line 157: invalid constant used : 
Fontconfig warning: "/opt/homebrew/etc/fonts/conf.d/48-guessfamily.conf", line 160: invalid constant used : ui-sans-serif
Fontconfig warning: "/opt/homebrew/etc/fonts/conf.d/48-guessfamily.conf", line 168: invalid attribute 'xsi:nil'
Fontconfig warning: "/opt/homebrew/etc/fonts/conf.d/48-guessfamily.conf", line 169: invalid constant used : 
Fontconfig warning: "/opt/homebrew/etc/fonts/conf.d/48-guessfamily.conf", line 172: invalid constant used : ui-serif
Fontconfig warning: "/opt/homebrew/etc/fonts/conf.d/48-guessfamily.conf", line 180: invalid attribute 'xsi:nil'
Fontconfig warning: "/opt/homebrew/etc/fonts/conf.d/48-guessfamily.conf", line 181: invalid constant used : 
Fontconfig warning: "/opt/homebrew/etc/fonts/conf.d/48-guessfamily.conf", line 184: invalid constant used : ui-monospace
Fontconfig warning: "/opt/homebrew/etc/fonts/conf.d/48-guessfamily.conf", line 192: invalid attribute 'xsi:nil'
Fontconfig warning: "/opt/homebrew/etc/fonts/conf.d/48-guessfamily.conf", line 193: invalid constant used : 
Fontconfig warning: "/opt/homebrew/etc/fonts/conf.d/48-guessfamily.conf", line 196: invalid constant used : ui-rounded
Fontconfig warning: "/opt/homebrew/etc/fonts/conf.d/48-guessfamily.conf", line 204: invalid attribute 'xsi:nil'
Fontconfig warning: "/opt/homebrew/etc/fonts/conf.d/48-guessfamily.conf", line 205: invalid constant used : 
Fontconfig warning: "/opt/homebrew/etc/fonts/conf.d/48-guessfamily.conf", line 208: invalid constant used : fangsong
Fontconfig warning: "/opt/homebrew/etc/fonts/conf.d/49-sansserif.conf", line 10: invalid constant used : serif
Fontconfig warning: "/opt/homebrew/etc/fonts/conf.d/49-sansserif.conf", line 18: invalid constant used : sans-serif
Fontconfig warning: "/opt/homebrew/etc/fonts/conf.d/49-sansserif.conf", line 26: invalid constant used : monospace
Fontconfig warning: "/opt/homebrew/etc/fonts/conf.d/49-sansserif.conf", line 34: invalid constant used : emoji
Fontconfig warning: "/opt/homebrew/etc/fonts/conf.d/49-sansserif.conf", line 42: invalid constant used : math
Found 0 violations
Saved ERC Report to ai_context/erc.report.txt
## sch: ERC (report)
$ /Applications/KiCad/KiCad.app/Contents/MacOS/kicad-cli sch erc --severity-all --format report --output ai_context/erc.report.txt hardware/ai_glasses_carrier.kicad_sch
exit=0

Fontconfig warning: "/opt/homebrew/etc/fonts/conf.d/48-guessfamily.conf", line 19: invalid attribute 'xsi:nil'
Fontconfig warning: "/opt/homebrew/etc/fonts/conf.d/48-guessfamily.conf", line 20: invalid constant used : 
Fontconfig warning: "/opt/homebrew/etc/fonts/conf.d/48-guessfamily.conf", line 23: invalid constant used : monospace
Fontconfig warning: "/opt/homebrew/etc/fonts/conf.d/48-guessfamily.conf", line 42: invalid attribute 'xsi:nil'
Fontconfig warning: "/opt/homebrew/etc/fonts/conf.d/48-guessfamily.conf", line 43: invalid constant used : 
Fontconfig warning: "/opt/homebrew/etc/fonts/conf.d/48-guessfamily.conf", line 46: invalid constant used : sans-serif
Fontconfig warning: "/opt/homebrew/etc/fonts/conf.d/48-guessfamily.conf", line 68: invalid attribute 'xsi:nil'
Fontconfig warning: "/opt/homebrew/etc/fonts/conf.d/48-guessfamily.conf", line 69: invalid constant used : 
Fontconfig warning: "/opt/homebrew/etc/fonts/conf.d/48-guessfamily.conf", line 72: invalid constant used : serif
Fontconfig warning: "/opt/homebrew/etc/fonts/conf.d/48-guessfamily.conf", line 88: invalid attribute 'xsi:nil'
Fontconfig warning: "/opt/homebrew/etc/fonts/conf.d/48-guessfamily.conf", line 89: invalid constant used : 
Fontconfig warning: "/opt/homebrew/etc/fonts/conf.d/48-guessfamily.conf", line 92: invalid constant used : emoji
Fontconfig warning: "/opt/homebrew/etc/fonts/conf.d/48-guessfamily.conf", line 108: invalid attribute 'xsi:nil'
Fontconfig warning: "/opt/homebrew/etc/fonts/conf.d/48-guessfamily.conf", line 109: invalid constant used : 
Fontconfig warning: "/opt/homebrew/etc/fonts/conf.d/48-guessfamily.conf", line 112: invalid constant used : math
Fontconfig warning: "/opt/homebrew/etc/fonts/conf.d/48-guessfamily.conf", line 120: invalid attribute 'xsi:nil'
Fontconfig warning: "/opt/homebrew/etc/fonts/conf.d/48-guessfamily.conf", line 121: invalid constant used : 
Fontconfig warning: "/opt/homebrew/etc/fonts/conf.d/48-guessfamily.conf", line 124: invalid constant used : system-ui
Fontconfig warning: "/opt/homebrew/etc/fonts/conf.d/48-guessfamily.conf", line 132: invalid attribute 'xsi:nil'
Fontconfig warning: "/opt/homebrew/etc/fonts/conf.d/48-guessfamily.conf", line 133: invalid constant used : 
Fontconfig warning: "/opt/homebrew/etc/fonts/conf.d/48-guessfamily.conf", line 136: invalid constant used : cursive
Fontconfig warning: "/opt/homebrew/etc/fonts/conf.d/48-guessfamily.conf", line 144: invalid attribute 'xsi:nil'
Fontconfig warning: "/opt/homebrew/etc/fonts/conf.d/48-guessfamily.conf", line 145: invalid constant used : 
Fontconfig warning: "/opt/homebrew/etc/fonts/conf.d/48-guessfamily.conf", line 148: invalid constant used : fantasy
Fontconfig warning: "/opt/homebrew/etc/fonts/conf.d/48-guessfamily.conf", line 156: invalid attribute 'xsi:nil'
Fontconfig warning: "/opt/homebrew/etc/fonts/conf.d/48-guessfamily.conf", line 157: invalid constant used : 
Fontconfig warning: "/opt/homebrew/etc/fonts/conf.d/48-guessfamily.conf", line 160: invalid constant used : ui-sans-serif
Fontconfig warning: "/opt/homebrew/etc/fonts/conf.d/48-guessfamily.conf", line 168: invalid attribute 'xsi:nil'
Fontconfig warning: "/opt/homebrew/etc/fonts/conf.d/48-guessfamily.conf", line 169: invalid constant used : 
Fontconfig warning: "/opt/homebrew/etc/fonts/conf.d/48-guessfamily.conf", line 172: invalid constant used : ui-serif
Fontconfig warning: "/opt/homebrew/etc/fonts/conf.d/48-guessfamily.conf", line 180: invalid attribute 'xsi:nil'
Fontconfig warning: "/opt/homebrew/etc/fonts/conf.d/48-guessfamily.conf", line 181: invalid constant used : 
Fontconfig warning: "/opt/homebrew/etc/fonts/conf.d/48-guessfamily.conf", line 184: invalid constant used : ui-monospace
Fontconfig warning: "/opt/homebrew/etc/fonts/conf.d/48-guessfamily.conf", line 192: invalid attribute 'xsi:nil'
Fontconfig warning: "/opt/homebrew/etc/fonts/conf.d/48-guessfamily.conf", line 193: invalid constant used : 
Fontconfig warning: "/opt/homebrew/etc/fonts/conf.d/48-guessfamily.conf", line 196: invalid constant used : ui-rounded
Fontconfig warning: "/opt/homebrew/etc/fonts/conf.d/48-guessfamily.conf", line 204: invalid attribute 'xsi:nil'
Fontconfig warning: "/opt/homebrew/etc/fonts/conf.d/48-guessfamily.conf", line 205: invalid constant used : 
Fontconfig warning: "/opt/homebrew/etc/fonts/conf.d/48-guessfamily.conf", line 208: invalid constant used : fangsong
Fontconfig warning: "/opt/homebrew/etc/fonts/conf.d/49-sansserif.conf", line 10: invalid constant used : serif
Fontconfig warning: "/opt/homebrew/etc/fonts/conf.d/49-sansserif.conf", line 18: invalid constant used : sans-serif
Fontconfig warning: "/opt/homebrew/etc/fonts/conf.d/49-sansserif.conf", line 26: invalid constant used : monospace
Fontconfig warning: "/opt/homebrew/etc/fonts/conf.d/49-sansserif.conf", line 34: invalid constant used : emoji
Fontconfig warning: "/opt/homebrew/etc/fonts/conf.d/49-sansserif.conf", line 42: invalid constant used : math
Found 0 violations
Saved ERC Report to ai_context/erc.json
## sch: ERC (json)
$ /Applications/KiCad/KiCad.app/Contents/MacOS/kicad-cli sch erc --severity-all --format json --output ai_context/erc.json hardware/ai_glasses_carrier.kicad_sch
exit=0

[33;1mThis command has deprecated behavior as of KiCad 9.0, the default behavior of this command will change in a future release.[0m
[33;1mThe new behavior will match --mode-multi[0m
Plotted to 'ai_context/pcb.svg'.
Done.
## pcb: SVG
$ /Applications/KiCad/KiCad.app/Contents/MacOS/kicad-cli pcb export svg --output ai_context/pcb.svg --layers Edge.Cuts,F.Cu,B.Cu,F.Silkscreen,F.Fab --page-size-mode 2 hardware/ai_glasses_carrier.kicad_pcb
exit=0

Found 0 violations
Found 0 unconnected items
Saved DRC Report to ai_context/drc.report.txt
## pcb: DRC (report)
$ /Applications/KiCad/KiCad.app/Contents/MacOS/kicad-cli pcb drc --severity-all --format report --output ai_context/drc.report.txt hardware/ai_glasses_carrier.kicad_pcb
exit=0

Found 0 violations
Found 0 unconnected items
Saved DRC Report to ai_context/drc.json
## pcb: DRC (json)
$ /Applications/KiCad/KiCad.app/Contents/MacOS/kicad-cli pcb drc --severity-all --format json --output ai_context/drc.json hardware/ai_glasses_carrier.kicad_pcb
exit=0

  wrote ai_context/radxa_cm4_pinout_v1.20__Sheet1.csv
  wrote ai_context/radxa_cm4_pinout_v1.20__Sheet1.json
  wrote ai_context/pin_assignment.csv
  wrote ai_context/pin_assignment.json
## xlsx+pinmap -> csv/json
$ /Users/stanley/AI Glasses/.venv/bin/python tools/xlsx_to_ai_context.py
exit=0

[OK] Wrote /Users/stanley/AI Glasses/generated/reports/passive_bom_freeze.csv
[OK] Wrote /Users/stanley/AI Glasses/generated/reports/passive_bom_freeze.json
[OK] Wrote /Users/stanley/AI Glasses/docs/passive_bom_freeze_2026-06-28.md
[OK] Wrote /Users/stanley/AI Glasses/ai_context/passive_bom_freeze.csv
[OK] Wrote /Users/stanley/AI Glasses/ai_context/passive_bom_freeze.json
[OK] Passive BOM freeze covers 59 refs.
## passive BOM freeze -> csv/json
$ /Users/stanley/AI Glasses/.venv/bin/python scripts/audit_passive_bom_freeze.py --write --ai-context
exit=0

  wrote ai_context/cm4_mechanical.json: CM4 module outline = 40.02x54.98 mm
  wrote ai_context/cm4_mechanical.json: CM4 IO Board outline = 160.01x90.02 mm
## dxf -> cm4_mechanical.json
$ /Users/stanley/AI Glasses/.venv/bin/python tools/dxf_facts.py
exit=0

ERC: 0 violation(s) [none]
DRC: 0 violation(s) [none]

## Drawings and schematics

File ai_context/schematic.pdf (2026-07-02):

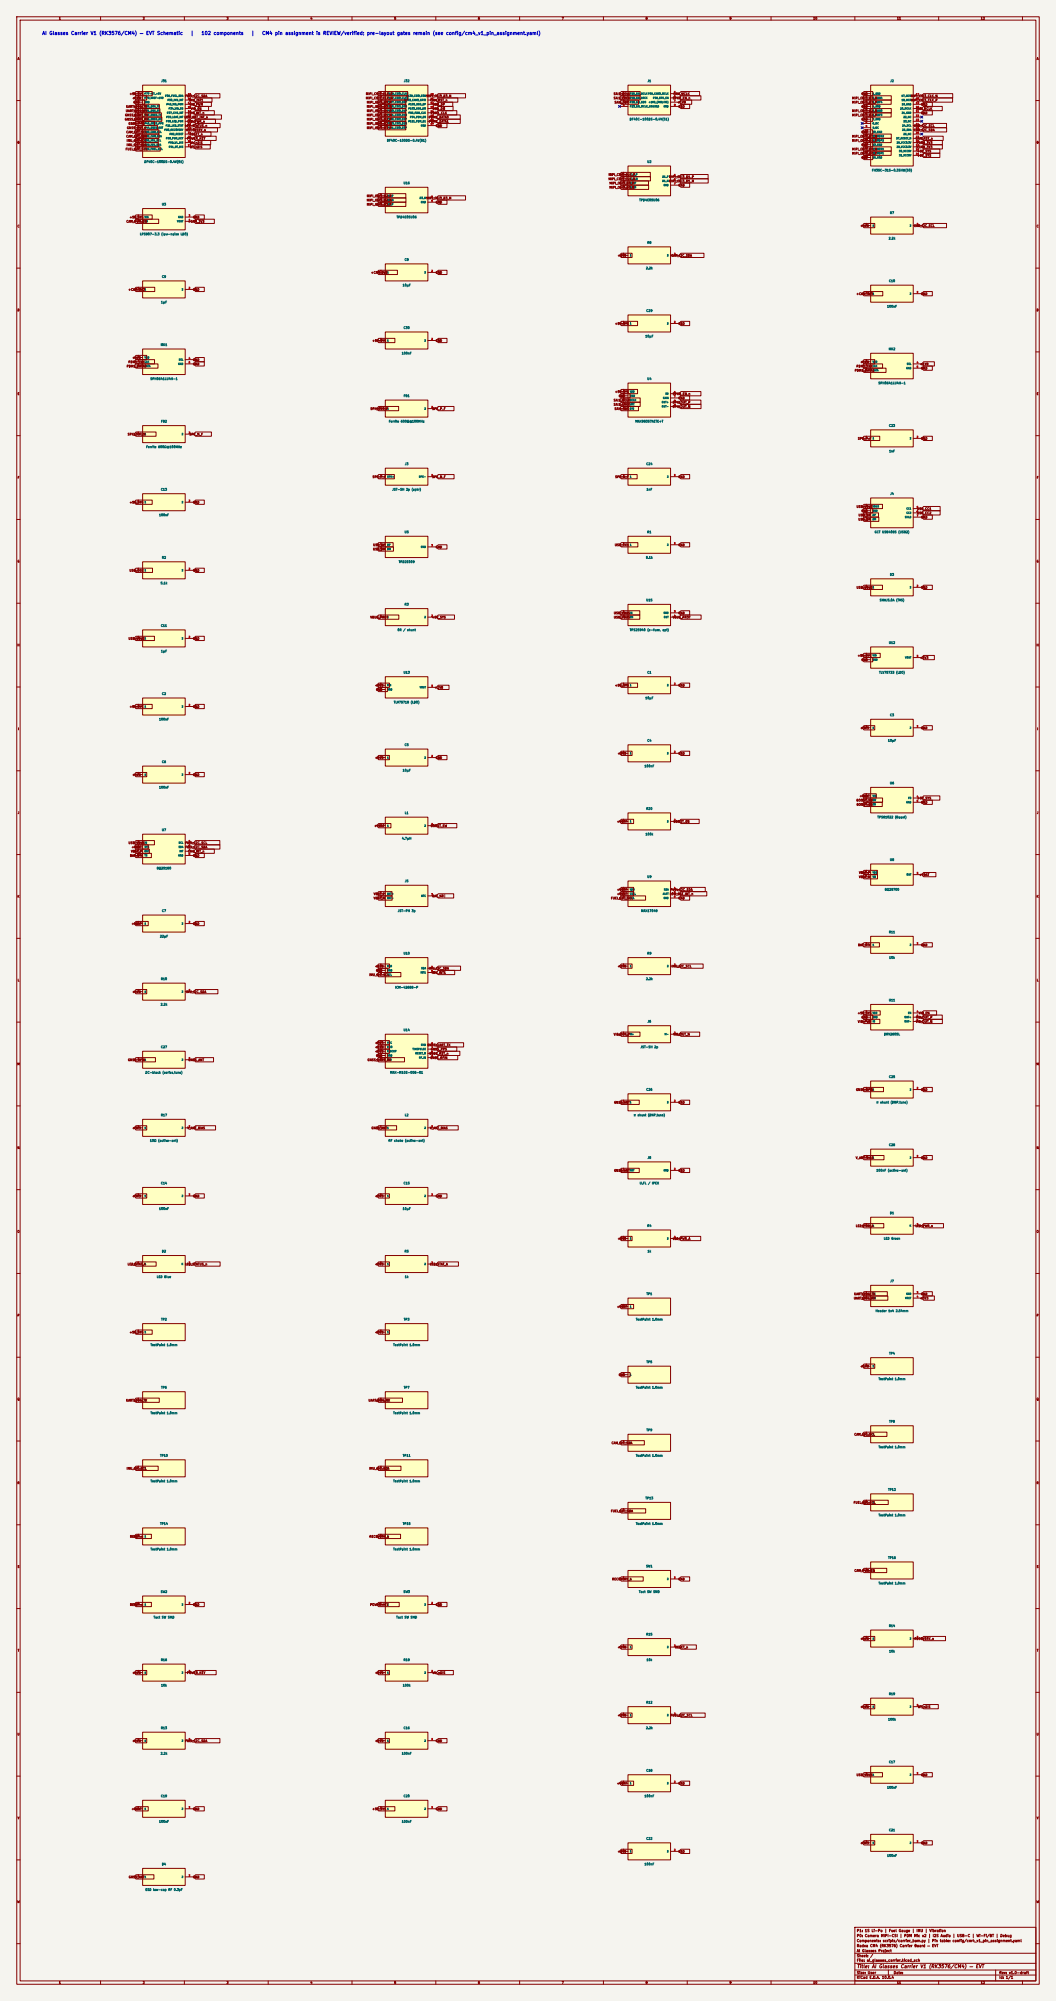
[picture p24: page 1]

GND +5V_SYS AI Glasses Carrier V1 (RK3576/CM4) — EVT Schematic | 102 components | CM4 pin assignment is REVIEW/verified; pre-layout gates remain (see config/cm4_v1_pin_assignment.yaml)

2 C27 DC-block (series,tune) 1

2 L2 RF choke (active-ant)

ESD low-cap RF 0.3pF

P1: 1S Li-Po | Fuel Gauge | IMU | Vibration
P0: Camera MIPI-CSI | PDM Mic x2 | I2S Audio | USB-C | Wi-Fi/BT | Debug
Components: scripts/carrier_bom.py | Pin table: config/cm4_v1_pin_assignment.yaml
Radxa CM4 (RK3576) Carrier Board — EVT
AI Glasses Project
Sheet: /
File: ai_glasses_carrier.kicad_sch
Title: AI Glasses Carrier V1 (RK3576/CM4) — EVT

Size: User | Rev: v1.0-draft
KiCad E.D.A. 10.0.4 | Id: 1/1

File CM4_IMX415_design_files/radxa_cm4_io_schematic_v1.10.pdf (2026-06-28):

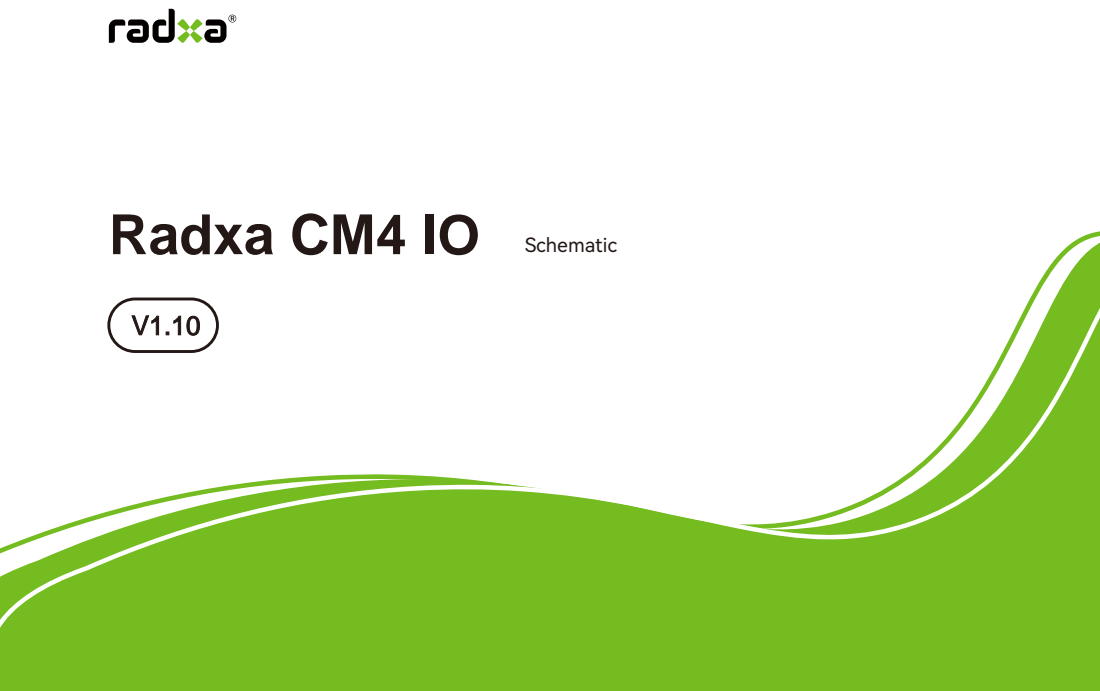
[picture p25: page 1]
Radxa CM4 IO; Schematic

# 02 Table of Content 03 Block Diagram

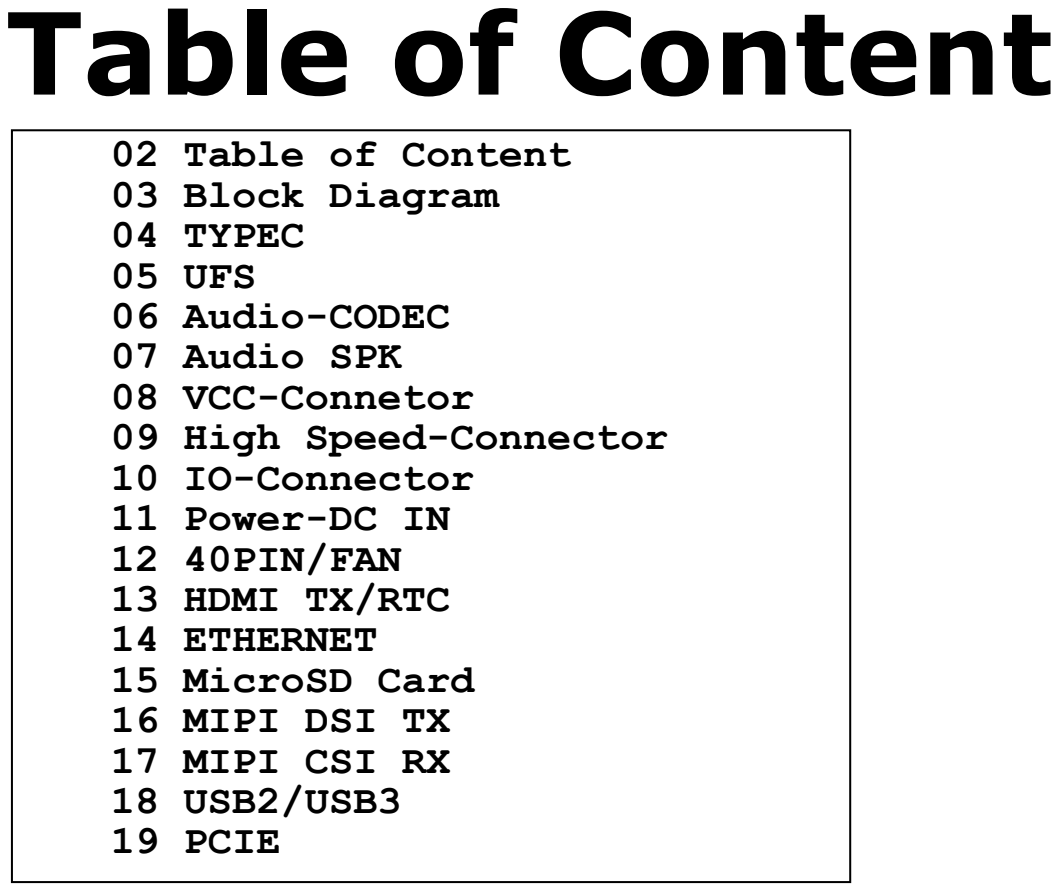
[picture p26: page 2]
Size; REV; Date:; Sheet; Title:; Page Name:; 02 Table of Content; Wednesday, August 06, 2025; 19 Size

Table of Content

04 TYPEC
05 UFS
06 Audio-CODEC
07 Audio SPK
08 VCC-Connetor
09 High Speed-Connector
10 IO-Connector
11 Power-DC IN
12 40PIN/FAN
13 HDMI TX/RTC
14 ETHERNET
15 MicroSD Card
16 MIPI DSI TX
17 MIPI CSI RX
18 USB2/USB3
19 PCIE

# 12V_OUT 5V_OUT

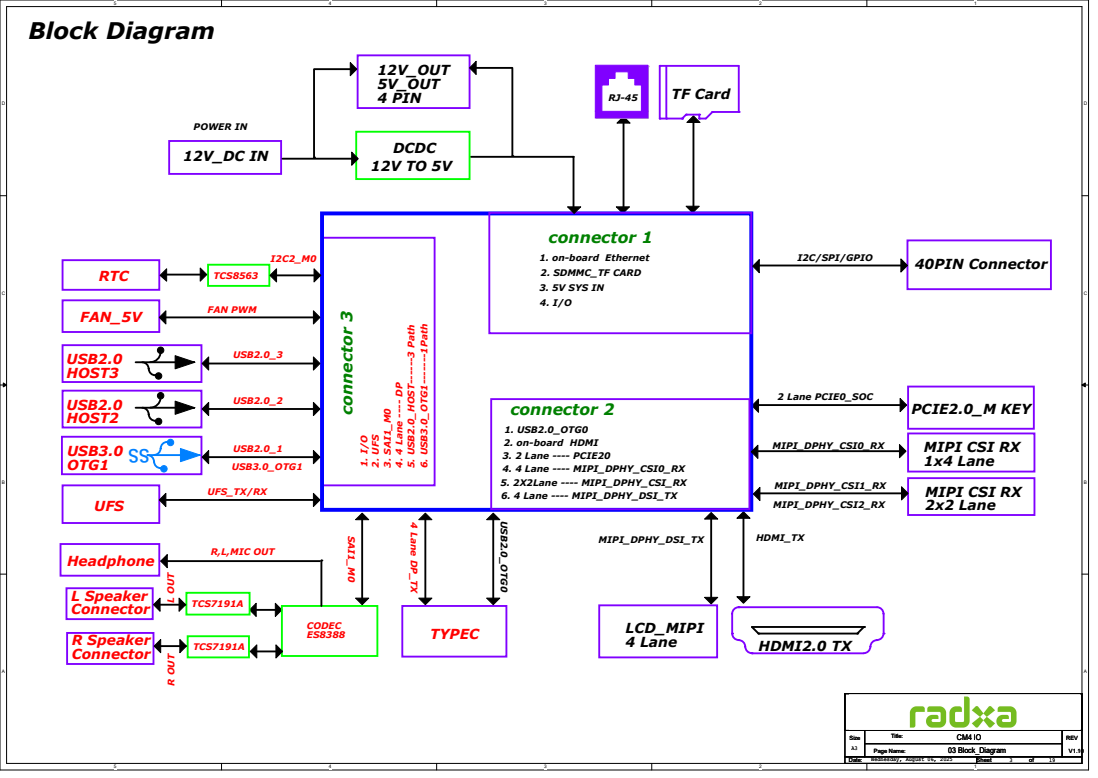
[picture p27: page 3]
HDMI2.0 TX; 4 PIN; 1. I/O 2. UFS; 4. 4 Lane ⁻⁻⁻⁻ DP 5. USB2.0_HOST⁻⁻⁻⁻⁻⁻3 Path 6. USB3.0_OTG¹⁻⁻⁻⁻⁻⁻⁻¹Path connector 3; 3. SAI1_M⁰; FAN_5V; USB3.0; OTG1; Block Diagram; 1. USB2.0_OTG0; 4. 4 Lane ---- MIPI_DPHY_CSI0_RX; connector 1; 5. 2X2Lane ---- MIPI_DPHY_CSI_RX 6. 4 Lane ---- MIPI_DPHY_DSI_TX; 2. on-board HDMI; connector 2; 3. 2 Lane ---- PCIE20; TF Card; DCDC; RTC; LCD_MIPI 4 Lane; 40PIN Connector; TYPEC; PCIE2.0_M KEY; Headphone; R Speaker Connector; UFS; MIPI_DPHY_DSI_TX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

1. on-board Ethernet
2. SDMMC_TF CARD
3. 5V SYS IN

MIPI CSI RX
1x4 Lane
2x2 Lane

R,L,MIC OUT R OUT L OUT

# Type-C PORT

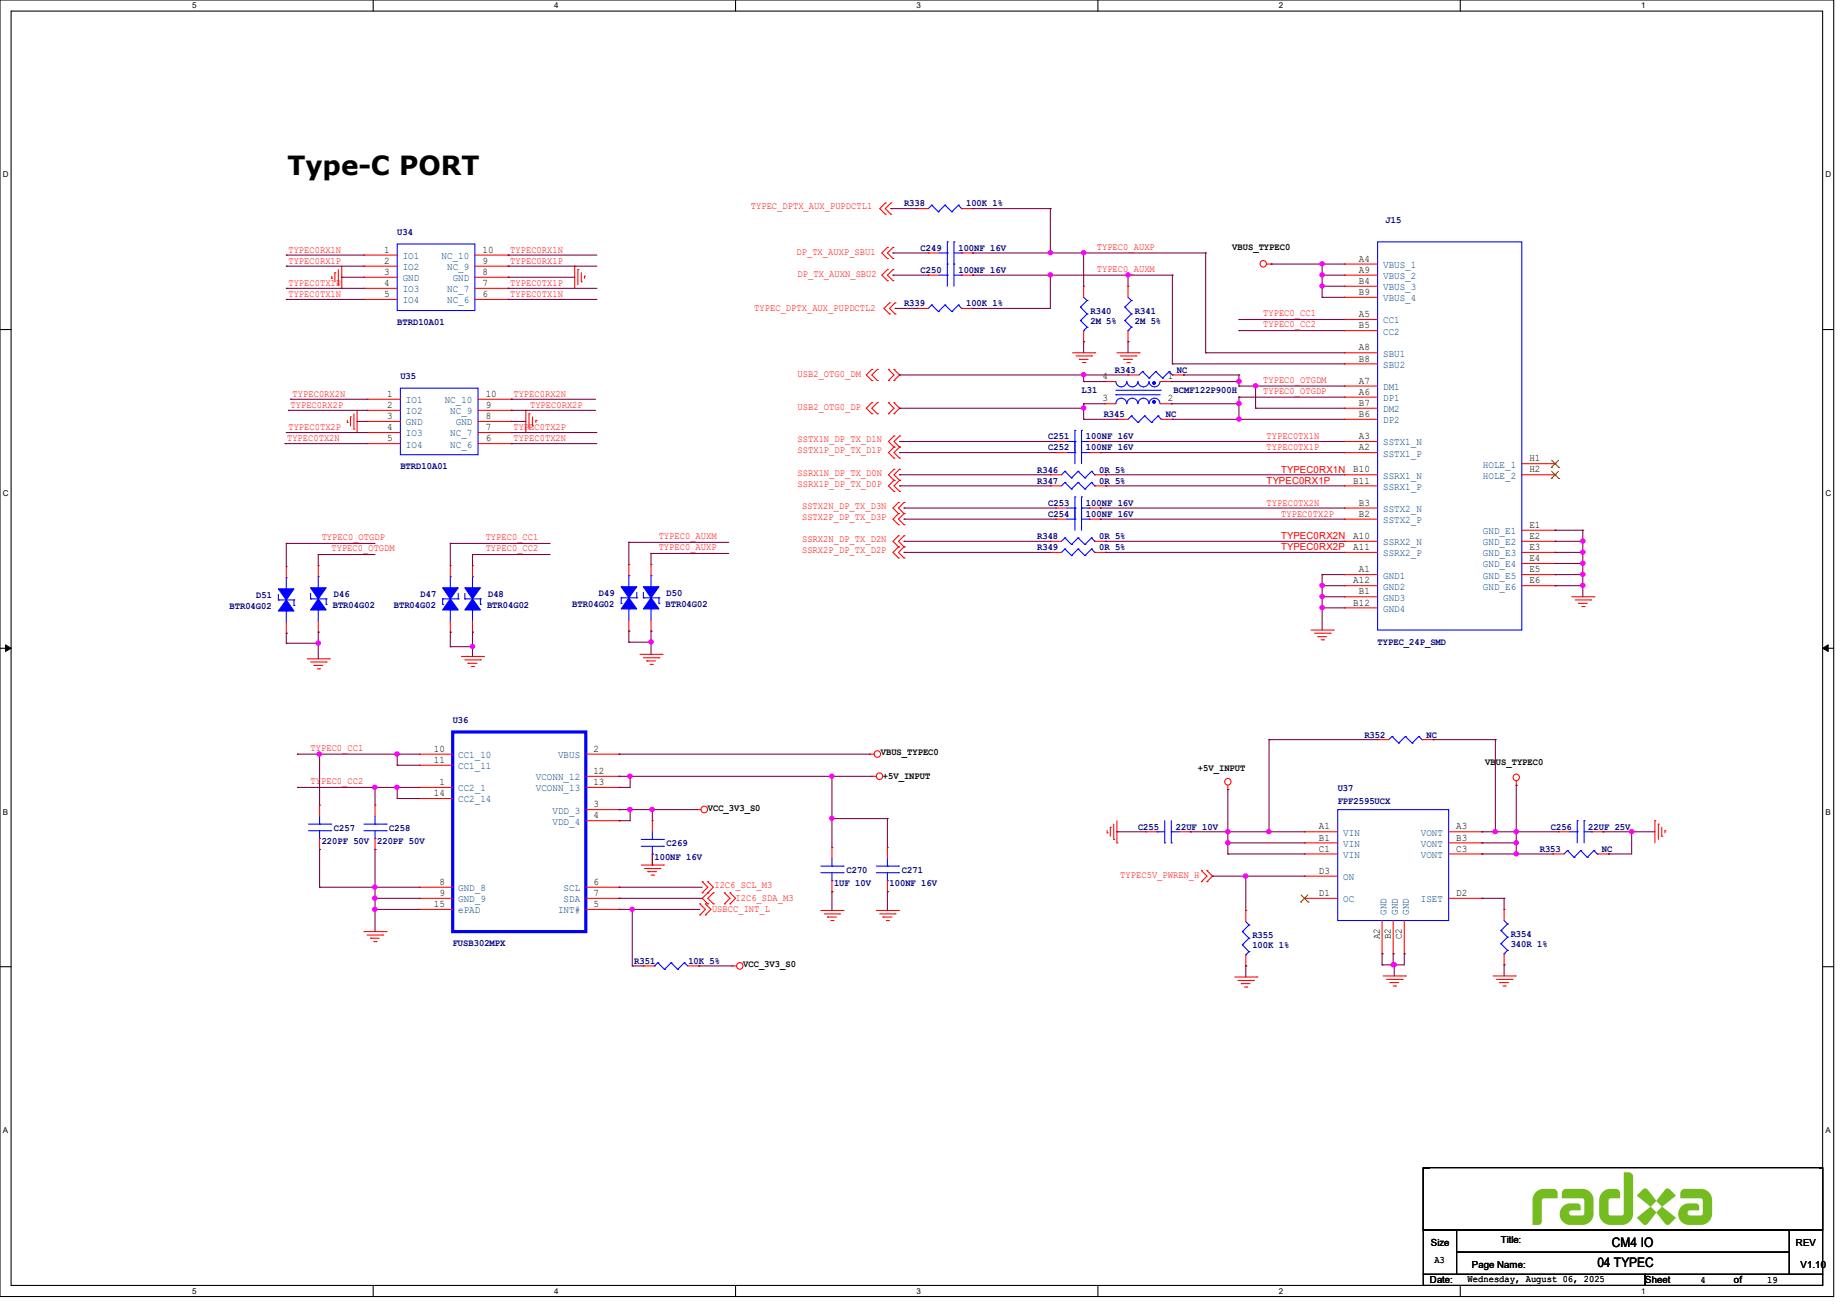
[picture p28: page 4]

# UFS

# UFS POWER

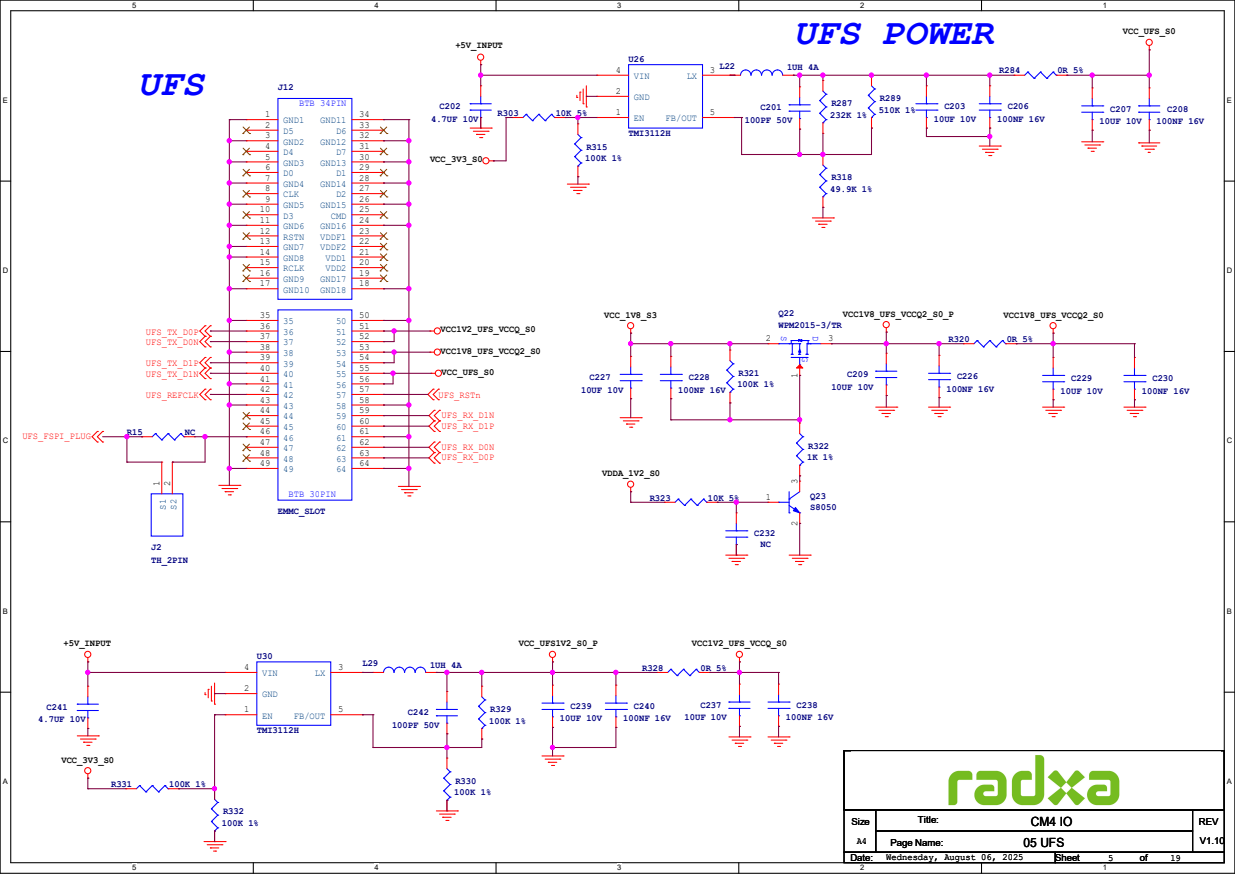
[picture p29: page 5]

# CODEC

3V3_S0 | VCCIO_CODEC | VCCA3V3_CODEC | 3V3_S0

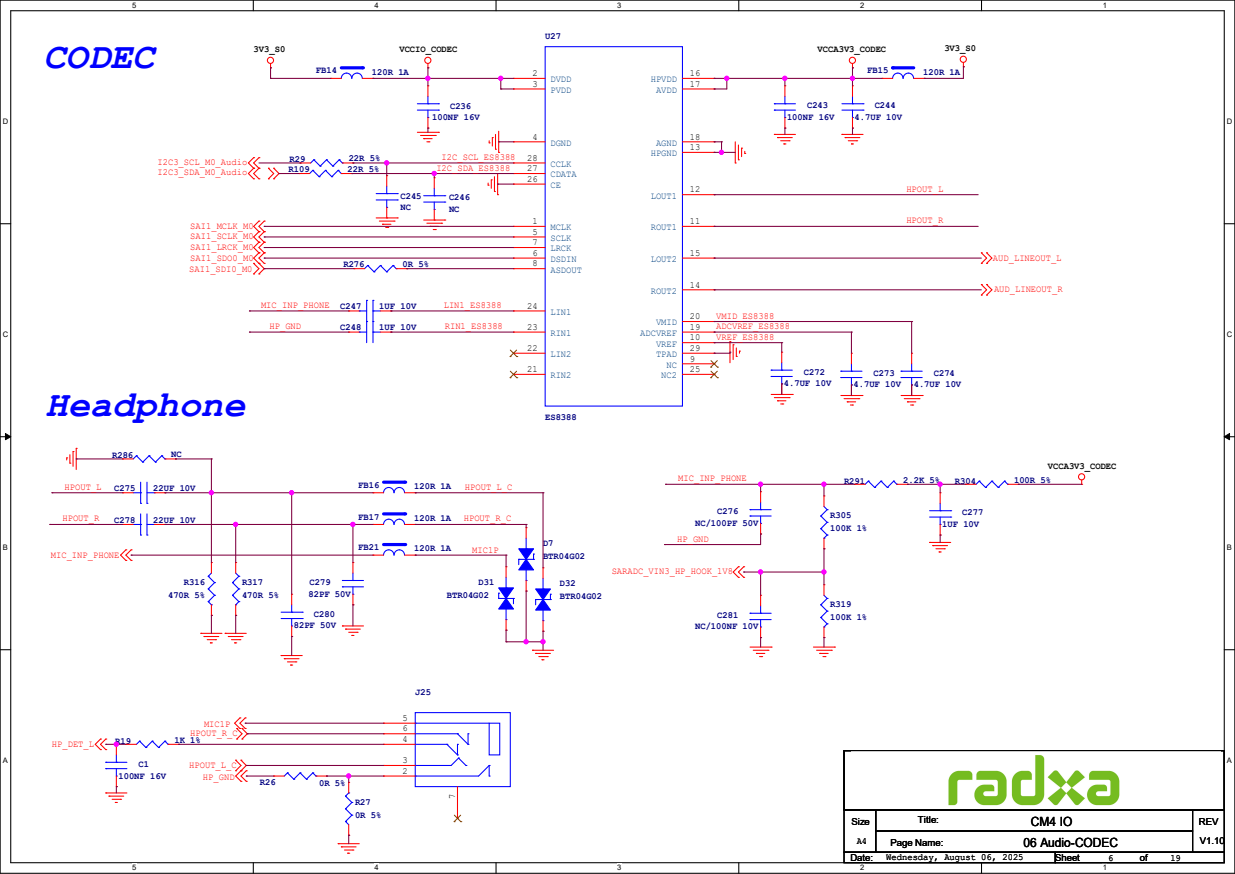
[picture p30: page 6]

# Speaker Output

5V_S0 | 5V_SPK_AMP

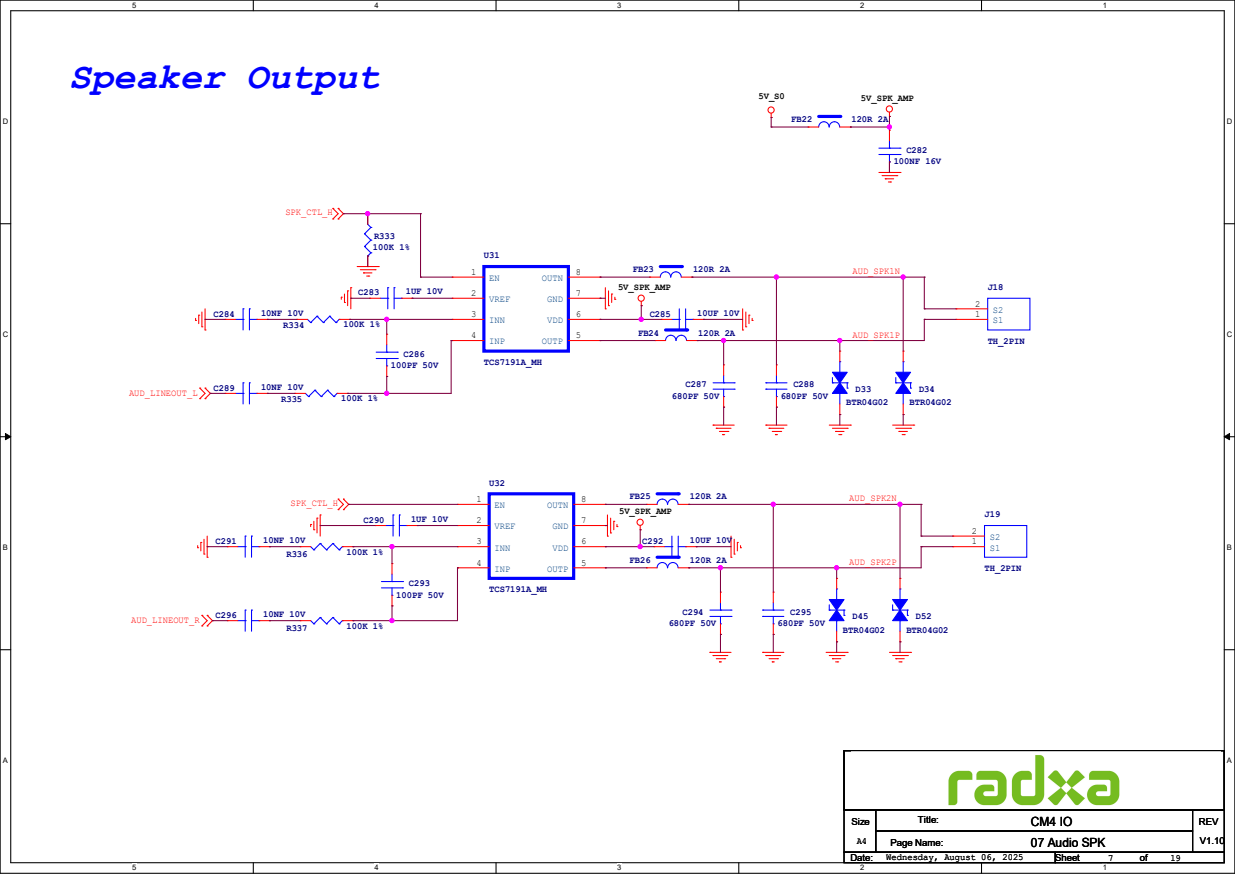
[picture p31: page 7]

AUD_SPK1P

AUD_SPK2N

AUD_SPK2P

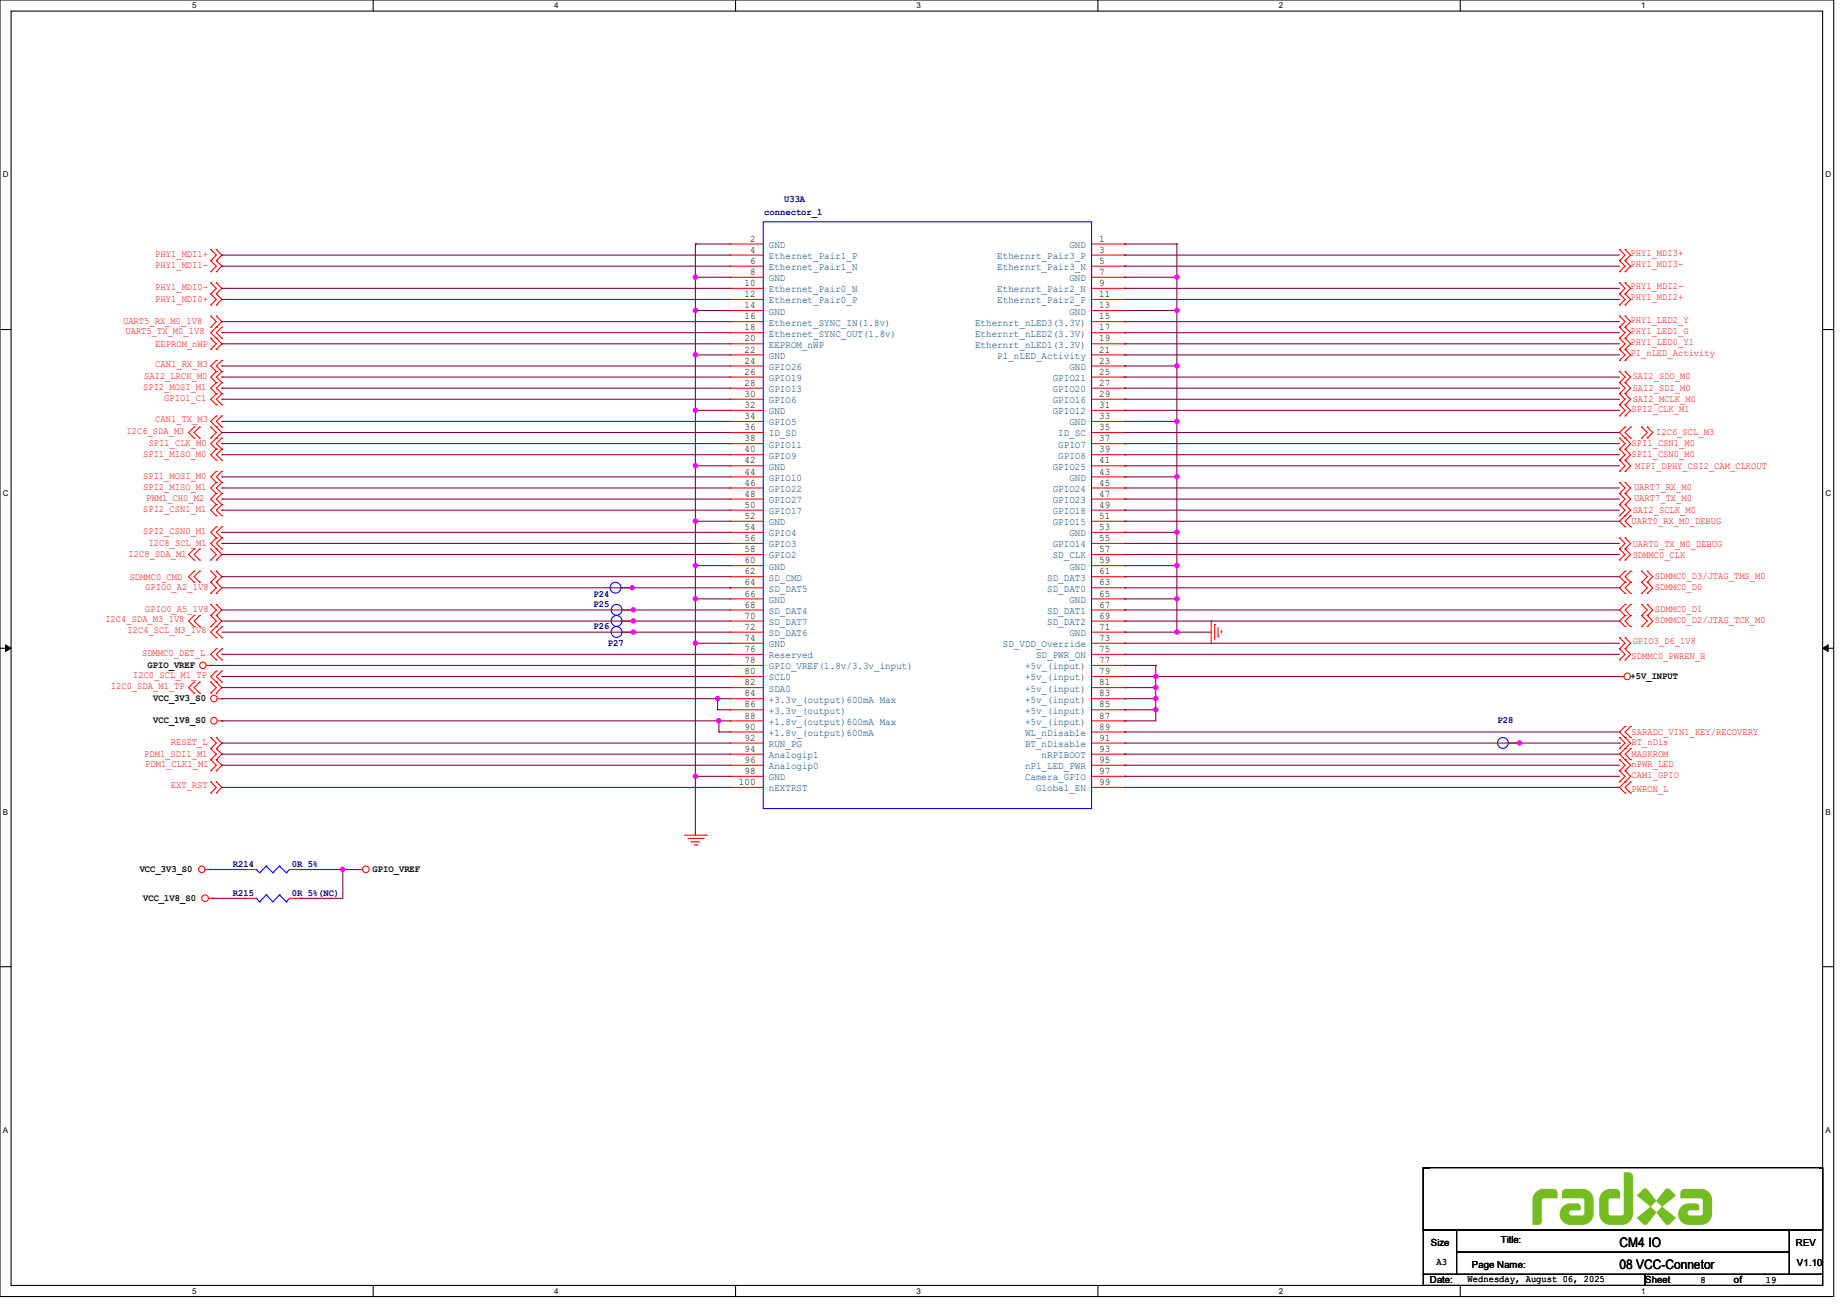
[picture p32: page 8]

Pcie_CLK_nREQ 102 | HOLE 201 | HOLE 202 | HOLE 203 | HOLE 204

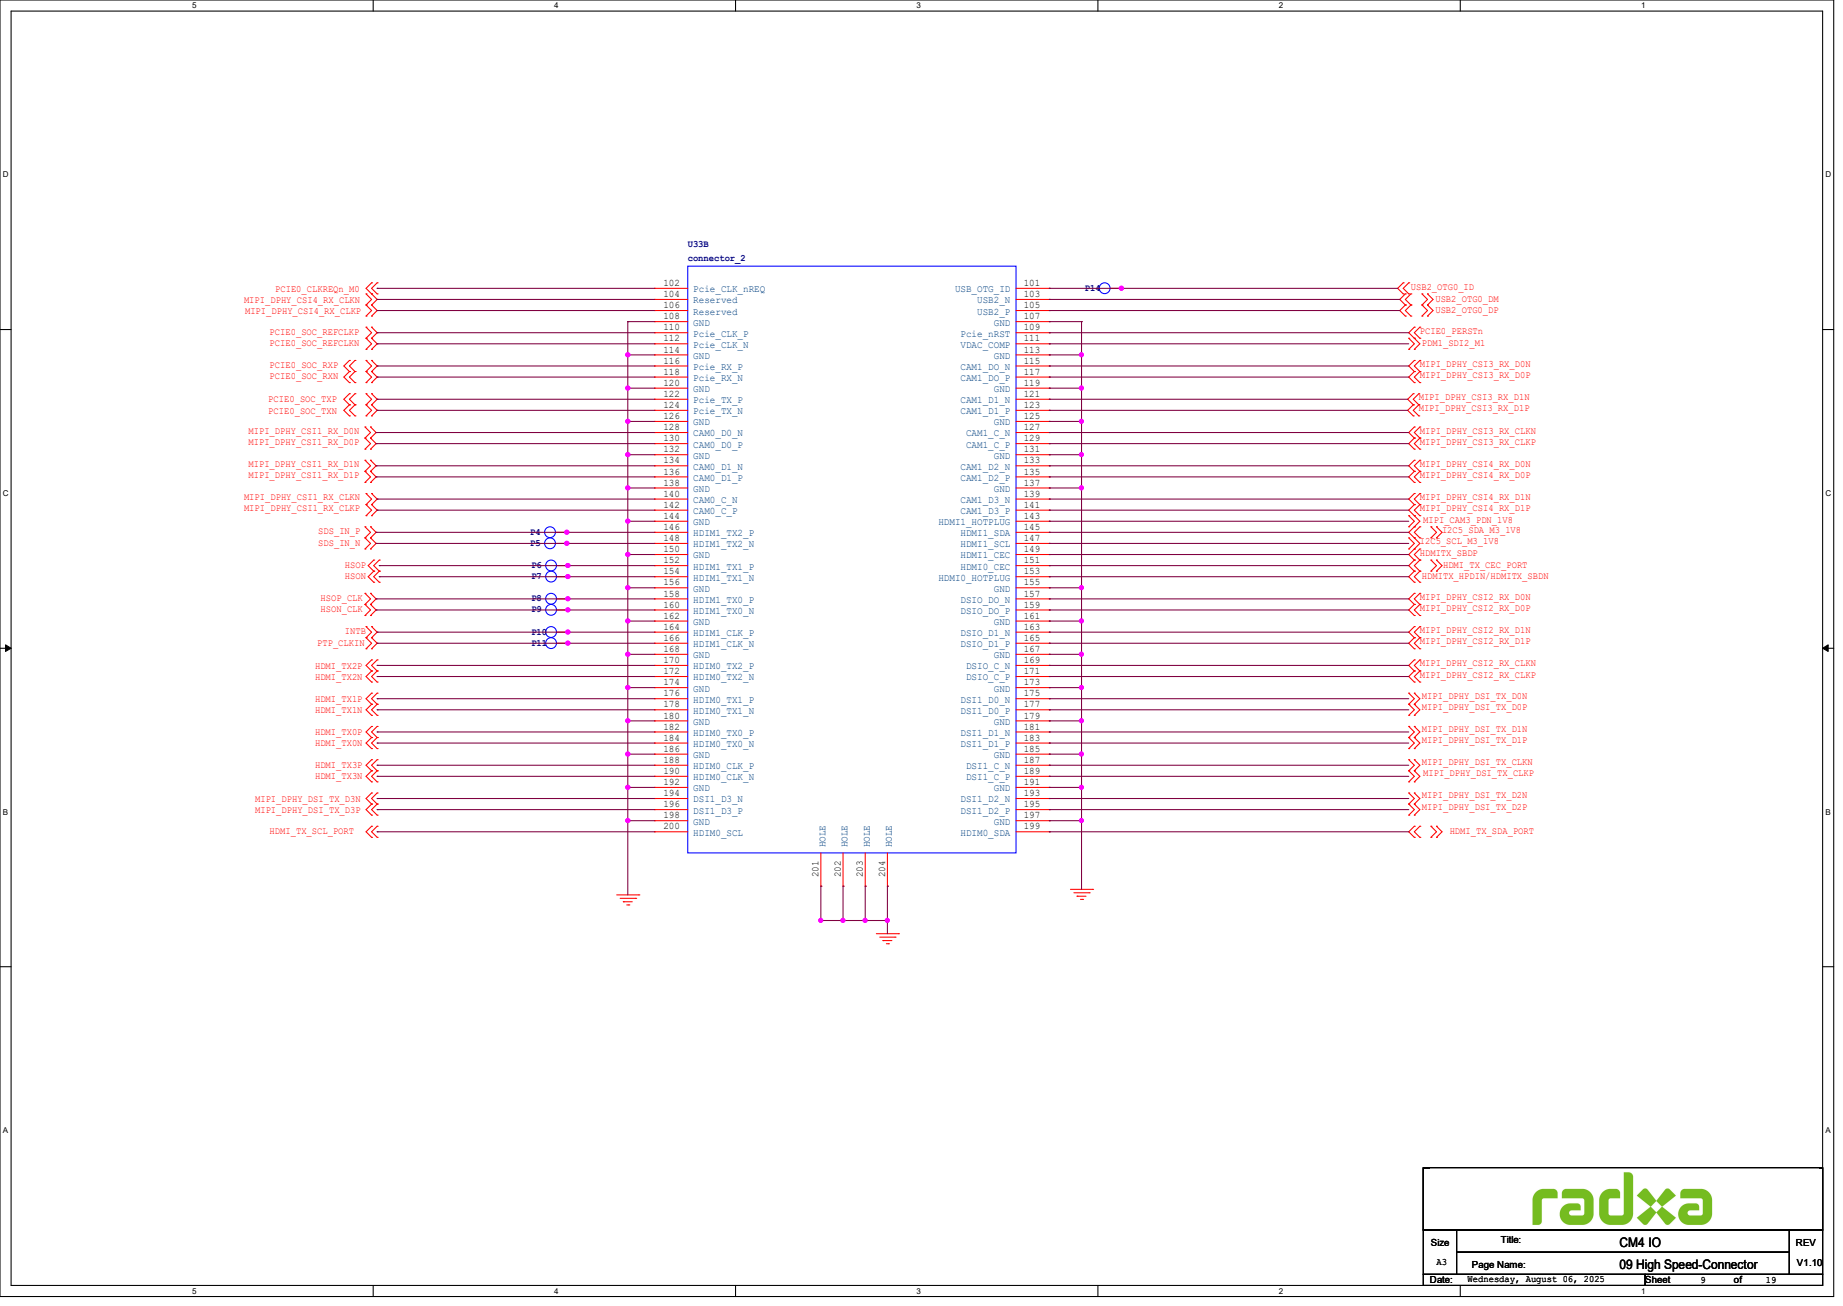
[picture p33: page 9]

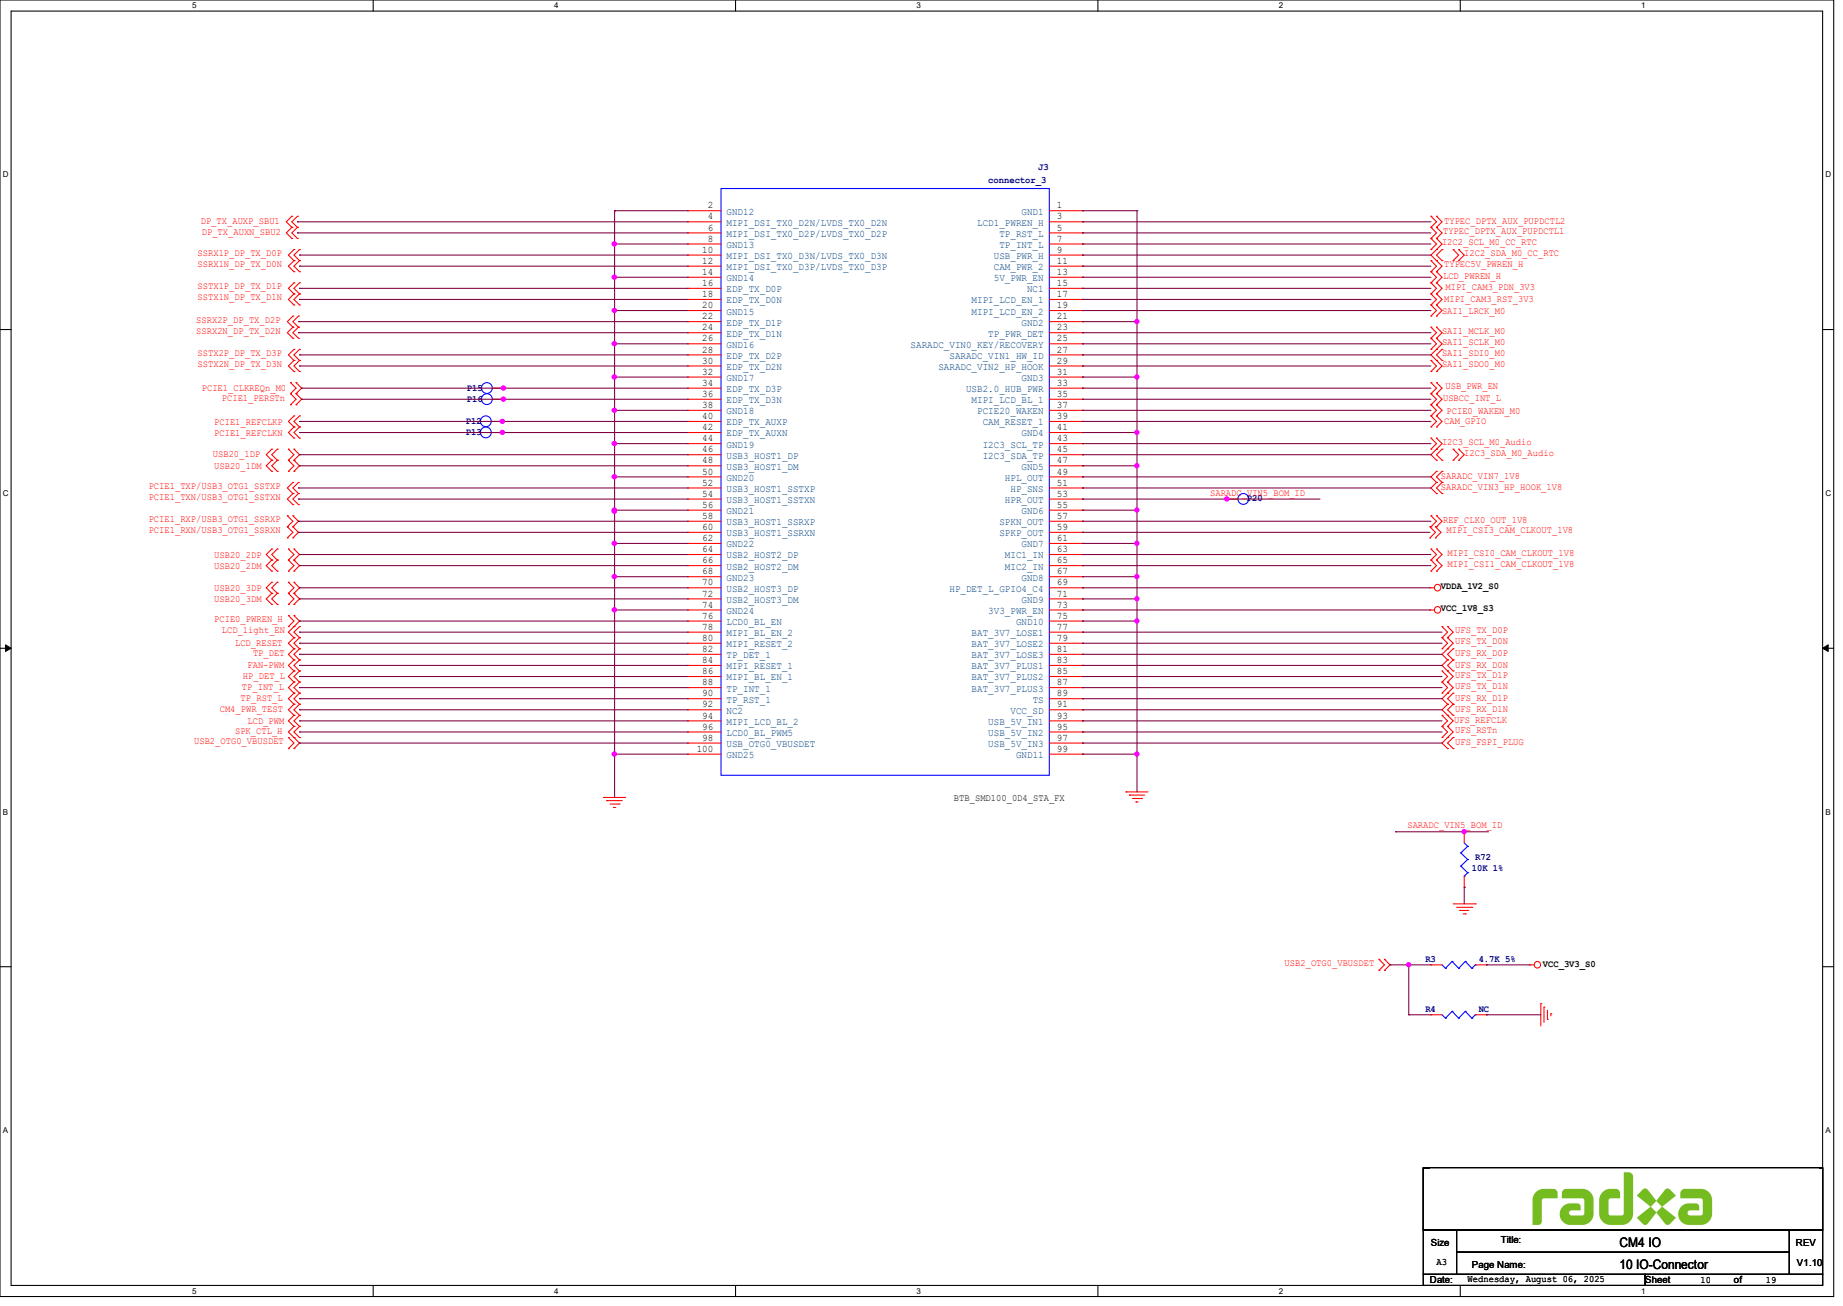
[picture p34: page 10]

# DC IN&SYSTEM Power

# 1 PG

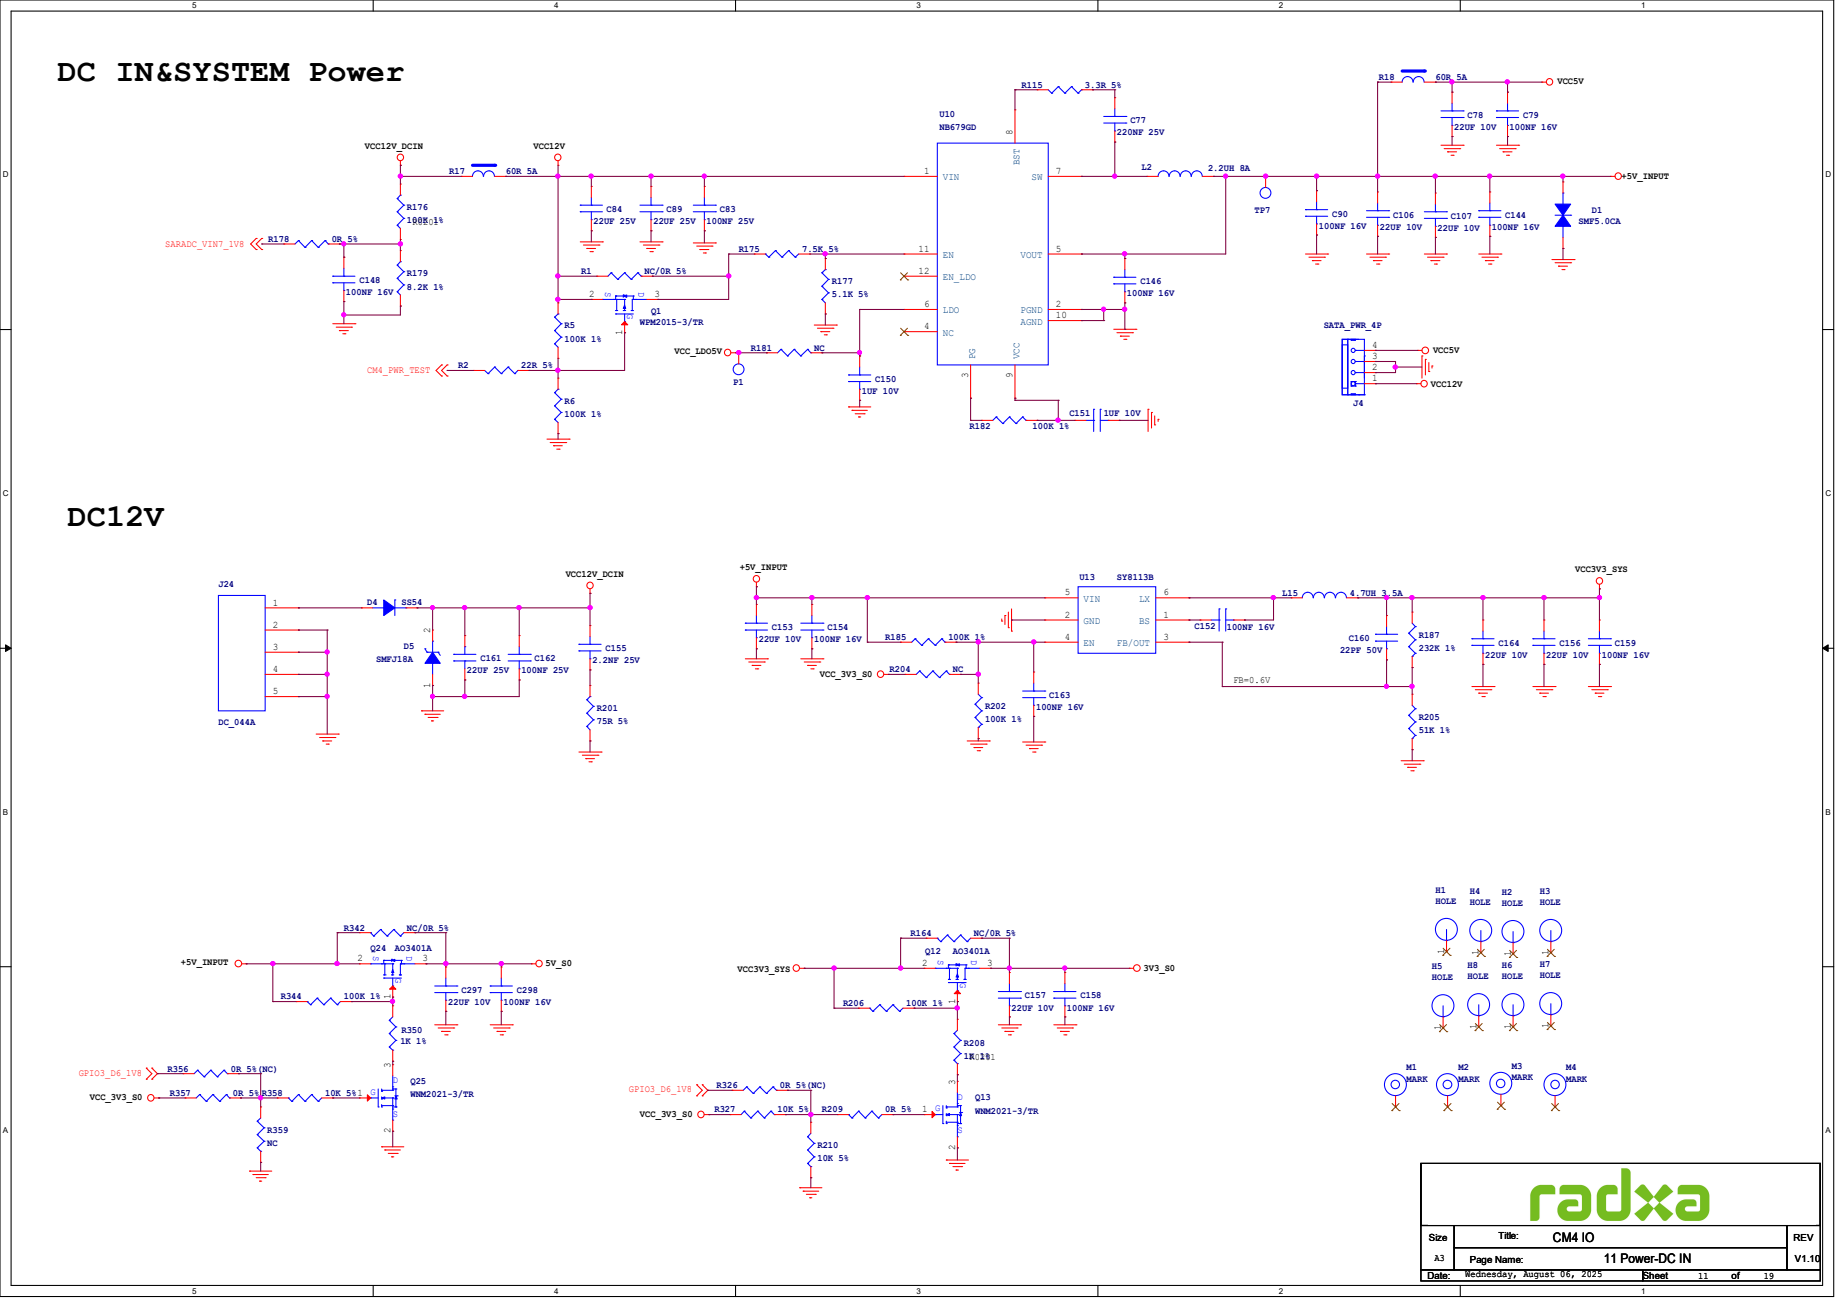
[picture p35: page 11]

# 40 PIN

VCC3V3_SYS | VCC5V


# HDMI TX ARC/HPD HDMI

## HDMI_TX1N


# ETHERNET

## PHY_G_LED+


# MicroSD Card

## SD_3V3


4 5

# MIPI_LCD


MIPI_CSI2_RX 2Lanes | MIPI_CSI1_RX 2Lanes


# USB3.0

+5V_INPUT | 5V_USB_HOST


# PCIe2.0 x 1 Lane

## 3V3_PCIE


PERST# (O)(0/3.3V) or N/C 50
CLKREQ# (IO)(0/3.3V) or N/C 52
PEWake# (IO)(0/3.3V) or N/C 54
Reserved for MFG Data
Reserved for MFG Clock


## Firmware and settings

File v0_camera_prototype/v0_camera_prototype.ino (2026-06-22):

/*
  AI_Goggles V0 camera prototype
  Board: Seeed Studio XIAO ESP32S3 Sense

  Controls:
  - p: take one JPEG photo
  - r: start SD MJPEG recording while Wi-Fi preview remains available
  - x: stop the current SD recording
  - j: start JPEG sequence debug recording
  - m: start SD MJPEG recording
  - v: toggle the Wi-Fi preview server
  - w: print Wi-Fi status and preview URLs
  - s: print next file indexes
  - i: print hardware, memory, SD, and profile info
  - b: run the video smoothness benchmark suite
  - h: print help

  BLE exposes the same single-character commands through device AI_Goggles.
*/

#include <Arduino.h>
#include <BLEDevice.h>
#include <BLEServer.h>
#include <BLEUtils.h>
#include <WiFi.h>
#include <math.h>
#include <stdlib.h>
#include "esp_camera.h"
#include "esp_timer.h"
#include "FS.h"
#include "SD.h"
#include "SPI.h"

#if __has_include("wifi_config.h")
#include "wifi_config.h"
#endif

#ifndef WIFI_SSID
#define WIFI_SSID ""
#endif

#ifndef WIFI_PASSWORD
#define WIFI_PASSWORD ""
#endif

// ============================================================
// User-facing hardware settings
// ============================================================

constexpr int BUTTON_PIN = D1;
constexpr int RECORD_LED_PIN = D2;

constexpr unsigned long DEBOUNCE_MS = 40;
constexpr unsigned long LONG_PRESS_MS = 1000;

constexpr int SD_CS_PIN = 21;
constexpr int SD_SCK_PIN = D8;
constexpr int SD_MISO_PIN = D9;
constexpr int SD_MOSI_PIN = D10;
constexpr uint32_t SD_SAFE_FREQUENCY = 10000000;

constexpr const char *BLE_DEVICE_NAME = "AI_Goggles";
constexpr const char *BLE_SERVICE_UUID = "7b8f0001-2f5d-4d5a-9e4f-7f6a8c8d0001";
constexpr const char *BLE_CONTROL_UUID = "7b8f0002-2f5d-4d5a-9e4f-7f6a8c8d0001";

constexpr size_t MAX_TIMING_FRAMES = 1400;
constexpr uint32_t MIN_FREE_SD_BYTES = 2UL * 1024UL * 1024UL;
constexpr uint16_t HTTP_PORT = 80;
constexpr uint32_t WIFI_CONNECT_TIMEOUT_MS = 12000;
constexpr uint16_t PREVIEW_TARGET_FPS = 10;
constexpr uint8_t PREVIEW_FRAME_DIVIDER = 1;

// ============================================================
// XIAO ESP32S3 Sense camera pin mapping
// ============================================================

constexpr int PWDN_GPIO_NUM = -1;
constexpr int RESET_GPIO_NUM = -1;
constexpr int XCLK_GPIO_NUM = 10;
constexpr int SIOD_GPIO_NUM = 40;
constexpr int SIOC_GPIO_NUM = 39;

constexpr int Y9_GPIO_NUM = 48;
constexpr int Y8_GPIO_NUM = 11;
constexpr int Y7_GPIO_NUM = 12;
constexpr int Y6_GPIO_NUM = 14;
constexpr int Y5_GPIO_NUM = 16;
constexpr int Y4_GPIO_NUM = 18;
constexpr int Y3_GPIO_NUM = 17;
constexpr int Y2_GPIO_NUM = 15;

constexpr int VSYNC_GPIO_NUM = 38;
constexpr int HREF_GPIO_NUM = 47;
constexpr int PCLK_GPIO_NUM = 13;

// ============================================================
// Recording profiles
// ============================================================

enum class StorageMode {
  SEPARATE_JPEG,
  MJPEG_SINGLE_FILE
};

enum class RecordingState {
  IDLE,
  RECORDING_MJPEG,
  RECORDING_JPEG_SEQUENCE,
  STOPPING,
  ERROR
};

struct RecordingProfile {
  const char *name;
  framesize_t frameSize;
  uint16_t width;
  uint16_t height;
  int jpegQuality;
  uint16_t targetFps;
  uint32_t sdFrequency;
  uint16_t durationSeconds;
  StorageMode storageMode;
  camera_grab_mode_t grabMode;
};

constexpr RecordingProfile PROFILES[] = {
  {"A_QVGA_Q15_10FPS_SD10_JPEG", FRAMESIZE_QVGA, 320, 240, 15, 10, 10000000, 10, StorageMode::SEPARATE_JPEG, CAMERA_GRAB_LATEST},
  {"B_QVGA_Q15_15FPS_SD20_JPEG", FRAMESIZE_QVGA, 320, 240, 15, 15, 20000000, 6, StorageMode::SEPARATE_JPEG, CAMERA_GRAB_LATEST},
  {"C_QVGA_Q20_20FPS_SD20_JPEG", FRAMESIZE_QVGA, 320, 240, 20, 20, 20000000, 6, StorageMode::SEPARATE_JPEG, CAMERA_GRAB_LATEST},
  {"D_VGA_Q15_10FPS_SD20_JPEG", FRAMESIZE_VGA, 640, 480, 15, 10, 20000000, 6, StorageMode::SEPARATE_JPEG, CAMERA_GRAB_LATEST},
  {"E_QVGA_Q15_10FPS_SD20_MJPEG", FRAMESIZE_QVGA, 320, 240, 15, 10, 20000000, 10, StorageMode::MJPEG_SINGLE_FILE, CAMERA_GRAB_LATEST},
};

constexpr size_t PROFILE_COUNT = sizeof(PROFILES) / sizeof(PROFILES[0]);
constexpr size_t RECOMMENDED_PROFILE_INDEX = 4;
constexpr size_t JPEG_SEQUENCE_PROFILE_INDEX = 0;

// ============================================================
// Recording measurements
// ============================================================

struct FrameTiming {
  uint32_t captureAttempt;
  uint32_t savedFrameIndex;
  uint64_t scheduledStartUs;
  uint64_t captureStartUs;
  uint64_t frameReadyUs;
  uint32_t captureDurationUs;
  uint32_t sdOpenDurationUs;
  uint32_t sdWriteDurationUs;
  uint32_t sdCloseDurationUs;
  uint32_t previewSendDurationUs;
  uint32_t totalFrameDurationUs;
  uint32_t frameIntervalUs;
  uint32_t jpegSizeBytes;
  bool writeSuccess;
  bool previewSent;
  bool previewDropped;
  bool deadlineMissed;
};

struct RecordingSummary {
  char profileName[40];
  char outputPath[64];
  uint16_t width = 0;
  uint16_t height = 0;
  int jpegQuality = 0;
  uint16_t targetFps = 0;
  uint32_t targetIntervalUs = 0;
  uint32_t requestedSdFrequency = 0;
  uint32_t actualSdFrequency = 0;
  StorageMode storageMode = StorageMode::SEPARATE_JPEG;
  uint16_t durationSeconds = 0;
  uint64_t recordingStartUs = 0;
  uint64_t recordingEndUs = 0;
  uint32_t captureAttempts = 0;
  uint32_t successfulFrames = 0;
  uint32_t failedFrames = 0;
  uint32_t previewFramesSent = 0;
  uint32_t previewFramesDropped = 0;
  uint32_t previewDisconnects = 0;
  uint32_t missedDeadlines = 0;
  uint32_t skippedFrameSlots = 0;
  uint32_t timingRowsStored = 0;
  bool timingTruncated = false;
  bool bleConnected = false;
  uint32_t freeHeapBefore = 0;
  uint32_t freeHeapAfter = 0;
  uint32_t freePsramBefore = 0;
  uint32_t freePsramAfter = 0;
  uint64_t totalBytesWritten = 0;
  uint32_t minJpegBytes = 0;
  uint32_t maxJpegBytes = 0;
  double actualFps = 0.0;
  double avgFrameIntervalUs = 0.0;
  uint32_t minFrameIntervalUs = 0;
  uint32_t maxFrameIntervalUs = 0;
  double stddevFrameIntervalUs = 0.0;
  uint32_t p50FrameIntervalUs = 0;
  uint32_t p95FrameIntervalUs = 0;
  uint32_t p99FrameIntervalUs = 0;
  double avgCaptureUs = 0.0;
  uint32_t p95CaptureUs = 0;
  double avgSdOpenUs = 0.0;
  double avgSdWriteUs = 0.0;
  uint32_t p95SdWriteUs = 0;
  double avgPreviewSendUs = 0.0;
  uint32_t p95PreviewSendUs = 0;
  double avgSdCloseUs = 0.0;
  double avgTotalFrameUs = 0.0;
  double avgJpegBytes = 0.0;
  double throughputKBps = 0.0;
  uint32_t longestStallUs = 0;
  uint64_t sdTotalBytes = 0;
  uint64_t sdUsedBytes = 0;
  uint64_t sdFreeBytes = 0;
};

struct CaptureWriteResult {
  bool success = false;
  uint32_t jpegSizeBytes = 0;
  uint32_t captureDurationUs = 0;
  uint32_t sdOpenDurationUs = 0;
  uint32_t sdWriteDurationUs = 0;
  uint32_t sdCloseDurationUs = 0;
  uint32_t previewSendDurationUs = 0;
  uint64_t captureStartUs = 0;
  uint64_t frameReadyUs = 0;
  bool previewSent = false;
  bool previewDropped = false;
};

struct RecordingSession {
  RecordingState state = RecordingState::IDLE;
  RecordingProfile profile = PROFILES[RECOMMENDED_PROFILE_INDEX];
  RecordingSummary summary;
  File mjpegFile;
  char infoPath[64] = {0};
  char timingPath[64] = {0};
  uint64_t previousCaptureStartUs = 0;
  uint64_t nextFrameDueUs = 0;
  uint32_t savedFrameIndex = 1;
  uint32_t theoreticalFrameSlot = 0;
  uint32_t consecutiveFailures = 0;
  uint32_t previewFramesSentAtStart = 0;
  uint32_t previewFramesDroppedAtStart = 0;
  uint32_t previewDisconnectsAtStart = 0;
  bool fileOpen = false;
};

// ============================================================
// Global state
// ============================================================

uint32_t nextPhotoIndex = 1;
uint32_t nextClipIndex = 1;

bool buttonWasPressed = false;
bool longPressTriggered = false;
unsigned long buttonPressStartMs = 0;
unsigned long lastButtonChangeMs = 0;
int lastRawButtonState = HIGH;
int stableButtonState = HIGH;

BLECharacteristic *bleControlCharacteristic = nullptr;
volatile char pendingBleCommand = '\0';
volatile bool hasPendingBleCommand = false;
bool bleClientConnected = false;

FrameTiming *frameTimings = nullptr;
size_t frameTimingCapacity = MAX_TIMING_FRAMES;
static uint32_t metricScratch[MAX_TIMING_FRAMES];

bool cameraInitialized = false;
bool sdInitialized = false;
framesize_t activeFrameSize = FRAMESIZE_QVGA;
int activeJpegQuality = 15;
camera_grab_mode_t activeGrabMode = CAMERA_GRAB_LATEST;
uint32_t activeSdFrequency = SD_SAFE_FREQUENCY;

RecordingSummary lastBenchmarkSummaries[PROFILE_COUNT];
RecordingSession recordingSession;

WiFiServer httpServer(HTTP_PORT);
WiFiClient previewClient;
bool wifiConfigured = strlen(WIFI_SSID) > 0;
bool wifiConnected = false;
bool previewServerEnabled = true;
bool httpServerStarted = false;
uint32_t previewFramesSent = 0;
uint32_t previewFramesDropped = 0;
uint32_t previewDisconnects = 0;
uint64_t lastPreviewOnlyFrameUs = 0;
uint64_t lastStatusPrintUs = 0;

// ============================================================
// Forward declarations
// ============================================================

void setBleStatus(const String &status);
void queueBleCommand(char command);
void executeCommand(char command, const char *source);
bool recordClip(const RecordingProfile &profile, const char *reason, RecordingSummary *summaryOut);
bool startRecordingSession(const RecordingProfile &profile, const char *reason);
void requestStopRecordingSession(const char *reason);
void updateRecordingSession();
void updatePreviewOnlyCapture();
bool initializeWiFiAndHttp();
void updateHttpServer();
void printWiFiStatus();

class GogglesServerCallbacks : public BLEServerCallbacks {
  void onConnect(BLEServer *server) override {
    (void)server;
    bleClientConnected = true;
    Serial.println("BLE client connected.");
    setBleStatus("connected: write p,r,x,j,m,v,w,s,i,b,h");
  }

  void onDisconnect(BLEServer *server) override {
    bleClientConnected = false;
    Serial.println("BLE client disconnected; advertising restarted.");
    server->startAdvertising();
  }
};

class GogglesControlCallbacks : public BLECharacteristicCallbacks {
  void onWrite(BLECharacteristic *characteristic) override {
    String value = characteristic->getValue();
    if (value.length() > 0) {
      queueBleCommand(value[0]);
    }
  }
};

// ============================================================
// Utility helpers
// ============================================================

uint64_t nowUs() {
  return static_cast<uint64_t>(esp_timer_get_time());
}

const char *storageModeName(StorageMode mode) {
  return mode == StorageMode::SEPARATE_JPEG ? "separate_jpeg" : "mjpeg_single_file";
}

const char *recordingStateName(RecordingState state) {
  switch (state) {
    case RecordingState::IDLE:
      return "idle";
    case RecordingState::RECORDING_MJPEG:
      return "recording_mjpeg";
    case RecordingState::RECORDING_JPEG_SEQUENCE:
      return "recording_jpeg_sequence";
    case RecordingState::STOPPING:
      return "stopping";
    case RecordingState::ERROR:
      return "error";
  }
  return "unknown";
}

const char *grabModeName(camera_grab_mode_t mode) {
  return mode == CAMERA_GRAB_LATEST ? "latest" : "when_empty";
}

bool isRecordingActive() {
  return recordingSession.state == RecordingState::RECORDING_MJPEG ||
         recordingSession.state == RecordingState::RECORDING_JPEG_SEQUENCE ||
         recordingSession.state == RecordingState::STOPPING;
}

void setRecordingLed(bool on) {
  digitalWrite(RECORD_LED_PIN, on ? HIGH : LOW);
}

void blinkRecordingLed(int blinkCount, unsigned long onTimeMs, unsigned long offTimeMs) {
  for (int i = 0; i < blinkCount; ++i) {
    setRecordingLed(true);
    delay(onTimeMs);
    setRecordingLed(false);
    delay(offTimeMs);
  }
}

void fatalBlink(int blinkCount, unsigned long onTimeMs, unsigned long offTimeMs) {
  while (true) {
    blinkRecordingLed(blinkCount, onTimeMs, offTimeMs);
    delay(700);
  }
}

uint32_t estimateRequiredBytes(const RecordingProfile &profile) {
  uint32_t targetFrames = profile.durationSeconds * profile.targetFps;
  uint32_t roughBytesPerFrame = (static_cast<uint32_t>(profile.width) * profile.height) / 4;
  return targetFrames * roughBytesPerFrame + 1024UL * 1024UL;
}

bool loadSdSpace(RecordingSummary *summary) {
  if (!sdInitialized) {
    return false;
  }

  uint64_t totalBytes = SD.totalBytes();
  uint64_t usedBytes = SD.usedBytes();
  uint64_t freeBytes = totalBytes > usedBytes ? totalBytes - usedBytes : 0;

  if (summary != nullptr) {
    summary->sdTotalBytes = totalBytes;
    summary->sdUsedBytes = usedBytes;
    summary->sdFreeBytes = freeBytes;
  }

  Serial.printf("SD total: %llu MB\n", totalBytes / (1024ULL * 1024ULL));
  Serial.printf("SD used: %llu MB\n", usedBytes / (1024ULL * 1024ULL));
  Serial.printf("SD free: %llu MB\n", freeBytes / (1024ULL * 1024ULL));

  return true;
}

// ============================================================
// Camera and SD initialization
// ============================================================

bool initializeCameraForProfile(const RecordingProfile &profile) {
  camera_config_t config;
  config.ledc_channel = LEDC_CHANNEL_0;
  config.ledc_timer = LEDC_TIMER_0;
  config.pin_d0 = Y2_GPIO_NUM;
  config.pin_d1 = Y3_GPIO_NUM;
  config.pin_d2 = Y4_GPIO_NUM;
  config.pin_d3 = Y5_GPIO_NUM;
  config.pin_d4 = Y6_GPIO_NUM;
  config.pin_d5 = Y7_GPIO_NUM;
  config.pin_d6 = Y8_GPIO_NUM;
  config.pin_d7 = Y9_GPIO_NUM;
  config.pin_xclk = XCLK_GPIO_NUM;
  config.pin_pclk = PCLK_GPIO_NUM;
  config.pin_vsync = VSYNC_GPIO_NUM;
  config.pin_href = HREF_GPIO_NUM;
  config.pin_sccb_sda = SIOD_GPIO_NUM;
  config.pin_sccb_scl = SIOC_GPIO_NUM;
  config.pin_pwdn = PWDN_GPIO_NUM;
  config.pin_reset = RESET_GPIO_NUM;
  config.xclk_freq_hz = 20000000;
  config.pixel_format = PIXFORMAT_JPEG;
  config.frame_size = profile.frameSize;
  config.jpeg_quality = profile.jpegQuality;
  config.fb_count = 2;
  config.grab_mode = profile.grabMode;
  config.fb_location = CAMERA_FB_IN_PSRAM;

  if (!psramFound()) {
    Serial.println("ERROR: PSRAM was not detected. Enable OPI PSRAM in board options.");
    config.frame_size = FRAMESIZE_QVGA;
    config.jpeg_quality = 20;
    config.fb_count = 1;
    config.fb_location = CAMERA_FB_IN_DRAM;
  }

  esp_err_t result = esp_camera_init(&config);
  if (result != ESP_OK) {
    Serial.printf("ERROR: Camera initialization failed. Error code: 0x%X\n", result);
    cameraInitialized = false;
    return false;
  }

  sensor_t *sensor = esp_camera_sensor_get();
  if (sensor == nullptr) {
    Serial.println("ERROR: Camera sensor was not found.");
    cameraInitialized = false;
    return false;
  }

  sensor->set_brightness(sensor, 0);
  sensor->set_contrast(sensor, 0);
  sensor->set_saturation(sensor, 0);

  activeFrameSize = profile.frameSize;
  activeJpegQuality = profile.jpegQuality;
  activeGrabMode = profile.grabMode;
  cameraInitialized = true;

  Serial.printf("Camera ready: %s, %ux%u, JPEG quality %d, grab %s\n",
                profile.name, profile.width, profile.height, profile.jpegQuality, grabModeName(profile.grabMode));
  return true;
}

bool ensureCameraForProfile(const RecordingProfile &profile) {
  if (cameraInitialized &&
      activeFrameSize == profile.frameSize &&
      activeJpegQuality == profile.jpegQuality &&
      activeGrabMode == profile.grabMode) {
    return true;
  }

  if (cameraInitialized) {
    esp_camera_deinit();
    cameraInitialized = false;
    delay(100);
  }

  return initializeCameraForProfile(profile);
}

bool mountMicroSD(uint32_t frequency) {
  if (sdInitialized) {
    SD.end();
    sdInitialized = false;
    delay(20);
  }

  SPI.begin(SD_SCK_PIN, SD_MISO_PIN, SD_MOSI_PIN, SD_CS_PIN);

  if (!SD.begin(SD_CS_PIN, SPI, frequency)) {
    Serial.printf("ERROR: microSD init failed at %lu Hz.\n", static_cast<unsigned long>(frequency));
    return false;
  }

  if (SD.cardType() == CARD_NONE) {
    Serial.println("ERROR: No microSD card detected.");
    SD.end();
    return false;
  }

  activeSdFrequency = frequency;
  sdInitialized = true;
  Serial.printf("microSD mounted at %lu Hz.\n", static_cast<unsigned long>(frequency));
  loadSdSpace(nullptr);
  return true;
}

bool ensureSdFrequency(uint32_t requestedFrequency, uint32_t *actualFrequency) {
  if (sdInitialized && activeSdFrequency == requestedFrequency) {
    if (actualFrequency != nullptr) {
      *actualFrequency = activeSdFrequency;
    }
    return true;
  }

  if (mountMicroSD(requestedFrequency)) {
    if (actualFrequency != nullptr) {
      *actualFrequency = requestedFrequency;
    }
    return true;
  }

  if (requestedFrequency != SD_SAFE_FREQUENCY) {
    Serial.println("Falling back to 10 MHz SD SPI.");
    if (mountMicroSD(SD_SAFE_FREQUENCY)) {
      if (actualFrequency != nullptr) {
        *actualFrequency = SD_SAFE_FREQUENCY;
      }
      return true;
    }
  }

  return false;
}

// ============================================================
// BLE control
// ============================================================

void setBleStatus(const String &status) {
  if (bleControlCharacteristic != nullptr) {
    bleControlCharacteristic->setValue(status);
  }
}

void queueBleCommand(char command) {
  if (command >= 'A' && command <= 'Z') {
    command = static_cast<char>(command - 'A' + 'a');
  }

  if (command != 'p' && command != 'r' && command != 'x' && command != 'j' && command != 'm' &&
      command != 'v' && command != 'w' && command != 's' && command != 'h' && command != 'i' && command != 'b') {
    setBleStatus("error: write p,r,x,j,m,v,w,s,i,b,h");
    Serial.printf("BLE ignored unknown command: %c\n", command);
    return;
  }

  pendingBleCommand = command;
  hasPendingBleCommand = true;
  setBleStatus(String("queued: ") + command);
  Serial.printf("BLE queued command: %c\n", command);
}

bool initializeBLE() {
  if (!BLEDevice::init(BLE_DEVICE_NAME)) {
    Serial.println("WARNING: BLE initialization failed.");
    return false;
  }

  BLEServer *server = BLEDevice::createServer();
  server->setCallbacks(new GogglesServerCallbacks());
  server->advertiseOnDisconnect(true);

  BLEService *service = server->createService(BLE_SERVICE_UUID);
  bleControlCharacteristic = service->createCharacteristic(
    BLE_CONTROL_UUID,
    BLECharacteristic::PROPERTY_READ | BLECharacteristic::PROPERTY_WRITE
  );
  bleControlCharacteristic->setCallbacks(new GogglesControlCallbacks());
  setBleStatus("ready: write p,r,x,j,m,v,w,s,i,b,h");

  service->start();

  BLEAdvertising *advertising = BLEDevice::getAdvertising();
  advertising->addServiceUUID(BLE_SERVICE_UUID);
  advertising->setScanResponse(true);
  advertising->setMinPreferred(0x06);
  advertising->setMaxPreferred(0x12);
  BLEDevice::startAdvertising();

  Serial.println("BLE control ready.");
  Serial.printf("BLE device name: %s\n", BLE_DEVICE_NAME);
  Serial.printf("BLE service UUID: %s\n", BLE_SERVICE_UUID);
  Serial.printf("BLE control UUID: %s\n", BLE_CONTROL_UUID);
  return true;
}

// ============================================================
// Filename management
// ============================================================

void makePhotoPath(uint32_t index, char *path, size_t pathSize) {
  snprintf(path, pathSize, "/photo_%04lu.jpg", static_cast<unsigned long>(index));
}

void makeClipDirectory(uint32_t index, char *path, size_t pathSize) {
  snprintf(path, pathSize, "/clip_%04lu", static_cast<unsigned long>(index));
}

void makeFramePath(const char *clipDirectory, uint32_t frameIndex, char *path, size_t pathSize) {
  snprintf(path, pathSize, "%s/frame_%04lu.jpg", clipDirectory, static_cast<unsigned long>(frameIndex));
}

void makeMjpegPath(uint32_t index, char *path, size_t pathSize) {
  snprintf(path, pathSize, "/clip_%04lu.mjpeg", static_cast<unsigned long>(index));
}

void makeMjpegInfoPath(uint32_t index, char *path, size_t pathSize) {
  snprintf(path, pathSize, "/clip_%04lu_info.csv", static_cast<unsigned long>(index));
}

void makeMjpegTimingPath(uint32_t index, char *path, size_t pathSize) {
  snprintf(path, pathSize, "/clip_%04lu_timing.csv", static_cast<unsigned long>(index));
}

bool clipIndexExists(uint32_t index) {
  if (!sdInitialized) {
    return false;
  }

  char path[64];
  makeClipDirectory(index, path, sizeof(path));
  if (SD.exists(path)) {
    return true;
  }
  makeMjpegPath(index, path, sizeof(path));
  if (SD.exists(path)) {
    return true;
  }
  makeMjpegInfoPath(index, path, sizeof(path));
  return SD.exists(path);
}

void findNextAvailableIndexes() {
  if (!sdInitialized) {
    Serial.println("microSD is not mounted; file indexes will be scanned after SD is available.");
    nextPhotoIndex = 1;
    nextClipIndex = 1;
    return;
  }

  char path[64];
  nextPhotoIndex = 1;
  makePhotoPath(nextPhotoIndex, path, sizeof(path));
  while (SD.exists(path)) {
    ++nextPhotoIndex;
    makePhotoPath(nextPhotoIndex, path, sizeof(path));
  }

  nextClipIndex = 1;
  while (clipIndexExists(nextClipIndex)) {
    ++nextClipIndex;
  }

  Serial.printf("Next photo index: %lu\n", static_cast<unsigned long>(nextPhotoIndex));
  Serial.printf("Next clip index: %lu\n", static_cast<unsigned long>(nextClipIndex));
}

// ============================================================
// Image capture and SD writing
// ============================================================
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
void loop() {
  updateSerialCommands();
  updateBleCommands();
  updateButton();
  updateHttpServer();
  updateRecordingSession();
  updatePreviewOnlyCapture();
  delay(2);
}

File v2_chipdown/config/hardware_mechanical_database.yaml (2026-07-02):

meta:
  generated: '2026-07-01'
  phase: Phase 1 audit-only mechanical freeze database
  source_of_truth: Current records generated from chipdown_bom.py plus conservative
    local-source overlays in generate_mechanical_freeze_pack.py
  status_legend:
  - FROZEN
  - PROVISIONAL
  - RANGE
  - HOLD
  - TBD
  - DNP
  rule: No exact MPN/package drawing/land pattern means HOLD or TBD, not release-ready.
sources:
  schematic:
    source_document: Current V2 generated schematic/BOM master
    source_revision: generated 2026-07-01
    source_page: scripts/chipdown_bom.py
    source_url_or_file: v2_chipdown/scripts/chipdown_bom.py
    confidence: high for current project intent; not a package drawing
  dim_v22:
    source_document: AI Glasses Hardware Dimensions V2.2
    source_revision: '2026-07-01'
    source_page: pp. 1-10
    source_url_or_file: /Users/stanley/Downloads/AI_Glasses_Hardware_Dimensions_V2.2
      (3).pdf
    confidence: medium; project extraction from BOM PDFs
  dim_v23:
    source_document: AI Glasses Hardware Dimensions V2.3
    source_revision: '2026-07-01'
    source_page: pp. 1-10
    source_url_or_file: /Users/stanley/Downloads/AI_Glasses_Hardware_Dimensions_V2.3.pdf
    confidence: medium; project extraction from BOM PDFs
  fcu760k:
    source_document: Quectel FCU760K Short Specification
    source_revision: V1.1, Released, 2024
    source_page: pp. 1-3
    source_url_or_file: AI_Glasses_HOLD_Closure_Pack/02_WiFi_FCU760K/Quectel_FCU760K_Short_Spec_V1.1.pdf
    confidence: high for module outline and basic electrical data; land pattern still
      missing
  ndp120:
    source_document: Syntiant NDP120 Product Brief
    source_revision: V1, 2023
    source_page: pp. 1-2
    source_url_or_file: AI_Glasses_HOLD_Closure_Pack/01_NDP120/NDP120_Product_Brief.pdf
    confidence: medium; product brief, not full datasheet/package drawing
  imx415:
    source_document: Sony IMX415-AAQR-C Datasheet E19504
    source_revision: Official edition, 2019-05-21
    source_page: pp. 1, 3, 97
    source_url_or_file: AI_Glasses_HOLD_Closure_Pack/04_IMX415/IMX415-AAQR-C_Datasheet_E19504.pdf
    confidence: high for bare sensor; low for final module mechanics
  bq2970:
    source_document: TI BQ297xx Datasheet SLUSBU9I
    source_revision: March 2014, revised August 2024
    source_page: pp. 1, 3, package outline
    source_url_or_file: AI_Glasses_HOLD_Closure_Pack/03_Battery_LP451165_1S2P/TI_BQ2970_1S_Protection_Datasheet.pdf
    confidence: high for IC; exact suffix still TBD
  battery_fit:
    source_document: LP451165 Battery Bay Fit Check
    source_revision: project fit-check, 2026-07-01
    source_page: dimensions.csv + fit-check md
    source_url_or_file: AI_Glasses_HOLD_Closure_Pack/06_Mechanical_Fit_Check/
    confidence: medium; CAD clearance envelope, not supplier pack drawing
  rk3576:
    source_document: RK3576 Brief Datasheet file
    source_revision: V1.2, 2024-03-11; PDF metadata title mismatch noted
    source_page: pp. 1-3
    source_url_or_file: AI_Glasses_HOLD_Closure_Pack/05_Project_References/RK3576
      Brief Datasheet V1.2-20240311.pdf
    confidence: medium; package/HDG/ball map still required
components:
- functional_block: EVT Debug Tail
  reference_designator: J2
  bom_id: C035
  manufacturer: TBD
  exact_mpn: USB-C 16p USB2-only
  description: EVT USB-C — 5 V sink + USB2 OTG (no USB3/DP). For MaskROM/ADB/firmware/lab
    supply.
  board_region: EVT Debug Tail
  assembly_status: Fit
  package: AI_Glasses_V2:USB_C_16P_MidMount
  body_length_mm: null
  body_width_mm: null
  body_height_mm: null
  land_pattern: AI_Glasses_V2:USB_C_16P_MidMount
  courtyard: TBD; use official package drawing before layout
  keepout: TBD; see placement notes
  pin_pitch: TBD
  mass_g: TBD
  operating_voltage: TBD
  typical_power: TBD
  peak_power: TBD
  thermal_notes: TBD after thermal review
  placement_notes: ''
  source_document: Current V2 generated schematic/BOM master
  source_revision: generated 2026-07-01
  source_page: scripts/chipdown_bom.py
  source_url_or_file: v2_chipdown/scripts/chipdown_bom.py
  confidence: high for current project intent; not a package drawing
  freeze_status: Fit
  schematic_status: present in current schematic
  footprint_status: candidate; verify official drawing/land pattern/height before
    layout
  3d_model_status: HOLD/TBD; no verified aligned STEP in V2 KiCad
  next_action: Connector height + shell opening co-freeze
- functional_block: EVT Debug Tail
  reference_designator: R1
  bom_id: C037a
  manufacturer: TBD
  exact_mpn: 5.1k 1%
  description: USB-C CC1 Rd — 5.1k 1% sink pulldown. LOCK value + 1% (V1 audit rule).
  board_region: EVT Debug Tail
  assembly_status: Fit
  package: AI_Glasses_V2:R_0402
  body_length_mm: null
  body_width_mm: null
  body_height_mm: null
  land_pattern: AI_Glasses_V2:R_0402
  courtyard: TBD; use official package drawing before layout
  keepout: TBD; see placement notes
  pin_pitch: TBD
  mass_g: TBD
  operating_voltage: TBD
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

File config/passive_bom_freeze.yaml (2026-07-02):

metadata:
  board: ai_glasses_carrier_v1
  date: 2026-06-28
  status: PRE_LAYOUT_PASSIVE_BOM_REVIEW
  source_schematic_bom: scripts/carrier_bom.py
  rule: "Every R/C/L/FB/D passive and high-speed protection array used before layout must be covered here."

policy:
  resistor_default:
    package: "0603 / 1608 metric"
    footprint: "Resistor_SMD:R_0603_1608Metric"
    tolerance: "1%"
    tempco: "100 ppm/C or better"
    power_rating_W_min: 0.1
    temp_range_C: "-55..155"
  mlcc_default:
    package: "0603 / 1608 metric unless noted"
    dielectric: "X7R or X5R; C0G/NP0 for RF/timing/tune positions"
    temp_range_C: "-55..125"
    dc_bias_rule: "Effective capacitance after DC bias must remain adequate for the rail."
  procurement_status_meaning:
    LOCKED_CANDIDATE: "MPN/LCSC candidate URL was checked and can be used for schematic-stage BOM freeze."
    PROCUREMENT_VERIFY: "MPN/spec is selected, but distributor stock/orderability must be checked before purchase."
    TUNE_OR_EVT_SELECT: "Footprint/minimum spec is frozen; exact value/MPN must be selected by RF tuning or bench measurement."

families:
  R_2K2_I2C_PULLUP_1V8:
    refs: [R7, R8, R9, R10, R12, R13]
    category: resistor
    value: "2.2k"
    role: "1.8V I2C pull-up"
    package: "0603 / 1608 metric"
    footprint: "Resistor_SMD:R_0603_1608Metric"
    tolerance: "1%"
    tempco: "100 ppm/C"
    power_rating_W_min: 0.1
    temp_range_C: "-55..155"
    manufacturer: YAGEO
    mpn: "RC0603FR-072K2L"
    lcsc: "C4190"
    lcsc_url: "https://www.lcsc.com/product-detail/Chip-Resistor-Surface-Mount_YAGEO-RC0603FR-072K2L_C4190.html"
    procurement_status: LOCKED_CANDIDATE

  R_5K1_USB_CC:
    refs: [R1, R2]
    category: resistor
    value: "5.1k"
    role: "USB-C sink CC pull-down"
    package: "0603 / 1608 metric"
    footprint: "Resistor_SMD:R_0603_1608Metric"
    tolerance: "1%"
    tempco: "100 ppm/C"
    power_rating_W_min: 0.1
    temp_range_C: "-55..155"
    manufacturer: YAGEO
    mpn: "RC0603FR-075K1L"
    lcsc: "C23186"
    lcsc_url: "https://www.lcsc.com/product-detail/Chip-Resistor-Surface-Mount_YAGEO-RC0603FR-075K1L_C23186.html"
    procurement_status: LOCKED_CANDIDATE

  R_1K_LED_LIMIT:
    refs: [R4, R5]
    category: resistor
    value: "1k"
    role: "LED current limit"
    package: "0603 / 1608 metric"
    footprint: "Resistor_SMD:R_0603_1608Metric"
    tolerance: "1%"
    tempco: "100 ppm/C"
    power_rating_W_min: 0.1
    temp_range_C: "-55..155"
    manufacturer: YAGEO
    mpn: "RC0603FR-071KL"
    lcsc: "C21190"
    lcsc_url: "https://www.lcsc.com/product-detail/Chip-Resistor-Surface-Mount_YAGEO-RC0603FR-071KL_C21190.html"
    procurement_status: LOCKED_CANDIDATE

  R_10K_PULLUP_OR_NTC_BIAS:
    refs: [R11, R14, R15, R16]
    category: resistor
    value: "10k"
    role: "Reset/recovery/power pull-up and battery NTC placeholder bias"
    package: "0603 / 1608 metric"
    footprint: "Resistor_SMD:R_0603_1608Metric"
    tolerance: "1%"
    tempco: "100 ppm/C"
    power_rating_W_min: 0.1
    temp_range_C: "-55..155"
    manufacturer: YAGEO
    mpn: "RC0603FR-0710KL"
    lcsc: "C25804"
    lcsc_url: "https://www.lcsc.com/product-detail/Chip-Resistor-Surface-Mount_YAGEO-RC0603FR-0710KL_C25804.html"
    procurement_status: LOCKED_CANDIDATE
    note: "If the final battery pack has an actual NTC, R11 may change with charger TS design."

  R_100K_PULLUP:
    refs: [R18, R19, R20]
    category: resistor
    value: "100k"
    role: "Wireless disable defaults and boost EN default"
    package: "0603 / 1608 metric"
    footprint: "Resistor_SMD:R_0603_1608Metric"
    tolerance: "1%"
    tempco: "100 ppm/C"
    power_rating_W_min: 0.1
    temp_range_C: "-55..155"
    manufacturer: YAGEO
    mpn: "RC0603FR-07100KL"
    lcsc: "C25803"
    lcsc_url: "https://www.lcsc.com/product-detail/Chip-Resistor-Surface-Mount_YAGEO-RC0603FR-07100KL_C25803.html"
    procurement_status: LOCKED_CANDIDATE

  R_10R_ACTIVE_ANT_BIAS:
    refs: [R17]
    category: resistor
    value: "10R"
    role: "Active GNSS antenna bias feed, DNP if passive antenna"
    package: "0603 / 1608 metric"
    footprint: "Resistor_SMD:R_0603_1608Metric"
    tolerance: "1%"
    tempco: "100 ppm/C"
    power_rating_W_min: 0.1
    temp_range_C: "-55..155"
    manufacturer: YAGEO
    mpn: "RC0603FR-0710RL"
    lcsc: "C22859"
    lcsc_url: "https://www.lcsc.com/product-detail/Chip-Resistor-Surface-Mount_YAGEO-RC0603FR-0710RL_C22859.html"
    procurement_status: LOCKED_CANDIDATE
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

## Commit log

2026-06-15 Add AI goggles V0 camera prototype
2026-06-22 Add automatic SD mount video conversion on macOS
2026-06-28 Add KiCad hardware automation environment
    [RC126_V1.10_20250526_BOT.dxf, Radxa CM4 V1.20 BOT.dxf, Radxa CM4 V1.20 TOP.dxf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]
2026-07-01 Add V2 chipdown pre-layout schematic
    [ai_glasses_v2_bom.csv, ai_glasses_v2_chipdown.kicad_sch]
2026-07-02 Update V2 chipdown schematic and mechanical package
    [LP451165_clearance_envelope_70x12p8x5p6mm.stl, LP451165_nominal_cell_65x11x4p5mm.stl, ai_glasses_carrier.kicad_pcb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]
